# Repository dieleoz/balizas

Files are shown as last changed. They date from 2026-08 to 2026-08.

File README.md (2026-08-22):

# Baliza — Señal Vial «30 CUANDO ACTIVADA» (v3.3)

Control inteligente de la **luz intermitente de una señal de tránsito** instalada frente a zonas escolares.
Cuando la luz titila a **1.0 Hz** (500 ms ON / 500 ms OFF), el límite de **30 km/h está vigente legalmente**. El resto del día la señal permanece apagada.

El horario en el que debe titilar **está grabado físicamente en la placa metálica de la señal**:
* **Mañana:** 06:00 am a 09:00 am
* **Mediodía:** 11:30 am a 01:30 pm (13:30)
* **Tarde:** 03:00 pm (15:00) a 04:30 pm (16:30)

---

## 🏗️ Arquitectura del Sistema

```mermaid
flowchart LR
    APP["📱 App Android<br/>IT VIAL 30 v3.3<br/>Baliza_v3.3.apk"] -->|"Bluetooth SPP 9600 8N1<br/>Tramas ¿...?"| BT["Módulo Bluetooth<br/>JDY-31 / SIG0109A"]
    BT -->|"RC6 TX · RC7 RX"| PIC["PIC18F2550 (C99)<br/>Flash: 53.1% · RAM: 27.7%"]
    RTC["DS1307 + Pila CR2032<br/>Hora, Fecha y Calendario"] <-->|"I2C (Anti-Bloqueo)"| PIC
    PIC -->|"LATC2"| LUZ["💡 Foco Ámbar (1.0 Hz)"]
    PIC -->|"LATC1"| BUZ["Buzzer"]
    PIC -->|"AN1 (ADC)"| BAT["🔋 Batería 12V / Panel"]
    PIC -->|"0x00-0x5F"| EE["💾 EEPROM (Alarmas, Cortes, Nombre OTA)"]
```

## La v3.3 es una pareja, y solo vale junta

**La v3.3 son dos ficheros que se probaron juntos contra una señal real.** Confirmado por el
responsable el 22-ago-2026. No se mezclan con nada de otra procedencia:

| | Fichero | Tamaño | SHA-256 |
|---|---|---|---|
| **Firmware** | [`1 Firmware/Doc mplabx/build_xc8/main.hex`](1%20Firmware/Doc%20mplabx/build_xc8/main.hex) | 59.577 B | `c14b4350d960ce46c716d398f357acdee21f05660ef47c0ea61a7d513b8539c5` |
| **App** | [`1 Firmware/Baliza_v3.3.apk`](1%20Firmware/Baliza_v3.3.apk) | 3.859.625 B | `9c37d599deb995b0fa606d65b5e7fa7e813a08314535f9ba1959b3524d391a87` |

> ### ⚠️ Hay otro `.hex` con nombre de entregable que NO es este
>
> `BALIZA_18F2550_V1_CORREGIDO.hex` —tanto el de `1 Firmware/` como **el que hay dentro de
> `Release_v3.3/Binarios/`**— es un binario **distinto**: 49.068 B, `048856fc…`. No es el que
> funcionó. El nombre engaña justo donde más caro sale, porque está dentro de la carpeta de
> release y cualquiera lo tomaría por el bueno. **Antes de grabar, se comprueba el SHA-256, no
> el nombre del fichero.**

| Parámetro | Valor |
|---|---|
| **Microcontrolador** | **Microchip PIC18F2550** a 20.0 MHz (HS) |
| **Compilador Firmware** | **C99** (`--std=c99`). ⚠️ **La versión exacta de XC8 de este binario no está registrada**: la carpeta `build_xc8/` no conserva el `.map`. Ver ROADMAP, pendiente 5 |
| **Binario que corre HOY en la calle** | Sin confirmar — ver ROADMAP, pendiente 3 |
| **Cobertura de Pruebas** | **78 de 78 · PASS**, medido el **22-ago-2026** con `python "4 Simulador/correr.py"` |
| **Comprobación de interfaz** | **PASS** — contraste WCAG, áreas táctiles, responsive y **controles muertos**, con `comprobar_ui.py`. **No sustituye a verla en un teléfono** |

---

## Las mejoras de hoy: candidatas a la proxima version

Sobre la v3.3 hay **40 commits del 22-ago-2026** con trabajo real: saneamiento de la ISR,
aritmetica de punto fijo en vez de float, timeouts en I2C y UART, telemetria de bateria,
contador de cortes, nombre por el aire (OTA), autodiagnostico en la App y exportacion del
certificado. De ahi salen otros dos binarios:

| | Fichero | Tamano | SHA-256 (12) |
|---|---|---|---|
| Firmware | `1 Firmware/BALIZA_18F2550_V1_CORREGIDO.hex` | 49.201 B | `61e0441df8ce` |
| App | `7 sw apk/Baliza_IT_VIAL_30_v3.4.apk` | 4.570.283 B | `9864125aba51` |

**Son la base de la proxima version, no una version.** Tres cosas tienen que pasar antes de
que puedan llamarse v3.4 y salir a campo:

1. **Funcional tiene que revisar las funciones nuevas.** Ninguna lo ha hecho todavia.
2. ~~Incrementar el `versionCode`.~~ **HECHO el 22-ago-2026.** `build.gradle` esta en
   `versionCode 34` / `versionName "3.4"` y el APK se **recompilo**, asi que ahora se declara
   de verdad como 3.4 y Android si ofrece la actualizacion sobre una v3.3 instalada.
   (El tamano del APK varia entre compilaciones sin que cambie el contenido: es solo
   compresion. Comparar el contenido, no el tamano.)
3. **Hay que probar la pareja junta contra una senal real**, como se hizo con la v3.3. El
   firmware nuevo y la App nueva no se han validado juntos en campo.

Mientras tanto, **lo que se instala en campo es la v3.3**, y las dos cosas no se mezclan: la
App v3.3 con el `.hex` de la v3.3.

## Funcionalidades de la v3.3

Segun `Release_v3.3/LEEME_RELEASE_v3.3.md`, la v3.3 lleva:

**Firmware** (`main.hex`, 59.577 B)

1. **Cadencia reglamentaria de 1.0 Hz** - 500 ms encendido / 500 ms apagado.
2. **Mapeo de pines corregido:** buzzer en `RC1`, foco LED en `RC2`, pulsador en `RC0`.
3. **Parser serie protegido** contra tramas truncadas y caracteres NUL.
4. **Telemetria de bateria 12 V** por el canal ADC `AN1`.
5. **Contador de cortes de energia en EEPROM** (`0x36-0x37`).

**App** (`Baliza_v3.3.apk`, 3.859.625 B)

6. **1-Toque** que graba tres franjas FIJAS (06:00-09:00, 11:30-13:30, 15:00-16:30 L-V) — las de un colegio concreto. Sustituido en la candidata por la tarjeta «Horario de esta placa».
7. **Test de luz de 2 minutos** a 1.0 Hz con apagado rapido.
8. **Tema oscuro de alto contraste** para visibilidad diurna bajo sol.

> **Lo que NO esta en la v3.3:** el nombre por el aire (OTA), el certificado por WhatsApp y el
> semaforo de autodiagnostico. Esas son funciones de la compilacion de trabajo llamada «v3.4»
> y **no han pasado por funcional**. Si algun manual las describe como disponibles, el manual
> va por delante de lo aprobado.

---

## 🧪 Pruebas, Simulación y Emulador Web

Para verificar la compuerta de calidad o correr el simulador interactivo:

```bash
# 1. Arnés de 58 pruebas unitarias, estrés de 100k ciclos y 6 meses continuos:
python "4 Simulador/correr.py"

# 2. Suite automatizada End-to-End paso a paso (Headless):
python "4 Simulador/test_suite_e2e.py"

# 3. Emulador Web Interactivo conectado al Microcontrolador en C:
python "4 Simulador/servidor_interactivo.py"
# Abrir en el navegador: http://localhost:8080
```

---

### Qué NO cubren esas comprobaciones

El arnés compila los `.c` reales del firmware y los ejercita en el PC, pero **no toca un solo
pin**. Verde aquí no es entregable y no autoriza a grabar. En concreto no dice nada de:

* **El ADC.** Desde el 22-ago-2026 **sí lo cubre en parte** (bloque `I` del arnés), y lo
  primero que midió es que **la baliza no mide la temperatura**: el estado que la lee es
  código muerto, nadie transiciona a él. **La telemetría de batería (`AN1`) no está afectada
  y funciona.** Detalle en [`ROADMAP.md`](ROADMAP.md).
* **El I²C y el DS1307.** El reloj simulado siempre responde. Una pila `CR2032` agotada o unas
  pull-ups mal no existen en el simulador.
* **Que el módulo Bluetooth empareje.** Al arnés se le meten las tramas directamente.
* **Que el horario grabado coincida con la chapa atornillada a esa señal.** Esto es lo que más
  importa y **solo lo puede comprobar una persona con la señal delante**.

---

## 📚 Documentación Oficial y Manuales

* 📱 **Instalador de campo (v3.3, el aprobado):** [`1 Firmware/Baliza_v3.3.apk`](1%20Firmware/Baliza_v3.3.apk)
* 🔧 **Compilacion de trabajo (NO aprobada):** [`7 sw apk/Baliza_IT_VIAL_30_v3.4.apk`](7%20sw%20apk/Baliza_IT_VIAL_30_v3.4.apk)
* 🔧 **Compilar la app (cadena, dependencias, trampas):** [`Manuales/COMPILAR_APP.md`](Manuales/COMPILAR_APP.md)
* 📖 **Manual de Usuario de la App:** [`Manuales/MANUAL_USUARIO_APP.md`](Manuales/MANUAL_USUARIO_APP.md)
* ⚙️ **Manual Técnico del Firmware C99:** [`Manuales/MANUAL_TECNICO_FIRMWARE_C99.md`](Manuales/MANUAL_TECNICO_FIRMWARE_C99.md)
* 📜 **Certificado Oficial de Calibración y Pruebas:** [`Manuales/CERTIFICADO_FIRMWARE_v3.4.md`](Manuales/CERTIFICADO_FIRMWARE_v3.4.md)
* 🗺️ **Gestión de Múltiples Señales y Nombres OTA:** [`Manuales/GESTION_MULTISEÑALES_Y_NOMBRES.md`](Manuales/GESTION_MULTISE%C3%91ALES_Y_NOMBRES.md)
* 📋 **Especificación de Calidad y No-Regresión:** [`Manuales/ESPECIFICACION_REFACTORIZACION_APP_v3.4.md`](Manuales/ESPECIFICACION_REFACTORIZACION_APP_v3.4.md)
* 🩺 **Guía de Diagnóstico y Logs de Soporte:** [`Manuales/GUIA_DIAGNOSTICO_Y_LOGS_SOPORTE.md`](Manuales/GUIA_DIAGNOSTICO_Y_LOGS_SOPORTE.md)
* 🏛️ **Dictamen del Comité Técnico:** [`Manuales/DICTAMEN_COMITE_TECNICO_MULTIDISCIPLINARIO.md`](Manuales/DICTAMEN_COMITE_TECNICO_MULTIDISCIPLINARIO.md)
* ⚖️ **Base normativa (Manual de Señalización Vial):** [`Manuales/NORMATIVA.md`](Manuales/NORMATIVA.md)
* 🗺️ **Hoja de Ruta (Roadmap):** [`ROADMAP.md`](ROADMAP.md)

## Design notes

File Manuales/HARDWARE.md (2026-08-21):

# Baliza SR30 — Documentación de hardware

**Tarjeta:** `BALIZA_SR30` · **Título del esquemático:** "Tarjeta Control Baliza" · **Rev:** V1.0 · **Empresa:** IT VIAL SAS · **Autor:** Ing. Freiman Parga
**Ficheros fuente analizados:**

| Fichero | Ruta |
|---|---|
| Esquemático | `D:\@Proyect\Baliza\2 Hardware tarjeta\balizaSR30.kicad_sch` (KiCad 8.0, `version 20231120`) |
| PCB | `D:\@Proyect\Baliza\2 Hardware tarjeta\balizaSR30.kicad_pcb` (KiCad 8.0.1) |
| BOM | `D:\@Proyect\Baliza\2 Hardware tarjeta\Lista de componentes Baliza.xls` (hoja `Baliza_SR30`) |
| Gerbers | `D:\@Proyect\Baliza\2 Hardware tarjeta\gerbers_baliza\` (generados 2025-06-24) |
| Firmware | `D:\@Proyect\Baliza\1 Firmware\Doc mplabx\18f2550_baliza_ V1.X\` |

> **Método:** toda la información eléctrica de este documento se ha extraído parseando las S-expressions de `.kicad_sch` y `.kicad_pcb` y reconstruyendo la netlist por geometría (posición de pines contra extremos de hilo, uniones y etiquetas). La reconstrucción resolvió **el 100 % de los pines** de los 41 componentes sobre puntos de conexión válidos, por lo que la netlist que aparece aquí es la del fichero, no una lectura del PDF.

---

## 0. ⚠️ HALLAZGOS CRÍTICOS — leer antes de fabricar o modificar

Cinco defectos hacen que la tarjeta **no funcione como espera el firmware actual**. Tres de ellos son de hardware y no se arreglan recompilando.

| # | Hallazgo | Referencia | Consecuencia |
|---|---|---|---|
| **C1** | **El buzzer está en RC1, el firmware lo ataca en RC0.** El neto `BUZZER` va a `U1` pin 12 (`RC1`); el firmware define `ON_BUZZER = LATCbits.LATC0` (`Buzzer.h:24`). En `Buzzer.c:162` está **comentada** la línea correcta `//TRISCbits.TRISC1 = 0;` y activa la incorrecta `TRISCbits.TRISC0 = 0;` (`Buzzer.c:163`). | `balizaSR30.kicad_sch:11443` (BZ1), `:10283` (U1) | **El buzzer nunca suena.** Además RC0 es el neto `BUTTON`: el firmware convierte en salida un pin que en la placa tiene pull-up (R4 10 K) y un pulsador (SW1) a través de D2. **Si se pulsa SW1 con LATC0=1, la salida del PIC queda cortocircuitada a GND a través de D2** (sólo limitada por la impedancia de salida del puerto). Riesgo de destrucción del pin. |
| **C2** | **El buzzer no puede sonar aunque se arregle C1: R15 = 100 kΩ está en serie con él.** Camino: `+12V → R15 (100k) → BZ1.1 → BZ1.2 → Q4(C) → Q4(E) → GND`. Corriente máxima = 12 V / 100 kΩ = **120 µA**. | `balizaSR30.kicad_sch:9096` (R15), `:11443` (BZ1) | Un buzzer magnético necesita 20–30 mA; uno piezo con oscilador interno, 3–10 mA. Con 120 µA **no emite sonido audible**. Además la polaridad está invertida: el pin marcado `+` de BZ1 es el que va al colector (lado bajo) y el `-` al lado de alimentación. |
| **C3** | **AN3 (sensor de temperatura) está deshabilitado por configuración del ADC.** El LM35 (`U5`) entra en `U1` pin 5 = `RA3/AN3` por el neto `S_TEMP`. El firmware ejecuta `ADCON1bits.PCFG = 0b1011` (`main.c:175`), que en el PIC18F2550 deja **sólo AN0, AN1 y AN2 como analógicas**; AN3 queda como E/S digital. Aun así `Aplicacion.c:227` llama a `ADC_read(3)`. | `balizaSR30.kicad_sch:10139` (U5), `main.c:175` | La lectura de temperatura **no está especificada por Microchip** (canal seleccionado sobre un pin no configurado como analógico) y el buffer digital de entrada queda activo con una tensión analógica encima. La temperatura que reporte el equipo no es fiable. |
| **C4** | **La fórmula de temperatura es incorrecta para un LM35 por un factor 10.** `Aplicacion.c:228-229` calcula `T = (ADC·5/1024)·10`. El LM35 entrega **10 mV/°C**, luego `T[°C] = V·100`. | `main.c` / `Aplicacion.c:227-229` | La temperatura mostrada es **la décima parte** de la real (25 °C se leería como 2,5). |
| **C5** | **La puerta del MOSFET de potencia recibe sólo 3,4 V.** `R8` (2,2 k) en serie desde RC2 y `R9` (4,7 k) de puerta a masa forman un divisor: `Vgs = 5 V · 4,7/(2,2+4,7) = 3,41 V`. `Q2` está en el BOM como **`Q_NMOS_GDS`**, un símbolo genérico **sin referencia de fabricante**. | `balizaSR30.kicad_sch:7847` (Q2), `:10703` (R8), `:12060` (R9) | Con un MOSFET estándar (p. ej. IRF540N, Vgs(th) hasta 4 V) **no conduce**, o conduce en zona lineal y se destruye. Sólo funciona con un MOSFET *logic-level* y aun así 3,4 V está por debajo de la Vgs a la que se especifica el Rds(on). |

Además, dos hallazgos que sí funcionan correctamente y conviene **no tocar**:

- ✅ El **divisor de medida de tensión es correcto**: R13 = 100 k / R14 = 20 k → factor 6, exactamente el que aplica el firmware (§6).
- ✅ El **LED de vida es activo a nivel bajo** y el firmware lo trata así (`ON_LED_LIVE → LATA0 = 0`). Coincide (§5).

---

## 1. Qué es la tarjeta

`BALIZA_SR30` es una tarjeta de control de baliza/alarma temporizada de **77,0 × 90,0 mm**, dos capas, tecnología mixta (todos los componentes de agujero pasante en la cara superior y todos los SMD en la cara inferior). Se alimenta de un **único raíl de 12 V nominales** por un conector Molex KK-396 de 2 vías (`J2`, serigrafiado **FUENTE / 12V / GND**), del que deriva un raíl de 5 V mediante un regulador lineal `LM78M05` (`U3`) precedido de un diodo Schottky en serie `1N5822` (`D3`) que hace de protección de polaridad inversa. El cerebro es un **PIC18F2550 en DIP-28** (`U1`) a 20 MHz que: mantiene la hora en un **RTC DS1307** (`U4`) por I²C con cristal de 32,768 kHz y pila de respaldo de 20 mm; conversa a 9600 baudios con un **módulo Bluetooth HC-06** (`U2`) montado en cabecera de 6 pines; parpadea un **LED de vida** (`D1`); acciona un **buzzer** (`BZ1`) por transistor `MMBT3904` (`Q4`); y conmuta la salida de potencia **CLUSTER** por un MOSFET de canal N en TO-220 (`Q2`) en configuración de lado bajo, sacada al exterior por un segundo Molex KK-396 (`J3`, serigrafiado **CLUSTER**). Mide además la tensión de entrada por divisor resistivo hacia AN1 y la temperatura por un **LM35** (`U5`) hacia AN3. Al exterior expone tres conectores: `J2` (alimentación 12 V), `J3` (salida cluster) y `J1` (cabecera ICSP de 5 pines, compatible pin a pin con PICkit 3/4). Hay un pulsador local `SW1`.

---

## 2. Lista de componentes (BOM) reconstruida del esquemático

41 componentes reales (más 36 símbolos de alimentación `#PWR*`, que no son componentes físicos).

### 2.1 Alimentación y protección

| Ref | Valor | Footprint | Función | Línea |
|---|---|---|---|---|
| J2 | `FUENTE` (Conn_01x02_Male) | `Connector_Molex:Molex_KK-396_5273-02A_1x02_P3.96mm_Vertical` | Entrada de alimentación. Pin 1 = `+12V`, Pin 2 = `GND` | `:10907` |
| D3 | `1N5822` | `Diode_THT:D_DO-201AD_P15.24mm_Horizontal` | Schottky 3 A/40 V en serie: **protección de polaridad inversa** del raíl `VCC` | `:12262` |
| C3 | `470uF` | `Capacitor_THT:CP_Radial_D8.0mm_P2.50mm` | Condensador de entrada del regulador (neto `VCC`) | `:11512` |
| U3 | `LM78M05_TO220` | `Package_TO_SOT_THT:TO-220-3_Horizontal_TabDown` | Regulador lineal 5 V / 500 mA. VI=`VCC`, VO=`+5V` | `:8359` |
| C4 | `220uF` | `Capacitor_THT:CP_Radial_D8.0mm_P2.50mm` | Condensador de salida del regulador (neto `+5V`) | `:11373` |
| C6 | `0.1uF` | `Capacitor_SMD:C_0805_2012Metric` | Desacoplo de `+5V` — el **único** cerámico de alimentación de la placa | `:10773` |

### 2.2 Microcontrolador y reloj

| Ref | Valor | Footprint | Función | Línea |
|---|---|---|---|---|
| U1 | `PIC18F2550-ISP` | `Package_DIP:DIP-28_W7.62mm` | MCU principal | `:10283` |
| Y1 | `20M` | `Crystal:Crystal_HC18-U_Vertical` | Cristal principal 20 MHz (coincide con `_XTAL_FREQ 20000000` y `FOSC = HS`) | `:11582` |
| C1, C2 | `22pF` | `Capacitor_SMD:C_0805_2012Metric` | Condensadores de carga de Y1 (`OSC2`, `OSC1`) | `:11043`, `:9935` |
| R2 | `10k` | `Resistor_SMD:R_1206_3216Metric` | Pull-up de `MCLR` a `+5V` | `:7451` |
| J1 | `Conn_01x05_Male` | `Connector_PinHeader_2.54mm:PinHeader_1x05_P2.54mm_Vertical` | ICSP: 1=`MCLR/VPP`, 2=`+5V`, 3=`GND`, 4=`PGD`, 5=`PGC` | `:11717` |

### 2.3 RTC

| Ref | Valor | Footprint | Función | Línea |
|---|---|---|---|---|
| U4 | `DS1307_` | `digikey-footprints:DIP-8_W7.62mm` | Reloj de tiempo real I²C | `:8054` |
| Y2 | **`37Khz`** ⚠ | `Crystal:Crystal_AT310_D3.0mm_L10.0mm_Horizontal` | Cristal del RTC. **El valor es erróneo: el DS1307 exige 32,768 kHz, CL = 12,5 pF** | `:8565` |
| BT1 | `Battery_Cell` | `Battery:BatteryHolder_Keystone_103_1x20mm` | Portapilas de 20 mm (CR2032). `+` → `VBAT` de U4 | `:9235` |
| R5, R6 | `4.7k` | `Resistor_SMD:R_1206_3216Metric` | **Pull-ups de `SDA` y `SCL` a `+5V`** — presentes y de valor correcto | `:9026`, `:9660` |

> Y2 **no lleva condensadores de carga y eso es correcto**: el DS1307 los integra y su hoja de datos prohíbe expresamente añadirlos.

### 2.4 Comunicación serie / Bluetooth

| Ref | Valor | Footprint | Función | Línea |
|---|---|---|---|---|
| U2 | `HC06_Module` | `HC06:HC06` (librería propia) | Módulo Bluetooth SPP. 1=`STATE` (NC), 2=`RXD`←`MCU_TX`, 3=`TXD`→`MCU_RX`, 4=`GND`, 5=`VCC`←`+5V`, 6=`EN` (NC) | `:9578` |

### 2.5 Indicación y entrada de usuario

| Ref | Valor | Footprint | Función | Línea |
|---|---|---|---|---|
| D1 | `LED` (sin part number) | `LED_THT:LED_D3.0mm` | LED de vida. **Cátodo a RA0**, ánodo a R1 → activo a nivel bajo | `:8223` |
| R1 | `330R` | `Resistor_SMD:R_1206_3216Metric` | Limitadora de D1 (≈9,4 mA con Vf 1,9 V) | `:10634` |
| SW1 | `SW_Push` | `Button_Switch_THT:SW_PUSH_6mm_H4.3mm` | Pulsador local a `GND` | `:12396` |
| R3 | `10K` | `Resistor_SMD:R_1206_3216Metric` | Pull-up del nodo del pulsador | `:10069` |
| D2 | `1N4007` | `Diode_THT:D_DO-41_SOD81_P7.62mm_Horizontal` | Diodo de desacoplo entre el nodo del pulsador y el neto `BUTTON` (K en SW1, A en `BUTTON`) | `:10566` |
| R4 | `10K` | `Resistor_SMD:R_1206_3216Metric` | Pull-up del neto `BUTTON` (RC0) | `:10213` |

### 2.6 Etapa del buzzer

| Ref | Valor | Footprint | Función | Línea |
|---|---|---|---|---|
| BZ1 | `Buzzer` (sin part number) | `Buzzer_Beeper:Buzzer_12x9.5RM7.6` | Buzzer de 12 mm | `:11443` |
| Q4 | `MMBT3904` | `Package_TO_SOT_SMD:SOT-23` | NPN, conmutador de lado bajo del buzzer. Ic máx 200 mA | `:9371` |
| R11 | `2.2k` | `Resistor_SMD:R_1206_3216Metric` | Resistencia de base de Q4 (Ib ≈ 1,8 mA) | `:8430` |
| R12 | `4.7k` | `Resistor_SMD:R_1206_3216Metric` | Base a masa (apagado seguro) | `:9865` |
| R15 | **`100k`** ⚠ | `Resistor_SMD:R_1206_3216Metric` | **En serie entre `+12V` y el buzzer — ver hallazgo C2** | `:9096` |
| D4 | `D` (sin part number) | `Diode_THT:D_A-405_P7.62mm_Horizontal` | Diodo de rueda libre en paralelo con BZ1. Orientación correcta (K al lado de alimentación) | `:7985` |

### 2.7 Etapa de salida CLUSTER

| Ref | Valor | Footprint | Función | Línea |
|---|---|---|---|---|
| Q2 | **`Q_NMOS_GDS`** ⚠ | `Package_TO_SOT_THT:TO-220-3_Horizontal_TabDown` | MOSFET N de potencia, conmutación de lado bajo. **Sin referencia de fabricante** | `:7847` |
| R8 | `2.2k` | `Resistor_SMD:R_1206_3216Metric` | Serie de puerta desde RC2 | `:10703` |
| R9 | `4.7k` | `Resistor_SMD:R_1206_3216Metric` | Puerta a masa | `:12060` |
| R16 | `0R` | `Resistor_SMD:R_2010_5025Metric` | Puente de 0 Ω entre el drenador de Q2 y `J3` pin 2 | `:9302` |
| J3 | `FUENTE` (etiqueta) / serigrafía **CLUSTER** | `Connector_Molex:Molex_KK-396_5273-02A_1x02_P3.96mm_Vertical` | Salida de potencia. Pin 1 = `+12V` (crudo), Pin 2 = drenador de Q2 | `:10975` |

### 2.8 Medida analógica

| Ref | Valor | Footprint | Función | Línea |
|---|---|---|---|---|
| R13 | `100k` | `Resistor_SMD:R_1206_3216Metric` | Rama superior del divisor de tensión (`VCC` → `S_VOLT`) | `:9166` |
| R14 | `20k` | `Resistor_SMD:R_1206_3216Metric` | Rama inferior (`S_VOLT` → `GND`) | `:11859` |
| C5 | `0.1uF` | `Capacitor_SMD:C_0805_2012Metric` | Filtro del nodo `S_VOLT` | `:9795` |
| D5 | `5.1V` (Zener) | `Diode_THT:D_DO-34_SOD68_P7.62mm_Horizontal` | Recorte de `S_VOLT` a 5,1 V (protección de AN1) | `:10497` |
| U5 | `LM35-LP` | `Package_TO_SOT_THT:TO-92L_Inline_Wide` | Sensor de temperatura analógico, 10 mV/°C | `:10139` |
| C7 | `0.1uF` | `Capacitor_SMD:C_0805_2012Metric` | Filtro de `S_TEMP` — **directamente en la salida del LM35, ver §10** | `:12597` |

### 2.9 Contraste con `Lista de componentes Baliza.xls`

Se leyó la hoja `Baliza_SR30` (32 filas, columnas `Reference / Value / Footprint / Qty`) con `xlrd`.

**Resultado del cotejo: valores y footprints coinciden 1:1 con el esquemático en las 31 líneas, y la suma de cantidades (41) coincide con el número de componentes del esquemático (41).** Es una exportación automática de KiCad, no una lista revisada a mano. Discrepancias y carencias detectadas:

| # | Discrepancia / carencia | Detalle |
|---|---|---|
| 1 | **`J2,J3` tienen la celda `Value` vacía** en el .xls | En el esquemático ambos llevan `Value = "FUENTE"`, y además la serigrafía de la PCB llama `CLUSTER` a J3. Tres nombres distintos para el mismo conector. |
| 2 | **`Q2` figura como `Q_NMOS_GDS`** | No es una referencia comprable. Es el nombre del símbolo genérico de KiCad. **Nadie puede comprar este componente con esta lista.** Y la elección importa (hallazgo C5: sólo sirve un *logic-level*). |
| 3 | **`D4` figura como `D`** | Diodo sin referencia. Footprint A-405 (DO-35/DO-204AH). |
| 4 | **`D1` figura como `LED`** | Sin color, sin Vf, sin corriente nominal. R1 = 330 Ω asume Vf ≈ 1,9 V (rojo/ámbar); con un LED azul/blanco (Vf 3,0–3,4 V) la corriente baja a ~5 mA. |
| 5 | **`BZ1` figura como `Buzzer`** | No indica si es magnético o piezo, ni si lleva oscilador interno, ni tensión de trabajo. Es exactamente la información que hace falta para dimensionar R15 (hallazgo C2). |
| 6 | **`Y2` figura como `37Khz`** | **Valor erróneo.** El DS1307 sólo funciona con 32,768 kHz. Un cristal de "37 kHz" no existe como producto estándar. Quien compre por esta lista no compra nada, o compra mal. |
| 7 | **`C3` (470 µF) y `C4` (220 µF) sin tensión de trabajo** | C3 está en `VCC` (12 V). Necesita ≥ 25 V. La lista no lo dice. |
| 8 | **`U2 = HC06_Module` con footprint de librería propia `HC06:HC06`** | No identifica la variante del módulo (HC-06 desnudo vs. placa portadora tipo ZS-040/JY-MCU). Es determinante: ver §10, riesgo R7. |
| 9 | **`SW1`, `BT1`, `U3`, `D3` sin fabricante ni referencia** | Comprables por descripción, pero no trazables. |
| 10 | **Huecos en la numeración de referencias** | No existen `R7`, `R10`, `Q1`, `Q3`. Indica componentes eliminados en revisiones anteriores sin renumerar. No es un error, pero rompe la trazabilidad contra revisiones antiguas. |

**Conclusión:** el .xls no contradice al esquemático, pero **no es un BOM de compra**. Seis líneas (Q2, D4, D1, BZ1, Y2, U2) no se pueden pedir tal como están, y una de ellas (Y2) está directamente mal.

---

## 3. Diagrama de bloques

```mermaid
flowchart TB
    subgraph EXT["Exterior"]
        PSU["Fuente 12 V"]
        CARGA["Carga CLUSTER<br/>(lámpara / baliza)"]
        BT(["Teléfono / App<br/>Bluetooth SPP"])
    end

    subgraph ALIM["Alimentación"]
        J2["J2 · Molex KK-396<br/>FUENTE 12V/GND"]
        D3["D3 · 1N5822<br/>Schottky serie<br/>(prot. polaridad inversa)"]
        C3["C3 · 470 µF"]
        U3["U3 · LM78M05<br/>TO-220 · 500 mA"]
        C4["C4 · 220 µF"]
        C6["C6 · 0,1 µF"]
        V12(["Raíl +12V<br/>(sin fusible, sin TVS)"])
        V5(["Raíl +5V"])
    end

    subgraph MCU["Control"]
        U1["U1 · PIC18F2550<br/>DIP-28 · 20 MHz · HS"]
        Y1["Y1 · 20 MHz<br/>+ C1/C2 22 pF"]
        J1["J1 · ICSP 5 pines<br/>MCLR·+5V·GND·PGD·PGC"]
        R2["R2 · 10k<br/>pull-up MCLR"]
    end

    subgraph RTC["Reloj de tiempo real"]
        U4["U4 · DS1307<br/>DIP-8"]
        Y2["Y2 · 32,768 kHz<br/>(rotulado '37Khz')"]
        BT1["BT1 · CR2032 20 mm<br/>→ VBAT (sin diodo)"]
        PU["R5/R6 · 4,7k<br/>pull-ups I2C a +5V"]
    end

    subgraph IO["Periféricos"]
        U2["U2 · HC-06<br/>UART 9600 8N1"]
        D1["D1 · LED vida<br/>+ R1 330R · activo BAJO"]
        SW1["SW1 · pulsador<br/>+ R3/R4 10k + D2"]
    end

    subgraph BUZ["Buzzer"]
        R11["R11 2,2k"]
        Q4["Q4 · MMBT3904<br/>lado bajo"]
        BZ1["BZ1 · buzzer 12 mm"]
        R15["R15 · 100k ⚠<br/>EN SERIE"]
        D4["D4 · rueda libre"]
    end

    subgraph CL["Salida CLUSTER (potencia)"]
        R8["R8 2,2k / R9 4,7k<br/>Vgs = 3,4 V ⚠"]
        Q2["Q2 · MOSFET N TO-220<br/>SIN REFERENCIA ⚠<br/>lado bajo"]
        R16["R16 · 0R 2010"]
        J3["J3 · Molex KK-396<br/>CLUSTER"]
    end

    subgraph ANA["Entradas analógicas"]
        DIV["R13 100k / R14 20k<br/>divisor ÷6<br/>+ C5 0,1µF + D5 5V1"]
        U5["U5 · LM35 TO-92<br/>10 mV/°C + C7 0,1µF"]
    end

    PSU --> J2 --> D3 --> C3 --> U3 --> C4 --> V5
    J2 --> V12
    C6 --- V5
    V5 --> U1
    V5 --> U4
    V5 --> U2
    V5 --> U5
    V5 --> PU

    Y1 <-->|OSC1/OSC2 · pines 9,10| U1
    J1 <--> U1
    R2 --- U1

    U1 <-->|"SDA · RB0 (pin 21)"| U4
    U1 <-->|"SCL · RB1 (pin 22)"| U4
    PU --- U4
    Y2 <-->|X1/X2| U4
    BT1 -->|VBAT| U4

    U1 -->|"MCU_TX · RC6 (pin 17)"| U2
    U2 -->|"MCU_RX · RC7 (pin 18)"| U1
    U2 <-.->|"Bluetooth SPP"| BT

    U1 -->|"LED_LIVE · RA0 (pin 2)"| D1
    SW1 -->|"BUTTON · RC0 (pin 11)"| U1

    U1 -->|"BUZZER · RC1 (pin 12)"| R11 --> Q4 --> BZ1
    V12 --> R15 --> BZ1
    D4 --- BZ1

    U1 -->|"CLUSTER · RC2 (pin 13)"| R8 --> Q2 --> R16 --> J3
    V12 --> J3
    J3 --> CARGA

    DIV -->|"S_VOLT · AN1/RA1 (pin 3)"| U1
    C3 --- DIV
    U5 -->|"S_TEMP · AN3/RA3 (pin 5) ⚠"| U1

    style R15 fill:#c0392b,color:#fff
    style Q2 fill:#c0392b,color:#fff
    style R8 fill:#c0392b,color:#fff
    style U5 fill:#c0392b,color:#fff
```

---

## 4. Alimentación

### 4.1 Cadena completa

```
J2.1 (+12V, Molex KK-396)
  └─► D3 · 1N5822 (Schottky 3A/40V, ánodo en +12V, cátodo en VCC)   ← protección de polaridad inversa
        └─► neto VCC
              ├─► C3 · 470 µF electrolítico (VCC → GND)
              ├─► R13 · 100k  → divisor de medida (§6)
              └─► U3.1 (VI) · LM78M05, TO-220
                    └─► U3.3 (VO) ─► neto +5V
                          ├─► C4 · 220 µF electrolítico
                          ├─► C6 · 0,1 µF cerámico 0805
                          ├─► U1.20 (VDD)  · PIC18F2550
                          ├─► U1.6  (RA4)  ⚠ pin de E/S atado a +5V (§10 R5)
                          ├─► U2.5  (VCC)  · HC-06
                          ├─► U4.8  (VCC)  · DS1307
                          ├─► U5.1  (+VS)  · LM35
                          ├─► J1.2         · ICSP
                          └─► R1, R2, R3, R4, R5, R6 (pull-ups / limitadora LED)

J2.1 (+12V) también va DIRECTAMENTE, sin pasar por D3, a:
  ├─► J3.1  · pin 1 del conector CLUSTER (alimentación de la carga externa)
  └─► R15   · rama del buzzer
```

### 4.2 Raíles

| Raíl | Tensión | Origen | Consumidores |
|---|---|---|---|
| `+12V` | 12 V nominales (sin regular, sin filtrar, sin proteger) | `J2.1` directo | `J3.1` (carga externa), `R15` (buzzer), ánodo de `D3` |
| `VCC` | ≈ `+12V` − Vf(D3) ≈ 11,6–11,7 V | tras `D3` | `C3`, `U3.1`, `R13` |
| `+5V` | 5 V ±4 % (tolerancia del 78M05) | `U3.3` | PIC, DS1307, HC-06, LM35, pull-ups, ICSP |
| `+3V3` (nombre engañoso) | **3,0 V reales** — es la pila CR2032, no un raíl | `BT1.1` | únicamente `U4.3` (VBAT del DS1307) |

> El símbolo de potencia `+3.3V` aplicado a una pila de litio de 3,0 V es un error de documentación: sugiere un raíl de 3,3 V regulado que no existe en la placa. Cualquiera que lea el esquemático buscará un LDO de 3V3 y no lo encontrará.

### 4.3 Condensadores de desacoplo — inventario completo

| Cap | Valor | Neto | Ubicación PCB | Comentario |
|---|---|---|---|---|
| C3 | 470 µF | `VCC` (entrada regulador) | `(128,15 · 67,90)` cara sup. | OK como bulk |
| C4 | 220 µF | `+5V` (salida regulador) | `(138,45 · 67,90)` cara sup. | OK como bulk |
| C6 | 0,1 µF | `+5V` | `(134,45 · 106,45)` cara inf. | **A 2,77 mm de U1.20 (VDD) y 2,84 mm de U1.19 (VSS)** — correcto para ese par |
| C5 | 0,1 µF | `S_VOLT` | — | filtro de señal, no desacoplo |
| C7 | 0,1 µF | `S_TEMP` | — | filtro de señal, no desacoplo |
| C1, C2 | 22 pF | `OSC1`/`OSC2` | — | carga del cristal, no desacoplo |

**Sólo hay un condensador de desacoplo en toda la placa (C6).** Ver §10 para las consecuencias.

### 4.4 Protecciones — presentes y AUSENTES

| Protección | ¿Está? | Detalle |
|---|---|---|
| **Polaridad inversa** | ✅ **PARCIAL** | `D3` (1N5822) en serie protege `VCC`, el 7805 y todo lo que cuelga de `+5V`. **PERO `J3.1` y `R15` cuelgan de `+12V` crudo, antes de D3.** Con la fuente invertida, la carga del cluster y la rama del buzzer quedan expuestas a −12 V; además `J3.1` pasa a −12 V y el diodo de cuerpo de `Q2` conduce desde GND hacia el drenador, poniendo el retorno de la carga a través del MOSFET. |
| **Fusible** | ❌ **NO HAY** | No existe ningún fusible, PTC ni polyfuse en el esquemático. Un cortocircuito en la carga del cluster no tiene ningún elemento que lo limite salvo la fuente externa. |
| **TVS / supresor de transitorios** | ❌ **NO HAY** | Ningún TVS, MOV ni varistor en `+12V`. En una baliza alimentada de una batería de vehículo o de una línea larga, los transitorios llegan íntegros al 1N5822 (40 V de VRRM) y al MOSFET. |
| **Zener de recorte en `S_VOLT`** | ✅ SÍ | `D5` (5,1 V) protege AN1 |
| **Rueda libre en el buzzer** | ✅ SÍ | `D4` en paralelo con `BZ1`, cátodo hacia el lado de alimentación (orientación correcta) |
| **Rueda libre en la salida CLUSTER** | ❌ **NO HAY** | Ver §8 |
| **Filtrado / protección ESD en las líneas que salen (J2, J3)** | ❌ **NO HAY** | Sin ferritas, sin condensadores de paso, sin diodos de sujeción |
| **Brown-out reset** | ❌ **DESACTIVADO POR FIRMWARE** | `#pragma config BOR = OFF` (`main.h:23`). No hay supervisor externo. El PIC puede quedar en estado indefinido si el raíl de 5 V cae lentamente. |
| **Watchdog** | ❌ **DESACTIVADO** | `#pragma config WDT = OFF` (`main.h:28`) |

### 4.5 Estimación de consumo

| Consumidor | Corriente típica @5 V | Corriente pico |
|---|---|---|
| U1 · PIC18F2550, 20 MHz HS, ADC + MSSP + EUSART activos | ≈ 11 mA | ≈ 15 mA |
| U2 · HC-06 (emparejado / en reposo) | ≈ 8 mA | ≈ 40 mA (inquiry/emparejamiento) |
| U4 · DS1307 (VCC activo) | ≈ 1,2 mA | 1,5 mA |
| U5 · LM35 | 60 µA | 90 µA |
| D1 · LED vida (R1 = 330 Ω, ciclo 5/200 = 2,5 %) | ≈ 0,25 mA medios | 9,4 mA |
| Pull-ups I²C R5/R6 (4,7 k) durante niveles bajos | ≈ 0–2 mA | 2 mA |
| Base de Q4 (R11) cuando suena el buzzer | 0 | 1,8 mA |
| Puerta de Q2 (R8+R9) con CLUSTER activo | 0 | 0,72 mA |
| **Total raíl +5V** | **≈ 21 mA** | **≈ 70 mA** |

| Consumidor en `+12V`/`VCC` | Corriente |
|---|---|
| Divisor R13+R14 (120 kΩ sobre VCC) | 97 µA |
| R15 (rama del buzzer, 100 kΩ sobre 12 V) | 120 µA |
| Entrada del 7805 (≈ salida + Iq 4 mA) | 25–75 mA |
| Carga del cluster por J3 | **indeterminada** — no está definida en el proyecto |

**Disipación de U3 (LM78M05, TO-220 sin disipador, θJA ≈ 62 °C/W):**

- Con 12 V de entrada y 70 mA: `P = (12 − 5) × 0,070 = 0,49 W` → ΔT ≈ **+30 °C**. Aceptable.
- Con 24 V de entrada (si la baliza se alimentara de 24 V) y 70 mA: `P = 1,33 W` → ΔT ≈ **+82 °C**. **No admisible sin disipador.**
- Margen de caída: el LM78M05 necesita `Vin ≥ 7 V`. Restando D3, la tarjeta deja de regular por debajo de **≈ 7,3 V** en J2. Durante un arranque de motor (caída a 6 V) el raíl de 5 V se colapsa y el PIC se resetea de forma no controlada (BOR está desactivado).

---

## 5. Correlación pin a pin con el firmware ⭐

Firmware: `D:\@Proyect\Baliza\1 Firmware\Doc mplabx\18f2550_baliza_ V1.X\`

| Pin PIC | Nombre en el esquemático | Neto | Qué hay conectado | Qué hace el firmware | ¿Coincide? |
|---|---|---|---|---|---|
| **1** | `Vpp/MCLR/RE3` | `MCLR` | `R2` 10 k a `+5V` + `J1.1` (ICSP) | `#pragma config MCLRE = ON` (`main.h:35`) → MCLR habilitado | ✅ **SÍ** |
| **2** | `RA0/AN0` | `LED_LIVE` | Cátodo de `D1`; ánodo → `R1` 330 Ω → `+5V` → **LED activo a nivel BAJO** | `TRISA0 = 0` (`LedLive.c:101`); `ON_LED_LIVE = LATA0 = 0`, `OFF = 1` (`LedLive.h:26-27`) | ✅ **SÍ** — la polaridad invertida del firmware es la correcta para este cableado |
| **3** | `RA1/AN1` | `S_VOLT` | Divisor `R13` 100 k / `R14` 20 k desde `VCC`, con `C5` 0,1 µF y zener `D5` 5V1 | `ADC_read(1)` (`Aplicacion.c:211`). `PCFG=0b1011` habilita AN0–AN2 → **AN1 sí es analógica** | ✅ **SÍ** |
| **4** | `RA2/AN2/Vref−` | — | **Sin conectar** (marcador `no_connect` en el esquemático) | `PCFG=0b1011` lo declara **analógico** pero nunca se lee | ⚠ Entrada analógica habilitada y flotante (§10 R11) |
| **5** | `RA3/AN3/Vref+` | `S_TEMP` | Salida de `U5` (LM35) + `C7` 0,1 µF | `ADC_read(3)` (`Aplicacion.c:227`) — pero `PCFG=0b1011` deja **AN3 como E/S DIGITAL** (`main.c:175`) | ❌ **NO — hallazgo C3.** El firmware lee un canal que él mismo dejó configurado como digital |
| **6** | `RA4/T0CKI/C1OUT` | `+5V` | **Atado directamente al raíl de 5 V, sin resistencia** | Nunca se configura ni se escribe (queda entrada tras reset) | ⚠ Funciona hoy, pero es una E/S digital cortocircuitada a VDD (§10 R5) |
| **7** | `RA5/AN4/SS/HLVDIN` | `GND` | **Atado directamente a masa, sin resistencia** | Nunca se configura ni se escribe | ⚠ Ídem, cortocircuitada a VSS (§10 R5) |
| **8** | `VSS` | `GND` | Plano/pistas de masa | — | ✅ SÍ (pero sin cerámico propio, §10 R2) |
| **9** | `OSC1/CLKI` | `OSC1` | `Y1` 20 MHz + `C2` 22 pF | `#pragma config FOSC = HS`, `_XTAL_FREQ 20000000` (`main.h:17,76`) | ✅ **SÍ** |
| **10** | `RA6/OSC2/CLKO` | `OSC2` | `Y1` 20 MHz + `C1` 22 pF | Ídem | ✅ **SÍ** |
| **11** | `RC0/T1OSO/T13CKI` | **`BUTTON`** | `R4` 10 k a `+5V` + `D2` (ánodo) hacia el nodo de `SW1` | **`TRISCbits.TRISC0 = 0` → lo pone como SALIDA** y lo usa como buzzer: `ON_BUZZER = LATC0 = 1` (`Buzzer.c:163`, `Buzzer.h:24`) | ❌ **NO — hallazgo C1.** El firmware convierte en salida el pin del pulsador. Con SW1 pulsado y LATC0=1, la salida queda a masa vía D2 |
| **12** | `RC1/T1OSI/CCP2` | **`BUZZER`** | `R11` 2,2 k → base de `Q4` (MMBT3904) → `BZ1` | **`//TRISCbits.TRISC1 = 0;` está COMENTADA** (`Buzzer.c:162`). El pin queda como entrada y nunca se acciona | ❌ **NO — hallazgo C1.** El buzzer real no se ataca nunca |
| **13** | `RC2/CCP1` | `CLUSTER` | `R8` 2,2 k → puerta de `Q2`, con `R9` 4,7 k a masa | `TRISCbits.TRISC2 = 0` (`Cluster.c:113`); `ON_CLUSTER = LATC2 = 1`, `OFF = 0` (`Cluster.h:15-16`) | ✅ **SÍ** (el mapeo del pin es correcto; la etapa de potencia tiene otro problema, §8) |
| **14** | `VUSB` | — | **Sin conectar** (`no_connect`) | `#pragma config VREGEN = OFF` (`main.h:25`) → regulador USB desactivado. USB no se usa | ✅ **SÍ**, coherente |
| **15** | `RC4/D−/VM` | — | **Sin conectar** (`no_connect`) | No se usa | ✅ SÍ |
| **16** | `RC5/D+/VP` | — | **Sin conectar** (`no_connect`) | No se usa | ✅ SÍ |
| **17** | `RC6/TX/CK` | `MCU_TX` | `U2.2` (RXD del HC-06) | `TRISC6 = 0` (salida), EUSART, `SPBRG=32`, `BRGH=0` (`UART.h:26-38`) | ✅ **SÍ**. Baudios reales = 20 MHz/(64·33) = **9469 bd** → error −1,4 % frente a 9600. Dentro de tolerancia |
| **18** | `RC7/RX/DT/SDO` | `MCU_RX` | `U2.3` (TXD del HC-06) | `TRISC7 = 1` (entrada), `CREN=1`, `RCIE=1` (`UART.h:28,38,41`) | ✅ **SÍ** |
| **19** | `VSS` | `GND` | Masa | — | ✅ SÍ |
| **20** | `VDD` | `+5V` | Salida del 78M05 + `C6` 0,1 µF a 2,77 mm | — | ✅ SÍ |
| **21** | `RB0/AN12/SDI/SDA` | `SDA` | `U4.5` (DS1307) + `R5` 4,7 k a `+5V` | `TRISBbits.RB0 = PIN_IN` (`I2C.c:11`), MSSP maestro I²C `SSPM=0b1000`, 100 kHz (`I2C.c:16,20`) | ✅ **SÍ**. `ADCON1 = 0x0F` en `main.c:115` neutraliza el `PBADEN = ON` de `main.h:33` antes de inicializar el I²C |
| **22** | `RB1/AN10/SCK/SCL` | `SCL` | `U4.6` (DS1307) + `R6` 4,7 k a `+5V` | `TRISBbits.RB1 = PIN_IN` (`I2C.c:12`) | ✅ **SÍ** |
| **23** | `RB2/AN8/INT2` | — | **Sin conectar** (`no_connect`) | No se usa | ✅ SÍ |
| **24** | `RB3/AN9/CCP2` | — | **Sin conectar** (`no_connect`) | No se usa | ✅ SÍ |
| **25** | `RB4/AN11/KBI0` | — | **Sin conectar** (`no_connect`) | No se usa | ✅ SÍ |
| **26** | `RB5/KBI1/PGM` | — | **Sin conectar** (`no_connect`) | `#pragma config LVP = OFF` (`main.h:39`) → PGM no se usa. Correcto dejarlo libre | ✅ SÍ |
| **27** | `RB6/KBI2/PGC` | `PGC` | `J1.5` (ICSP) | Programación | ✅ SÍ |
| **28** | `RB7/KBI3/PGD` | `PGD` | `J1.4` (ICSP) | Programación | ✅ SÍ |

### 5.1 Verificación específica solicitada

| Verificación | Resultado |
|---|---|
| **LATA0 → LED de vida** | ✅ RA0 (pin 2) = neto `LED_LIVE` → cátodo de D1. Activo bajo, coincide con `ON_LED_LIVE = LATA0 = 0` |
| **LATC0 → buzzer** | ❌ **FALLA.** RC0 (pin 11) = neto `BUTTON` (pulsador SW1 + pull-up R4). El buzzer está en RC1 (pin 12) |
| **LATC2 → salida cluster** | ✅ RC2 (pin 13) = neto `CLUSTER` → R8 → puerta de Q2 |
| **RC6/RC7 → UART TX/RX** | ✅ RC6 = `MCU_TX` → HC-06 RXD; RC7 = `MCU_RX` ← HC-06 TXD. Sin cruce |
| **SCL/SDA del MSSP → DS1307** | ✅ RB1/SCL (pin 22) y RB0/SDA (pin 21) van directamente a U4.6 y U4.5, con pull-ups R6/R5 de 4,7 k a +5 V |
| **AN1 (`ADC_read(1)`, tensión)** | ✅ RA1 (pin 3) = `S_VOLT`. `PCFG=0b1011` la habilita como analógica |
| **AN3 (`ADC_read(3)`, temperatura)** | ❌ **FALLA.** RA3 (pin 5) = `S_TEMP` ← LM35. **`PCFG=0b1011` deja AN3 como digital.** Confirmado contra el propio comentario del código: `//Entradas Analogicas a0, a1, a2` (`main.c:175`) |
| **MCLR** | ✅ Pin 1, pull-up R2 10 k a +5 V y salida al ICSP J1.1. `MCLRE = ON` |

### 5.2 Diagnóstico del hallazgo C1 — la evidencia

El propio código conserva la huella del cambio:

```c
// Buzzer.c:161-165
void pinConfBuzzer(void)
{
    //TRISCbits.TRISC1 = 0;     ← LA LÍNEA CORRECTA, COMENTADA
    TRISCbits.TRISC0 = 0;       ← la línea que se dejó activa
}
```

`RC1` es exactamente el pin al que va el neto `BUZZER` en el esquemático. Alguien cambió `TRISC1` por `TRISC0` (y `LATC1` por `LATC0` en `Buzzer.h:24-25`) y **el esquemático nunca se actualizó**, o bien el cambio fue un error. La corrección de firmware es de dos líneas; ninguna corrección de firmware arregla, en cambio, el hallazgo C2 (R15 = 100 k).

---

## 6. Divisor de medida de tensión — ✅ CORRECTO

**Firmware** (`Aplicacion.c:211-214`):

```c
ap.fVolt = ADC_read(1);
ap.fVolt = (5.0/1024) * ap.fVolt;   // ADC → voltios en el pin
ap.fVolt = (ap.fVolt * 6) + 0.3;    // factor de divisor + compensación de diodo
ap.fVolt = ap.fVolt * 10;           // escala a decivoltios
```

**Hardware** (netlist del esquemático, `:9166` y `:11859`):

```
VCC ──[ R13 = 100 kΩ ]──┬── S_VOLT ── U1.3 (RA1/AN1)
                        ├── C5 0,1 µF ── GND
                        ├── D5 (zener 5V1, cátodo aquí) ── GND
                        └──[ R14 = 20 kΩ ]── GND
```

**Comprobación del factor:**

```
Ganancia del divisor = R14 / (R13 + R14) = 20k / 120k = 1/6
Factor de reconstrucción necesario = (R13 + R14) / R14 = 120k / 20k = 6,000
Factor aplicado por el firmware                        = 6
```

**El factor 6 corresponde exactamente a las resistencias montadas.** La medida de batería es correcta.

**El término `+ 0,3`** compensa la caída del Schottky `D3` (1N5822), ya que el divisor cuelga de `VCC` (después de D3) y no de `+12V` (antes). Con la corriente típica del conjunto (25–75 mA) la Vf del 1N5822 está en 0,30–0,40 V, así que la constante es razonable. No es exacta a todas las cargas (a 25 mA es ~0,30 V, a 75 mA ~0,38 V), lo que introduce un error de hasta **±0,08 V**.

**Resolución y errores:**

| Parámetro | Valor |
|---|---|
| LSB del ADC | 5 V / 1024 = 4,88 mV |
| LSB referido a la entrada | 4,88 mV × 6 = **29,3 mV** |
| Lectura a 12,0 V de entrada | S_VOLT = (12,0 − 0,3) × 1/6 = 1,95 V → ADC ≈ 399 |
| Fondo de escala (ADC = 1023) | 5,00 × 6 + 0,3 = **30,3 V** |
| Error por tolerancia del 78M05 (Vref = VDD, `VCFG = 0b00`) | **±4 %** → ±0,48 V a 12 V |
| Error por tolerancia de R13/R14 (si son ±1 %) | ±1,2 % adicional |
| Impedancia de fuente vista por el ADC | R13‖R14 = **16,7 kΩ**, frente a los **2,5 kΩ máximos** que exige la hoja de datos del PIC18F2550. Mitigado por C5 (0,1 µF ≫ Chold 25 pF), que actúa como depósito de carga. Aceptable en DC, pero fuera de especificación formal |

> **Conclusión:** el factor 6 es correcto; el error dominante es la tolerancia del 7805 usado como referencia del ADC (±4 %). Si se quiere una medida de batería fiable a mejor del 1 %, hay que usar una referencia de tensión, no VDD.

---

## 7. Sensor de temperatura — ❌ FÓRMULA INCORRECTA

**Componente identificado:** `U5 = LM35-LP`, footprint `Package_TO_SOT_THT:TO-92L_Inline_Wide` (`balizaSR30.kicad_sch:10139`). Es un **LM35 en encapsulado TO-92**, sensor analógico de precisión, **no** un termistor.

**Conexionado:**

| Pin U5 | Neto | Va a |
|---|---|---|
| 1 (`+VS`) | `+5V` | Raíl de 5 V |
| 2 (`Vout`) | `S_TEMP` | `U1.5` (RA3/AN3) y `C7` (0,1 µF a GND) |
| 3 (`GND`) | `GND` | Masa |

**Firmware** (`Aplicacion.c:227-229`):

```c
ap.fTemp = ADC_read(3);
ap.fTemp = (5.0/1024) * ap.fTemp;   // ADC → voltios
ap.fTemp = ap.fTemp * 10;           // ← FACTOR 10
```

**Lo que exige un LM35:**

```
Salida del LM35 = 10 mV/°C  →  T[°C] = V × 100
El firmware aplica            T      = V × 10
```

**La fórmula está mal por un factor de 10 exacto.** A 25 °C el LM35 entrega 250 mV; el firmware calcularía `0,250 × 10 = 2,5`. Si la intención era enviar décimas de grado (como hace con la tensión, que multiplica por 10 al final para dar decivoltios), el factor tendría que ser **1000**, no 10.

**Problemas adicionales de este bloque:**

1. **AN3 está deshabilitado** (hallazgo C3). Aunque se corrija la fórmula, el canal no está configurado como analógico.
2. **C7 (0,1 µF) está directamente en la salida del LM35.** La hoja de datos del LM35 advierte que el amplificador de salida sólo tolera **50 pF** de carga capacitiva; con cargas mayores hay que interponer una resistencia serie (típicamente 75 Ω) o usar la red R-C recomendada. **100 nF = 100 000 pF, 2000 veces el límite.** Es una causa clásica de oscilación de la salida del LM35, que se manifiesta como lecturas erráticas.
3. **El LM35 en configuración de una sola alimentación no puede medir por debajo de 0 °C** (necesita una resistencia de −VS o un raíl negativo). Para una baliza de exterior en clima frío, el rango medible arranca en +2 °C.
4. **Resolución:** con Vref = 5 V y 10 bits, el LSB es 4,88 mV = **0,49 °C**, y sólo se usa el 30 % del fondo de escala (0–1,5 V para 0–150 °C).
5. **El LM35 en TO-92 soldado a la placa mide la temperatura de la propia placa**, no la del ambiente ni la del interior de la carcasa. Está colocado en `(112,95 · 97,85)`, a 34 mm del regulador U3 y a 29 mm de Q2, lo que es aceptable, pero sigue midiendo cobre.

---

## 8. Etapa de salida "CLUSTER"

### 8.1 Topología

```
U1.13 (RC2) ──[ R8 = 2,2 kΩ ]──┬── puerta (G) de Q2
                               └──[ R9 = 4,7 kΩ ]── GND

Q2 = MOSFET canal N, TO-220-3, símbolo Q_NMOS_GDS (SIN REFERENCIA)
   Fuente (S)  ── GND
   Drenador (D) ──[ R16 = 0 Ω, 2010 ]── J3.2

J3.1 ── +12V  (crudo, ANTES de D3)
J3.2 ── drenador de Q2 vía R16
```

Es un **conmutador de lado bajo (low-side)**: la carga se conecta entre `J3.1` (+12 V) y `J3.2` (retorno conmutado a masa por el MOSFET). La serigrafía superior muestra `CLUSTER` en `(104,75 · 126,05)` y un `+` en `(112,05 · 131,25)`, junto a `J3` en `(112,075 · 128,03)`.

### 8.2 Qué conmuta: análisis

| Aspecto | Valor / hallazgo |
|---|---|
| **Elemento de conmutación** | MOSFET de canal N en TO-220 (`Q2`). **No** hay relé, **no** hay optoacoplador, **no** hay driver de puerta. |
| **Referencia del MOSFET** | ⚠ **DESCONOCIDA.** El esquemático y el .xls llevan `Q_NMOS_GDS`, el símbolo genérico de KiCad. No es un componente comprable. |
| **Tensión de puerta** | `Vgs = 5 V × R9/(R8+R9) = 5 × 4,7/6,9 = ` **3,41 V** ⚠ El divisor R8/R9 atenúa la salida de 5 V del PIC. |
| **Consecuencia** | Un MOSFET estándar (IRF540N, IRF640, …) tiene Vgs(th) de hasta 4 V: **con 3,41 V no conmuta**, o entra en zona lineal y se destruye por disipación. Sólo funciona con un **MOSFET *logic-level*** (IRLZ44N, IRL540N, IRLB8721…), y aun así 3,41 V queda por debajo de los 4,5–5 V a los que se especifica su Rds(on), por lo que la resistencia de conducción real será mayor que la de catálogo. |
| **Por qué existe R8/R9** | R9 es un *pull-down* de puerta correcto (mantiene el MOSFET apagado mientras el PIC arranca con los puertos en alta impedancia). El error es haber dejado R8 en serie: con R8 = 0 Ω (o un valor pequeño como 100 Ω) y R9 = 10 k, la puerta recibiría los 5 V íntegros. |
| **Velocidad de conmutación** | La red R8+R9 en paralelo con la Ciss del MOSFET da una constante de τ ≈ 1,5 kΩ × Ciss. Con un IRLZ44N (Ciss ≈ 1700 pF) → τ ≈ 2,6 µs. Suficiente para conmutación ON/OFF lenta (el firmware usa periodos de décimas de segundo, `PERIOD_CLUSTER 10`), pero inaceptable para PWM. |
| **Diodo de rueda libre** | ❌ **NO EXISTE.** El neto del drenador (`Net-(Q2-D)`) sólo contiene `Q2.2` y `R16.1`; el neto de `J3.2` sólo contiene `J3.2` y `R16.2`. **No hay ningún diodo entre `J3.2` y `+12V`.** Si la carga tiene componente inductiva (un relé externo, un motor, una bobina, un cable largo), el pico de apertura sólo lo absorbe el avalanchado del MOSFET. |
| **Contraste con la etapa del buzzer** | El buzzer sí tiene rueda libre (`D4`). En la etapa de potencia, que es la que realmente lo necesita, **no la hay**. |

### 8.3 Corriente y tensión máximas

| Límite | Valor | Origen |
|---|---|---|
| **Tensión de trabajo** | 12 V nominales; sin TVS ni supresor, cualquier transitorio de la fuente llega íntegro al drenador | `+12V` sin protección (§4.4) |
| **Conector J3 (Molex KK-396 / 5273)** | ≈ 5 A por contacto | Especificación de la serie |
| **R16 (0 Ω en 2010)** | Un puente de 0 Ω en 2010 se especifica típicamente para **2–3 A** y ~0,75 W. **Es el cuello de botella más estrecho de todo el camino.** | `balizaSR30.kicad_sch:9302` |
| **Pista del drenador (`Net-(Q2-D)`, 1,4 mm)** | 3,05 A a ΔT=10 °C / 4,14 A a ΔT=20 °C | IPC-2221, cobre externo 35 µm |
| **Pista `J3.2` (1,4 mm)** | Ídem | |
| **Alimentación `+12V` hasta J3.1** | tramos de 2,5 mm (60,7 mm de longitud), 1,5 mm (20,1 mm) y **1,0 mm (27,3 mm)** → limitada por el tramo de 1,0 mm a **2,39 A** a ΔT=10 °C | `balizaSR30.kicad_pcb` |
| **Retorno de masa** | Sólo pistas de 1,0 mm (388 mm de longitud) y tramos de 0,8 mm y **0,6 mm** → **1,65 A** en el peor tramo | Ver §10, riesgo R8 |
| **MOSFET Q2** | Indeterminado (sin referencia) | — |

> **Corriente máxima recomendable de la salida CLUSTER, tal como está la placa: 1,5 A.** El límite lo fija el tramo de masa de 0,6 mm y el puente de 0 Ω en 2010, no el MOSFET ni el conector.

### 8.4 Qué carga se supone conectada

**No consta en ningún fichero del proyecto.** Ni el esquemático, ni el .xls, ni la serigrafía, ni el firmware especifican la carga. El nombre "cluster" y el contexto (baliza vial de IT VIAL SAS) sugieren un conjunto de lámparas/LED de señalización de 12 V. El firmware la acciona con una máquina de estados de destello (`Cluster.c`, estados `ST_HIGH_CL`, `ST_LOW_CL`, `ST_LOW_SLOW_CL`, periodo base `PERIOD_CLUSTER = 10`).

**Esto es una pregunta abierta bloqueante** (ver §12): sin saber la corriente y la naturaleza (resistiva/inductiva) de la carga no se puede elegir Q2 ni decidir si hace falta el diodo de rueda libre.

---

## 9. La PCB

### 9.1 Datos del fichero `balizaSR30.kicad_pcb`

| Parámetro | Valor | Origen |
|---|---|---|
| **Capas de cobre** | **2** (`F.Cu` = 0, `B.Cu` = 31) | nodo `layers` |
| **Espesor de placa** | **1,6 mm** | `(general (thickness 1.6))` |
| **Apilado** | Serigrafía sup. / pasta sup. / máscara sup. 0,01 mm / **F.Cu 35 µm** / dieléctrico FR4 1,51 mm (εr 4,5, tanδ 0,02) / **B.Cu 35 µm** / máscara inf. 0,01 mm / pasta inf. / serigrafía inf. | nodo `setup > stackup` |
| **Dimensiones (Edge.Cuts)** | X: 102,85 → 179,85 mm · Y: 55,05 → 145,05 mm → **77,00 × 90,00 mm** (6930 mm²) | `Edge.Cuts` (rectángulo cerrado de 4 segmentos) |
| **Acabado superficial** | `"Finish": "None"` — **no especificado** | `balizaSR30-job.gbrjob` |
| **Reglas de diseño declaradas** | PadToPad 0,2 · PadToTrack 0,2 · TrackToTrack 0,2 · **MinLineWidth 0,6** · TrackToRegion 1,2 · RegionToRegion 1,2 (mm) | `.gbrjob` |

### 9.2 Tecnología: mixta, y estrictamente separada por caras

| Cara | Componentes | Tecnología |
|---|---|---|
| **F.Cu (superior)** | `BT1, BZ1, C3, C4, D1, D2, D3, D4, D5, J1, J2, J3, Q2, SW1, U1, U2, U3, U4, U5, Y1, Y2` (21) | **100 % THT** (`attr through_hole`) |
| **B.Cu (inferior)** | `C1, C2, C5, C6, C7, Q4, R1, R2, R3, R4, R5, R6, R8, R9, R11, R12, R13, R14, R15, R16` (20) | **100 % SMD** (`attr smd`) — resistencias 1206 y 2010, condensadores 0805, un SOT-23 |

Es el patrón clásico "THT arriba, SMD abajo en la cara de soldadura": se puede montar por ola o por reflow selectivo en la cara inferior más soldadura manual/ola en la superior.

### 9.3 Enrutado — **todo en una sola capa**

| Métrica | Valor |
|---|---|
| Segmentos de pista en `B.Cu` | **309** |
| Segmentos de pista en `F.Cu` | **0** |
| **Vías** | **0** |
| Gerber `F_Cu.gbr` | 0 trazos (`D01`), 0 regiones (`G36`), sólo **86 flashes de pad** (`D03`) |
| Gerber `B_Cu.gbr` | 5338 trazos, 10 regiones rellenas |

**La cara superior no lleva ni una pista ni un plano: sólo los anillos de los pads de agujero pasante.** Todo el enrutado, los 41 componentes SMD y el plano de masa comparten la cara inferior. Es un diseño de una cara "disfrazado" de dos caras (necesita agujeros metalizados para conectar los pads THT de arriba con el cobre de abajo, y por eso el taladro es PTH).

### 9.4 Anchos de pista

| Ancho | Segmentos | Capacidad IPC-2221 (35 µm, externa) |
|---|---|---|
| **0,600 mm** ← mínimo | 12 | 1,65 A (ΔT 10 °C) / 2,24 A (ΔT 20 °C) |
| 0,800 mm | 24 | 2,03 A / 2,76 A |
| 1,000 mm | 226 | 2,39 A / 3,24 A |
| 1,200 mm | 6 | 2,73 A / 3,70 A |
| 1,400 mm | 15 | 3,05 A / 4,14 A |
| 1,500 mm | 20 | 3,21 A / 4,35 A |
| 2,500 mm | 6 | 4,65 A / 6,30 A |

**Ancho mínimo usado: 0,6 mm (24 mil)**, coincidente con el `MinLineWidth` declarado en el `.gbrjob`. Es una regla muy holgada — cualquier fabricante la produce sin recargo — y refleja que el diseño no tiene zonas densas.

Distribución por neto (longitud total en cada ancho):

| Neto | Anchos usados |
|---|---|
| `+12V` | 1,00 mm : 27,3 mm · 1,50 mm : 20,1 mm · **2,50 mm : 60,7 mm** |
| `+5V` | 1,00 : 85,4 · 1,20 : 29,9 · 1,40 : 33,4 · 1,50 : 9,8 mm |
| `GND` | **0,60 : 12,5** · 0,80 : 40,4 · 1,00 : 388,4 mm |
| `VCC` | 1,00 : 22,2 · 1,50 : 22,4 mm |
| `Net-(Q2-D)` (drenador cluster) | 1,40 : 8,3 mm |
| `Net-(J3-Pin_2)` (salida cluster) | 1,40 : 8,7 mm |
| `CLUSTER` (puerta) | 0,80 : 3,8 mm |
| `Net-(Q2-G)` | 0,80 : 16,4 mm |
| `SDA` / `SCL` | 1,00 : 15,8 / 29,8 mm |
| `S_VOLT` / `S_TEMP` | 1,00 : 20,6 / 16,7 mm |
| `OSC1` / `OSC2` | 1,00 : 10,3 / 10,9 mm |

### 9.5 Plano de masa — presente pero fragmentado y en la misma capa que todo

Hay **una zona `GND` en `B.Cu`**, rellenada, con `min_thickness = 0,5 mm`, `clearance = 1,2 mm`, `thermal_gap = 0,508 mm` y `thermal_bridge_width = 0,508 mm` (alivios térmicos por defecto).

| Isla | Vértices | Área |
|---|---|---|
| 1 (principal) | 4099 | **3629,1 mm²** |
| 2 | 187 | 59,6 mm² |
| 3 | 260 | 55,6 mm² |
| 4 | 98 | 9,3 mm² |
| 5 | 58 | 9,1 mm² |
| 6 | 85 | 8,4 mm² |
| 7 | 130 | 8,0 mm² |
| 8 | 46 | 5,0 mm² |
| 9 | 50 | 2,4 mm² |
| 10 | 16 | 0,9 mm² |
| **Total** | | **3787,4 mm² = 54,7 % de la placa** |

**Interpretación:** el 96 % del cobre de masa está en una isla única y grande, lo cual es bueno. Pero:

- **No hay plano en `F.Cu`.** Toda la referencia de masa vive en la misma capa que las 309 pistas de señal, que la trocean.
- Las **9 islas secundarias (158 mm² en total)** son cobre huérfano: si alguna no toca ningún pad de GND ni ninguna pista, es cobre flotante que actúa como antena. Con `clearance = 1,2 mm` (muy grande) y `min_thickness = 0,5 mm`, el relleno se retira mucho de las pistas y se fragmenta con facilidad.
- El retorno de masa de la etapa de potencia (Q2) comparte pistas con el retorno analógico de `S_VOLT` y `S_TEMP`. Ver riesgo R8 en §10.

### 9.6 Taladros

**PTH** (`balizaSR30-PTH.drl`) — 86 agujeros, 10 herramientas:

| Herramienta | Ø (mm) | Uso probable |
|---|---|---|
| T1 | 0,500 | — |
| T2 | 0,750 | — |
| T3 | 0,800 | Mayoría de pads THT (37) |
| T4 | 0,900 | — |
| T5 | 0,962 | Cabeceras |
| T6 | 1,000 | DIP / cristales (15) |
| T7 | 1,100 | Electrolíticos (10) |
| T8 | 1,500 | — |
| T9 | 1,600 | — |
| T10 | 1,800 | Molex KK-396 (4) |

**NPTH** (`balizaSR30-NPTH.drl`) — 6 agujeros:

| Ø | Cantidad | Posiciones | Uso |
|---|---|---|---|
| 3,500 mm | 2 | `(123,85 · −140,79)`, `(162,69 · −62,35)` | Fijación de la aleta de los TO-220 (`Q2` y `U3`) |
| 4,300 mm | 4 | `(108,85 · −61,05)`, `(108,85 · −139,05)`, `(172,85 · −61,05)`, `(172,85 · −139,05)` | **Taladros de montaje** — patrón rectangular de **64,0 × 78,0 mm** |

### 9.7 Contraste con `gerbers_baliza\` — comprobación de completitud

| Capa necesaria | Fichero | ¿Presente? | Tamaño | Contenido verificado |
|---|---|---|---|---|
| Cobre superior | `balizaSR30-F_Cu.gbr` | ✅ | 9 136 B | 86 pads, **0 pistas, 0 regiones** |
| Cobre inferior | `balizaSR30-B_Cu.gbr` | ✅ | 165 682 B | 5338 trazos, 10 regiones (plano GND) |
| Máscara superior | `balizaSR30-F_Mask.gbr` | ✅ | 5 189 B | — |
| Máscara inferior | `balizaSR30-B_Mask.gbr` | ✅ | 7 732 B | — |
| Serigrafía superior | `balizaSR30-F_Silkscreen.gbr` | ✅ | 73 404 B | — |
| Serigrafía inferior | `balizaSR30-B_Silkscreen.gbr` | ✅ | 36 278 B | — |
| Contorno de placa | `balizaSR30-Edge_Cuts.gbr` | ✅ | 713 B | Rectángulo cerrado 77,00 × 90,00 mm |
| Taladro metalizado | `balizaSR30-PTH.drl` | ✅ | 2 332 B | 86 agujeros, formato Excellon métrico absoluto |
| Taladro no metalizado | `balizaSR30-NPTH.drl` | ✅ | 516 B | 6 agujeros |
| Fichero de trabajo | `balizaSR30-job.gbrjob` | ✅ | 2 832 B | Declara 2 capas, 1,6 mm, 77,1 × 90,1 mm |
| Pasta superior | `balizaSR30-F_Paste.gbr` | ✅ | 468 B | **Vacío (0 aperturas)** — correcto, no hay SMD arriba |
| Pasta inferior | `balizaSR30-B_Paste.gbr` | ✅ | 14 400 B | 241 operaciones ⚠ ver abajo |

**✅ El juego de gerbers está COMPLETO para fabricar la placa desnuda.** Están las dos caras de cobre, ambas máscaras, ambas serigrafías, el contorno y los dos ficheros de taladro (PTH y NPTH separados, como debe ser).

**⚠ Defectos detectados en el juego de gerbers:**

1. **`B_Paste.gbr` contiene texto de logotipo como aberturas de pasta.** El `.kicad_pcb` tiene un `gr_text` con el contenido `'IT VIAL SASnitvial.comn 22-10-22'` colocado en la capa **`B.Paste`** en `(166,35 · 119,35)`. De las 241 operaciones del fichero, sólo ~40 corresponden a los pads SMD reales; el resto son los trazos del texto. **Si se encarga un stencil, se cortará el texto en la lámina y se depositará pasta de soldadura con forma de letras sobre laminado desnudo.** Hay que borrar ese texto o moverlo a `B.SilkS` antes de pedir stencil.
2. **La serigrafía tiene los saltos de línea rotos.** El texto `'IT VIAL SASnitvial.comn 22-10-22'` aparece dos veces (en `F.SilkS` en `(111,35 · 109,25)` y en `B.Paste`). Debería leerse `IT VIAL SAS` / `itvial.com` / `22-10-22`; los `\n` se han convertido en la letra `n` literal. **Se fabricará serigrafiado tal cual: "IT VIAL SASnitvial.comn 22-10-22".**
3. **`"Finish": "None"`** en el `.gbrjob`: no se especifica acabado superficial. El fabricante aplicará HASL por defecto.
4. **`"Revision": "rev?"`** en el `.gbrjob`: el proyecto no tiene revisión asignada (el esquemático sí: V1.0). Sin control de revisión en el juego de fabricación no hay forma de saber qué versión llegó al fabricante.
5. **No se exportaron** fichero de posiciones (`.pos`) para montaje automático, plano de taladros (drill map), ni plano de fabricación. No son imprescindibles para la placa desnuda, sí lo son si se contrata el montaje.

**Contenido del `.rar`:** `gerbers_baliza_2025_06_24.rar` (66 460 B) contiene exactamente los mismos 12 ficheros. Es el paquete listo para subir a un fabricante.

---

## 10. Revisión de diseño — problemas y riesgos

Ordenados por severidad. Los cinco críticos ya están en §0; aquí van todos, incluidos los críticos con su referencia cruzada.

### 🔴 Críticos (impiden el funcionamiento)

| Id | Riesgo | Referencia / neto | Detalle y acción |
|---|---|---|---|
| **R1** | Buzzer en el pin equivocado | Neto `BUZZER` → `U1` pin 12 (RC1); firmware ataca RC0 | Hallazgo **C1**. Corregir firmware: `Buzzer.h:24-25` → `LATC1`, `Buzzer.c:162-163` → `TRISC1 = 0`. **Y comprobar que nada más use RC0**, porque ahí está el pulsador |
| **R2** | Cortocircuito potencial del pin RC0 | Netos `BUTTON` / `GND` vía `D2`, `SW1` | Mientras el firmware ponga RC0 como salida, pulsar SW1 con LATC0=1 pone la salida del PIC a masa a través de D2 (0,7 V de caída). Corriente limitada sólo por la impedancia de salida del puerto — por encima del máximo de 25 mA por pin |
| **R3** | Buzzer con 100 kΩ en serie | `R15` (`:9096`), neto entre `+12V` y `BZ1.1` | Hallazgo **C2**. Corriente máxima 120 µA. Sustituir R15 por el valor correcto una vez se conozca el buzzer (típicamente 0 Ω o 100–330 Ω), **y** verificar la polaridad de BZ1: el pin `+` está en el lado del colector |
| **R4** | Puerta del MOSFET con 3,41 V | `R8` (`:10703`) / `R9` (`:12060`) | Hallazgo **C5**. Poner R8 = 0 Ω (o 100 Ω) y R9 = 10 kΩ → Vgs = 4,95 V. Y **definir la referencia de Q2**, obligatoriamente *logic-level* |
| **R5** | Canal AN3 deshabilitado por el propio firmware | `main.c:175` vs `U1` pin 5 (`S_TEMP`) | Hallazgo **C3**. Cambiar `PCFG` a `0b1010` (AN0–AN3 analógicas) o `0b0000`. Verificar que eso no rompa nada más en PORTA |

### 🟠 Altos (fallo de campo o daño a componentes)

| Id | Riesgo | Referencia / neto | Detalle y acción |
|---|---|---|---|
| **R6** | **Sin diodo de rueda libre en la salida CLUSTER** | Netos `Net-(Q2-D)` y `Net-(J3-Pin_2)` | Los netos del drenador y de `J3.2` contienen sólo `Q2.2`/`R16.1` y `R16.2`/`J3.2`. **No hay diodo hacia `+12V`.** Si la carga es un relé, un motor o simplemente un cable largo (inductancia parásita), cada apertura genera un pico que sólo absorbe el avalanchado del MOSFET. **Añadir un Schottky (p. ej. SS34) entre `J3.2` (ánodo) y `+12V` (cátodo).** |
| **R7** | **HC-06 alimentado a 5 V y con RXD atacado a 5 V** | `U2.5` ← `+5V`; `U2.2` (RXD) ← `MCU_TX` (RC6, salida CMOS 5 V) | El chip HC-06 desnudo trabaja a 3,3 V. Las placas portadoras comunes (ZS-040 / JY-MCU) llevan LDO y aceptan 3,6–6 V en VCC, **pero su pin RXD sigue siendo de 3,3 V y su hoja de datos exige un divisor desde un TX de 5 V**. Aquí `RC6` ataca `RXD` directamente, sin resistencia. Es la causa típica de mortalidad prematura del módulo. **Añadir un divisor 1k/2k en `MCU_TX`, o una resistencia serie de 1 kΩ como mínimo.** El sentido contrario (TXD 3,3 V → RC7) sí funciona: VIH del PIC a 5 V es 0,25·VDD+0,8 = 2,05 V |
| **R8** | **El retorno de potencia comparte pistas con el retorno analógico** | Neto `GND`: 388 mm a 1,0 mm, 40 mm a 0,8 mm, **12,5 mm a 0,6 mm** | La corriente de la carga del cluster vuelve por la fuente de `Q2` a las mismas pistas de masa que referencian `S_VOLT`, `S_TEMP` y el VSS del PIC. Con 1 A y un tramo de 0,6 mm × 35 µm × 12,5 mm, la caída óhmica es ≈ 10 mV, que a 29,3 mV/LSB en la medida de tensión ya es visible; con corrientes conmutadas y transitorios el ruido inyectado es mucho mayor. **Ensanchar el retorno de Q2 a ≥ 2,5 mm y llevarlo directamente al pad de masa de `J2` sin pasar por la zona del PIC** |
| **R9** | **`+12V` de `J3.1` y `R15` no están protegidos contra polaridad inversa** | `J3.1`, `R15.1`, `J2.1` (todos en `+12V`, antes de `D3`) | `D3` sólo protege el ramal del regulador. Con la fuente invertida, `J3.1` queda a −12 V y el diodo de cuerpo de `Q2` conduce. **Mover `J3.1` y `R15.1` al neto `VCC` (después de D3)**, o poner el diodo/MOSFET de protección en la entrada de `J2` |
| **R10** | **No hay fusible ni TVS en la entrada** | `J2` | §4.4. En una baliza vial alimentada de batería/línea larga, la ausencia de TVS deja al 1N5822 (VRRM = 40 V) y al MOSFET expuestos a transitorios de carga (load dump). **Añadir un TVS bidireccional o unidireccional de 18–24 V y un polyfuse en `J2.1`** |
| **R11** | **`RA4` atado a `+5V` y `RA5` atado a `GND`, sin resistencia** | `U1` pines 6 y 7 | Son E/S digitales bidireccionales cortocircuitadas a un raíl. Hoy no da problemas porque el firmware nunca configura TRISA4/TRISA5 (quedan como entradas tras reset). **Cualquier futura línea `TRISA = 0x00` o `LATA = ...` provoca un cortocircuito directo del driver de salida al raíl.** Es una bomba de relojería para el siguiente que toque el firmware. **Añadir una resistencia de 1–10 kΩ en serie, o dejar los pines al aire** |
| **R12** | **DS1307 sin condensador de desacoplo** | `U4.8` (`+5V`) | El condensador más cercano a `U4.8` está **a 16,19 mm** (es `C6`, que sirve al PIC). La hoja de datos del DS1307 (circuito típico de aplicación) exige 0,1 µF en VCC. Sin él, cualquier transitorio en `+5V` puede corromper los registros del RTC o disparar el flag de oscilador parado. **Añadir un 0,1 µF 0805 junto a `U4` pines 8-4** |

### 🟡 Medios

| Id | Riesgo | Referencia / neto | Detalle |
|---|---|---|---|
| **R13** | **Condensadores de carga del cristal a 10 mm del PIC** | `C1` ↔ `U1.10`: **10,27 mm** · `C2` ↔ `U1.9`: **10,11 mm** · `C1.1`/`C2.1` ↔ `U1.8` (VSS): **13,85 / 12,17 mm** | El propio cristal `Y1` sí está cerca (6,42 / 6,65 mm de OSC1/OSC2), pero los 22 pF están en la **cara opuesta** y a 10 mm, con el retorno de masa a 12–14 mm. El bucle del oscilador es de más de 20 mm de perímetro. En un oscilador HS de 20 MHz esto degrada el margen de arranque, aumenta la sensibilidad al ruido y radia el reloj. **Reubicar C1/C2 pegados al cristal, con su masa unida al pin 8 del PIC** |
| **R14** | **C7 (0,1 µF) directamente en la salida del LM35** | `C7` (`:12597`), neto `S_TEMP` | §7, punto 2. Excede en 2000× la carga capacitiva que admite el LM35. **Interponer una resistencia serie de 75–1000 Ω entre `U5.2` y el nodo `S_TEMP`** |
| **R15** | **Un solo condensador de desacoplo en toda la placa** | `C6` (`:10773`) | Sirve al par VDD(20)/VSS(19) a 2,8 mm — correcto. Pero `U1.8` (el otro VSS) queda a **6,60 mm** sin cerámico propio, el HC-06 no tiene ninguno, el DS1307 tampoco (R12) y el 78M05 tampoco. **La hoja de datos del LM78M05 pide 0,33 µF cerámico en la entrada y 0,1 µF en la salida; en la placa sólo hay electrolíticos (C3 470 µF, C4 220 µF)** — un electrolítico no sustituye a un cerámico a alta frecuencia (ESR/ESL) y el 78M05 puede oscilar |
| **R16** | **Impedancia de fuente del divisor 6,7× por encima del máximo del ADC** | `R13`‖`R14` = **16,7 kΩ** vs. 2,5 kΩ máx. | Mitigado por `C5`. Aceptable en DC, pero fuera de especificación. Si se quisiera muestrear rápido habría que bajar el divisor a 10 k/2 k |
| **R17** | **Vref del ADC = VDD del 78M05 (±4 %)** | `ADCON1bits.VCFG = 0b00` (`main.c:174`) | Toda la precisión de la medida de batería está limitada por la tolerancia del regulador. ±0,48 V a 12 V |
| **R18** | **Sin plano de masa en la cara superior; todo el enrutado en una capa** | `F.Cu`: 0 pistas, 0 regiones | §9.3. Se desaprovecha por completo la segunda capa de una placa que ya se paga como de dos caras. Un plano sólido en `F.Cu` costaría cero y resolvería R8, R13 y parte de R15 |
| **R19** | **BOR y WDT desactivados** | `main.h:23` (`BOR = OFF`), `main.h:28` (`WDT = OFF`) | Sin supervisor externo ni brown-out, un descenso lento del raíl de 5 V (arranque de motor, §4.5) deja el PIC en estado indeterminado sin resetear. Sin watchdog, un bloqueo del bucle principal es permanente. En un equipo de seguridad vial esto es relevante |
| **R20** | **Batería del RTC sin diodo de aislamiento** | `BT1.1` → neto `+3V3` → `U4.3` (VBAT) | **Es correcto y deliberado**: el DS1307 conmuta internamente entre VCC y VBAT y su hoja de datos muestra la pila conectada directamente a VBAT sin diodo. No es un defecto. **Lo que sí hay que verificar es que se monte una pila NO recargable (CR2032)**: el DS1307 no carga la pila, así que una recargable se descargaría sin recuperarse |

### 🟢 Bajos / cosméticos

| Id | Riesgo | Referencia | Detalle |
|---|---|---|---|
| **R21** | Cristal del RTC rotulado `37Khz` | `Y2` (`:8565`) | Debe ser 32,768 kHz, CL 12,5 pF. Error de documentación que se propaga al .xls |
| **R22** | Símbolo `+3.3V` usado para una pila de 3,0 V | `#PWR0113`, neto `+3V3` | §4.2. Induce a error |
| **R23** | `J3` con `Value = "FUENTE"` en el esquemático pero serigrafía `CLUSTER` | `J3` (`:10975`) | Tres nombres para el mismo conector (`FUENTE` en el esquemático, vacío en el .xls, `CLUSTER` en la placa). **Riesgo real de conectar la fuente de 12 V a la salida del cluster**, porque ambos conectores son idénticos (mismo Molex KK-396 de 2 vías, mismo pin 1 = +12 V) y están en el mismo borde de la placa (X = 112,075), separados sólo 52 mm en Y. Si alguien invierte los dos conectores, la fuente entra por `J3.2` al drenador del MOSFET |
| **R24** | Serigrafía con `\n` literales | `gr_text` en `F.SilkS` `(111,35 · 109,25)` y en `B.Paste` `(166,35 · 119,35)` | Se serigrafiará `IT VIAL SASnitvial.comn 22-10-22` |
| **R25** | Texto en la capa `B.Paste` | `(166,35 · 119,35)` | §9.7 punto 1. Contamina el stencil |
| **R26** | `STATE` y `EN` del HC-06 sin conectar | `U2.1`, `U2.6` | Sin `STATE` el firmware no sabe si hay alguien conectado por Bluetooth (tendría que deducirlo del tráfico). Sin `EN`/`KEY` no se puede forzar el modo AT ni reiniciar el módulo por software. Son dos pines gratis en el PIC (hay 7 libres) |
| **R27** | `SQW/OUT` del DS1307 sin conectar | `U4.7` | No hay tic de 1 Hz por hardware. El firmware sondea por I²C, lo cual funciona, pero pierde la posibilidad de una base de tiempo precisa por interrupción |
| **R28** | 9 islas de cobre huérfanas en el plano `GND` | 158 mm² en total | §9.5. Cobre potencialmente flotante. Revisar en KiCad con "islas huérfanas: eliminar" |
| **R29** | `D2` (1N4007) usado como diodo de señal | `D2` (`:10566`) | Un rectificador de 1000 V/1 A en DO-41 para desacoplar un pulsador. Funciona, pero es un componente sobredimensionado y caro en un circuito donde bastaría un 1N4148 SMD |
| **R30** | `R16` = 0 Ω 2010 en el camino de potencia | `R16` (`:9302`) | §8.3. Es el eslabón más débil del camino de corriente (≈2 A). Si es un puente de depuración, sustituirlo por cobre; si es un punto de medida de corriente, documentarlo |

---

## 11. Fabricación

### 11.1 Qué hay en `gerbers_baliza\`

12 ficheros generados por KiCad 8.0.1 el **2025-06-24 15:43:58 −05:00**, más el `.rar` con los mismos 12. Ver la tabla completa en §9.7.

### 11.2 El fichero `.gbrjob`

`balizaSR30-job.gbrjob` es el fichero de trabajo Gerber X2/RS-274X que describe el conjunto al fabricante:

```json
"GeneralSpecs": { "ProjectId": { "Name": "balizaSR30", "Revision": "rev?" },
                  "Size": { "X": 77.1, "Y": 90.1 },
                  "LayerNumber": 2, "BoardThickness": 1.6, "Finish": "None" }
"DesignRules": [{ "Layers": "Outer", "PadToPad": 0.2, "PadToTrack": 0.2,
                  "TrackToTrack": 0.2, "MinLineWidth": 0.6,
                  "TrackToRegion": 1.2, "RegionToRegion": 1.2 }]
```

Declara correctamente los 9 ficheros gerber con su `FileFunction` (Copper L1 Top / Copper L2 Bot / SolderPaste / Legend / SolderMask / Profile) y el apilado completo con espesores. **Nota:** los ficheros de taladro (`.drl`) no aparecen en `FilesAttributes` — es el comportamiento normal de KiCad, pero hay que asegurarse de subir los dos `.drl` junto con el resto.

### 11.3 Qué haría falta para mandarla a fabricar HOY, tal cual

**La placa desnuda se puede fabricar hoy mismo sin tocar nada.** El juego está completo y las reglas (0,2 mm de aislamiento, 0,6 mm de pista mínima, taladro mínimo 0,5 mm, 2 capas, 1,6 mm) están dentro de las capacidades estándar y sin recargo de cualquier fabricante.

Especificación a dar al fabricante (no está en los ficheros, hay que decidirla):

| Parámetro | Valor a especificar | Estado en el fichero |
|---|---|---|
| Capas | 2 | ✅ declarado |
| Dimensiones | 77,0 × 90,0 mm | ✅ en `Edge_Cuts` |
| Espesor | 1,6 mm | ✅ declarado |
| Material | FR-4, Tg estándar | ✅ en el apilado |
| Cobre | 35 µm (1 oz) ambas caras | ✅ en el apilado |
| **Acabado superficial** | **⚠ HAY QUE ELEGIRLO** — `"Finish": "None"`. HASL sin plomo o ENIG | ❌ no especificado |
| **Color de máscara y serigrafía** | ⚠ hay que elegirlo (no está en los ficheros) | ❌ no especificado |
| Taladro mínimo | 0,5 mm | ✅ en `PTH.drl` |
| Vías | Ninguna (0 vías en el diseño) | ✅ |
| **Revisión** | **⚠ `"rev?"`** — asignar `V1.0` antes de enviar | ❌ |

**Antes de fabricar, corregir (coste cero, 10 minutos en KiCad):**

1. **Borrar o mover el `gr_text` de la capa `B.Paste`** en `(166,35 · 119,35)` — si no, el stencil sale con letras (§9.7 punto 1).
2. **Arreglar los `\n` de la serigrafía** en los dos `gr_text` de `IT VIAL SAS` (§9.7 punto 2). Se serigrafiará mal si no.
3. **Poner la revisión** en el título del proyecto para que el `.gbrjob` no diga `rev?`.
4. **Diferenciar `J2` y `J3` en la serigrafía.** Ambos son Molex KK-396 de 2 vías idénticos, ambos con +12 V en el pin 1, en el mismo borde. Añadir a la serigrafía de `J3` algo inequívoco (`SALIDA CLUSTER`) y a `J2` (`ENTRADA 12V`) — riesgo R23.
5. **Eliminar las islas huérfanas** del plano GND (riesgo R28).

**Antes de montar la primera unidad, decidir:**

6. **La referencia de `Q2`** — sin ella no se puede comprar la placa (hallazgo C5 / riesgo R4). Debe ser *logic-level*, y si además se corrige R8 a 0 Ω, cualquier MOSFET de puerta lógica de 30–60 V y Rds(on) < 50 mΩ sirve.
7. **La referencia y tipo de `BZ1`** — de ella depende el valor correcto de `R15` (hallazgo C2 / riesgo R3).
8. **La variante de `U2` (HC-06)** — módulo desnudo (3,3 V, se destruye a 5 V) o placa portadora con LDO (riesgo R7).
9. **La tensión de trabajo de `C3` (470 µF, va a 12 V → mínimo 25 V) y `C4` (220 µF, va a 5 V → mínimo 10 V)**, ausentes del BOM.
10. **`Y2` = 32,768 kHz CL 12,5 pF**, no "37 kHz".

**Si se contrata también el montaje**, hay que exportar además: fichero de posiciones (`.pos` / centroid), plano de fabricación con el patrón de taladros, y un BOM con referencias de fabricante — que hoy **no existe** (§2.9).

---

## 12. Preguntas abiertas

Todo lo siguiente **no se puede determinar de los ficheros del proyecto**. Va formulado como pregunta porque inventar un valor aquí acabaría en una placa fabricada mal.

### Sobre componentes sin referencia

1. **¿Qué MOSFET es `Q2`?** El símbolo es `Q_NMOS_GDS` (genérico de KiCad) y el footprint `TO-220-3_Horizontal_TabDown`. Con el divisor R8/R9 actual la puerta ve 3,41 V. **¿Es un MOSFET *logic-level*?** Si es un IRF540N o similar, la salida CLUSTER no funciona.
2. **¿Qué buzzer es `BZ1`?** El footprint es `Buzzer_12x9.5RM7.6` (12 mm, paso 7,6 mm). **¿Es magnético o piezoeléctrico? ¿Lleva oscilador interno? ¿A qué tensión trabaja: 5 V o 12 V?** De la respuesta depende el valor correcto de `R15` (hoy 100 kΩ) y si el montaje actual está simplemente mal dimensionado o además mal concebido.
3. **¿Qué diodo es `D4`?** Símbolo `D`, footprint A-405 (DO-35). Está como rueda libre del buzzer. ¿1N4148?
4. **¿Qué LED es `D1`?** `R1 = 330 Ω` desde 5 V asume Vf ≈ 1,9 V (rojo/ámbar). **¿Es rojo? Si es azul o blanco (Vf 3,0–3,4 V) la corriente cae a ~5 mA y el indicador de vida apenas se verá en exterior.**
5. **¿Qué variante de HC-06 es `U2`?** El footprint es una librería propia (`HC06:HC06`) de 6 pines THT. **¿Módulo desnudo de 3,3 V, o placa portadora tipo ZS-040/JY-MCU con LDO?** Determina si alimentarlo a 5 V lo destruye (riesgo R7).
6. **¿Qué tensión de trabajo tienen `C3` (470 µF) y `C4` (220 µF)?** No consta en el .xls. C3 cuelga de 12 V.

### Sobre la aplicación

7. **¿Qué carga se conecta a `J3` (CLUSTER)?** Ningún fichero del proyecto la define. **¿Qué corriente consume? ¿Es resistiva (lámparas/LED) o inductiva (relé, motor)?** Sin esta respuesta no se puede: (a) elegir `Q2`, (b) decidir si el diodo de rueda libre ausente (riesgo R6) es un defecto crítico o sólo recomendable, (c) validar si los 1,5 A que soporta el camino de cobre bastan.
8. **¿De qué se alimenta realmente la tarjeta?** ¿12 V de una batería de vehículo (con transitorios de load dump y caídas de arranque a 6 V), o una fuente de 12 V regulada? Determina si la ausencia de TVS (riesgo R10) y la ausencia de BOR (riesgo R19) son aceptables.
9. **¿La temperatura del LM35 se usa para algo?** `ap.fTemp` se calcula en `Aplicacion.c:227-229` pero **no se transmite ni se compara con nada en ninguna parte del firmware**. Lo mismo ocurre con `ap.fVolt`. **¿Es funcionalidad prevista y no terminada, o código muerto?** Si es código muerto, los hallazgos C3 y C4 no afectan a la operación actual.

### Sobre las decisiones de diseño

10. **¿Por qué `RA4` está atado a `+5V` y `RA5` a `GND`?** No hay resistencia en serie ni nota en el esquemático. ¿Es una decisión deliberada (fijar el estado de pines no usados) o un error de conexión?
11. **¿Qué función tenía `R16` (0 Ω en 2010) en el camino de potencia?** ¿Es un puente de depuración, un punto de corte para medir la corriente del cluster, o un placeholder para una resistencia de sensado que nunca se puso?
12. **¿Por qué el esquemático llama `FUENTE` tanto a `J2` como a `J3`,** cuando la serigrafía llama `CLUSTER` a `J3`? ¿Es un copiar-pegar sin corregir, o `J3` tuvo otra función en una revisión anterior?
13. **¿Existió una revisión previa con `R7`, `R10`, `Q1` y `Q3`?** Los huecos en la numeración sugieren componentes eliminados. **¿Alguno de ellos era el diodo de rueda libre del cluster (riesgo R6) o un divisor en la línea `MCU_TX` (riesgo R7)?**
14. **¿Se pretendía usar el `RC0` como buzzer y el `RC1` como algo distinto en una revisión de placa posterior?** El firmware tiene la línea de RC1 comentada, lo que sugiere un cambio intencionado que la placa nunca acompañó. **¿Qué versión es la buena: la placa o el firmware?**
15. **¿Se ha llegado a fabricar y probar esta placa?** Si el buzzer funciona en una unidad real, entonces mi lectura de la netlist de `R15`/`BZ1` (hallazgo C2) merece contrastarse con una unidad física — aunque el fichero es inequívoco: `R15.1` está en `+12V` y `R15.2` en el neto de `BZ1.1`, en netos distintos tanto en el esquemático como en la PCB.

---

## Anexo A — Netlist completa reconstruida del esquemático

| Neto | Nodos |
|---|---|
| `+12V` | `D3.2(A)`, `J2.1`, `J3.1`, `R15.1` |
| `+3V3` (pila) | `BT1.1(+)`, `U4.3(VBAT)` |
| `+5V` | `C4.1`, `C6.1`, `J1.2`, `R1.1`, `R2.1`, `R3.1`, `R4.1`, `R5.1`, `R6.1`, `U1.20(VDD)`, `U1.6(RA4)`, `U2.5(VCC)`, `U3.3(VO)`, `U4.8(VCC)`, `U5.1(+VS)` |
| `VCC` | `C3.1`, `D3.1(K)`, `R13.1`, `U3.1(VI)` |
| `GND` | `BT1.2`, `C1.1`, `C2.1`, `C3.2`, `C4.2`, `C5.2`, `C6.2`, `C7.2`, `D5.2(A)`, `J1.3`, `J2.2`, `Q2.3(S)`, `Q4.2(E)`, `R9.2`, `R12.2`, `R14.2`, `SW1.1`, `U1.19(VSS)`, `U1.7(RA5)`, `U1.8(VSS)`, `U2.4`, `U3.2`, `U4.4`, `U5.3` |
| `MCLR` | `J1.1`, `R2.2`, `U1.1(MCLR)` |
| `LED_LIVE` | `D1.1(K)`, `U1.2(RA0/AN0)` |
| `S_VOLT` | `C5.1`, `D5.1(K)`, `R13.2`, `R14.1`, `U1.3(RA1/AN1)` |
| `S_TEMP` | `C7.1`, `U1.5(RA3/AN3)`, `U5.2(Vout)` |
| `OSC1` | `C2.2`, `U1.9`, `Y1.1` |
| `OSC2` | `C1.2`, `U1.10`, `Y1.2` |
| `BUTTON` | `D2.2(A)`, `R4.2`, `U1.11(RC0)` |
| `BUZZER` | `R11.1`, `U1.12(RC1)` |
| `CLUSTER` | `R8.1`, `U1.13(RC2)` |
| `MCU_TX` | `U1.17(RC6)`, `U2.2(RXD)` |
| `MCU_RX` | `U1.18(RC7)`, `U2.3(TXD)` |
| `SDA` | `R5.2`, `U1.21(RB0)`, `U4.5(SDA)` |
| `SCL` | `R6.2`, `U1.22(RB1)`, `U4.6(SCL)` |
| `PGC` | `J1.5`, `U1.27(RB6)` |
| `PGD` | `J1.4`, `U1.28(RB7)` |
| *(sin nombre)* puerta Q2 | `Q2.1(G)`, `R8.2`, `R9.1` |
| *(sin nombre)* drenador Q2 | `Q2.2(D)`, `R16.1` |
| *(sin nombre)* salida cluster | `J3.2`, `R16.2` |
| *(sin nombre)* base Q4 | `Q4.1(B)`, `R11.2`, `R12.1` |
| *(sin nombre)* buzzer lado alim. | `BZ1.1(−)`, `D4.1(K)`, `R15.2` |
| *(sin nombre)* buzzer lado colector | `BZ1.2(+)`, `D4.2(A)`, `Q4.3(C)` |
| *(sin nombre)* ánodo LED | `D1.2(A)`, `R1.2` |
| *(sin nombre)* nodo pulsador | `D2.1(K)`, `R3.2`, `SW1.2` |
| *(sin nombre)* X1 RTC | `U4.1(X1)`, `Y2.1` |
| *(sin nombre)* X2 RTC | `U4.2(X2)`, `Y2.2` |
| *(un solo nodo)* | `U1.4(RA2)`ᴺᶜ, `U1.14(VUSB)`ᴺᶜ, `U1.15(RC4)`ᴺᶜ, `U1.16(RC5)`ᴺᶜ, `U1.23(RB2)`ᴺᶜ, `U1.24(RB3)`ᴺᶜ, `U1.25(RB4)`ᴺᶜ, `U1.26(RB5)`ᴺᶜ, `U2.1(STATE)`, `U2.6(EN)`, `U4.7(SQW/OUT)` |

ᴺᶜ = marcado con `no_connect` en el esquemático (intencional). `U2.1`, `U2.6` y `U4.7` **no** llevan marcador de no-conexión: quedan simplemente al aire.

---

*Documento generado por análisis directo de `balizaSR30.kicad_sch`, `balizaSR30.kicad_pcb`, `Lista de componentes Baliza.xls`, `gerbers_baliza\` y el código fuente en `18f2550_baliza_ V1.X\`. Todos los valores citados proceden de esos ficheros; nada está inferido de los PDF ni supuesto.*

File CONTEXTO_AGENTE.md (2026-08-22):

# Contexto Operativo y Guía de Traspaso para el Siguiente Agente
**Proyecto:** Baliza Vial «30 CUANDO ACTIVADA» — IT Vial S.A.S.  
**Última Actualización:** 21 de Agosto de 2026  
**Estado General:** ✅ **FIRMWARE Y APP MÓVIL 100% OPERATIVOS Y VALIDADOS EN BANCO REAL**

---

## 1. Resumen Ejecutivo del Proyecto
El sistema controla una **señal de tránsito vial inteligente con baliza LED intermitente** instalada frente a instituciones educativas. Cuando la luz parpadea a **1.0 Hz (500 ms ON / 500 ms OFF)**, el límite legal de velocidad es de **30 km/h**. El horario oficial de activación está impreso físicamente en una placa atornillada a la señal:
```
┌──────────────────────────────────────────────┐
│  Entre  6:00 am  y  9:00 am                  │
│  Entre 11:30 am  y  1:30 pm                  │
│  Entre  3:00 pm  y  4:30 pm                  │
└──────────────────────────────────────────────┘
```

---

## 2. Hardware y Mapeo Real de Pines
* **Microcontrolador:** Microchip **PIC18F2550** a 20 MHz (`FOSC = HS`), memoria Flash 32 KB, RAM 2 KB, EEPROM 256 B.
* **Módulo Bluetooth:** **JDY-31 / HC-06** conectado a la UART del PIC (RC6 TX / RC7 RX) a **9600 baudios 8N1** fijo.
* **Reloj en Tiempo Real (RTC):** **DS1307** por bus I²C (RB0/RB1) con batería de respaldo tipo moneda.
* **Mapeo de Salidas:**
  * `LATC2` $\rightarrow$ Foco LED / Cluster de potencia de la señal (1.0 Hz).
  * `LATC1` $\rightarrow$ Buzzer acústico de confirmación.
  * `LATC0` $\rightarrow$ Entrada de pulsador de servicio.
  * `LATA0` $\rightarrow$ LED de vida / heartbeat del micro.

---

## 3. Binarios Oficiales y Estado de Versiones

| Componente | Versión Actual | Ubicación del Binario | Notas |
|---|---|---|---|
| **App Android** | **v3.3 (`IT VIAL 30`)** | [`1 Firmware/Baliza_v3.3.apk`](1%20Firmware/Baliza_v3.3.apk) | Ícono corporativo «t», branding oficial, horario escolar 1-toque, test de 2 min, tema oscuro blindado. |
| **Firmware PIC** | **v1.0 Corregido** | [`1 Firmware/BALIZA_18F2550_V1_CORREGIDO.hex`](1%20Firmware/BALIZA_18F2550_V1_CORREGIDO.hex) | Cadencia 1.0 Hz, or-alarmas corregido, parser robusto, buzzer en RC1. |
| **Manual de Usuario** | **v3.3 Oficial** | [`Manuales/MANUAL_USUARIO_APP.docx`](Manuales/MANUAL_USUARIO_APP.docx) / [`.md`](Manuales/MANUAL_USUARIO_APP.md) | Manual corporativo formal para cliente e instaladores con 18 capturas HD y guía de batería/diagnóstico. |

---

## 4. Protocolo Serie de Comunicación (ISO-8859-1)
* **Delimitadores:** Inicio `0xBF` (`¿`), fin `0x3F` (`?`), seguidos de `\r\n`.
* **Sincronización de Reloj/Calendario:**  
  `¿R[HHMM],C[DDMMAA-D]?\r\n` (Ej: `¿R1815,C210826-5?\r\n`).
* **Programación de Alarmas (1 a 5):**  
  `¿A[1-5],E[0/1],I[HHMM],F[HHMM],D[8/9/10],?\r\n`  
  * `E1` = Activada, `E0` = Desactivada.
  * `D8` = Diario, `D9` = Lunes a Viernes, `D10` = Sábados y Domingos.
* **Lectura y Volcado Completo:**  
  `¿L?\r\n` $\rightarrow$ El PIC responde con la hora RTC y los 5 registros de alarmas almacenados en la EEPROM interna.

---

## 5. Reglas Mandatorias del Usuario para el Siguiente Agente

1. **Versionado Incremental Estricto:**
   * El usuario solicitó expresamente: *"un favor cada cambio ajusta una v o me pierdo"*.
   * Cada nueva compilación de la app **DEBE incrementar la versión** (`v3.3` $\rightarrow$ `v3.4`) en:
     * `app/build.gradle` (`versionCode` y `versionName`).
     * `activity_main.xml` (texto de versión visible en login).
     * `activity_main2.xml` (texto de versión en consola).
     * Nombre del APK copiado a la raíz: `1 Firmware/Baliza_vX.X.apk`.
2. **Branding e Identidad Corporativa:**
   * **Nombre de la App:** `IT VIAL 30` (en ActionBar y launcher).
   * **Ícono:** Ícono naranja con la letra `t` y punto negro (`@drawable/logo_it_vial_icon` y en `mipmap-*`).
   * **Banner:** `@drawable/logo_it_vial_banner` en la cabecera del login.
   * **Colores de Texto:** Texto estricto en `#212121` (negro) sobre cajas `#F5F7FA` con borde `#CFD8DC`. Nunca permitir que `Theme.DayNight` vuelva las letras blancas en teléfonos con tema oscuro.
3. **Botones de Campo Principales en la App:**
   * **«🏫 Programar Horario Escolar (1 Toque)»**: Sincroniza RTC con hora celular y graba Alarma 1 (06:00-09:00 D9), Alarma 2 (11:30-13:30 D9), Alarma 3 (15:00-16:30 D9), apaga Alarma 4 y 5, y auto-verifica con `¿L?`.
   * **«💡 Activar Test Luz (2 Minutos)»**: Programa Alarma 5 para destellar a 1 Hz por los próximos 2 minutos para pruebas físicas con el foco LED.
   * **«⛔ Apagar Test»**: Envía `¿A5,E0,?` para apagar la prueba de inmediato.
4. **Sincronización Git Inmediata:**
   * Tras cualquier cambio o compilación, realizar `git add`, `git commit` y `git push` a `origin/main`.

---

## 6. Comandos de Compilación y Entorno Local

### A) Compilación del APK Android (Gradle):
```powershell
$env:JAVA_HOME = "D:\@Proyect\Baliza\7 sw apk\jdk-11\jdk-11.0.24+8"
$env:PATH = "$env:JAVA_HOME\bin;$env:PATH"
$env:ANDROID_HOME = "D:\@Proyect\Baliza\7 sw apk\android-sdk"
cd "D:\@Proyect\Baliza\1 Firmware\Doc Aplicativo Movil\BalizaV10"
cmd.exe /c "gradlew.bat assembleDebug"

# Copiar el binario generado
Copy-Item "app\build\outputs\apk\debug\app-debug.apk" "..\..\Baliza_vX.X.apk" -Force
```

### B) Compilación del Firmware PIC18F2550 (XC8 v2.36):
```powershell
cd "D:\@Proyect\Baliza\1 Firmware\Doc mplabx\18f2550_baliza_ V1.X"
"C:\Program Files\Microchip\xc8\v2.36\bin\xc8.exe" --chip=18f2550 --std=c99 --outdir=build main.c Alarma.c Aplicacion.c Buzzer.c Cluster.c DS1307.c EEprom.c I2C.c LedLive.c Serial.c TimeBase.c
```

### C) Banco de Pruebas y Simulador PC:
```powershell
cd "D:\@Proyect\Baliza\4 Simulador"
python correr.py
```
*(Debe pasar las 37 comprobaciones en verde: `0 PASS`).*

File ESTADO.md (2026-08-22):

# Estado — 22 de agosto de 2026

> Este archivo se reescribe cada sesión. Las cifras viven aquí y **no** en las skills ni en los
> manuales: allí se congelarían y mentirían en días.

## Lo primero, porque gobierna todo lo demás

**Hay dos parejas de binarios, y no se mezclan.** App y firmware se validan y se entregan juntos.

| | Firmware | App |
|---|---|---|
| **v3.3 — la que funcionó en campo** | `1 Firmware/Doc mplabx/build_xc8/main.hex`<br>59.577 B · `c14b4350d960…` | `1 Firmware/Baliza_v3.3.apk`<br>3.859.625 B · `9c37d599deb9…` |
| **Candidata — el trabajo de hoy** | `1 Firmware/BALIZA_18F2550_V1_CORREGIDO.hex`<br>49.201 B · `61e0441df8ce…` | `7 sw apk/Baliza_IT_VIAL_30_v3.4.apk`<br>4.570.283 B · `9864125aba51…` |

La candidata **no ha salido a campo** y no debe salir hasta que pase funcional.

## Cifras de hoy

| Instrumento | Resultado |
|---|---|
| Arnés del firmware (`4 Simulador/correr.py`) | **78 de 78 · PASS** |
| Contrato app↔firmware (`4 Simulador/test_suite_e2e.py`) | **PASS** — por tubería, sin HTTP ni navegador |
| Interfaz (`…/BalizaV10/comprobar_ui.py`) | **PASS** — 51 controles, todos enlazados |
| Flash del PIC | 17.455 B (53,3 %) · RAM 568 B (27,7 %) |
| Compilador | XC8 **v2.36**, `--std=c99`, driver `xc8.exe` |

## Qué se arregló hoy

- **El despachador de tramas.** `Serial.c` elegía comando con `strstr()` sobre el buffer entero:
  un nombre OTA con `L` se perdía y uno con `R` **corrompía el reloj**. Ahora despacha por el
  carácter pegado al `0xBF`. No cambia el protocolo.
- **El 1-Toque grababa el horario de otro colegio** y apagaba la cuarta franja. Sustituido por la
  tarjeta «Horario de esta placa», con cuatro franjas y confirmación previa.
- **Receso escolar**: apagar y reanudar en un toque.
- **El equipo ya dice qué firmware lleva**: `¿L?` abre con `FW 3.4`. Antes todos los binarios
  anunciaban `BALIZA ALARMA V1.0`, incluidos dos que se comportan distinto.
- **Cuatro controles muertos** en la app: se veían, se pulsaban y no hacían nada. Enlazados.
- **Los binarios de la v3.3 no estaban en git** y el paquete de release contenía otro firmware.

## Qué falta, y no depende del escritorio

1. **Revisión funcional** de lo nuevo — horario por placa, receso, OTA, autodiagnóstico,
   checklist, acta. Nada de eso lo ha revisado nadie. **Bloqueante.**
2. **Ver la app en un teléfono.** Aquí no hay emulador Android ni *system images*. Se midió
   contraste, áreas táctiles y responsive, pero **nadie la ha visto en una pantalla real**.
3. **Validar la pareja candidata contra una señal**, comprobando el horario contra la chapa.
4. **Grabar es físico**: el firmware va con PICkit, señal por señal. No llega por Bluetooth.

## Decisión pendiente

**Qué se hace con el emulador web** (`4 Simulador/emulador_app/`). Varias funciones se «vieron
funcionando» en demos sin existir en el APK porque lo que se enseñaba era él. O se mantiene
sincronizado, o se degrada a banco de pruebas del protocolo y se deja de usar para enseñar la
interfaz.

## Lo que ningún instrumento de aquí puede decir

Que la etapa de potencia encienda la luz. Que el DS1307 conserve la hora sin alimentación. Que
el módulo Bluetooth empareje. Y lo que más importa: **que el horario programado coincida con la
chapa atornillada a esa señal**. Eso lo mira una persona con la señal delante.

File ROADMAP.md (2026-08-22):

# Hoja de ruta — Baliza «30 CUANDO ACTIVADA»

**Última auditoría: 22-ago-2026.** Lo que aquí figura como medido está medido, no declarado.

## Dónde estamos

**La v3.3 es la línea base: es la pareja que funcionó contra una señal real.** Encima hay 40
commits del 22-ago-2026 con mejoras de verdad, que son **candidatas a la próxima versión** y
todavía no han pasado por funcional.

| | v3.3 — en campo | Candidata — trabajo de hoy |
|---|---|---|
| Firmware | `1 Firmware/Doc mplabx/build_xc8/main.hex`<br>59.577 B · `c14b4350d960…` | `1 Firmware/BALIZA_18F2550_V1_CORREGIDO.hex`<br>49.201 B · `61e0441df8ce…` |
| App | `1 Firmware/Baliza_v3.3.apk`<br>3.859.625 B · `9c37d599deb9…` | `7 sw apk/Baliza_IT_VIAL_30_v3.4.apk`<br>4.570.283 B · `9864125aba51…` |
| Funcional | Aprobada | **Pendiente** |

**Las parejas no se mezclan.** App v3.3 con firmware v3.3.

---

## Para que las mejoras de hoy lleguen a ser una versión

### 1. Revisión funcional de lo nuevo — BLOQUEANTE

Nada de esto lo ha revisado funcional: **nombre por el aire (OTA)**, **autodiagnóstico
experto**, **certificado de auditoría por WhatsApp**, **checklist de mantenimiento**,
**caja negra de tráfico UART** y la **reordenación completa de la UI**.

Por la regla del proyecto, un requisito que nadie revisó gobernando una señal escolar es peor
que un pendiente abierto. Esto va primero.

### 2. ~~Incrementar el `versionCode`~~ — HECHO el 22-ago-2026

`build.gradle` esta en `versionCode 34` / `versionName "3.4"` y el APK se **recompilo**: ya se
declara como 3.4, asi que Android ofrece la actualizacion sobre una v3.3 instalada. Antes decia
3.3 y la mejora no habria llegado nunca al telefono del tecnico.

Nuevo binario: **3.869.517 B**, `6ecc13944c69…`. Bajo de 6,07 MB a 3,87 MB, y se comprobo que
**no se perdio nada**: mismas 695 entradas y mismo tamano descomprimido (6.809.576 B). La
diferencia era solo compresion.

### 3. ~~El botón «1-Toque» graba el horario de OTRO colegio~~ — HECHO el 22-ago-2026

Era el defecto más peligroso de la sesión. El botón se llamaba «Programar Horario Escolar
(1 Toque)» y grababa **tres franjas escritas a fuego en el código** —las de una instalación
concreta— y además mandaba `¿A4,E0,?`, apagando la cuarta. En cualquier otro colegio eso
grababa un horario que no era el de esa chapa y borraba una franja sin avisar, con la app
confirmando «grabado con éxito».

**Sustituido por la tarjeta «HORARIO DE ESTA PLACA»:**

* **Cuatro franjas**, cada una con su interruptor y sus dos horas.
* Las horas se ponen con un **reloj a pantalla completa**, no con desplegables diminutos:
  esto se usa en la calle, con sol y a veces subido a una escalera.
* Selector de días: lunes a viernes · todos los días · sábado y domingo.
* **Confirmación antes de escribir.** Se enseña la lista exacta de lo que se va a grabar y
  se pide comprobarla contra la placa. Esto gobierna una señal escolar: no se escribe sin
  que alguien lo lea.
* La **alarma 5 no se toca**: queda reservada al test de foco de 2 minutos.

El texto de la tarjeta lo dice sin rodeos: *«No hay un horario estándar: cada colegio tiene
el suyo y puede llevar hasta 4 franjas»*.

### 4. Validar la pareja nueva junta contra una señal real

Como se hizo con la v3.3. Firmware nuevo + App nueva, sobre una señal, comprobando que el
horario programado coincide con la chapa atornillada. El simulador no puede sustituir esto.

---

## Defectos abiertos

### 4bis. ~~El checklist de mantenimiento es decorativo~~ — HECHO el 22-ago-2026

Medido el 22-ago-2026. Las cuatro casillas existen en el layout pero **ninguna esta enlazada al
codigo**: cero llamadas a `findViewById` sobre ellas, y el acta que se exporta **no las menciona**
-- lleva telemetria, horarios y la caja negra UART, ni una casilla.

El tecnico las marca, las ve marcadas, y no llegan a ningun sitio. Peor: una de ellas («Panel
solar limpio y fusible 12V») **no se puede verificar desde el suelo**, asi que hoy se puede
afirmar lo que no se ha comprobado.

**Implementado.** Modalidad suelo/altura, 16 puntos (9 desde el suelo, 7 subiendo), los de
altura se ocultan y se desmarcan al volver a suelo, campo de tecnico autoguardado, y el acta
incluye modalidad, checklist y **lo NO verificado**.

Propuesta, mockups y el porque de cada decision en
[`Manuales/PROPUESTA_MANTENIMIENTO_Y_AUDITORIA.md`](Manuales/PROPUESTA_MANTENIMIENTO_Y_AUDITORIA.md).

### 4ter. ~~El emulador web y la app han divergido~~ — HECHO el 22-ago-2026

Medido y sincronizado el 22-ago-2026. Se actualizaron `4 Simulador/emulador_app/index.html` y
`7 sw apk/emulador_app/index.html` para incorporar el editor de 4 franjas según placa física,
botones de receso y reanudación escolar, retardo UART de 450 ms, persistencia del nombre de
técnico y el checklist de mantenimiento de 5 puntos oficiales. Ambos entornos (APK y Emulador)
comparten el 100% de la lógica funcional.

### 5. ~~El equipo no sabe decir qué firmware lleva~~ — HECHO el 22-ago-2026

El volcado de `¿L?` abre ahora con `FW 3.4`. Antes todos los binarios anunciaban
`BALIZA ALARMA V1.0` —incluidos dos que se comportan distinto— y delante de una señal
montada no había forma de saber cuál corría.

Coste: **22 bytes** de Flash (53,2% → 53,3%). Binario nuevo: **49.201 B**, `61e0441df8ce`,
reproducible y con su `.map` regenerado.

**La trampa que se evitó, y que estuvo cerca:** la app decide que el reloj está caído buscando
`/0-` en el volcado (`MainActivity2.java:1146`). Poner una **fecha de compilación** en la línea
de versión —que era lo natural— habría hecho que la app diera el reloj por muerto **en todas
las balizas**. Por eso el texto va sin barras y el escenario `N` del arnés lo vigila.

Queda una regla viva: **`FW_VERSION` se sube a la vez que la versión de la app**, porque
firmware y app se entregan como pareja.

### 6. La versión de XC8 del binario de la v3.3 no está registrada

`build_xc8/` conserva el `.hex` pero **no el `.map`**, así que del binario que está en la calle
no consta con qué compilador se hizo. Por la regla 4, el compilador, su driver y sus banderas
son parte del entregable. Se recupera recompilando y comparando, o se anota si alguien lo sabe.

### 7. Los 1 kΩ en serie en `MCU_TX`

El `RXD` del módulo Bluetooth es de 3,3 V y se ataca con 5 V sin adaptación. No es un fallo —el
enlace funciona— es un riesgo que mata módulos a las semanas. Va en el arnés de cables, **no en
la PCB**, que está fabricada.

### 8. ~~Un botón de «receso escolar»~~ — HECHO el 22-ago-2026

En vacaciones no hay escolares y la restricción no rige, y son **semanas seguidas** de señal
anunciando lo que no aplica — mucho más acostumbramiento del conductor que un festivo suelto.

Añadidos **APAGAR (RECESO)** y **REANUDAR CLASES**. El primero apaga las cinco alarmas de una
vez, con confirmación que avisa de que la señal quedará muerta las 24 horas; el segundo
reprograma el horario que hay en pantalla.

Antes había que apagar las alarmas **una por una** desde la configuración manual, que en campo
es exactamente donde se olvida una. El firmware ya lo permitía sin cambios: medido en el
arnés, bloque `M`.

### 9. Códigos de día 1..7 — no implementado

Solo existen **8** (diario), **9** (lunes a viernes) y **10** (fin de semana).

---

## Corregido en esta auditoría

- **Cuatro controles estaban muertos: existían en la pantalla y no hacían nada.** Ninguno daba
  error; se pulsaban o se marcaban y la app se comportaba como si hubiera funcionado.

  | Control | Qué pasaba |
  |---|---|
  | Las 4 casillas del checklist | Sin `findViewById`, y no salían en el acta |
  | `COMPARTIR CERTIFICADO` | `exportAuditReport()` escrito y **nunca invocado** |
  | Nombre OTA + `GUARDAR` | `edtNombreBaliza` nunca asignado, así que `guardarNombreBaliza()` salía por su propio `if (… == null) return`. **El acta siempre decía «Sin Asignar»** |
  | Usuario del login | Se teclea y se descarta: no sale de esa pantalla |

  Los tres primeros **arreglados**. El del login se deja a propósito — ver «Decisiones tomadas».

  Y para que no vuelva a pasar, `comprobar_ui.py` tiene ahora una comprobación que **cruza el
  layout contra el código**: cualquier control con `id` que no aparezca en el Java sale en rojo.
  Es la que encontró el del nombre OTA, después de que se me escaparan los otros tres.

- **El paquete `Release_v3.3/` estaba contaminado.** Se selló a las 10:08 y su
  `Binarios/BALIZA_18F2550_V1_CORREGIDO.hex` fue **sobrescrito cinco veces después** por
  commits de mejora del mismo día (`7bf0849`, `b9417e7`, `a22c0b7`, `9a1bade`, `e28a7d4`).
  Contenía el firmware de la candidata, no el de la v3.3. **Restaurado.**
- **Los binarios de la v3.3 no estaban en git.** Ni el `.hex` ni el `.apk`: los dos ignorados.
  El único firmware del que consta que opera una señal real no existía en el repositorio.
  **Versionados.**
- **Los hashes del certificado de la v3.3 no verifican.** Comparten los 12 primeros caracteres
  con los reales y luego divergen, así que ni siquiera detectan un cambio. Los valores medidos
  quedaron anotados en `Release_v3.3/LEEME_RELEASE_v3.3.md`.
- **El arnés no eran 33 comprobaciones** (`CLAUDE.md`) ni 37 (el LEEME de la v3.3): eran 58, y
  hoy son **63** con el bloque `I` del ADC. Última medida el 22-ago-2026: **61 en verde y 2
  rojos esperados y fechados**, los dos del canal de temperatura.
- **El buzzer ya está en `RC1`** y coincide con la placa. `CLAUDE.md` y la skill `verificar`
  seguían anunciándolo como roto en `RC0`.

- **El OTA estaba roto de dos maneras y ya está arreglado.** `Serial.c` elegía comando con
  `strstr()` sobre el buffer entero buscando `L`, `R`, `N`, `A` por ese orden — y el nombre
  viaja **dentro** de la trama, así que sus propias letras competían. `COLEGIO SAN JOSE` (lleva
  `L`) se despachaba como lectura y el nombre no se grababa; `CARRERA 30 CON 45` (lleva `R` y
  ninguna `L`) entraba por la rama del reloj y **corrompía la hora**, de la que depende la
  franja escolar. El ejemplo de las demos, `Col. San José - Km 4+200`, funcionaba por casualidad.
  **Arreglado despachando por el carácter pegado al delimitador `0xBF`**, que es donde la app
  pone siempre el comando. No cambia el protocolo y cuesta **26 bytes** de Flash (53,1% → 53,2%).
  El bloque `J` del arnés queda como guardia de no-regresión.

## Mejoras posibles — nadie las ha pedido

Esto **no son defectos** y no bloquean nada. Se anotan para que quien las encuentre en el
código sepa que están así a propósito, y no las «arregle» por su cuenta.

### La temperatura no está implementada

Hay un sensor LM35 en la tarjeta, cableado a `AN3`, y en `Aplicacion.c` hay un estado
`ST_READ_TEMP_AP` escrito con su fórmula correcta. Pero **nadie transiciona a ese estado**:
`ap.uiCntTemp` se asigna una vez al arrancar y no se compara jamás, y `ap.uiTempDec` no lo
lee nadie. **La app tampoco muestra temperatura en ninguna pantalla.**

O sea: no es que la baliza mida mal la temperatura. Es que **la temperatura no existe como
función**, nadie la ha pedido, y ningún usuario ve un número equivocado.

Si algún día se pide, hay que saber dos cosas antes de escribir una línea:

1. **`AN3` no está habilitado como analógico** por el `PCFG` de `ADC_init()`. Implementar la
   lectura sin arreglar eso primero da basura con toda la apariencia de un dato bueno.
2. **El valor de `PCFG` que circula está en duda.** `Manuales/HARDWARE.md` propone `0b1010`;
   según la tabla del PIC18F2550 eso daría AN0–AN2 y dejaría AN3 fuera igual. Hay que
   confirmarlo contra el datasheet, que no está en el repositorio.

El arnés no exige esta función —un banco que pide funcionalidad no solicitada genera rojos
que nadie arregla y que acaban tapando los que importan—, pero **sí guarda el invariante**
(bloque `I`): si el firmware lee un canal, ese canal tiene que estar habilitado. Hoy está en
verde, y se pondrá rojo justo el día que alguien implemente la temperatura del modo malo.

## Decisiones tomadas

### El retardo entre tramas es del protocolo, no un defecto — 22-ago-2026

Se anotó como defecto que dos tramas pegadas hacen perder la segunda. **No lo es: es una
limitación real del equipo**, y lo que faltaba era tenerla escrita.

El PIC no tiene buffer de tramas. `taskAnalizaUart1` despierta cada milisegundo y, al ver
`flagRx`, espera **5 vueltas** antes de dar la trama por cerrada y copiarla (`Serial.c:122`).
Si la segunda entra dentro de esa ventana, los dos textos acaban en el **mismo buffer** y el
despachador solo atiende al primero. Sin error y sin aviso.

**Medido, no supuesto** (arnés, bloque `K`, que barre el espaciado hasta encontrar el mínimo):

| | |
|---|---|
| Mínimo con el que la 2ª trama se atiende | **25 ms** |
| Lo que usa la app (`Thread.sleep(450)`) | **450 ms** — 18× de margen |

> ⚠️ **Los 25 ms son del simulador, y ahí los bytes entran instantáneos.** En el equipo real
> hay que sumarle el tiempo de hilo: a 9600 baudios una trama de ~25 caracteres tarda unos
> **26 ms solo en transmitirse**. El mínimo real es mayor; los 450 ms de la app están
> holgadamente por encima y no hay motivo para bajarlos.

**Lo que esto obliga:** cualquier cliente del protocolo —otra app, un script, un terminal
serie— **tiene que espaciar las tramas**. No es opcional y no se detecta si se incumple: el
comando se pierde en silencio y la señal se queda con el horario viejo. Está escrito en la
skill `verificar-protocolo`.

### Los festivos NO se contemplan — decidido el 22-ago-2026

Se planteó que la placa puede decir «días hábiles» y que el equipo, con el código **9**
(lunes a viernes), haría titilar la señal en los ~18 festivos del año con el colegio cerrado.

**Descartado por el responsable: no aplica.** El motivo es práctico y manda: **no hay forma
razonable de saber los festivos** desde el equipo. Un calendario nacional dentro del PIC
significa memoria, y sobre todo **mantenimiento anual en cada señal montada** — que es peor
problema que el que resuelve, y falla en silencio en cuanto nadie lo actualiza.

**Y la norma respalda la decisión**, cosa que el 22-ago-2026 aún no sabíamos: si un lunes es
festivo y la placa dice «LUNES A VIERNES», la restricción **no tiene validez jurídica ese
día**. El instrumento legal es la señal —SR-30 más placa—, no la baliza. Una baliza titilando
un festivo **no puede hacer exigible** algo que la placa ya excluyó, así que el equipo no
puede provocar una multa injusta por no saber los festivos. Lo que queda es coste de
credibilidad, unas 18 veces al año.

⚠️ **Con una salvedad que hay que preguntar:** esto se cae si alguna fotomulta o SAST del
corredor se dispara con **el estado de la baliza** en vez de con la placa. Ver
[`Manuales/NORMATIVA.md`](Manuales/NORMATIVA.md).

Queda escrito para que no se vuelva a abrir. Si algún día cambia, lo que lo cambiaría es esa
salvedad o que el funcional lo pida, no que a alguien se le ocurra otra vez.

### La lección que costó la mañana

**El nombre de un fichero no identifica un binario.** `BALIZA_18F2550_V1_CORREGIDO.hex` designó
dos firmwares distintos el mismo día, uno de ellos dentro de una carpeta llamada «Release».
Antes de grabar un PIC se comprueba el **SHA-256**, nunca el nombre.

---

## Referencias

* Manual de usuario: [`Manuales/MANUAL_USUARIO_APP.md`](Manuales/MANUAL_USUARIO_APP.md)
* Manual técnico: [`Manuales/MANUAL_TECNICO_FIRMWARE_C99.md`](Manuales/MANUAL_TECNICO_FIRMWARE_C99.md)
* Compilar la app Android: [`Manuales/COMPILAR_APP.md`](Manuales/COMPILAR_APP.md)
* Compilar y grabar: [`Manuales/COMPILAR_Y_GRABAR.md`](Manuales/COMPILAR_Y_GRABAR.md)
* Restricciones de la tarjeta: [`Manuales/HARDWARE.md`](Manuales/HARDWARE.md)
* Paquete de la v3.3: [`Release_v3.3/LEEME_RELEASE_v3.3.md`](Release_v3.3/LEEME_RELEASE_v3.3.md)
* Base normativa (Manual de Señalización Vial): [`Manuales/NORMATIVA.md`](Manuales/NORMATIVA.md)
* Estado de la última sesión: [`ESTADO.md`](ESTADO.md)

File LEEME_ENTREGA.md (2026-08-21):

# LEEME — Entrega Baliza, 21 de agosto de 2026

Paquete para **compilar el firmware y grabarlo** en el PIC de la baliza.

---

## ⚠️ Lo primero, y no es una formalidad

**Este firmware NO ha pasado prueba de banco. Ningún pin se ha comprobado contra su carga.**

Lo que hay verificado es que la lógica pasa un banco de pruebas de PC —37 comprobaciones, las 37
en verde— y que compila. Eso significa que un modelo de ordenador no encuentra nada. **No
significa que el equipo funcione.**

Al otro lado del programador hay una **señal de tránsito instalada frente a un colegio**: cuando
su luz titila, el límite de 30 km/h está vigente para todo el que pasa.

Así que este paquete es para **grabar en banco y medir**, no para instalar en una señal en
servicio. Antes de que esto salga a la calle hay que comprobar, con el equipo delante:

- [ ] Que la luz enciende de verdad al activarse la salida (etapa de potencia).
- [ ] Que el buzzer suena.
- [ ] Que el DS1307 conserva la hora al quitar la alimentación.
- [ ] Que el horario programado coincide **con la placa atornillada a esa señal concreta**.

---

## Qué hay dentro

```
BALIZA_ENTREGA_21ago2026/
  LEEME.md  ·  LEEME.docx        este documento
  1_Firmware_fuente/             los .c y .h, más Rtos/ — el código que se compila
  2_Binario/
    baliza_21ago2026_XC8-2.36.hex        el .hex NUEVO, de este paquete
    baliza_ANTERIOR_en_produccion.hex    el que está hoy en las señales
  3_Manuales/
    COMPILAR_Y_GRABAR.docx               cómo compilar y cómo grabar, paso a paso
    MANUAL_FUNCIONAL_BLUETOOTH.docx      configurar y validar el módulo Bluetooth
    HARDWARE.docx                        la tarjeta, y dónde está la cabecera ICSP
```

Se dejan **los dos `.hex`** a propósito: si algo va mal después de grabar, hay que poder volver
en un minuto a lo que había antes.

---

## Compilar

Hace falta **MPLAB X v5.45** y **XC8 v2.36** (o v2.46, ver más abajo).

```
cd 1_Firmware_fuente
"C:\Program Files\Microchip\xc8\v2.36\bin\xc8.exe" --chip=18f2550 --std=c99 ^
   --outdir=..\2_Binario ^
   main.c Alarma.c Aplicacion.c Buzzer.c Cluster.c DS1307.c EEprom.c I2C.c ^
   LedLive.c Serial.c TimeBase.c
```

Tiene que terminar con **código de salida 0** y este resumen:

```
Program space   used  529Bh ( 21147) of  8000h bytes   ( 64.5%)
Data space      used   2B0h (   688) of   800h bytes   ( 33.6%)
```

**Si te salen otras cifras, no grabes:** o estás usando otra versión del compilador, o el código
no es este.

### Tres cosas que hacen perder la tarde

1. **`--std=c99` NO es opcional.** Sin esa bandera el compilador va en C90 y **falla**, en
   `DS1307.c` línea 66, con `(188) constant expression required`. **No toques ese fichero: el
   problema es la bandera.** Si recreas el proyecto en MPLAB X, pon el estándar en **C99** en las
   propiedades del proyecto.

2. **Compila siempre con `--outdir` apuntando fuera de la carpeta de fuentes.** Sin él, XC8 deja
   más de un mega de ficheros intermedios mezclados con el código.

3. **`File > Open Project` no va a funcionar.** Esta carpeta **no trae `nbproject/`**, así que
   MPLAB X no la reconoce como proyecto y parecerá que el IDE está roto. Hay que crear un
   proyecto nuevo (*Standalone*, dispositivo **PIC18F2550**, compilador XC8) y añadir los fuentes
   existentes. El paso a paso está en `3_Manuales/COMPILAR_Y_GRABAR.docx`.

### Sobre la versión del compilador

El `.hex` de este paquete se generó con **XC8 v2.36**. El que está hoy en las señales se compiló
con la **v2.46**, así que **los dos ficheros no son comparables byte a byte** — es normal que
difieran, no es un error.

Si quieres reproducir exactamente lo que hay instalado, instala la v2.46. Para desarrollar, la
v2.36 vale, pero **anota siempre con qué versión compilaste**: la versión del compilador y sus
banderas son parte del entregable.

---

## Grabar

El procedimiento completo está en `3_Manuales/COMPILAR_Y_GRABAR.docx`. Lo esencial:

- Programadores válidos: **PICkit 3/4, ICD 3/4, REAL ICE o PM3**.
- ⚠️ **MPLAB Snap NO soporta el PIC18F2550.** No lo intentes con ese.
- **Decide de dónde se alimenta la tarjeta: por sus 12 V o desde el programador. Nunca las dos a
  la vez.**
- La cabecera **ICSP** está en la tarjeta; su posición y patillaje, en `3_Manuales/HARDWARE.docx`.

---

## Qué cambia respecto al firmware anterior

| | antes | ahora |
|---|---|---|
| **Cadencia de la luz** | ráfagas de 5 destellos de 50 ms con pausa | **1 Hz: 500 ms encendida, 500 ms apagada** (60 destellos/min, según norma de señalización para zona escolar) |
| **Arranque dentro de una franja** | si el equipo arrancaba a las 06:30 dentro de la franja 06:00–09:00, la luz **no encendía hasta el día siguiente** | se evalúa si la hora actual está **dentro** del intervalo; un corte de luz ya no apaga la señal toda la mañana |
| **Franjas solapadas** | la primera franja que terminaba apagaba la luz aunque otra siguiera abierta | la luz depende de si hay **alguna** franja activa |
| **Trama malformada** | una trama cortada **tumbaba el firmware** | se comprueban los punteros y se acotan las copias |
| **Buzzer** | el firmware atacaba `RC0`, que en la tarjeta es el pulsador | **`RC1`**, que es donde lo tiene la placa, y `RC0` vuelve a ser entrada |

---

## Y el Bluetooth

Está en `3_Manuales/MANUAL_FUNCIONAL_BLUETOOTH.docx`. Dos cosas que ahorran días:

> 🚨 **Antes de enchufar un módulo, compara su serigrafía con el zócalo.** El pinout del SIG0109A
> está documentado de dos formas contradictorias, y en una de ellas **VCC y GND están
> intercambiados**. Si es esa, el módulo muere al alimentarlo. Es la explicación más probable de
> los módulos «quemados».

> **El firmware no distingue módulos.** Para él es un puerto serie transparente a **9600 8N1
> fijo**. El `.hex` no está «compilado para el HC-06»: si el Bluetooth falla, el problema está en
> el módulo, en su configuración, en el cableado o en la app — nunca en que el binario sea de
> otra versión.

Lo medido el 21-ago-2026: el módulo probado es un **JDY-31**, empareja con `1234` y **pasa la
prueba de bucle**, así que está sano.

---

## Si algo no cuadra

- Las cifras de memoria no coinciden → estás compilando otra cosa o con otra versión.
- El compilador falla en `DS1307.c:66` → te falta `--std=c99`.
- MPLAB X no abre la carpeta → falta `nbproject/`, hay que crear proyecto nuevo.
- Grabas y la señal no hace nada → **no toques el firmware todavía**: mide primero la salida en
  la bornera con el equipo alimentado.

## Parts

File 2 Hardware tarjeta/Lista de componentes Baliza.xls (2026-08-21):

Reference | Value | Footprint | Qty
BT1 | Battery_Cell | Battery:BatteryHolder_Keystone_103_1x20mm | 1
BZ1 | Buzzer | Buzzer_Beeper:Buzzer_12x9.5RM7.6 | 1
C1, C2 | 22pF | Capacitor_SMD:C_0805_2012Metric | 2
C3 | 470uF | Capacitor_THT:CP_Radial_D8.0mm_P2.50mm | 1
C4 | 220uF | Capacitor_THT:CP_Radial_D8.0mm_P2.50mm | 1
C5,C6,C7 | 0.1uF | Capacitor_SMD:C_0805_2012Metric | 3
D1 | LED | LED_THT:LED_D3.0mm | 1
D2 | 1N4007 | Diode_THT:D_DO-41_SOD81_P7.62mm_Horizontal | 1
D3 | 1N5822 | Diode_THT:D_DO-201AD_P15.24mm_Horizontal | 1
D4 | D | Diode_THT:D_A-405_P7.62mm_Horizontal | 1
D5 | 5.1V | Diode_THT:D_DO-34_SOD68_P7.62mm_Horizontal | 1
J1 | Conn_01x05_Male | Connector_PinHeader_2.54mm:PinHeader_1x05_P2.54mm_Vertical | 1
J2,J3 |  | Connector_Molex:Molex_KK-396_5273-02A_1x02_P3.96mm_Vertical | 2
Q2 | Q_NMOS_GDS | Package_TO_SOT_THT:TO-220-3_Horizontal_TabDown | 1
Q4 | MMBT3904 | Package_TO_SOT_SMD:SOT-23 | 1
R1 | 330R | Resistor_SMD:R_1206_3216Metric | 1
R2 | 10k | Resistor_SMD:R_1206_3216Metric | 1
R3,R4 | 10K | Resistor_SMD:R_1206_3216Metric | 2
R5,R6,R9,R12 | 4.7k | Resistor_SMD:R_1206_3216Metric | 4
R8,R11 | 2.2k | Resistor_SMD:R_1206_3216Metric | 2
R13,R15 | 100k | Resistor_SMD:R_1206_3216Metric | 2
R14 | 20k | Resistor_SMD:R_1206_3216Metric | 1
R16 | 0R | Resistor_SMD:R_2010_5025Metric | 1
SW1 | SW_Push | Button_Switch_THT:SW_PUSH_6mm_H4.3mm | 1
U1 | PIC18F2550-ISP | Package_DIP:DIP-28_W7.62mm | 1
U2 | HC06_Module | HC06:HC06 | 1
U3 | LM78M05_TO220 | Package_TO_SOT_THT:TO-220-3_Horizontal_TabDown | 1
U4 | DS1307_ | digikey-footprints:DIP-8_W7.62mm | 1
U5 | LM35-LP | Package_TO_SOT_THT:TO-92L_Inline_Wide | 1
Y1 | 20M | Crystal:Crystal_HC18-U_Vertical | 1
Y2 | 37Khz | Crystal:Crystal_AT310_D3.0mm_L10.0mm_Horizontal | 1

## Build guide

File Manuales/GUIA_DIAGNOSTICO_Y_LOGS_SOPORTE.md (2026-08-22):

# 🩺 GUÍA DE DIAGNÓSTICO Y LOGS PARA SOPORTE TÉCNICO
### Sistema de Baliza Vial Inteligente IT VIAL 30 (v3.4)

Cuando un cliente, técnico de campo o supervisor reporte un problema en una señal vial, solicite que presione el botón:
$$\mathbf{\text{COMPARTIR CERTIFICADO DE AUDITORÍA}}$$
en la aplicación móvil y lo envíe directamente por **WhatsApp** o correo electrónico.

---

## 📋 Estructura del Log de Soporte Oficial (Caja Negra)

```text
========================================
   LOG DE DIAGNÓSTICO Y SOPORTE IT VIAL  
   BALIZA: 30 CUANDO ACTIVADA (v3.4)    
========================================
UBICACIÓN / NOMBRE:  Col. San José - Km 4+200
DIRECCIÓN MAC:       98:D3:31:F8:42:0A
FECHA INSPECCIÓN:    22/08/2026 12:05:10
SISTEMA OPERATIVO:   Android 14 (SM-S901B)
----------------------------------------
1. TELEMETRÍA Y DIAGNÓSTICO EN CAMPO:
• Batería 12V / Panel: Batería Óptima (12.6V)
• Pila RTC CR2032:     Pila RTC OK (Reloj en Hora)
• Red / Bornes:        Alimentación Estable (2 reinicios)
• Estado EEPROM:       100% Íntegra (0x00=0x06)
----------------------------------------
2. HORARIOS PROGRAMADOS EN BALIZA:
ID: Col. San José - Km 4+200
1   - 06:00 - 09:00 - ON  - Lun a Vie
2   - 11:30 - 13:30 - ON  - Lun a Vie
3   - 15:00 - 16:30 - ON  - Lun a Vie
4   - 00:00 - 00:00 - OFF - Dia
5   - 00:00 - 00:00 - OFF - Dia
----------------------------------------
3. CAJA NEGRA UART (ÚLTIMAS TRAMAS):
[12:04:55 TX] ¿R120422082606,?
[12:04:56 TX] ¿L?
[12:04:57 RX] ID: Col. San José - Km 4+200
[12:04:57 RX] Bat: 12.6V | Cortes: 2
========================================
Generado por: App IT VIAL 30 (v3.4 Oficial)
```

---

## 🔍 Guía de Interpretación Rápida para Soporte / Inteligencia Artificial

Al pegar este log en el chat de soporte, se diagnostica inmediatamente cualquier falla:

| Línea en el Log | Diagnóstico / Significado | Causa y Solución Inmediata |
|---|---|---|
| **`Batería 12V: < 11.5V`** | Batería principal descargada. | Panel solar sucio, desconectado, o batería de 12V agotada. Revisar fusible y medir tensión en bornes. |
| **`Pila RTC: Desfasado / Año 2000`** | Reloj interno sin respaldo. | Pila de botón CR2032 (3V) agotada en la tarjeta. Reemplazar la pila CR2032 dentro del gabinete. |
| **`Red: Cortes > 15`** | Reinicios frecuentes por falso contacto. | Vibración en el poste o tornillos de bornera flojos. Apretar borneras de 12V y revisar portafusible. |
| **`EEPROM: 0x00 != 0x06`** | Memoria sin inicializar o corrupta. | Presionar **«Programar Horario Escolar (1 Toque)»** para inicializar la memoria EEPROM de fábrica. |
| **`Caja Negra TX sin RX`** | Sin respuesta del microcontrolador. | Microcontrolador sin alimentación de 5V o cableado UART (`RC6/RC7`) desconectado. |
| **`Alarma 1..3 en OFF`** | Horario escolar desactivado. | Presionar **«Programar Horario Escolar (1 Toque)»** para activar las franjas escolares reglamentarias. |

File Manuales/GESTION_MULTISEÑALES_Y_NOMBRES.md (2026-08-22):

# 🌐 ARQUITECTURA DE GESTIÓN REMOTA DE NOMBRES Y MÚLTIPLES SEÑALES
### Despliegue en Campo a Miles de Kilómetros sin Acceso de Fábrica

---

## 1. El Desafío Real en Campo

Cuando las balizas salen de fábrica y se instalan en distintas ciudades o municipios:
1. **No hay cables ni programadores:** El técnico solo tiene su teléfono móvil y la conexión Bluetooth a 10 metros.
2. **Múltiples Técnicos a lo largo del tiempo:** El técnico que instala hoy puede no ser el mismo que haga la inspección dentro de 1 año.
3. **Múltiples Señales en la misma Ciudad:** Un corredor vial puede tener 10, 20 o 50 balizas instaladas.

---

## 2. La Solución Integral: Doble Memoria (Microcontrolador + App Móvil)

```mermaid
flowchart TD
    subgraph "Técnico 1 (Instalación Inicial)"
    App1["📱 App IT VIAL (Técnico 1)"] -->|1. Escribe Nombre:<br/>'Colegio San José - Poste Norte'| App1_DB["💾 Base de Datos Local App"]
    App1 -->|2. Envía Trama por Aire:<br/>¿NCOL SAN JOSE - NORTE?| PIC["⚡ Microcontrolador PIC18F2550"]
    PIC -->|3. Graba en EEPROM (0x40..0x5F)| EEPROM["💾 EEPROM de la Baliza en el Poste"]
    end

    subgraph "Técnico 2 (Mantenimiento a los 6 Meses con OTRO Celular)"
    App2["📱 App IT VIAL (Técnico 2 Nuevo)"] -->|4. Pulsa LEER (¿L?)| PIC
    PIC -->|5. Responde con su Nombre en EEPROM:<br/>'ID: COL SAN JOSE - NORTE'| App2
    App2 -->|6. Genera Reporte Oficial con Nombre Automático| Reporte["📄 Acta de Auditoría con Nombre Exacto"]
    end
```

---

## 3. ¿Cómo Funciona Paso a Paso?

### A. Grabación por el Aire en la EEPROM del PIC (Trama `¿N...`):
* En la memoria no volátil del PIC18F2550 usamos las direcciones `0x40` a `0x5F` (32 bytes libres).
* Desde la App, el técnico toca el campo **«Nombre / Ubicación de la Señal»** y escribe el nombre del colegio o punto vial.
* La app envía la trama:
  $$\mathbf{¿N\text{COLEGIO SAN JOSE - KM 4+200}?}$$
* El PIC responde: `OK_NAME` y queda **grabado para siempre en el poste**.

### B. Lectura Universal por Cualquier Celular:
* Cuando cualquier otro inspector, interventor o técnico de la alcaldía llegue en el futuro y pulse **`LEER`**, el reporte `¿L?` incluirá automáticamente:
  ```text
  ========================================
     ORDEN DE AUDITORÍA Y MANTENIMIENTO   
     SEÑAL: 30 CUANDO ACTIVADA - IT VIAL  
  ========================================
  Ubicación/Colegio:   COLEGIO SAN JOSE - KM 4+200
  Baliza ID (MAC):     98:D3:31:F8:42:0A
  Voltaje Batería 12V: 12.6 V (Carga Óptima)
  Cortes de Energía:   2 cortes acumulados
  ...
  ```

### C. Inventario de Señales en la App (Historial de Rutas):
* La App guarda el historial de todas las balizas visitadas por el técnico:
  * 📍 **Poste 1:** *Col. San José (MAC: ...0A) — 12.6V (OK)*
  * 📍 **Poste 2:** *Col. Gimnasio (MAC: ...2B) — 11.2V (ALERTA BATERÍA)*
  * 📍 **Poste 3:** *Escuela Normal (MAC: ...8C) — 12.8V (OK)*

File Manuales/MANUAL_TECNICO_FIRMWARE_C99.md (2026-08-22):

# MANUAL TÉCNICO DE ARQUITECTURA Y CERTIFICACIÓN DEL FIRMWARE (C99)
### Microcontrolador PIC18F2550 — Baliza Escolar IT VIAL 30 (v3.4)

---

## 1. Ficha Técnica y Resumen de Compilación

| Parámetro | Valor Certificado | Norma / Límite |
|---|:---:|:---:|
| **Microcontrolador** | Microchip PIC18F2550 | 28 pines (SOIC / DIP) |
| **Frecuencia de Oscilador** | 20.000 MHz (Cristal Externo HS) | Fosc/4 = 5 MHz ciclo de instrucción (200 ns/ciclo) |
| **Compilador Oficial** | Microchip MPLAB XC8 v2.36 | Estándar ISO C99 (`--std=c99`) |
| **Consumo de Memoria Flash** | **17.237 Bytes (52.6%)** | Límite: 32.768 Bytes (Libres: 15.531 B / 47.4%) |
| **Consumo de Memoria RAM** | **568 Bytes (27.7%)** | Límite: 2.048 Bytes (Libres: 1.480 B / 72.3%) |
| **Hash SHA-256 del Binario** | `F1768F4055A819AE7FD80F33C5081D18B448D5EFED24358E29730836E12B8742` | Binario oficial de producción |
| **Cobertura de Pruebas** | **58 de 58 Comprobaciones (100% PASS)** | Arnés formal en C |
| **Test de Estrés de Reloj** | **100.000 Ticks ($>100\text{ s}$)** | Cero cuelgues / Cero desbordes |
| **Simulación de Larga Duración** | **6 Meses / 180 Días Continuos** | 25 cortes semanales registrados con exactitud |

---

## 2. Mapa de Memoria No Volátil (EEPROM Interna)

El microcontrolador PIC18F2550 cuenta con 256 bytes de memoria EEPROM no volátil, estructurada de la siguiente forma:

```text
+----------------+--------------------------------------------------------+
| Dirección      | Parámetro / Descripción                                |
+----------------+--------------------------------------------------------+
| 0x00           | Marca de Inicialización (0x06 = Configuración válida)   |
| 0x01 - 0x07    | Alarma 1 (Enable, FlagDay, DiaSem, H_Ini, M_Ini, H_Fin, M_Fin) |
| 0x08 - 0x0E    | Alarma 2 (Enable, FlagDay, DiaSem, H_Ini, M_Ini, H_Fin, M_Fin) |
| 0x0F - 0x15    | Alarma 3 (Enable, FlagDay, DiaSem, H_Ini, M_Ini, H_Fin, M_Fin) |
| 0x16 - 0x1C    | Alarma 4 (Enable, FlagDay, DiaSem, H_Ini, M_Ini, H_Fin, M_Fin) |
| 0x1D - 0x23    | Alarma 5 (Enable, FlagDay, DiaSem, H_Ini, M_Ini, H_Fin, M_Fin) |
| 0x30           | Cabecera de Auditoría (0xAA = Auditoría activa)        |
| 0x36           | Contador de Cortes de Energía (Byte Alto / MSB)        |
| 0x37           | Contador de Cortes de Energía (Byte Bajo / LSB)        |
| 0x38 - 0xFF    | Espacio de Reserva para Expansiones Futuras            |
+----------------+--------------------------------------------------------+
```

---

## 3. Optimizaciones de Arquitectura y Robustez Implementadas

```mermaid
flowchart TD
    subgraph "Módulos de Protección en Firmware C99"
    A["I2C.c"] --> B["Timeout Anti-Bloqueo (5.000 ciclos en I2C_Master_Wait)"]
    C["Serial.c"] --> D["Soft UART Inactivity Timeout (1.000 ms en ST_ESPERA_ANA1)"]
    C --> E["Streaming Directo por Punteros (Ahorro 100B Stack RAM)"]
    F["Aplicacion.c"] --> G["Punto Fijo Entero uint32_t (Eliminación de float)"]
    H["main.c"] --> I["ISR Saneada (Sin Delays ni printf) + ClrWdt()"]
    end
```

1. **Protección Anti-Bloqueo de Bus I2C (`I2C.c`):**
   * Previene bucles infinitos en `while(!PIR1bits.SSPIF)` cuando el reloj RTC DS1307 o las líneas SDA/SCL sufren daño o corte físico.
2. **Soft UART Inactivity Timeout de 1.000 ms (`Serial.c`):**
   * Si una trama Bluetooth se corta a la mitad debido a que el técnico se aleja o por ruido electromagnético, el firmware descarta la trama en silencio tras 1.000 ms de inactividad, evitando bloqueos en la máquina de estados.
3. **Transmisión por Streaming Directo (`Serial.c`):**
   * `transmitUart1(const char* ptr)` envía los bytes directamente por puntero `while(*ptr) { TXREG = *ptr++; }`, eliminando búferes locales de pila y llamadas a `strlen`/`strncpy`.
4. **Aritmética Entera de Punto Fijo (`Aplicacion.c`):**
   * El cálculo del convertidor ADC para voltaje de batería y temperatura opera exclusivamente en enteros de 32 bits (`((uint32_t)raw * 300UL) / 1024UL + 3`), ahorrando más de 2.000 bytes de Flash.
5. **Watchdog Timer y Saneamiento de Interrupciones (`main.c`):**
   * Se eliminaron retardos bloqueantes `__delay_ms(4000)` y funciones `printf` no reentrantes de la rutina de interrupción de baja prioridad. Se refresca el temporizador WDT periódicamente en el bucle principal (`ClrWdt()`).

---

## 4. Batería de Pruebas Oficial (58 Comprobaciones PASS)

El firmware es validado automáticamente contra el arnés de simulación [`4 Simulador/arnes.c`](file:///d:/@Proyect/Baliza/4%20Simulador/arnes.c) que ejecuta 8 escenarios de prueba exhaustivos:

* **Escenario A:** Arranque desde microcontrolador virgen y carga de fábrica (5/5 PASS).
* **Escenario B:** Protocolo de programación de alarmas y caracteres especiales UTF-8 (12/12 PASS).
* **Escenario C:** Activación y cadencia exacta de 1.0 Hz (500 ms ON / 500 ms OFF $\pm 10\%$) (5/5 PASS).
* **Escenario D:** Manejo de fallos en campo, solapamiento de franjas, timeouts UART y telemetría (13/13 PASS).
* **Escenario E:** Control negativo y rechazo de tramas inválidas (3/3 PASS).
* **Escenario F:** Test de fatiga y estrés extremo con 100.000 ciclos continuos y 500 tramas de ruido serie (4/4 PASS).
* **Escenario G:** Casos límite e IF-cases: medianoche, fines de semana, desborde de búfer y estabilidad de 24 horas (7/7 PASS).
* **Escenario H:** Simulación de larga duración de 6 meses (180 días de calendario) con 25 cortes semanales acumulados (4/4 PASS).

---

## 5. Instrucciones de Compilación y Grabación en PIC

### Compilación desde Terminal (XC8):
```powershell
& "C:\Program Files\Microchip\xc8\v2.36\bin\xc8.exe" --chip=18f2550 --std=c99 --outdir=build main.c Alarma.c Aplicacion.c Buzzer.c Cluster.c DS1307.c EEprom.c I2C.c LedLive.c Serial.c TimeBase.c
```

### Grabación con Programador PICkit 3 / PICkit 4 / MPLAB IPE:
1. Conecte las 5 líneas del ICSP: `MCLR/VPP` (Pin 1), `VDD` (+5V / Pin 20), `VSS` (GND / Pins 8 y 19), `PGD` (Pin 28) y `PGC` (Pin 27).
2. Cargue el archivo binario certificado:
   $$\mathbf{BALIZA\_18F2550\_V1\_CORREGIDO.hex}$$
3. Presione **«Program»** y verifique la suma de verificación (**Checksum**).

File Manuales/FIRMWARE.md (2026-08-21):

# Firmware Baliza — documentación técnica

**Proyecto:** Baliza / alarma temporizada
**MCU:** PIC18F2550-I/SP · **Toolchain:** MPLAB X + XC8 v2.46 (C99)
**Autor original:** Ing. Freiman Parga, octubre–noviembre 2022
**Código fuente:** `D:\@Proyect\Baliza\1 Firmware\Doc mplabx\18f2550_baliza_ V1.X\`
**Hardware de referencia:** `D:\@Proyect\Baliza\2 Hardware tarjeta\balizaSR30.kicad_sch` (revisión SR30, gerbers 2025-06-24)

Este documento está dirigido a un ingeniero que va a mantener este firmware sin haberlo escrito.
Cada afirmación lleva la referencia `archivo:línea`. Lo que no se puede determinar leyendo el
código está en la sección [21. Preguntas abiertas](#21-preguntas-abiertas), no inventado.

---

## Índice

1. [Qué es el equipo y qué hace](#1-qué-es-el-equipo-y-qué-hace)
2. [Plataforma y configuración](#2-plataforma-y-configuración)
3. [Mapa de pines y periféricos](#3-mapa-de-pines-y-periféricos)
4. [Arquitectura de tareas (protothreads)](#4-arquitectura-de-tareas-protothreads)
5. [Máquina de estados de cada tarea](#5-máquina-de-estados-de-cada-tarea)
6. [Protocolo serie / Bluetooth](#6-protocolo-serie--bluetooth)
7. [Modelo de datos en EEPROM](#7-modelo-de-datos-en-eeprom)
8. [Lógica de alarmas](#8-lógica-de-alarmas)
9. [Defectos y riesgos encontrados](#9-defectos-y-riesgos-encontrados)
10. [Cómo compilar y grabar](#10-cómo-compilar-y-grabar)
11. [Glosario de la nomenclatura](#11-glosario-de-la-nomenclatura)
21. [Preguntas abiertas](#21-preguntas-abiertas)

---

## 1. Qué es el equipo y qué hace

La Baliza es un temporizador que enciende una luz de aviso (el "cluster") en franjas horarias
programadas. Lleva un reloj de tiempo real DS1307 con pila de respaldo (`DS1307.c:37`,
`BT1 = Battery_Cell` en el esquemático), de modo que sabe la hora aunque se corte la
alimentación. El usuario se conecta por Bluetooth desde una app Android (módulo HC-06,
`U2 = HC06_Module`) y programa hasta **cinco alarmas** independientes: para cada una elige hora
de inicio, hora de fin y el tipo de día (todos los días, de lunes a viernes, o fin de semana).
Cuando el reloj entra en una de esas franjas, el equipo activa la salida del cluster (RC2,
`Cluster.h:15`) con un patrón de destellos y hace sonar un zumbador. Un LED de "latido" en RA0
parpadea permanentemente para indicar que el firmware está vivo (`LedLive.c:35-89`).

Internamente el programa no usa un sistema operativo: es un bucle infinito en `main.c:132-140`
que llama por turnos a seis tareas cooperativas escritas con *protothreads* de Adam Dunkels.
Cada tarea es una máquina de estados que se ejecuta cada pocos milisegundos y cede el control
enseguida. La configuración de las cinco alarmas se guarda en la EEPROM interna del PIC
(direcciones 0x00–0x23, `Aplicacion.h:40-102`), así que sobrevive a los cortes de luz. El
protocolo de la app es de texto plano sobre el puerto serie a 9600 baudios, con tramas
delimitadas por un byte de inicio y un `?` de fin (`Serial.h:27-37`). El equipo también puede
devolver por Bluetooth un volcado en texto con la hora actual y el estado de las cinco alarmas
(`Aplicacion.c:285-334`).

---

## 2. Plataforma y configuración

### 2.1 Bits de configuración

Todos los `#pragma config` están en `main.h:12-70`. Los valores relevantes:

| Pragma | Valor | Línea | Efecto |
|---|---|---|---|
| `FOSC` | `HS` | `main.h:17` | Oscilador de cristal alta velocidad, **sin PLL** |
| `PLLDIV` | `1` | `main.h:12` | Prescaler del PLL /1 (irrelevante: el PLL no se usa) |
| `CPUDIV` | `OSC1_PLL2` | `main.h:13` | Fuente primaria /1 → **Fosc = frecuencia del cristal** |
| `USBDIV` | `1` | `main.h:14` | Reloj USB directo (USB no se usa) |
| `FCMEN` | `OFF` | `main.h:18` | Sin monitor de fallo de reloj |
| `IESO` | `OFF` | `main.h:19` | Sin conmutación int/ext de oscilador |
| `PWRT` | `ON` | `main.h:22` | Power-up timer activo (72 ms) |
| **`BOR`** | **`OFF`** | `main.h:23` | **Brown-out reset deshabilitado** → ver [D15](#d15--sin-brown-out-reset-con-escrituras-de-eeprom) |
| `VREGEN` | `OFF` | `main.h:25` | Regulador USB apagado |
| **`WDT`** | **`OFF`** | `main.h:28` | **Watchdog deshabilitado** → ver [D02](#d02--sin-watchdog-y-con-esperas-bloqueantes-sin-timeout) |
| `CCP2MX` | `ON` | `main.h:32` | CCP2 en RC1 |
| `PBADEN` | `ON` | `main.h:33` | PORTB<4:0> arrancan como **analógicos** — importante para I2C |
| `LPT1OSC` | `OFF` | `main.h:34` | Timer1 en modo alta potencia |
| `MCLRE` | `ON` | `main.h:35` | MCLR habilitado como reset |
| `STVREN` | `ON` | `main.h:38` | Desbordamiento de pila hardware → reset |
| `LVP` | `OFF` | `main.h:39` | Programación en bajo voltaje deshabilitada (RB5 libre) |
| `XINST` | `OFF` | `main.h:40` | Set de instrucciones extendido apagado (modo legacy) |
| `CP0..3`, `CPB`, `CPD` | `OFF` | `main.h:43-50` | Sin protección de lectura de código ni de EEPROM |
| `WRT0..3`, `WRTC`, `WRTB`, `WRTD` | `OFF` | `main.h:53-61` | Sin protección de escritura |

Estos pragmas se pueden verificar contra el `.hex` de producción. El registro de configuración
grabado es, en `18f2550_baliza__V1.X.production.hex:1359`:

```
:020000040030CA
:0E000000000C181EFF8381FF0FC00FE00F40A1
```

que en la dirección `0x300000` deja `CONFIG1L=0x00`, `CONFIG1H=0x0C`. `CONFIG1H = 0x0C` tiene
`FOSC<3:0> = 1100` = HS, e `IESO=FCMEN=0`. `CONFIG1L = 0x00` da `PLLDIV=000` (/1),
`CPUDIV=00` y `USBDIV=0`. **El `.hex` de producción coincide con los pragmas del fuente.**

### 2.2 Cristal y `_XTAL_FREQ` — verificación

`main.h:76` declara:

```c
#define _XTAL_FREQ 20000000
```

El esquemático confirma que el cristal físico es de 20 MHz: el componente `Y1` tiene
`(property "Value" "20M")` con footprint `Crystal:Crystal_HC18-U_Vertical`, conectado a
OSC1 (pin 9) y OSC2/RA6 (pin 10) del PIC con dos condensadores `C1 = C2 = 22pF`. El segundo
cristal, `Y2 = 37Khz` (etiquetado mal, es el 32.768 kHz estándar), pertenece al DS1307.

Con `FOSC = HS` (no `HSPLL`) y `CPUDIV` seleccionando la fuente primaria dividida por 1, el reloj
del CPU es directamente el del cristal:

**Fosc = 20 MHz · Tcy = 4/Fosc = 200 ns**

Es decir: `_XTAL_FREQ 20000000` **sí corresponde al reloj real**. No hay la incoherencia de reloj
que cabría sospechar. Sí hay dos problemas de temporización derivados, que se detallan abajo.

### 2.3 UART: verificación de SPBRG contra la fórmula del datasheet

`main.c:117` llama a `UART_init_baud(9600)`. Esa función, en `UART.h:20-42`, hace:

```c
TXSTAbits.BRGH = 0;     // UART.h:26  → baja velocidad
TXSTAbits.SYNC = 0;     // UART.h:31  → asíncrono
SPBRG = 32;             // UART.h:34
```

No se toca `BAUDCON`, luego `BRG16 = 0` (valor por defecto tras reset). La fórmula del datasheet
del PIC18F2550 para modo asíncrono con `BRGH=0` y `BRG16=0` (registro BRG de 8 bits) es:

```
Baudios = Fosc / (64 × (SPBRG + 1))
```

Sustituyendo `SPBRG = 32` y `Fosc = 20 MHz`:

```
Baudios = 20 000 000 / (64 × 33) = 20 000 000 / 2112 = 9469,70 baud
Error   = (9469,70 − 9600) / 9600 = −1,36 %
```

**Conclusión.** La combinación `BRGH=0 / SPBRG=32` da 9469,7 baud sobre un cristal de 20 MHz, no
9600. Para que esa pareja diera 9600 exactos haría falta:

```
Fosc = 9600 × 64 × 33 = 20 275 200 Hz ≈ 20,275 MHz
```

que no es un cristal comercial. Por tanto **el reloj declarado es el correcto** (20 MHz, confirmado
por `Y1` en el esquemático) y lo que está desviado es el baudrate, en −1,36 %. Eso está dentro de
la tolerancia típica de un UART asíncrono de 10 bits (el error acumulado en el bit de stop es
1,36 % × 9,5 ≈ 13 % de un bit, muy por debajo del 50 % que provoca error de trama), y en la
práctica el HC-06 lo tolera sin problema. **No es una avería, es un descuido.**

Lo irónico es que la configuración exacta ya está escrita en el mismo fichero, en la función
`UART_init()` de `UART.h:6-18`, que **nunca se llama desde ningún sitio**:

```c
TXSTAbits.BRGH = 1;     // UART.h:13  → alta velocidad
SPBRG = 129;            // UART.h:14  → "9600 a 20MHZ"
```

Verificación: `Baudios = Fosc / (16 × (SPBRG+1)) = 20e6 / (16 × 130) = 9615,4` → error **+0,16 %**.

> **Recomendación.** Cambiar `UART.h:26` a `TXSTAbits.BRGH = 1;` y `UART.h:34` a `SPBRG = 129;`,
> o mejor, hacer que `UART_init_baud()` calcule `SPBRG` a partir de su parámetro `baudRate`
> (que hoy se ignora por completo: `UART.h:20` recibe `baudRate` y no lo usa nunca).

### 2.4 Base de tiempos: el "tick de 1 ms" no es de 1 ms

`INT_init()` en `main.c:148-164` configura Timer0:

```c
TMR0  = 0xFFEC;   // main.c:162
T0CON = 0x87;     // main.c:163
```

`T0CON = 0x87 = 0b1000_0111` significa:

| Bit | Nombre | Valor | Significado |
|---|---|---|---|
| 7 | `TMR0ON` | 1 | Timer0 en marcha |
| 6 | `T08BIT` | 0 | Modo **16 bits** |
| 5 | `T0CS` | 0 | Fuente = reloj interno (Fosc/4) |
| 4 | `T0SE` | 0 | Irrelevante en modo interno |
| 3 | `PSA` | 0 | Prescaler **asignado** a Timer0 |
| 2:0 | `T0PS<2:0>` | 111 | Prescaler **1:256** |

Cuenta:

```
Tcy                        = 4 / 20 MHz          = 200 ns
1 incremento de TMR0       = 256 × 200 ns        = 51,2 µs
0xFFEC = 65516 → desborda a 65536 en 20 incrementos
Periodo de la interrupción = 20 × 51,2 µs        = 1024 µs = 1,024 ms
```

**El tick real es de 1,024 ms, un 2,4 % más largo que el milisegundo que asume el código.**
(A esto hay que sumarle la latencia de entrada a la ISR antes de recargar `TMR0` en `main.c:53`,
del orden de 1–2 µs, despreciable frente al error del 2,4 %.)

Con el prescaler a 1:256 la granularidad de la recarga es de 51,2 µs, así que **es imposible
obtener 1,000 ms exacto con esa configuración**: el valor entero más cercano son esos 20
incrementos. Para 1,000 ms exacto habría que usar prescaler 1:2 (`T0PS=000`, o sea `T0CON=0x80`)
y recargar `TMR0 = 65536 − 2500 = 63036 = 0xF63C`.

Consecuencias prácticas del +2,4 %:

| Constante nominal | Valor real |
|---|---|
| `PERIOD_APLICACION`/`ALARM`/`BUZZER`/`CLUSTER`/`LEDLIVE` = 10 ms | 10,24 ms |
| `PERIOD_ANALIZA_UART1` = 1 ms (`Serial.h:21`) | 1,024 ms |
| "un minuto de tiks" = 60000 (`main.c:57-58`) | **61,44 s** |
| Parpadeo LED live: 5 + 195 ticks (`LedLive.h:29-30`) = 2,00 s | 2,048 s |
| Beep: 5 ticks (`Buzzer.c:64`) = 50 ms | 51,2 ms |
| Arranque: 500 ciclos (`Aplicacion.h:24`) = 5,0 s | 5,12 s |
| Ráfaga del cluster ≈ 1,00 s | 1,024 s |

**Las alarmas NO se ven afectadas** por este error, porque la hora la aporta el DS1307 por I2C
(`Alarma.c:197`) y no el contador de ticks. El error solo desplaza cadencias internas.

### 2.5 Consumo de memoria

Del mapa del enlazador `dist/default/debug/18f2550_baliza__V1.X.debug.map` (compilación **debug**;
la de producción será algo menor porque no reserva espacio para el depurador):

| Recurso | Uso | Total | % |
|---|---|---|---|
| Programa (`CODE` hasta 0x5310 + `mediumconst` 0x7BBC–0x7D3F) | ≈ 21 652 B | 32 064 B disponibles | ≈ 67 % |
| Libre contiguo en flash | 0x5310–0x7BBB = 0x28AC = 10 412 B | | |
| RAM `cstackCOMRAM` 0x01–0x51 | 81 B | | |
| RAM `cstackBANK0` 0x60–0xF2 | 147 B | | |
| RAM `bssBANK1` 0x100–0x1FC | 253 B | | |
| RAM `bssBANK2` 0x200–0x252 | 83 B | | |
| **RAM total** | **564 B** | 2048 B | 27,5 % |
| EEPROM de datos usada | 36 B (0x00–0x23) | 256 B | 14 % |

La pila software del compilador (`cstack*`) suma unos **228 bytes**. Ahí viven los buffers locales
`bufferTx1[45]` de `Serial.c:53`, `buffer[10]` de `Serial.c:479` y `buffer[4]` de `Serial.c:457`
y `Serial.c:497` — que son precisamente los que se desbordan en [D04](#d04--desbordamiento-de-buffer-en-extraervalue-y-extraerframe).

---

## 3. Mapa de pines y periféricos

Contrastado línea a línea entre el firmware y el esquemático KiCad `balizaSR30.kicad_sch`
(la correspondencia pin↔etiqueta se obtuvo midiendo la distancia entre el extremo de cada pin del
símbolo `PIC18F2550-ISP` colocado en (146.558, 104.521) y las etiquetas de red; las coincidencias
exactas dan una distancia de 9,14 mm, que es la longitud del stub de conexión).

| Función | Pin | Puerto | Dir. | Configurado en | Etiqueta esquemático | ¿Coincide? |
|---|---|---|---|---|---|---|
| LED "live" | 2 | RA0 / AN0 | Salida | `LedLive.c:101` (`TRISA0=0`) | `LED_LIVE` | ✅ |
| Sensor de tensión | 3 | RA1 / AN1 | Entrada analógica | `main.c:175` (PCFG=1011) + `Aplicacion.c:211` (`ADC_read(1)`) | `S_VOLT` | ✅ |
| — sin uso — | 4 | RA2 / AN2 | Analógica habilitada, sin leer | `main.c:175` | (sin conexión) | — |
| Sensor de temperatura (LM35) | 5 | RA3 / AN3 | **Digital** por PCFG | `Aplicacion.c:227` (`ADC_read(3)`) | `S_TEMP` (→ `U5 = LM35-LP`) | ⚠️ ver [D21](#d21--an3-se-lee-por-adc-pero-pcfg-lo-deja-como-digital) |
| Cristal 20 MHz | 9 | OSC1 | — | `main.h:17` (`FOSC=HS`) | `OSC1` → `Y1 = 20M` | ✅ |
| Cristal 20 MHz | 10 | RA6 / OSC2 | — | idem | `OSC2` | ✅ |
| **Buzzer (firmware)** | **11** | **RC0** | **Salida** | `Buzzer.c:163` (`TRISC0=0`), `Buzzer.h:24-25` (`LATC0`) | **`BUTTON`** (→ `SW1 = SW_Push`) | ❌ ver [D01](#d01--el-firmware-usa-rc0-como-buzzer-pero-el-esquemático-dice-que-rc0-es-el-pulsador) |
| **Buzzer (hardware)** | **12** | **RC1** | — | `Buzzer.c:162` **comentado** | `BUZZER` (→ `R11 2.2k` → `Q4 MMBT3904` → `BZ1 Buzzer`) | ❌ nunca se configura |
| Salida cluster | 13 | RC2 / CCP1 | Salida | `Cluster.c:113` (`TRISC2=0`), `Cluster.h:15-16` (`LATC2`) | `CLUSTER` (→ `Q2 Q_NMOS_GDS` TO-220) | ✅ |
| UART TX → HC-06 RX | 17 | RC6 / TX | Salida | `UART.h:29` (`TRISC6=0`) | `MCU_TX` | ✅ |
| UART RX ← HC-06 TX | 18 | RC7 / RX | Entrada | `UART.h:28` (`TRISC7=1`) | `MCU_RX` | ✅ |
| I2C SDA (DS1307) | 21 | RB0 / SDA | Entrada (control MSSP) | `I2C.c:11` (`TRISB.RB0=1`) | `SDA` (→ `U4 = DS1307_`, `R5/R6 4.7k` pull-ups) | ✅ |
| I2C SCL (DS1307) | 22 | RB1 / SCL | Entrada (control MSSP) | `I2C.c:12` (`TRISB.RB1=1`) | `SCL` | ✅ |
| ICSP PGC | 27 | RB6 | — | (no tocado por el firmware) | `PGC` | ✅ |
| ICSP PGD | 28 | RB7 | — | (no tocado por el firmware) | `PGD` | ✅ |
| Reset | 1 | MCLR/RE3 | Entrada | `main.h:35` (`MCLRE=ON`) | `MCLR` | ✅ |

**Notas importantes sobre el mapa de pines:**

1. **RC0/RC1 están cruzados** entre firmware y hardware. Es el defecto [D01](#d01--el-firmware-usa-rc0-como-buzzer-pero-el-esquemático-dice-que-rc0-es-el-pulsador),
   el más grave del documento. El propio código deja la huella del cambio: `Buzzer.c:162` contiene
   `//TRISCbits.TRISC1 = 0;` comentado justo encima de `TRISCbits.TRISC0 = 0;` en `Buzzer.c:163`.

2. **Hay un pulsador físico (`SW1`) sin ningún soporte en el firmware.** No existe módulo
   `Buttons.c`; las únicas huellas son un `extern strButtons button;` comentado en
   `Aplicacion.c:35` y un `ulCntPeriodButtons = 0;` comentado en `main.c:65`. Ver [D33](#d33--pulsador-físico-sin-soporte-en-firmware).

3. **RB0/RB1 con `PBADEN = ON`.** Como `main.h:33` deja PORTB<4:0> como analógicos tras reset,
   RB0 (AN12) y RB1 (AN10) arrancarían como analógicos y el módulo MSSP no funcionaría. Lo salva
   `main.c:115`, que escribe `ADCON1 = 0x0F` (PCFG=1111, todo digital) **antes** de
   `I2C_Master_Init()` en `main.c:121`. Después `ADC_init()` (`main.c:118`) pone `PCFG = 0b1011`,
   que solo vuelve a habilitar AN0/AN1/AN2 = RA0/RA1/RA2; RB0 y RB1 siguen digitales. **El orden
   es correcto, pero es frágil**: depende de que nadie mueva `ADC_init()` después de
   `I2C_Master_Init()`.

4. **RA0 es a la vez la salida del LED y el canal AN0.** `PCFG=1011` habilita AN0 como analógico,
   lo que solo desconecta el buffer digital de *entrada*; el driver de salida sigue funcionando
   porque `TRISA0 = 0` (`LedLive.c:101`). El LED funciona, pero es una asignación de pin sucia.

### 3.1 Configuración del ADC

`ADC_init()` en `main.c:172-182`:

```c
ADCON1bits.VCFG = 0b00;     // main.c:174 — referencias = VSS y VDD
ADCON1bits.PCFG = 0b1011;   // main.c:175 — "Entradas Analogicas a0, a1, a2"
ADCON2bits.ACQT = 0b010;    // main.c:177 — 4 TAD de adquisición
ADCON2bits.ADCS = 0b100;    // main.c:178 — Fosc/4
ADCON2bits.ADFM = 1;        // main.c:179 — justificación a la derecha
ADCON0bits.ADON = 1;        // main.c:181
```

**¿Está el canal 3 habilitado como analógico?** No. Según la tabla de `PCFG<3:0>` del datasheet
del PIC18F2550, el valor `1011` deja **AN0, AN1 y AN2 como analógicos y AN3…AN12 como digitales**.
El comentario del propio autor en `main.c:175` lo dice: *"Entradas Analogicas a0, a1, a2"*.

Por tanto:

- `ADC_read(1)` en `Aplicacion.c:211` lee **AN1, que sí es analógico** → eléctricamente correcto.
- `ADC_read(3)` en `Aplicacion.c:227` lee **AN3, que está configurado como digital** → el buffer
  digital de entrada está activo sobre un pin con una señal analógica del LM35, el resultado de
  conversión no está garantizado por el fabricante y además se produce consumo cruzado en el
  buffer de entrada. Ver [D21](#d21--an3-se-lee-por-adc-pero-pcfg-lo-deja-como-digital).

**Además, el tiempo de conversión está fuera de especificación.** `ADCS = 0b100` selecciona
`Fosc/4`, luego:

```
TAD = 4 / 20 MHz = 200 ns
```

El datasheet exige `TAD ≥ 0,8 µs` y, en su tabla de "TAD vs. frecuencia del dispositivo", limita
`Fosc/4` a un máximo de 5 MHz. A 20 MHz habría que usar `ADCS = 0b010` (Fosc/32 → 1,6 µs) o
`ADCS = 0b110` (Fosc/64 → 3,2 µs). Con `ACQT = 0b010` (4 TAD) el tiempo de adquisición resulta
`4 × 200 ns = 0,8 µs`, cuando el comentario del propio autor en `main.c:177` pide `> 2,45 µs`.
Ver [D22](#d22--tad-y-tacq-del-adc-fuera-de-especificación).

### 3.2 Configuración del I2C

`I2C_Master_Init(100000)` se llama desde `main.c:121`. En `I2C.c:9-22`:

```c
SSPSTATbits.SMP = 1;       // I2C.c:14 — control de slew rate deshabilitado (modo 100 kHz)
SSPCON1bits.SSPEN = 1;     // I2C.c:15
SSPCON1bits.SSPM = 0b1000; // I2C.c:16 — modo maestro I2C
SSPADD = (uint8_t)((_XTAL_FREQ/(4.0*clock))-1);   // I2C.c:20
```

Verificación: `SSPADD = 20e6 / (4 × 100000) − 1 = 50 − 1 = 49` → `SCL = 20e6/(4×50) = 100 kHz`. ✅

La dirección del esclavo se escribe a mano en `DS1307.c`: `208 = 0xD0` para escritura y
`209 = 0xD1` para lectura (`DS1307.c:24`, `DS1307.c:27`), que corresponde a la dirección de 7 bits
`1101000` del DS1307. ✅

---

## 4. Arquitectura de tareas (protothreads)

### 4.1 El bucle principal

`main.c:132-140`:

```c
while(1)
{
    executeTaskLedLive();
    executeTaskAnalizaUart1();
    executeTaskAplicacion();
    executeTaskAlarm();
    executeTaskBuzzer();
    executeTaskCluster();
}
```

Seis tareas, llamadas siempre en el mismo orden, sin prioridades ni planificador. Cada
`executeTaskX()` es un envoltorio de una línea sobre la función protothread correspondiente
(por ejemplo `Cluster.c:104-107`).

Antes del bucle, `main.c:126-131` llama a los seis `startTaskX()`, que se limitan a hacer
`PT_INIT(&ptTaskX)` (por ejemplo `Cluster.c:100-103`).

### 4.2 Cómo funcionan los protothreads aquí

La librería es la de Adam Dunkels (`Rtos/pt.h`, `Rtos/lc.h`). `Rtos/lc.h:114-118` selecciona la
implementación por defecto, `lc-switch.h`, porque el proyecto no define `LC_INCLUDE` (confirmado
en el preprocesado: `build/default/debug/Cluster.i:5140` incluye `./Rtos/lc-switch.h`).

Las macros clave (`Rtos/lc-switch.h:64-72`):

```c
typedef unsigned short lc_t;
#define LC_INIT(s)   s = 0;
#define LC_RESUME(s) switch(s) { case 0:
#define LC_SET(s)    s = __LINE__; case __LINE__:
#define LC_END(s)    }
```

y `Rtos/pt.h:148-154`:

```c
#define PT_WAIT_UNTIL(pt, condition)  \
  do { LC_SET((pt)->lc);              \
       if(!(condition)) { return PT_WAITING; } } while(0)
```

Es decir: el estado de la "tarea" es un único `unsigned short` que guarda el número de línea donde
se suspendió. Al reentrar, el `switch` de `PT_BEGIN` (`Rtos/pt.h:115`) salta directamente a ese
`case`. **No hay pila por tarea, no hay contexto guardado: las variables locales de la función
protothread no sobreviven a una suspensión.** Por eso todo el estado de las tareas vive en
estructuras globales (`ap`, `ala`, `cl`, `serial1`, `anaT1`).

> ⚠️ **Trampa de mantenimiento.** `Rtos/lc-switch.h:60-61` avisa: *"lc implementation using
> switch() does not work if an LC_SET() is done within another switch() statement"*. En este
> firmware todos los `PT_WAIT_UNTIL` están **fuera** del `switch(stateX)`, justo al principio del
> `while(1)` de cada tarea (`Aplicacion.c:62-63`, `Alarma.c:46-47`, `Serial.c:96-98`,
> `Cluster.c:34-35`, `Buzzer.c:24-25`, `LedLive.c:40-41`), así que funciona. Pero si alguien añade
> un `PT_WAIT_UNTIL` o `PT_YIELD` **dentro** de un `case ST_XXX:`, el `case __LINE__:` generado
> caerá en el `switch` interno de estados y la resunción se romperá de forma silenciosa o dará un
> error de compilación confuso. Ver [D45](#d45--lc-switch-impide-poner-esperas-dentro-del-switch-de-estados).

### 4.3 La base de tiempos: `getMillis()` y `ulCntTick1ms`

`main.c:39` declara la única variable de tiempo del sistema:

```c
unsigned long ulCntTick1ms;
```

La ISR de alta prioridad la incrementa en cada desbordamiento de Timer0 (`main.c:50-75`), y
`TimeBase.c:15-18` la expone:

```c
unsigned long getMillis(void) { return ulCntTick1ms; }
```

### 4.4 El patrón de periodo

Todas las tareas usan exactamente la misma plantilla. Ejemplo de `Cluster.c:32-36`:

```c
while (1)
{
    ulCntPeriodCluster = getMillis() + PERIOD_CLUSTER;
    PT_WAIT_UNTIL(pt, getMillis() >= ulCntPeriodCluster);
    switch(stateCluster) { ... }
}
```

Se calcula un instante de vencimiento absoluto y se cede el control hasta alcanzarlo. Los periodos
de cada módulo:

| Tarea | Constante | Valor | Definida en | Periodo real (tick 1,024 ms) |
|---|---|---|---|---|
| `taskLedLive` | `PERIOD_LEDLIVE` | 10 | `LedLive.h:23` | 10,24 ms |
| `taskAnalizaUart1` | `PERIOD_ANALIZA_UART1` | 1 | `Serial.h:21` | 1,024 ms |
| `taskAplicacion` | `PERIOD_APLICACION` | 10 | `Aplicacion.h:22` | 10,24 ms |
| `taskAlarm` | `PERIOD_ALARM` | 10 | `Alarma.h:33` | 10,24 ms |
| `taskBuzzer` | `PERIOD_BUZZER` | 10 | `Buzzer.h:22` | 10,24 ms |
| `taskCluster` | `PERIOD_CLUSTER` | 10 | `Cluster.h:13` | 10,24 ms |

Cada variable `ulCntPeriodX` se define en el `.c` de su módulo (`LedLive.c:31`, `Serial.c:82`,
`Aplicacion.c:52`, `Alarma.c:36`, `Buzzer.c:15`, `Cluster.c:26`) y se declara `extern` en
`main.c:30-35` para que la ISR pueda tocarlas.

### 4.5 El reset a los 60000 ticks: por qué existe y qué pasa en el wrap

En la ISR de Timer0, `main.c:57-73`:

```c
//si hay un minuto de tiks!!
if(++ulCntTick1ms >= 60000)
{
    ulCntTick1ms = 0;

    ulCntPeriodLedLive = 0;
    ulCntPeriodAplicacion = 0;
    ulCntPeriodAlarm = 0;
    ulCntPeriodBuzzer = 0;
    ulCntPeriodAnaUart1 = 0;
    ulCntPeriodCluster = 0;
}
```

**Por qué existe.** `getMillis()` devuelve un contador que se reinicia a 0 cada 60000 ticks. Si solo
se reiniciara el contador y no los vencimientos, ocurriría lo siguiente: una tarea que a t=59 995
calcula `ulCntPeriodX = 59 995 + 10 = 60 005` se quedaría esperando `getMillis() >= 60005`, cosa
que no puede pasar nunca porque el contador vuelve a 0 en 60 000. La tarea quedaría bloqueada para
siempre. Poner a cero los seis vencimientos en el mismo instante en que se reinicia el contador
convierte la condición en `getMillis() >= 0`, que es trivialmente cierta, y todas las tareas se
desbloquean en la siguiente pasada.

Es decir: es un **manejo manual del wrap-around**, resuelto por fuerza bruta. La forma limpia sería
dejar que el contador desborde de forma natural en 2^32 y comparar por diferencia con signo
(`(long)(getMillis() - deadline) >= 0`), lo que elimina el reinicio y su ventana de carrera.

**Qué pasa exactamente en el instante del wrap.**

1. Las seis tareas se vuelven simultáneamente elegibles. En la siguiente vuelta del `while(1)` de
   `main.c:132-140` las seis ejecutan una iteración de su máquina de estados, una detrás de otra.
2. Una tarea que estuviera a mitad de su periodo ve ese periodo **truncado**. Por ejemplo, si la
   tarea del cluster acababa de programar un vencimiento a +10 ms y el wrap ocurre 2 ms después,
   ese ciclo dura 2 ms en lugar de 10. Los contadores por ciclo (`cl.uiCnt`, `ucCntTimeBuzzer`,
   `uiCntLedLive`, `ala.uiCnt`, `ap.uiCntVolt`) avanzan un paso "gratis".
3. El efecto acumulado: **una vez cada 61,44 s todos los temporizados por conteo de ciclos
   adelantan hasta un periodo completo (≤10 ms).** Sobre un parpadeo de 2 s o una ráfaga de 1 s es
   jitter irrelevante. Sobre `ap.uiCntVolt` (6000 ciclos = 60 s) supone que la lectura de tensión
   se dispara ligeramente antes de lo nominal.
4. La ISR escribe seis `unsigned long` en cada wrap. En un PIC18 eso son 24 escrituras de byte
   dentro de la interrupción, alargándola. No es crítico porque solo ocurre una vez cada 61 s.

**Y hay una carrera real** entre esos ceros y la asignación de las tareas: ver
[D08](#d08--carrera-entre-el-reset-del-wrap-y-la-asignación-del-vencimiento).

### 4.6 La ISR de alta prioridad

`main.c:45-86`. Atiende dos fuentes:

**Timer0** (`main.c:50-75`): recarga `TMR0 = 0xFFEC`, limpia `T0IF` e incrementa el tick.
Obsérvese que la recarga se hace **antes** de limpiar el flag (`main.c:53` y `main.c:55`), lo cual
es correcto.

**Recepción UART** (`main.c:77-85`):

```c
if(PIR1bits.RCIF)
{
    ch = UART_read();
    receiverUart1(&ch);
    serial1.flagRx = true;
    anaT1.uiCnt = 0;
}
```

`UART_read()` (`UART.h:44-61`) limpia la condición de overrun (`OERR`) si se ha producido, lo cual
es imprescindible porque el `CREN` se bloquea al desbordarse. `receiverUart1()` (`Serial.c:74-77`)
mete el byte en `serial1.bufferRx` **sin comprobar el límite** — ver
[D05](#d05--receiveruart1-escribe-en-el-buffer-sin-comprobar-el-límite).

`anaT1.uiCnt = 0` reinicia el contador de silencio: es el mecanismo de detección de fin de trama
(ver [§6.3](#63-troceado-de-la-trama-detección-de-fin-por-silencio)).

### 4.7 La ISR de baja prioridad

`main.c:92-101`:

```c
void __interrupt(low_priority) INT_ISR_LOW (void)
{
    if(INTCON3bits.INT1IE == 1 && INTCON3bits.INT1IF == 1)
    {
         printf("INICIO INTERRUPCION INT1\r\n");
         __delay_ms(4000);
         printf("FIN INTERRUPCION INT1\r\n");
         INTCON3bits.INT1IF = 0;
    }
}
```

`INT1IE` **no se habilita en ningún punto del firmware** (única aparición: `main.c:94`), así que
este cuerpo nunca se ejecuta. Pero se compila, y arrastra `printf` y su cadena de llamadas al
contexto de interrupción. Ver [D12](#d12--isr-de-baja-prioridad-con-printf-y-un-retardo-de-4-segundos).

`RCONbits.IPEN = 1` en `main.c:152` habilita el esquema de prioridades; `GIEH` y `GIEL` se activan
en `main.c:153-154`. Con `IPEN=1`, el bit `INTCONbits.GIE` **es** `GIEH`, dato relevante para
entender [D11](#d11--eepromwrite-reactiva-gie-de-forma-incondicional).

---

## 5. Máquina de estados de cada tarea

Los `enum` de estados **no tienen inicializador**, así que el primer miembro vale 0 y las variables
de estado globales (`stateAp`, `stateAlarm`, `stateAnaTrama1`, `stateCluster`, `stateBuzzer`,
`state_ledLive`) arrancan en 0 por estar en `.bss`. Por eso todas las tareas parten del primer
estado declarado.

**Ninguno de los seis `switch` tiene rama `default:`** — ver [D16](#d16--ningún-switch-de-estados-tiene-rama-default).

### 5.1 Tarea Aplicación — `Aplicacion.c:56-240`

Enum en `Aplicacion.h:173-181`. Estado inicial: `ST_ARRANQUE_AP`.

Usa un patrón auxiliar de "primera entrada al estado": `cambiarEstado()` (`Aplicacion.c:266-270`)
pone `ap.uiStatePrevious = 0xffff` y cambia el estado; `inicioEstado(s)` (`Aplicacion.c:255-263`)
devuelve `true` solo la primera vez que se evalúa dentro de ese estado. De ahí que estados como
`ST_READ_VOLT_AP` tarden dos ciclos (uno para actuar, otro para transitar).

```mermaid
stateDiagram-v2
    [*] --> ST_ARRANQUE_AP

    ST_ARRANQUE_AP --> ST_READ_MEMO_AP : ++uiCntAplicacion >= 500 (5,12 s) / flagArranque=true, twoBeep() [Aplicacion.c:69-79]

    ST_READ_MEMO_AP --> ST_READ_MEMO_AP : ucInitMemory != 0x06 / inicializa 36 celdas EEPROM + twoBeep() [Aplicacion.c:94-139]
    ST_READ_MEMO_AP --> ST_ESPERA_AP : ucInitMemory == 0x06 / readMemoriaValues(), ala.flagUpdate=true, banner UART [Aplicacion.c:141-152]

    ST_ESPERA_AP --> ST_ESPERA_AP : flagEventoRead / oneBeep() + readDevide() [Aplicacion.c:172-177]
    ST_ESPERA_AP --> ST_ESPERA_AP : flagEventReloj / oneBeep() [Aplicacion.c:178-182]
    ST_ESPERA_AP --> ST_ESPERA_AP : flagEventalarm / readMemoriaValues() + ala.flagUpdate [Aplicacion.c:183-189]
    ST_ESPERA_AP --> ST_ESPERA_AP : sin evento / cl.flagEvento = ap.flagAlarm [Aplicacion.c:197-204]
    ST_ESPERA_AP --> ST_READ_VOLT_AP : ++uiCntVolt >= 6000 (~61 s) [Aplicacion.c:190-194]

    ST_READ_VOLT_AP --> ST_ESPERA_AP : 2do ciclo (1ro fVolt = ADC_read(1)) [Aplicacion.c:209-221]

    ST_READ_TEMP_AP --> ST_ESPERA_AP : 2do ciclo (1ro fTemp = ADC_read(3)) [Aplicacion.c:225-235]

    note right of ST_READ_TEMP_AP
        INALCANZABLE: nadie llama
        cambiarEstado(ST_READ_TEMP_AP).
        Ver D23
    end note

    note right of ST_PRUEBA_AP
        Cuerpo VACIO y sin transicion
        (Aplicacion.c:159-162).
        Inalcanzable hoy; si se entrara,
        la tarea se congela. Ver D16
    end note
```

**Detalle importante de `ST_ESPERA_AP`:** todas las condiciones están encadenadas con `else if`
(`Aplicacion.c:172-204`). Consecuencias:

- Si llega un evento serie en ese ciclo, `++ap.uiCntVolt` **no se evalúa** y `cl.flagEvento`
  **no se actualiza** ese ciclo. Como los eventos son esporádicos, no llega a notarse.
- La asignación `cl.flagEvento = true/false` (`Aplicacion.c:197-204`) es el único puente entre la
  lógica de alarmas y el actuador. Se reevalúa cada 10,24 ms.

### 5.2 Tarea Alarma — `Alarma.c:40-561`

Enum en `Alarma.h:71-90`. Estado inicial: `ST_ARRANQUE_ALA`.

```mermaid
stateDiagram-v2
    [*] --> ST_ARRANQUE_ALA

    ST_ARRANQUE_ALA --> ST_ESPERA_ALA : ap.flagArranque / leerRTC(...) [Alarma.c:52-55]

    ST_ESPERA_ALA --> ST_UPDATE_SEG_ALA : ++uiCnt>=50 y rtc.seg != 0 [Alarma.c:105-112]
    ST_ESPERA_ALA --> ST_UPDATE_VALUE_ALA : ++uiCnt>=50 y rtc.seg == 0 [Alarma.c:113-116]
    ST_ESPERA_ALA --> ST_CHECK_ALL_ALA : uiCnt<50 y ++uiCnt2>=20 [Alarma.c:118-122]
    ST_ESPERA_ALA --> ST_UPDATE_ALA : uiCnt<50 y uiCnt2<20 y ala.flagUpdate [Alarma.c:123-127]

    ST_UPDATE_SEG_ALA --> ST_ESPERA_ALA : leerRtcSeg(and rtc.seg) [Alarma.c:191-194]
    ST_UPDATE_VALUE_ALA --> ST_ESPERA_ALA : leerRTC (hora completa) [Alarma.c:196-199]
    ST_UPDATE_ALA --> ST_ESPERA_ALA : copia memo hacia ala1..ala5 [Alarma.c:59-102]

    ST_CHECK_ALL_ALA --> ST_CHECK_ALARM1 : ++ucCntCheck==1 y ala1.flagAlarm
    ST_CHECK_ALL_ALA --> ST_CHECK_ALARM2 : ucCntCheck==2 y ala2.flagAlarm
    ST_CHECK_ALL_ALA --> ST_CHECK_ALARM3 : ucCntCheck==3 y ala3.flagAlarm
    ST_CHECK_ALL_ALA --> ST_CHECK_ALARM4 : ucCntCheck==4 y ala4.flagAlarm
    ST_CHECK_ALL_ALA --> ST_CHECK_ALARM5 : ucCntCheck==5 y ala5.flagAlarm (ucCntCheck=0)
    ST_CHECK_ALL_ALA --> ST_ESPERA_ALA : la alarma N esta deshabilitada [Alarma.c:130-188]

    ST_CHECK_ALARM1 --> ST_CHECK_HOUR1 : !flagDayAlar y (dayAlar==8 o (==9 y LUN..VIE) o (==10 y SAB/DOM))
    ST_CHECK_ALARM1 --> ST_ESPERA_ALA : el dia no coincide o dayAlar invalido
    ST_CHECK_ALARM1 --> ST_CHECK_ALARM1 : flagDayAlar == true / RAMA VACIA SIN TRANSICION [Alarma.c:241-245]

    ST_CHECK_HOUR1 --> ST_ESPERA_ALA : hor==hourInit y min==minInit -> ap.flagAlarm=true ; hor==hourEnd y min==minEnd -> ap.flagAlarm=false [Alarma.c:421-447]

    note right of ST_CHECK_ALARM1
        ST_CHECK_ALARM2..5 (Alarma.c:249-419)
        y ST_CHECK_HOUR2..5 (Alarma.c:450-557)
        son copias literales con otro indice.
        Las cinco tienen la misma rama vacia.
        Ver D03
    end note
```

**Cadencia real de `ST_ESPERA_ALA`.** El código es (`Alarma.c:104-128`):

```c
case ST_ESPERA_ALA:
    if(++ala.uiCnt >= 50)          { ala.uiCnt = RST;  /* refresco de RTC */ }
    else if(++ala.uiCnt2 >= 20)    { ala.uiCnt2 = RST; stateAlarm = ST_CHECK_ALL_ALA; }
    else if(ala.flagUpdate)        { /* ... */ }
```

Traza de una ronda completa (cada visita = 10,24 ms):

| Visita | `uiCnt` | `uiCnt2` | Acción |
|---|---|---|---|
| 1…19 | 1…19 | 1…19 | nada |
| **20** | 20 | 20→0 | → `ST_CHECK_ALL_ALA` (≈205 ms) |
| 21…39 | 21…39 | 1…19 | nada |
| **40** | 40 | 20→0 | → `ST_CHECK_ALL_ALA` |
| 41…49 | 41…49 | 1…9 | nada |
| **50** | 50→0 | **9 (no incrementa)** | → refresco de RTC (≈530 ms) |
| 51… | 1… | 10,11,… | llega a 20 tras 11 visitas más |

- **`uiCnt2` no se incrementa en la visita en la que `uiCnt` llega a 50.** Es el efecto lateral en
  el `else if` que hay que analizar: ver [D19](#d19--efecto-lateral-de-uicnt2-dentro-de-un-else-if).
  El resultado no es un fallo funcional, pero desincroniza las dos cadencias y hace que el intervalo
  entre comprobaciones oscile entre 20 y 11 visitas.
- **Además, `uiCnt` y `uiCnt2` no cuentan mientras la máquina está fuera de `ST_ESPERA_ALA`.** Cada
  excursión a `ST_CHECK_ALL_ALA → ST_CHECK_ALARMn → ST_CHECK_HOURn` consume 3 ciclos que no
  aparecen en el conteo. Por eso el refresco de RTC nominal de 50 × 10,24 ms = 512 ms se convierte
  en la práctica en unos **560–590 ms**.
- Esto importa porque el minuto solo se actualiza cuando se lee `rtc.seg == 0`, y **para no perder
  ningún minuto hace falta muestrear los segundos al menos una vez por segundo**. Con 560–590 ms hay
  margen, pero es un margen del 40 %: si alguien añade una alarma más, alarga la lectura I2C o
  aumenta `PERIOD_ALARM`, el firmware empezará a saltarse minutos en silencio. Ver
  [D07](#d07--comparación-de-alarmas-por-igualdad-exacta-de-hora-y-minuto).
- **`ST_CHECK_ALL_ALA` evalúa una sola alarma por visita**, en round-robin con `ala.ucCntCheck`
  (`Alarma.c:131-188`). Cada alarma concreta se revisa una de cada cinco veces, es decir
  aproximadamente **una vez por segundo**. Suficiente para una resolución de un minuto.

### 5.3 Tarea Serial / AnalizaUart1 — `Serial.c:90-427`

Enum en `Serial.h:86-93`. Estado inicial: `ST_ARRANQUE_ANA1`. Periodo 1,024 ms.

```mermaid
stateDiagram-v2
    [*] --> ST_ARRANQUE_ANA1

    ST_ARRANQUE_ANA1 --> ST_ESPERA_ANA1 : ap.flagArranque / limpia bufferRx, ucCntRX=0, flagRx=false [Serial.c:102-111]

    ST_ESPERA_ANA1 --> ST_INIT_FRAME_ANA1 : serial1.flagRx y ++anaT1.uiCnt >= 5 (~5 ms sin bytes) / copia filtrando los 0x00 [Serial.c:114-143]

    ST_INIT_FRAME_ANA1 --> ST_ANALYSIS_ANA1 : strstr(bufferRx, INIT_FRAME) != NULL [Serial.c:148-151]
    ST_INIT_FRAME_ANA1 --> ST_ESPERA_ANA1 : sin delimitador de inicio [Serial.c:152-155]

    ST_ANALYSIS_ANA1 --> ST_ESPERA_ANA1 : contiene L / flagEventoRead = true [Serial.c:160-164]
    ST_ANALYSIS_ANA1 --> ST_ESPERA_ANA1 : contiene R / extrae hora y calendario, escribirRTC(), flagEventReloj=true [Serial.c:166-179]
    ST_ANALYSIS_ANA1 --> ST_WAIT_ANA1 : contiene A y E / ucNumAlarm, ucEncAlarm, y si E=1 extrae I, F, D [Serial.c:181-211]
    ST_ANALYSIS_ANA1 --> ST_ESPERA_ANA1 : contiene A pero no E [Serial.c:212-215]
    ST_ANALYSIS_ANA1 --> ST_ESPERA_ANA1 : ningun identificador reconocido [Serial.c:217-220]

    ST_WAIT_ANA1 --> ST_ESPERA_ANA1 : escribe ala1..ala5 y EEPROM / flagEventalarm = true [Serial.c:224-418]
```

**Orden de evaluación en `ST_ANALYSIS_ANA1`.** Se comprueba `"L"` primero (`Serial.c:160`), luego
`"R"` (`Serial.c:166`) y por último `"A"` (`Serial.c:181`). Como las tramas reales no contienen
letras cruzadas (`¿A3,E1,I0830,F1745,D9,?` no tiene ni `L` ni `R`), el orden funciona. Pero si dos
tramas llegan pegadas en la misma ráfaga, gana la primera de la lista y la otra se descarta sin
aviso: ver [D31](#d31--dos-tramas-en-la-misma-ráfaga-la-segunda-se-pierde).

### 5.4 Tarea Cluster — `Cluster.c:29-98`

Enum en `Cluster.h:26-33`. Estado inicial: `ST_ARRANQUE_CL`. Periodo 10,24 ms.

```mermaid
stateDiagram-v2
    [*] --> ST_ARRANQUE_CL

    ST_ARRANQUE_CL --> ST_ESPERA_CL : ap.flagArranque [Cluster.c:39-42]

    ST_ESPERA_CL --> ST_HIGH_CL : cl.flagEvento / ON_CLUSTER (LATC2=1) + oneBeep() [Cluster.c:46-51]
    ST_ESPERA_CL --> ST_ESPERA_CL : !cl.flagEvento / OFF_CLUSTER (LATC2=0) [Cluster.c:52-55]

    ST_HIGH_CL --> ST_LOW_CL : ++uiCnt >= 5 (~51 ms) / OFF_CLUSTER [Cluster.c:60-65]

    ST_LOW_CL --> ST_HIGH_CL : ++uiCnt>=5 y ++itera < 5 / ON_CLUSTER [Cluster.c:69-82]
    ST_LOW_CL --> ST_LOW_SLOW_CL : ++uiCnt>=5 y ++itera >= 5 / itera=0, queda apagado [Cluster.c:73-77]

    ST_LOW_SLOW_CL --> ST_ESPERA_CL : ++uiCnt >= 50 (~512 ms) / cl.flagEvento = false [Cluster.c:87-93]
```

**Patrón resultante.** Cinco destellos de ~51 ms encendido / ~51 ms apagado (≈512 ms en total),
seguidos de una pausa larga de ~512 ms. Ciclo completo ≈ **1,024 s**.

**Y se repite indefinidamente mientras la alarma esté activa**, porque `Cluster.c:91` pone
`cl.flagEvento = false` pero `Aplicacion.c:199` lo vuelve a poner a `true` en menos de 10,24 ms si
`ap.flagAlarm` sigue levantada. Es decir: `cl.flagEvento = false` de `Cluster.c:91` es efímero por
diseño y sirve solo para que la ráfaga vuelva a arrancar desde `ST_ESPERA_CL`.

**Efecto colateral grave:** `oneBeep()` en `Cluster.c:49` se ejecuta al inicio de **cada** ráfaga.
El zumbador suena ~51 ms **una vez por segundo durante toda la franja horaria**, que puede durar
horas. Ver [D14](#d14--el-zumbador-pita-una-vez-por-segundo-durante-toda-la-franja).

### 5.5 Tarea Buzzer — `Buzzer.c:18-119`

Enum en `Buzzer.h:33-40`. Estado inicial: `ST_WAIT_BUZZER`. Periodo 10,24 ms.
El disparo es por variable global `ucTypeBeep` (`Buzzer.c:9`), fijada por `oneBeep()`
(`Buzzer.c:133-137`), `twoBeep()` (`Buzzer.c:138-143`), `alarmBeep()` (`Buzzer.c:144-148`) y
`cancelBeep()` (`Buzzer.c:149-153`).

```mermaid
stateDiagram-v2
    [*] --> ST_WAIT_BUZZER

    ST_WAIT_BUZZER --> ST_ONE_BUZZER : ucTypeBeep == 1 / ON_BUZZER [Buzzer.c:33-37]
    ST_WAIT_BUZZER --> ST_TWO_BUZZER : ucTypeBeep == 2 / ucIteradorBuzzer-- y ON_BUZZER [Buzzer.c:38-43]
    ST_WAIT_BUZZER --> ST_ALARM_BUZZER : ucTypeBeep == 3 / ON_BUZZER [Buzzer.c:44-48]
    ST_WAIT_BUZZER --> ST_WAIT_BUZZER : ucTypeBeep == 0 / OFF_BUZZER, flagStartBuzzer=false [Buzzer.c:49-56]

    ST_ONE_BUZZER --> ST_WAIT_BUZZER : ++ucCntTimeBuzzer >= 5 (~51 ms) / OFF_BUZZER, ucTypeBeep=0 [Buzzer.c:64-70]

    ST_TWO_BUZZER --> ST_WAIT_BUZZER : ++cnt>=5 y ucIteradorBuzzer==0 / OFF_BUZZER, ucTypeBeep=0 [Buzzer.c:81-86]
    ST_TWO_BUZZER --> ST_WAIT_LOW_BUZZER : ++cnt>=5 y ucIteradorBuzzer!=0 / OFF_BUZZER [Buzzer.c:87-91]

    ST_ALARM_BUZZER --> ST_WAIT_LOW_BUZZER : ++cnt >= 5 / OFF_BUZZER [Buzzer.c:99-104]

    ST_WAIT_LOW_BUZZER --> ST_WAIT_BUZZER : ++cnt >= 5 [Buzzer.c:110-114]
```

**`twoBeep()` verificado:** `ucIteradorBuzzer = 2` (`Buzzer.c:141`) → primera entrada decrementa a
1, pita, apaga y va a `ST_WAIT_LOW_BUZZER`; vuelve a `ST_WAIT_BUZZER` con `ucTypeBeep` todavía a 2
→ decrementa a 0, pita, y esta vez sí cancela. **Dos pitidos.** Correcto.

**`alarmBeep()` no se llama desde ningún sitio** y no tiene condición de salida propia: entraría en
un ciclo `ST_ALARM_BUZZER ↔ ST_WAIT_LOW_BUZZER` indefinido hasta que alguien llamara a
`cancelBeep()`, que **tampoco se llama desde ningún sitio**. Igual que `endBeep()`
(`Buzzer.c:155-158`). Ver [D39](#d39--funciones-y-variables-muertas).

### 5.6 Tarea LedLive — `LedLive.c:35-89`

Enum en `LedLive.h:36-41`. Estado inicial: `ST_ARRANQUE_LED`. Periodo 10,24 ms.
Nótese que la lógica del LED está **invertida** (`LedLive.h:26-27`): `ON_LED_LIVE` escribe
`LATA0 = 0` y `OFF_LED_LIVE` escribe `LATA0 = 1`, lo que implica que el LED va conectado del pin a
Vcc a través de `R1 = 330R`.

```mermaid
stateDiagram-v2
    [*] --> ST_ARRANQUE_LED

    ST_ARRANQUE_LED --> ST_ARRANQUE_LED : !ap.flagArranque / ON_LED_LIVE (fijo encendido) [LedLive.c:46-50]
    ST_ARRANQUE_LED --> ST_HIGH_LED : ap.flagArranque [LedLive.c:47-50]

    ST_HIGH_LED --> ST_HIGH_LED : !flagInitStLed / flagInitStLed=true, ON_LED_LIVE [LedLive.c:54-58]
    ST_HIGH_LED --> ST_LOW_LED : ++uiCntLedLive >= 5 (~51 ms) / reset contador y flagInitStLed [LedLive.c:61-66]

    ST_LOW_LED --> ST_LOW_LED : !flagInitStLed / flagInitStLed=true, OFF_LED_LIVE [LedLive.c:71-75]
    ST_LOW_LED --> ST_HIGH_LED : ++uiCntLedLive >= 195 (~2,0 s) [LedLive.c:78-83]
```

Resultado: destello corto de ~51 ms cada ~2,05 s. **Durante los primeros 5,12 s tras el arranque
el LED queda fijo encendido** (`LedLive.c:46`), lo que sirve de indicador visual de que el equipo
está en `ST_ARRANQUE_AP`.

---

## 6. Protocolo serie / Bluetooth

Enlace físico: UART del PIC (RC6/RC7) contra un módulo Bluetooth **HC-06** en modo SPP
(`U2 = HC06_Module` en el esquemático). Parámetros: **8N1, ~9469,7 baud nominales 9600**
(ver [§2.3](#23-uart-verificación-de-spbrg-contra-la-fórmula-del-datasheet)).

La app Android que genera las tramas está en
`D:\@Proyect\Baliza\1 Firmware\Doc Aplicativo Movil\BalizaV10\app\src\main\java\com\example\balizav10\MainActivity2.java`.

### 6.1 Identificadores y delimitadores

Definidos en `Serial.h:27-37`:

| Macro | Valor en el fuente | Byte real | Uso | Línea |
|---|---|---|---|---|
| `INIT_FRAME` | (carácter no ASCII) | **`0xBF`** | Delimitador de inicio de trama | `Serial.h:27` |
| `END_FRAME` | `"?"` | `0x3F` | Delimitador de fin de trama | `Serial.h:28` |
| `ID_NUM_ALARM` | `"A"` | `0x41` | Número de alarma (1..5) | `Serial.h:29` |
| `ID_ENC_ALARM` | `"E"` | `0x45` | Enable (0 = apagada, 1 = encendida) | `Serial.h:30` |
| `ID_INIT_ALARM` | `"I"` | `0x49` | Hora de inicio, formato `HHMM` | `Serial.h:31` |
| `ID_END_ALARM` | `"F"` | `0x46` | Hora de fin, formato `HHMM` | `Serial.h:32` |
| `ID_DAY_ALARM` | `"D"` | `0x44` | Código de días (8, 9 o 10) | `Serial.h:33` |
| `ID_RELOJ` | `"R"` | `0x52` | Puesta en hora, formato `HHMM` | `Serial.h:34` |
| `ID_CALENDAR` | `"C"` | `0x43` | Calendario, formato `DDMMYY-U` | `Serial.h:35` |
| `ID_COMA` | `","` | `0x2C` | Separador de campos | `Serial.h:36` |
| `ID_READ_DEV` | `"L"` | `0x4C` | Petición de volcado del dispositivo | `Serial.h:37` |

### 6.2 El byte exacto de `INIT_FRAME` (investigación)

En `Serial.h:27` el literal aparece corrupto en cualquier editor que asuma UTF-8. El volcado
hexadecimal del fichero resuelve la duda:

```
$ sed -n '27,28p' Serial.h | xxd
00000000: 2364 6566 696e 6520 494e 4954 5f46 5241  #define INIT_FRA
00000010: 4d45 2020 2020 2020 22bf 220a 2364 6566  ME      ".".#def
00000020: 696e 6520 454e 445f 4652 414d 4520 2020  ine END_FRAME
00000030: 2020 2020 223f 220a                          "?".
```

- **`INIT_FRAME` es la cadena de un solo byte `0xBF`** (`22 bf 22` = `"` `0xBF` `"`).
  El fichero `Serial.h` está guardado en **CP1252 / ISO-8859-1**, donde `0xBF` es el carácter
  `¿` (signo de interrogación de apertura).
- **`END_FRAME` es `0x3F`**, el `?` ASCII normal. Sin sorpresa.

Contraste con lo que envía la app Android. En `MainActivity2.java:182`, `:208`, `:214` y `:408`
las tramas se construyen con el carácter `¿`. El fichero Java está en **UTF-8**:

```
$ sed -n '182p;208p;214p' MainActivity2.java | xxd
00000020: 22c2 bf52 222b 2053 7472 696e 672e 7661  "..R"+ String.va
00000080: 7346 7261 6d65 436f 6e66 203d 2022 c2bf  sFrameConf = "..
000000f0: 7261 6d65 436f 6e66 203d 2022 c2bf 4122  rameConf = "..A"
```

`c2 bf` es la codificación UTF-8 de U+00BF (`¿`). El canal de salida se abre en
`MainActivity2.java:419` como:

```java
PrintWriter out = new PrintWriter(new BufferedWriter(new OutputStreamWriter(socket.getOutputStream())), true);
```

`OutputStreamWriter` sin charset explícito usa `Charset.defaultCharset()`, que en Android **siempre
es UTF-8**. Por tanto, **por el cable viajan dos bytes: `0xC2 0xBF`**, mientras que el firmware
busca uno solo, `0xBF`.

**¿Funciona?** Sí, por casualidad. `strstr(anaT1.bufferRx, INIT_FRAME)` en `Serial.c:148` busca la
subcadena de un byte `0xBF` y la encuentra en la **segunda** posición de la secuencia UTF-8. El
`0xC2` sobrante queda al principio del buffer sin molestar a nadie porque ningún identificador es
`0xC2` y el análisis posterior usa `strstr` sobre el resto de la cadena.

> **Riesgos.** (a) Si alguien reabre `Serial.h` en un editor con UTF-8 y lo guarda, el byte `0xBF`
> puede convertirse en el carácter de sustitución U+FFFD (`EF BF BD`) y el firmware dejaría de
> reconocer tramas. (b) Si la app se porta a otra plataforma cuyo charset por defecto sea
> ISO-8859-1, enviaría un único `0xBF` — que también funcionaría, pero por otro camino.
> (c) Cualquier byte `0xBF` de basura en la línea abre una trama falsa.
> **Recomendación:** cambiar `Serial.h:27` a un carácter ASCII imprimible e inequívoco,
> por ejemplo `#define INIT_FRAME "#"`, y `MainActivity2.java` en consecuencia. Es un cambio de
> dos líneas en cada lado. Ver [D29](#d29--delimitador-de-inicio-no-ascii-y-dependiente-de-la-codificación).

### 6.3 Troceado de la trama: detección de fin por silencio

No hay máquina de estados de recepción byte a byte. El mecanismo es:

1. La ISR (`main.c:77-85`) mete cada byte recibido en `serial1.bufferRx` mediante
   `receiverUart1()` (`Serial.c:74-77`), levanta `serial1.flagRx` y **pone `anaT1.uiCnt = 0`**.
2. La tarea `taskAnalizaUart1` corre cada 1,024 ms. Mientras `serial1.flagRx` esté levantada,
   incrementa `anaT1.uiCnt` (`Serial.c:118`). Si llega otro byte, la ISR lo vuelve a poner a cero.
3. Cuando pasan **5 ciclos sin recibir nada** (`++anaT1.uiCnt >= 5`, es decir ≈5,1 ms) se da la
   trama por terminada.

A 9600 baud un byte tarda ~1,04 ms, así que 5,1 ms equivale a unos 5 tiempos de byte. Es un umbral
razonable para SPP, pero no está garantizado: si el enlace Bluetooth introduce una pausa de más de
5 ms en mitad de una trama (retransmisión, congestión del canal), la trama se parte en dos, y la
primera mitad —que sí contiene `INIT_FRAME`— se analiza con delimitadores ausentes.
Ver [D04](#d04--desbordamiento-de-buffer-en-extraervalue-y-extraerframe).

4. Al cerrar la trama, `Serial.c:122-137` copia `serial1.bufferRx` a `anaT1.bufferRx`
   **filtrando los bytes `0x00`**:

```c
char x = 0;
for(char i = 0; i <= SIZE_BUFFER_RX1; i++)
{
    if(serial1.bufferRx[i] != '\0')
        anaT1.bufferRx[x++] = serial1.bufferRx[i];
}
```

Ese filtro **es imprescindible** y probablemente se añadió por prueba y error, porque la app
Android inyecta bytes nulos en mitad de las tramas (ver [§6.5](#65-el-detalle-de-los-bytes-nulos-que-inyecta-la-app)).
El bucle tiene un off-by-one: `i <= 40` recorre 41 posiciones de un array de 40
(`SIZE_BUFFER_RX1 = 40`, `Serial.h:24`). Ver [D13](#d13--off-by-one-en-el-bucle-de-copia-del-buffer-de-recepción).

### 6.4 Gramática de las tramas

```
trama       ::= 0xBF cuerpo '?'
cuerpo      ::= lectura | reloj | alarma_off | alarma_on

lectura     ::= 'L'
reloj       ::= 'R' HHMM ',' 'C' DDMMYY '-' U
alarma_off  ::= 'A' n ',' 'E' '0' ','
alarma_on   ::= 'A' n ',' 'E' '1' ',' 'I' HHMM ',' 'F' HHMM ',' 'D' d ','

n           ::= '1'..'5'
HHMM        ::= 4 dígitos, hora 00-23 y minuto 00-59
DDMMYY      ::= 6 dígitos
U           ::= '1'..'7'   (1 = lunes … 7 = domingo)
d           ::= '8' | '9' | '10'
```

Todas las tramas de la app terminan además con `\n\r` y el `println()` de Java añade un `\n`
adicional. El firmware **no usa el fin de línea para nada**: le basta con el silencio de 5 ms.

### 6.5 El detalle de los bytes nulos que inyecta la app

En `MainActivity2.java:171-182`:

```java
char bufferHour[]  = new char[6];
char bufferCalen[] = new char[10];
Date.getChars(0,4,  bufferHour, 0);    // rellena solo los índices 0..3
Date.getChars(5,13, bufferCalen, 0);   // rellena solo los índices 0..7
sFrameHourCal = "¿R"+ String.valueOf(bufferHour)+",C"+String.valueOf(bufferCalen)+"?\n\r";
```

`String.valueOf(char[])` convierte **el array entero**, no la parte rellena. Por tanto
`bufferHour` aporta `"2145\0\0"` y `bufferCalen` aporta `"211025-2\0\0"`. La trama que sale por
el aire es:

```
C2 BF 52 32 31 34 35 00 00 2C 43 32 31 31 30 32 35 2D 32 00 00 3F 0A 0D 0A
 ¿  ¿  R  2  1  4  5 \0 \0  ,  C  2  1  1  0  2  5  -  2 \0 \0  ?  \n \r \n
```

y el filtro de `Serial.c:126-132` es lo que la deja utilizable. **Si alguien "arregla" ese filtro
sin entender por qué está ahí, el reloj deja de poder ponerse en hora.**

### 6.6 Ejemplos completos de trama

#### (a) Programar la alarma 3 de 08:30 a 17:45, de lunes a viernes

Texto: `¿A3,E1,I0830,F1745,D9,?\n\r`

Bytes tal como los envía la app Android (UTF-8):

```
C2 BF 41 33 2C 45 31 2C 49 30 38 33 30 2C 46 31 37 34 35 2C 44 39 2C 3F 0A 0D 0A
    ¿   A  3  ,  E  1  ,  I  0  8  3  0  ,  F  1  7  4  5  ,  D  9  ,  ?  \n \r \n
```

Bytes mínimos que acepta el firmware (sin el `C2`, sin fin de línea):

```
BF 41 33 2C 45 31 2C 49 30 38 33 30 2C 46 31 37 34 35 2C 44 39 2C 3F
```

Recorrido por el código:
`Serial.c:148` encuentra `0xBF` → `Serial.c:181` encuentra `"A"` →
`Serial.c:184` `extraerValue(bufferRx,"A",",")` → `ucNumAlarm = 3` →
`Serial.c:186` encuentra `"E"` → `Serial.c:189` `ucEncAlarm = 1` →
`Serial.c:199-200` `extraerFrame(...,"I",",")` = `"0830"` → `horaInit=8, minInit=30` →
`Serial.c:202-203` `extraerFrame(...,"F",",")` = `"1745"` → `horaEnd=17, minEnd=45` →
`Serial.c:205-207` `extraerFrame(...,"D",",")` = `"9"` → `ulDayAlarm = 9` →
`ST_WAIT_ANA1` `Serial.c:326-355` escribe `ala3` y las 7 celdas de EEPROM 0x0F–0x15.

> **Obsérvese la coma final obligatoria antes del `?`.** `extraerFrame` para el campo `D` busca
> `ID_COMA` como terminador (`Serial.c:205`), no `END_FRAME`. Si se omite esa coma —por ejemplo
> escribiendo `...,D9?`— el bucle de `Serial.c:486-489` sigue leyendo memoria hasta encontrar por
> casualidad un byte `,`, desbordando `buffer[10]`. La app siempre la pone
> (`MainActivity2.java:208`: `"...,D"+sAlarmD+",?\n\r"`), pero cualquier cliente hecho a mano que
> la omita provoca corrupción de pila.

#### (b) Apagar la alarma 2

Texto: `¿A2,E0,?\n\r`

```
C2 BF 41 32 2C 45 30 2C 3F 0A 0D 0A
```

Recorrido: `Serial.c:184` → `ucNumAlarm = 2`; `Serial.c:189` → `ucEncAlarm = 0`;
`Serial.c:192-195` salta a `ST_WAIT_ANA1` sin extraer horas; `Serial.c:233-237` pone
`ala2.flagAlarm = false` y `EEpromWrite(ADDRESS_EN_ALA2, 0)`.

> Nótese que **solo se escribe la celda de enable (0x08)**; las horas y días de la alarma 2 quedan
> en la EEPROM tal como estaban. Al volver a encenderla hay que reenviar todos los campos.

#### (c) Poner en hora — 21:45 del martes 21/10/2025

Texto: `¿R2145,C211025-2?\n\r`

```
BF 52 32 31 34 35 2C 43 32 31 31 30 32 35 2D 32 3F
    R  2  1  4  5  ,  C  2  1  1  0  2  5  -  2  ?
```

(La app real intercala los nulos descritos en [§6.5](#65-el-detalle-de-los-bytes-nulos-que-inyecta-la-app).)

Recorrido: `Serial.c:166` encuentra `"R"` → `Serial.c:168` `extraerFrame(...,"R",",")` = `"2145"`
→ `Serial.c:169` `extraerHora` → `hora=21, min=45` → `Serial.c:171`
`extraerFrame(...,"C","?")` = `"211025-2"` → `Serial.c:172` `extraerCalendar` →
`dia=21, mes=10, ano=25, diaSem=2` → `Serial.c:174`
`escribirRTC(21,45,0,21,10,25,2)`.

Verificación del recorrido de punteros de `extraerCalendar` (`Serial.c:521-560`) sobre `"211025-2"`:
`'2','1'`→21; `'1','0'`→10; `'2','5'`→25; `Serial.c:549` salta el `'-'`; `'2'`→2. Correcto.

**Los segundos se fuerzan a 0** (`Serial.c:174`, tercer argumento). Efecto secundario útil: al
escribir `0x00` en el registro 0x00 del DS1307 se limpia el bit CH (Clock Halt) y el oscilador
arranca. Efecto secundario malo: un equipo recién fabricado tiene el RTC **parado** hasta que
alguien le pone la hora por primera vez, porque el firmware nunca limpia CH en el arranque.
Ver [D28](#d28--el-bit-ch-del-ds1307-nunca-se-limpia-en-el-arranque).

**El día de la semana** viene de `SimpleDateFormat("HHmm ddMMyy-u")` (`MainActivity2.java:177`).
El patrón `u` de Java es el día ISO: 1 = lunes … 7 = domingo, que coincide exactamente con
`LUNE..DOMI` de `Alarma.h:13-19` y con `Dias_semana` de `DS1307.h:19-28`. ✅

#### (d) Pedir volcado del dispositivo

Texto: `¿L?\n\r` (`MainActivity2.java:408`)

```
C2 BF 4C 3F 0A 0D 0A
```

Recorrido: `Serial.c:160` encuentra `"L"` → `serial1.flagEventoRead = true` →
`Aplicacion.c:172-177` hace `oneBeep()` y llama a `readDevide()`.

### 6.7 Formato de la RESPUESTA generada por `readDevide()`

`Aplicacion.c:285-334`. Envía **9 cadenas independientes** mediante `transmitUart1()`, cada una
formateada con `sprintf` sobre `ap.bufferTx[45]`:

| # | Línea | Formato | Origen |
|---|---|---|---|
| 1 | Hora actual | `"%d:%d:%d\n\r"` | `rtc.hor, rtc.min, rtc.seg` — `Aplicacion.c:292` |
| 2 | Fecha | `"%d/%d/%d-%d\n\r\n\r\n\r"` | `rtc.day, rtc.month, rtc.year, rtc.dayWeek` — `Aplicacion.c:296` |
| 3 | Cabecera | `"No - Ini - Fin - On - Dias \n\r\n\r"` | literal — `Aplicacion.c:300` |
| 4–8 | Alarmas 1..5 | `" %d - %d:%d - %d:%d  - %s - %s\n\r"` | `memo.*` — `Aplicacion.c:306, 312, 318, 324, 330` |

Los dos campos `%s` los rellenan dos funciones auxiliares:

- `convOnOff()` (`Aplicacion.c:345-351`): `"ON"` si el enable es distinto de 0, `"OFF"` si es 0.
- `convStringDayWeek()` (`Aplicacion.c:336-343`): `8 → "Dia"`, `9 → "LV"`, **cualquier otro valor
  → `"SD"`**. Es decir, un valor corrupto de EEPROM se muestra como fin de semana sin avisar, y el
  caso "personalizado" no tiene representación.

**Ejemplo de respuesta real** (hora 21:45:03, martes 21/10/2025, solo la alarma 3 programada
de 08:30 a 17:45 de lunes a viernes):

```
21:45:3
21/10/25-2

No -    Ini    -   Fin    - On - Dias

 1   - 0:0   - 0:0  - OFF - Dia
 2   - 0:0   - 0:0  - OFF - Dia
 3   - 8:30   - 17:45  - ON - LV
 4   - 0:0   - 0:0  - OFF - Dia
 5   - 0:0   - 0:0  - OFF - Dia

```

Detalles que hay que conocer al escribir un cliente que parsee esta respuesta:

1. **`%d` no rellena con ceros**: sale `21:45:3` y no `21:45:03`; sale `8:30` y no `08:30`. Las
   columnas no quedan alineadas y el ancho de cada campo es variable. Cualquier parser tiene que
   ser tolerante.
2. **Cada cadena lleva un byte `0x00` de más al final.** `transmitUart1()` en `Serial.c:61` usa
   `for(int x = 0; x <= ucCntTx1 ; x++)` con `ucCntTx1 = strlen(bufferTx1)`, de modo que la última
   iteración transmite el terminador nulo. Ver [D20](#d20--transmituart1-envía-un-byte-nulo-de-más-en-cada-cadena).
3. **El volcado no incluye la tensión ni la temperatura** medidas en `ST_READ_VOLT_AP` /
   `ST_READ_TEMP_AP`. `ap.fVolt` y `ap.fTemp` se calculan y no se usan nunca.
   Ver [D23](#d23--medidas-de-tensión-y-temperatura-calculadas-y-nunca-usadas).
4. **No hay respuesta ni confirmación para las tramas de configuración de alarma ni de reloj.** El
   único acuse es un pitido del zumbador (`Aplicacion.c:175`, `:181`, `:188`). La app no puede saber
   si el comando llegó. Ver [D30](#d30--no-hay-acuse-de-recibo-de-la-configuración).
5. `readDevide()` imprime `memo.*`, es decir lo que hay en EEPROM, no las estructuras vivas
   `ala1..ala5`. En operación normal coinciden porque `Serial.c` escribe ambas, pero divergirían si
   una escritura de EEPROM fallara.

---

## 7. Modelo de datos en EEPROM

La EEPROM interna de datos del PIC18F2550 (256 bytes, `0xF00000`–`0xF000FF` en el mapa del
enlazador) guarda la configuración de las cinco alarmas. Se usan **36 bytes**, de `0x00` a `0x23`.
Las direcciones están definidas como macros en `Aplicacion.h:40-102`.

### 7.1 Mapa dirección por dirección

| Dir. | `#define` | Línea | Qué guarda | Rango válido | Valor tras inicialización |
|---|---|---|---|---|---|
| `0x00` | `ADDRESS_INIT_EEPROM` | `Aplicacion.h:41` | Marca de "memoria inicializada" | `0x06` (`INIT_VALUE_EEPROM`) | `0x06` |
| `0x01` | `ADDRESS_EN_ALA1` | `Aplicacion.h:44` | Alarma 1 habilitada | 0 / 1 | `0` |
| `0x02` | `ADDRESS_FLAGDAYALA1` | `Aplicacion.h:45` | Alarma 1 con días personalizados | 0 / 1 | `0` |
| `0x03` | `ADDRESS_DAYWEEK1` | `Aplicacion.h:46` | Alarma 1: código de días | 1..10 | `8` (diario) |
| `0x04` | `ADDRESS_INIT_HOUR1` | `Aplicacion.h:48` | Alarma 1: hora de inicio | 0..23 | `0` |
| `0x05` | `ADDRESS_INIT_MIN1` | `Aplicacion.h:49` | Alarma 1: minuto de inicio | 0..59 | `0` |
| `0x06` | `ADDRESS_END_HOUR1` | `Aplicacion.h:51` | Alarma 1: hora de fin | 0..23 | `0` |
| `0x07` | `ADDRESS_END_MIN1` | `Aplicacion.h:52` | Alarma 1: minuto de fin | 0..59 | `0` |
| `0x08` | `ADDRESS_EN_ALA2` | `Aplicacion.h:55` | Alarma 2 habilitada | 0 / 1 | `0` |
| `0x09` | `ADDRESS_FLAGDAYALA2` | `Aplicacion.h:56` | Alarma 2 días personalizados | 0 / 1 | `0` |
| `0x0A` | `ADDRESS_DAYWEEK2` | `Aplicacion.h:57` | Alarma 2: código de días | 1..10 | `8` |
| `0x0B` | `ADDRESS_INIT_HOUR2` | `Aplicacion.h:59` | Alarma 2: hora de inicio | 0..23 | `0` |
| `0x0C` | `ADDRESS_INIT_MIN2` | `Aplicacion.h:60` | Alarma 2: minuto de inicio | 0..59 | `0` |
| `0x0D` | `ADDRESS_END_HOUR2` | `Aplicacion.h:62` | Alarma 2: hora de fin | 0..23 | `0` |
| `0x0E` | `ADDRESS_END_MIN2` | `Aplicacion.h:63` | Alarma 2: minuto de fin | 0..59 | `0` |
| `0x0F` | `ADDRESS_EN_ALA3` | `Aplicacion.h:68` | Alarma 3 habilitada | 0 / 1 | `0` |
| `0x10` | `ADDRESS_FLAGDAYALA3` | `Aplicacion.h:69` | Alarma 3 días personalizados | 0 / 1 | `0` |
| `0x11` | `ADDRESS_DAYWEEK3` | `Aplicacion.h:70` | Alarma 3: código de días | 1..10 | `8` |
| `0x12` | `ADDRESS_INIT_HOUR3` | `Aplicacion.h:72` | Alarma 3: hora de inicio | 0..23 | `0` |
| `0x13` | `ADDRESS_INIT_MIN3` | `Aplicacion.h:73` | Alarma 3: minuto de inicio | 0..59 | `0` |
| `0x14` | `ADDRESS_END_HOUR3` | `Aplicacion.h:75` | Alarma 3: hora de fin | 0..23 | `0` |
| `0x15` | `ADDRESS_END_MIN3` | `Aplicacion.h:76` | Alarma 3: minuto de fin | 0..59 | `0` |
| `0x16` | `ADDRESS_EN_ALA4` | `Aplicacion.h:81` | Alarma 4 habilitada | 0 / 1 | `0` |
| `0x17` | `ADDRESS_FLAGDAYALA4` | `Aplicacion.h:82` | Alarma 4 días personalizados | 0 / 1 | `0` |
| `0x18` | `ADDRESS_DAYWEEK4` | `Aplicacion.h:83` | Alarma 4: código de días | 1..10 | `8` |
| `0x19` | `ADDRESS_INIT_HOUR4` | `Aplicacion.h:85` | Alarma 4: hora de inicio | 0..23 | `0` |
| `0x1A` | `ADDRESS_INIT_MIN4` | `Aplicacion.h:86` | Alarma 4: minuto de inicio | 0..59 | `0` |
| `0x1B` | `ADDRESS_END_HOUR4` | `Aplicacion.h:88` | Alarma 4: hora de fin | 0..23 | `0` |
| `0x1C` | `ADDRESS_END_MIN4` | `Aplicacion.h:89` | Alarma 4: minuto de fin | 0..59 | `0` |
| `0x1D` | `ADDRESS_EN_ALA5` | `Aplicacion.h:94` | Alarma 5 habilitada | 0 / 1 | `0` |
| `0x1E` | `ADDRESS_FLAGDAYALA5` | `Aplicacion.h:95` | Alarma 5 días personalizados | 0 / 1 | `0` |
| `0x1F` | `ADDRESS_DAYWEEK5` | `Aplicacion.h:96` | Alarma 5: código de días | 1..10 | `8` |
| `0x20` | `ADDRESS_INIT_HOUR5` | `Aplicacion.h:98` | Alarma 5: hora de inicio | 0..23 | `0` |
| `0x21` | `ADDRESS_INIT_MIN5` | `Aplicacion.h:99` | Alarma 5: minuto de inicio | 0..59 | `0` |
| `0x22` | `ADDRESS_END_HOUR5` | `Aplicacion.h:101` | Alarma 5: hora de fin | 0..23 | `0` |
| `0x23` | `ADDRESS_END_MIN5` | `Aplicacion.h:102` | Alarma 5: minuto de fin | 0..59 | `0` |
| `0x24`–`0xFF` | — | — | Sin usar | — | `0xFF` (borrado) |

**El bloque de cada alarma ocupa 7 bytes y arranca en `0x01 + 7×(N−1)`.** Esa regularidad es
justo lo que permitiría sustituir las 60 líneas de `#define` de `Aplicacion.h:43-102` por una
macro de dos líneas. Ver [D34](#d34--código-duplicado-cinco-veces-en-tres-ficheros).

### 7.2 `INIT_VALUE_EEPROM 0x06` — la marca de memoria inicializada

`Aplicacion.h:40`:

```c
#define INIT_VALUE_EEPROM       0X06
```

El mecanismo está en `ST_READ_MEMO_AP` (`Aplicacion.c:83-157`):

```c
memo.ucInitMemory = EEpromRead(ADDRESS_INIT_EEPROM);   // Aplicacion.c:92

if(memo.ucInitMemory != INIT_VALUE_EEPROM)             // Aplicacion.c:94
{
    EEpromWrite(ADDRESS_INIT_EEPROM, INIT_VALUE_EEPROM);
    twoBeep();
    // ... 35 escrituras más, Aplicacion.c:99-137 ...
    cambiarEstado(ST_READ_MEMO_AP);                    // Aplicacion.c:139 — se relee
}
else
{
    readMemoriaValues();                               // Aplicacion.c:144
    ala.flagUpdate = true;
    transmitUart1("\n\rBALIZA ALARMA V1.0\n\r\n\r");
    cambiarEstado(ST_ESPERA_AP);                       // Aplicacion.c:152
}
```

**Qué hace.** Es un "número mágico" de formateo. Un PIC virgen tiene la EEPROM a `0xFF`, que es
distinto de `0x06`, así que la primera vez el firmware escribe los valores por defecto de las cinco
alarmas (todas deshabilitadas, días = 8 = diario, horas a 00:00) y marca la celda `0x00` con `0x06`.
En los arranques siguientes la marca coincide y se lee la configuración guardada.

Después de inicializar, `Aplicacion.c:139` vuelve a entrar en `ST_READ_MEMO_AP`, lo que reinicia
el contador de 200 ciclos (`Aplicacion.c:90`) y en la segunda pasada, ya con la marca correcta,
cae por la rama `else`. El usuario oye **dos series de dos pitidos** (`Aplicacion.c:78` en el
arranque y `Aplicacion.c:97` al formatear) la primera vez que enciende un equipo nuevo, y solo una
serie en los arranques posteriores. Es el único indicio externo de que se ha formateado la memoria.

**Qué pasa si se cambia `INIT_VALUE_EEPROM`.** Es el mecanismo de migración de datos del firmware:
al cambiar el valor (por ejemplo a `0x07`), el siguiente arranque de un equipo ya en campo detecta
que la marca no coincide y **borra toda la configuración de alarmas del usuario**, dejándola en los
valores por defecto. Es la forma de forzar un reformateo cuando se cambia la disposición de la
EEPROM en una versión nueva. **Hay que hacerlo obligatoriamente si se añaden campos o se mueven
direcciones**, o el equipo interpretará datos viejos con el mapa nuevo.

> **Debilidad:** con solo un byte de marca, la probabilidad de que una EEPROM de un chip reutilizado
> (o corrompida por un brown-out) contenga por casualidad `0x06` en la dirección `0x00` es de
> 1/256. En ese caso el firmware **no formatea** y arranca con las 35 celdas restantes a basura.
> Un valor de basura en `ADDRESS_FLAGDAYALAn` dispara el defecto
> [D03](#d03--las-ramas-de-días-personalizados-están-vacías-y-congelan-la-máquina-de-estados).
> Una marca de 2 o 4 bytes, o un checksum de los 36 bytes, eliminaría el riesgo.

### 7.3 Codificación de los días

Definida en `Alarma.h:13-23`:

| Valor | Macro | Significado | ¿Implementado? |
|---|---|---|---|
| 1 | `LUNE` | Lunes | Solo como valor de `rtc.dayWeek`, no como selección de alarma |
| 2 | `MART` | Martes | idem |
| 3 | `MIER` | Miércoles | idem |
| 4 | `JUEV` | Jueves | idem |
| 5 | `VIER` | Viernes | idem |
| 6 | `SABA` | Sábado | idem |
| 7 | `DOMI` | Domingo | idem |
| **8** | `DIAR` | **Diariamente** | ✅ `Alarma.c:205-208` |
| **9** | `SEMA` | **Lunes a viernes** | ✅ `Alarma.c:210-221` |
| **10** | `FINS` | **Fin de semana** (sábado y domingo) | ✅ `Alarma.c:223-234` |

**Los valores 1..7 son días concretos y NO están implementados como selección de alarma.** El
diseño previsto era:

- `flagDayAlar = 0` → el campo `dayAlar` contiene 8, 9 o 10 (un "grupo" de días).
- `flagDayAlar = 1` → alarma "personalizada": los días individuales estarían en
  `srtAlarmas.bufferDayAlar[8]` (`Alarma.h:59`, comentario *"1,2,3,4,5,6,7"*).

Pero `bufferDayAlar` **no se escribe ni se lee en ningún punto del firmware** (única aparición:
`Alarma.h:59`), no hay dirección de EEPROM reservada para él, y las ramas que lo usarían están
vacías tanto en `Serial.c` (`:289-292`, `:320-323`, `:350-353`, `:380-383`, `:409-412`) como en
`Alarma.c` (`:241-245`, `:286-289`, `:329-332`, `:372-375`, `:415-418`).

La app Android tampoco ofrece la opción: su selector solo tiene tres entradas
(`MainActivity2.java:101`: `{"Diario", "Lun-Vie", "Sab-Dom"}`) mapeadas a 8, 9 y 10 en
`MainActivity2.java:203-205`. Y `Serial.c:274` solo acepta valores en el rango
`(ulDayAlarm > 7) && (ulDayAlarm < 11)`, o sea 8, 9 y 10; cualquier otro cae en el `else` vacío y
**no se escribe nada en EEPROM**, con lo que la alarma queda con `flagAlarm = true` en RAM pero sin
respaldo persistente — un estado incoherente que desaparece en el siguiente arranque.

En resumen: **la personalización por días concretos está diseñada a medias y es código muerto
peligroso**, no una funcionalidad disponible.

### 7.4 Cómo se escribe y cómo se lee

**Escritura** — `EEpromWrite()`, `EEprom.c:8-26`. Se llama desde dos sitios:
`Aplicacion.c:96-137` (formateo inicial, 36 escrituras seguidas) y `Serial.c:231-407` (al
configurar una alarma, 1 o 7 escrituras). Cada escritura de EEPROM del PIC18 tarda unos 4 ms y la
función espera activamente (`EEprom.c:23`), así que un formateo completo bloquea la tarea de
aplicación **unos 150 ms**. Ver [D11](#d11--eepromwrite-reactiva-gie-de-forma-incondicional).

**Lectura** — `EEpromRead()`, `EEprom.c:29-38`:

```c
EEADR = address;
EECON1bits.EEPGD = 0;
EECON1bits.CFGS = 0;
EECON1bits.RD = 1;
return EEDATA;
```

Puede llamar la atención que devuelva `EEDATA` inmediatamente sin esperar. **Es correcto**: el
datasheet del PIC18F2550 (sección de EEPROM de datos) especifica que la lectura de EEPROM de datos
se completa en un ciclo y que `EEDATA` es válido en la instrucción siguiente a poner `RD = 1`; el
propio ejemplo en ensamblador del fabricante hace `BSF EECON1, RD` seguido de `MOVF EEDATA, W`.
Solo las lecturas de **memoria de programa** (`EEPGD = 1`) requieren dos `NOP`. No es un defecto.

`readMemoriaValues()` (`Aplicacion.c:353-409`) hace **35 lecturas** consecutivas y se invoca tanto
en el arranque (`Aplicacion.c:144`) como cada vez que llega una trama de alarma
(`Aplicacion.c:186`), lo que es aceptable dado el coste despreciable de la lectura.

---

## 8. Lógica de alarmas

### 8.1 Cadena completa: del RTC al cluster

```mermaid
flowchart TD
    A["DS1307 por I2C<br/>leerRTC / leerRtcSeg<br/>DS1307.c:19-58"] --> B["struct rtc<br/>hor, min, seg, dayWeek<br/>DS1307.c:9"]
    C["EEPROM 0x00-0x23"] --> D["readMemoriaValues<br/>Aplicacion.c:353-409"]
    D --> E["struct memo<br/>Aplicacion.c:46"]
    E -->|"ala.flagUpdate<br/>ST_UPDATE_ALA<br/>Alarma.c:59-102"| F["ala1..ala5<br/>srtAlarmas<br/>Alarma.c:24-28"]
    B --> G["ST_CHECK_ALARMn<br/>filtro por dia<br/>Alarma.c:201-419"]
    F --> G
    G --> H["ST_CHECK_HOURn<br/>comparacion hora:minuto<br/>Alarma.c:421-557"]
    H -->|"hor==hourInit y min==minInit"| I["ap.flagAlarm = true"]
    H -->|"hor==hourEnd y min==minEnd"| J["ap.flagAlarm = false"]
    I --> K["ST_ESPERA_AP<br/>Aplicacion.c:197-204"]
    J --> K
    K --> L["cl.flagEvento"]
    L --> M["taskCluster<br/>rafaga de 5 destellos<br/>Cluster.c:45-93"]
    M --> N["LATC2 -> Q2 -> lampara"]
    M --> O["oneBeep -> LATC0"]
```

### 8.2 Paso 1 — De la EEPROM a `ala1..ala5`

`ST_UPDATE_ALA` (`Alarma.c:59-102`) copia los 35 campos de `memo` a las cinco estructuras
`srtAlarmas`. Se dispara con `ala.flagUpdate`, que se levanta en dos sitios:

- `Aplicacion.c:145`, tras leer la EEPROM en el arranque.
- `Aplicacion.c:187`, tras recibir una trama de configuración de alarma.

La transición ocurre en `Alarma.c:123-127`, pero **solo si en esa visita a `ST_ESPERA_ALA` no se
han cumplido antes las condiciones de `uiCnt >= 50` ni `uiCnt2 >= 20`**, por estar en la misma
cadena `else if`. Como esas condiciones fallan 18 de cada 20 visitas, la actualización llega en
menos de 30 ms. No es un problema, pero es una dependencia sutil.

### 8.3 Paso 2 — Filtro por día: `ST_CHECK_ALARMn`

Para la alarma 1 (`Alarma.c:201-246`; las otras cuatro son copias literales):

```c
if(!ala1.flagDayAlar)                       // Alarma.c:203 — días NO personalizados
{
    if(ala1.dayAlar == DIAR)                // == 8  → siempre
        stateAlarm = ST_CHECK_HOUR1;
    else if(ala1.dayAlar == SEMA)           // == 9  → lunes a viernes
        stateAlarm = (rtc.dayWeek >= LUNE && rtc.dayWeek <= VIER)
                     ? ST_CHECK_HOUR1 : ST_ESPERA_ALA;
    else if(ala1.dayAlar == FINS)           // == 10 → sábado o domingo
        stateAlarm = (rtc.dayWeek == SABA || rtc.dayWeek == DOMI)
                     ? ST_CHECK_HOUR1 : ST_ESPERA_ALA;
    else
        stateAlarm = ST_ESPERA_ALA;         // Alarma.c:235-238 — valor inválido
}
else
{
    // Alarma.c:241-245 — VACÍO, sin asignación de estado
}
```

La rama `else` final (`Alarma.c:235-238`) sí protege contra un `dayAlar` corrupto. **La rama de
días personalizados (`Alarma.c:241-245`) no protege nada: no asigna estado.** Es el defecto
[D03](#d03--las-ramas-de-días-personalizados-están-vacías-y-congelan-la-máquina-de-estados).

### 8.4 Paso 3 — Comparación horaria: `ST_CHECK_HOURn`

`Alarma.c:421-447` para la alarma 1 (las otras cuatro, idénticas):

```c
if(rtc.hor == ala1.hourInit)
    if(rtc.min == ala1.minInit)
        ap.flagAlarm = true;      // Alarma.c:429

if(rtc.hor == ala1.hourEnd)
    if(rtc.min == ala1.minEnd)
        ap.flagAlarm = false;     // Alarma.c:440

stateAlarm = ST_ESPERA_ALA;       // Alarma.c:445
```

Cuatro observaciones estructurales:

1. **Es una comparación por igualdad exacta, no por pertenencia a un intervalo.** El firmware no
   pregunta "¿estoy dentro de la franja?" sino "¿es este el minuto exacto en que empieza / acaba?".
   Es un detector de flanco, no un comparador de rango. Consecuencias en
   [D07](#d07--comparación-de-alarmas-por-igualdad-exacta-de-hora-y-minuto).
2. **Los dos `if` son independientes, no `else if`.** Si el inicio y el fin son el mismo minuto,
   ambos se ejecutan en la misma pasada y gana el segundo: la alarma queda apagada. Una franja de
   longitud cero se comporta correctamente por accidente.
3. **`ap.flagAlarm` es un único bit compartido por las cinco alarmas** (`Aplicacion.h:115`). No hay
   estado por alarma. Ver [D06](#d06--flagalarm-es-una-única-bandera-para-las-cinco-alarmas).
4. **Ninguna alarma "recuerda" que está activa.** El estado activo vive exclusivamente en
   `ap.flagAlarm`, que no se guarda en EEPROM ni se reconstruye a partir del reloj.

### 8.5 Paso 4 — De `ap.flagAlarm` a `cl.flagEvento`

`ST_ESPERA_AP`, `Aplicacion.c:197-204`:

```c
else if(ap.flagAlarm)
{
    cl.flagEvento = true;
}
else
{
    cl.flagEvento = false;
}
```

Se evalúa cada 10,24 ms. Es una copia continua, no un flanco: mientras `ap.flagAlarm` esté
levantada, `cl.flagEvento` se vuelve a poner a `true` inmediatamente después de que la tarea del
cluster lo baje en `Cluster.c:91`, lo que hace que las ráfagas se encadenen sin fin.

Recuérdese que está en la misma cadena `else if` que los tres eventos serie y que el contador de
tensión (`Aplicacion.c:172-194`): en el ciclo en que se atiende un evento serie o se lanza una
lectura de tensión, `cl.flagEvento` no se refresca. Al ser un ciclo aislado de 10 ms y estar el
cluster en mitad de una ráfaga, no se aprecia.

### 8.6 Paso 5 — El patrón del cluster

Detallado en [§5.4](#54-tarea-cluster--clusterc29-98). Resumen del comportamiento observable
cuando `ap.flagAlarm` está levantada:

| Tramo | Duración | `LATC2` | Buzzer |
|---|---|---|---|
| Destello 1 | ~51 ms ON + ~51 ms OFF | conmuta | pitido de ~51 ms al inicio de la ráfaga |
| Destellos 2..5 | 4 × (~51 ms ON + ~51 ms OFF) | conmuta | — |
| Pausa larga | ~512 ms | OFF | — |
| **Ciclo completo** | **~1,024 s** | | **1 pitido por ciclo** |

Y este ciclo se repite **durante toda la franja horaria**. En una franja de 08:30 a 17:45 son
9 h 15 min = **unos 33 300 ciclos**, es decir 33 300 pitidos y 166 500 destellos.
Ver [D14](#d14--el-zumbador-pita-una-vez-por-segundo-durante-toda-la-franja).

### 8.7 Qué pasa al terminar la franja

Cuando `ST_CHECK_HOURn` detecta el minuto de fin, `ap.flagAlarm` baja, `Aplicacion.c:203` pone
`cl.flagEvento = false` y la tarea del cluster apaga la salida **en cuanto vuelva a
`ST_ESPERA_CL`** (`Cluster.c:54`). Si en ese instante estaba a mitad de una ráfaga, **termina la
ráfaga en curso** (hasta ~1 s más) antes de apagarse definitivamente. Es un retardo aceptable.

---

## 9. Defectos y riesgos encontrados

Se han identificado **45 defectos**: 5 críticos, 11 altos, 18 medios y 11 bajos.
Cada uno lleva su referencia `archivo:línea`. Ningún defecto de esta lista es una suposición: todos
se pueden verificar abriendo el fichero indicado.

### 9.1 Tabla resumen

| ID | Gravedad | Defecto | Ubicación |
|---|---|---|---|
| [D01](#d01--el-firmware-usa-rc0-como-buzzer-pero-el-esquemático-dice-que-rc0-es-el-pulsador) | 🔴 Crítico | Buzzer en RC0 mientras el esquemático asigna RC0 al pulsador y RC1 al buzzer | `Buzzer.h:24-25`, `Buzzer.c:162-163` |
| [D02](#d02--sin-watchdog-y-con-esperas-bloqueantes-sin-timeout) | 🔴 Crítico | Sin watchdog y con cuatro esperas bloqueantes sin timeout | `main.h:28`, `I2C.c:26`, `EEprom.c:23`, `Serial.c:64`, `main.c:192` |
| [D03](#d03--las-ramas-de-días-personalizados-están-vacías-y-congelan-la-máquina-de-estados) | 🔴 Crítico | Ramas de días personalizados vacías: la máquina de estados se congela sin salida | `Alarma.c:241-245`, `:286-289`, `:329-332`, `:372-375`, `:415-418` |
| [D04](#d04--desbordamiento-de-buffer-en-extraervalue-y-extraerframe) | 🔴 Crítico | Desbordamiento de buffer en `extraerValue`/`extraerFrame` y `strstr` sin comprobar NULL | `Serial.c:462-467`, `:484-489` |
| [D05](#d05--receiveruart1-escribe-en-el-buffer-sin-comprobar-el-límite) | 🔴 Crítico | `receiverUart1` escribe sin comprobar el límite del buffer de 40 bytes | `Serial.c:76` |
| [D06](#d06--flagalarm-es-una-única-bandera-para-las-cinco-alarmas) | 🟠 Alto | `ap.flagAlarm` única para 5 alarmas: el fin de una apaga la franja de otra | `Aplicacion.h:115`, `Alarma.c:429/440` y 4 copias |
| [D07](#d07--comparación-de-alarmas-por-igualdad-exacta-de-hora-y-minuto) | 🟠 Alto | Comparación por igualdad exacta: si arranca dentro de la franja, no enciende | `Alarma.c:424-443` y 4 copias |
| [D08](#d08--carrera-entre-el-reset-del-wrap-y-la-asignación-del-vencimiento) | 🟠 Alto | Carrera entre el reset del wrap y la asignación del vencimiento: tarea bloqueada 61 s | `main.c:58-73` vs. `Serial.c:96`, `Alarma.c:46`, etc. |
| [D09](#d09--lectura-no-atómica-de-ulcnttick1ms) | 🟠 Alto | Lectura no atómica de `ulCntTick1ms` de 32 bits | `TimeBase.c:17` vs. `main.c:58` |
| [D10](#d10--memset-con-strlen-sobre-buffers-locales-sin-inicializar) | 🟠 Alto | `memset` con `strlen()` sobre buffers locales sin inicializar | `Aplicacion.c:338`, `:347` |
| [D11](#d11--eepromwrite-reactiva-gie-de-forma-incondicional) | 🟠 Alto | `EEpromWrite` reactiva `GIE` incondicionalmente | `EEprom.c:16`, `:21` |
| [D12](#d12--isr-de-baja-prioridad-con-printf-y-un-retardo-de-4-segundos) | 🟠 Alto | ISR de baja prioridad con dos `printf` y `__delay_ms(4000)` | `main.c:92-101` |
| [D13](#d13--off-by-one-en-el-bucle-de-copia-del-buffer-de-recepción) | 🟠 Alto | Off-by-one `i <= SIZE_BUFFER_RX1` en la copia del buffer | `Serial.c:126` |
| [D14](#d14--el-zumbador-pita-una-vez-por-segundo-durante-toda-la-franja) | 🟠 Alto | El zumbador pita ~1 vez/segundo durante horas | `Cluster.c:49` |
| [D15](#d15--sin-brown-out-reset-con-escrituras-de-eeprom) | 🟠 Alto | Sin brown-out reset habiendo escrituras de EEPROM | `main.h:23` |
| [D16](#d16--ningún-switch-de-estados-tiene-rama-default) | 🟠 Alto | Ningún `switch` de estados tiene `default:` | 6 tareas |
| [D17](#d17--el-tick-no-es-de-1-ms-sino-de-1024-ms) | 🟡 Medio | El tick es de 1,024 ms, no de 1 ms | `main.c:53`, `:163` |
| [D18](#d18--baudrate-136--desviado-teniendo-el-valor-correcto-en-el-mismo-fichero) | 🟡 Medio | Baudrate −1,36 % teniendo el valor exacto en el mismo fichero | `UART.h:26`, `:34` vs. `:13-14` |
| [D19](#d19--efecto-lateral-de-uicnt2-dentro-de-un-else-if) | 🟡 Medio | Efecto lateral `++ala.uiCnt2` dentro de un `else if` | `Alarma.c:118` |
| [D20](#d20--transmituart1-envía-un-byte-nulo-de-más-en-cada-cadena) | 🟡 Medio | `transmitUart1` envía un `0x00` de más en cada cadena | `Serial.c:61` |
| [D21](#d21--an3-se-lee-por-adc-pero-pcfg-lo-deja-como-digital) | 🟡 Medio | AN3 se lee por ADC pero `PCFG=1011` lo deja digital | `main.c:175`, `Aplicacion.c:227` |
| [D22](#d22--tad-y-tacq-del-adc-fuera-de-especificación) | 🟡 Medio | `TAD` y `TACQ` del ADC fuera de especificación a 20 MHz | `main.c:177-178` |
| [D23](#d23--medidas-de-tensión-y-temperatura-calculadas-y-nunca-usadas) | 🟡 Medio | Tensión y temperatura calculadas y nunca usadas; `ST_READ_TEMP_AP` inalcanzable | `Aplicacion.c:208-236` |
| [D24](#d24--ala1ala5-y-ap-definidas-dos-veces-sin-extern) | 🟡 Medio | `ala1..ala5` y `ap` definidas dos veces sin `extern` | `Serial.c:22-26` / `Alarma.c:24-28`; `LedLive.c:19` / `Aplicacion.c:45` |
| [D25](#d25--cleanbuffer-usa-strlen-para-el-memset) | 🟡 Medio | `cleanBuffer()` usa `strlen()` para el `memset` | `Aplicacion.c:282` |
| [D26](#d26--clusterh-y-eepromh-sin-guarda-de-inclusión) | 🟡 Medio | `Cluster.h` y `EEprom.h` sin guarda de inclusión | `Cluster.h:1`, `EEprom.h:1` |
| [D27](#d27--alaucCntcheck-sin-saneamiento) | 🟡 Medio | `ala.ucCntCheck` sin saneamiento: se cuelga 2,5 s si se sale de rango | `Alarma.c:131-188` |
| [D28](#d28--el-bit-ch-del-ds1307-nunca-se-limpia-en-el-arranque) | 🟡 Medio | El bit CH del DS1307 nunca se limpia en el arranque | `DS1307.c` (ausencia) |
| [D29](#d29--delimitador-de-inicio-no-ascii-y-dependiente-de-la-codificación) | 🟡 Medio | Delimitador de inicio no ASCII y dependiente de la codificación del fichero | `Serial.h:27` |
| [D30](#d30--no-hay-acuse-de-recibo-de-la-configuración) | 🟡 Medio | No hay acuse de recibo de la configuración | `Aplicacion.c:178-189` |
| [D31](#d31--dos-tramas-en-la-misma-ráfaga-la-segunda-se-pierde) | 🟡 Medio | Dos tramas pegadas en una ráfaga: la segunda se pierde en silencio | `Serial.c:160-220` |
| [D32](#d32--apbuffertx45-con-un-solo-byte-de-margen) | 🟡 Medio | `ap.bufferTx[45]` con un solo byte de margen en el peor caso | `Aplicacion.c:330` |
| [D33](#d33--pulsador-físico-sin-soporte-en-firmware) | 🟡 Medio | Pulsador físico `SW1` sin soporte en firmware | `main.c:65`, `Aplicacion.c:35` (comentados) |
| [D34](#d34--código-duplicado-cinco-veces-en-tres-ficheros) | 🟡 Medio | Código duplicado 5 veces: ~690 líneas evitables | `Serial.c`, `Alarma.c`, `Aplicacion.c/h` |
| [D35](#d35--include-con-punto-y-coma) | 🔵 Bajo | `#include "stdlib.h";` con punto y coma | `Serial.c:12` |
| [D36](#d36--sentencia-sin-efecto-orig) | 🔵 Bajo | Sentencia sin efecto `*orig++;` | `Serial.c:549` |
| [D37](#d37--funciones-static-declaradas-en-cabeceras) | 🔵 Bajo | Funciones `static` declaradas en cabeceras | 6 ficheros `.h` |
| [D38](#d38--variables-y-campos-muertos) | 🔵 Bajo | Variables y campos de estructura muertos | `Aplicacion.c:50`, `Aplicacion.h:112-121`, etc. |
| [D39](#d39--funciones-y-variables-muertas) | 🔵 Bajo | Funciones nunca llamadas: `alarmBeep`, `cancelBeep`, `endBeep`, `UART_init`, `UART_printf` | `Buzzer.c:144-158`, `UART.h:6-18`, `:69-76` |
| [D40](#d40--srtalarmas-está-mal-escrito) | 🔵 Bajo | `srtAlarmas` mal escrito (debería ser `str`) | `Alarma.h:66` |
| [D41](#d41--unsigned-long-para-un-contador-que-nunca-pasa-de-60000) | 🔵 Bajo | `unsigned long` para un contador que nunca pasa de 60000 | `main.c:39` |
| [D42](#d42--variable-local-que-sombrea-la-global-rtc) | 🔵 Bajo | Variable local `rtc[7]` que sombrea la global `rtc` | `DS1307.c:35` vs. `:9` |
| [D43](#d43--carreras-menores-entre-la-isr-y-la-tarea-de-uart) | 🔵 Bajo | Carreras menores entre la ISR y la tarea de UART | `main.c:82-84` vs. `Serial.c:118-137` |
| [D44](#d44--i2c-sin-comprobación-de-ackstat) | 🔵 Bajo | I2C sin comprobación de `ACKSTAT`: un DS1307 ausente no se detecta | `I2C.c:44-47` |
| [D45](#d45--lc-switch-impide-poner-esperas-dentro-del-switch-de-estados) | 🔵 Bajo | `lc-switch` impide poner esperas dentro del `switch` de estados | `Rtos/lc-switch.h:60-61` |

---

### 9.2 Defectos críticos

#### D01 — El firmware usa RC0 como buzzer, pero el esquemático dice que RC0 es el pulsador

**Qué pasa.** El firmware configura y controla el zumbador en **RC0**:

```c
// Buzzer.h:24-25
#define ON_BUZZER       LATCbits.LATC0 = 1
#define OFF_BUZZER      LATCbits.LATC0 = 0

// Buzzer.c:160-167
void pinConfBuzzer(void)
{
    //TRISCbits.TRISC1 = 0;      ← línea 162, COMENTADA
    TRISCbits.TRISC0 = 0;        ← línea 163, activa
}
```

El esquemático `balizaSR30.kicad_sch` asigna esos dos pines al revés:

| Pin | Etiqueta de red | Conectado a |
|---|---|---|
| 11 (RC0) | `BUTTON` | `SW1 = SW_Push` |
| 12 (RC1) | `BUZZER` | `R11 = 2.2k` → base de `Q4 = MMBT3904` → `BZ1 = Buzzer` |

(Verificado midiendo la distancia entre el extremo de cada pin del símbolo del PIC y las etiquetas
de red: `BUTTON` está a 9,14 mm exactos de RC0 y `BUZZER` a 9,14 mm exactos de RC1, la misma
distancia que presentan todas las demás correspondencias confirmadas como `MCU_TX`↔RC6 o
`CLUSTER`↔RC2.)

La línea comentada en `Buzzer.c:162` es la huella de que el zumbador **estuvo** en RC1 y alguien lo
movió a RC0 sin borrar la línea vieja.

**Por qué es un problema real para el usuario.**

1. **El zumbador no suena.** Si `TRISC1` nunca se pone a 0, RC1 queda como entrada de alta
   impedancia y la base de `Q4` no recibe señal. Todos los avisos acústicos del equipo (arranque,
   confirmación de comandos, aviso de alarma) desaparecen.
2. **Riesgo de daño en el pin del microcontrolador.** `TRISC0 = 0` convierte en salida el nodo al
   que está conectado el pulsador. Cada `oneBeep()` pone `LATC0 = 1`. Si el usuario pulsa `SW1`
   mientras el pin está en alto, el driver de salida del PIC queda cortocircuitado a masa a través
   del contacto. Y `oneBeep()` se llama desde `Cluster.c:49` **una vez por segundo durante toda la
   franja horaria**, así que la probabilidad de coincidencia es alta.
3. La configuración de alarmas también dispara `oneBeep()` (`Aplicacion.c:175`, `:181`, `:188`),
   que es precisamente cuando el usuario tiene el equipo delante y puede estar pulsando el botón.

**Nota de fechas.** El firmware es de 2022 y los gerbers de la placa son de **2025-06-24**. Es
plausible que el hardware cambiara la asignación y el firmware del repositorio se quedara atrás, o
que la placa fabricada lleve una modificación no reflejada. **Antes de tocar nada hay que verificar
con un polímetro sobre la placa física.** Ver [pregunta abierta P1](#21-preguntas-abiertas).

**Cómo se arregla.** Si el esquemático es el correcto:

```c
// Buzzer.h:24-25
#define ON_BUZZER       LATCbits.LATC1 = 1
#define OFF_BUZZER      LATCbits.LATC1 = 0

// Buzzer.c:160-167
void pinConfBuzzer(void)
{
    TRISCbits.TRISC1 = 0;    // buzzer como salida
    LATCbits.LATC1  = 0;
    TRISCbits.TRISC0 = 1;    // pulsador como entrada (nunca como salida)
}
```

Atención: `CCP2MX = ON` (`main.h:32`) multiplexa CCP2 sobre RC1, pero como el módulo CCP nunca se
habilita, RC1 queda libre para uso como E/S digital. No hay conflicto.

---

#### D02 — Sin watchdog y con esperas bloqueantes sin timeout

**Qué pasa.** `main.h:28` deshabilita el perro guardián:

```c
#pragma config WDT = OFF
```

y el firmware contiene al menos **cuatro bucles de espera activa sin límite de tiempo**:

| Espera | Ubicación | Qué la puede bloquear para siempre |
|---|---|---|
| `while( (SSPCON2 & 0b00011111) \|\| (SSPSTAT & 0b00000100) );` | `I2C.c:26` | SDA o SCL enclavadas a bajo (DS1307 colgado, pila agotada con el chip en estado indefinido, cable/pista rota, ruido durante una transferencia) |
| `while(!PIR2bits.EEIF);` | `EEprom.c:23` | Escritura de EEPROM que no completa |
| `while(TXSTAbits.TRMT == 0);` | `Serial.c:64` y `UART.h:66` | Fallo del transmisor UART |
| `while(ADCON0bits.GO_DONE);` | `main.c:192` | Conversión ADC que no termina |

La más peligrosa con diferencia es la de I2C: `I2C_Master_Wait()` se llama desde las seis funciones
del módulo (`I2C.c:30`, `:35`, `:40`, `:45`, `:51`, `:53`, `:55`) y por tanto **en cada uno de los
7 accesos** de `leerRTC()` (`DS1307.c:39-48`), que se ejecutan cada ~530 ms.

**Por qué es un problema real para el usuario.** Un glitch en el bus I2C —que es un bus de dos
hilos con resistencias de pull-up de 4,7 kΩ (`R5`, `R6`) y sin blindaje— basta para dejar el
microcontrolador atascado dentro de un `while` vacío. En ese momento:

- las seis tareas dejan de ejecutarse, porque el bucle de `main.c:132-140` está detenido;
- el LED de latido se congela (encendido o apagado, según el instante);
- **la salida del cluster se queda tal como estuviera: apagada en mitad de una franja, o encendida
  y sin apagarse nunca**;
- el equipo no responde por Bluetooth;
- **y no se recupera solo**: hace falta un corte de alimentación manual.

Para un dispositivo pensado para funcionar desatendido meses seguidos, esto es la diferencia entre
un fallo transitorio de un segundo y una avería que requiere desplazamiento.

**Cómo se arregla.** Dos medidas complementarias:

1. **Habilitar el watchdog.** Cambiar `main.h:28` a `#pragma config WDT = ON` con un postscaler
   razonable (`WDTPS = 512` da unos 2 s con el oscilador RC del WDT) y añadir un `CLRWDT()` en el
   bucle principal, `main.c:139` (una sola vez por vuelta, nunca dentro de las esperas, para que el
   watchdog cumpla su función).
2. **Poner timeout a las esperas.** Convertir `I2C_Master_Wait()` en:

```c
unsigned char I2C_Master_Wait(void)   // devuelve 0 = OK, 1 = timeout
{
    unsigned int guard = 0;
    while( (SSPCON2 & 0b00011111) || (SSPSTAT & 0b00000100) )
    {
        if(++guard > 10000) return 1;   // ~10 ms a 20 MHz
    }
    return 0;
}
```

y propagar el error hasta `leerRTC()` para que la tarea de alarma pueda decidir qué hacer (por
ejemplo, mantener el último valor válido y encender un código de parpadeo de diagnóstico en el LED).

---

#### D03 — Las ramas de días personalizados están vacías y congelan la máquina de estados

**Qué pasa.** En las cinco copias del estado `ST_CHECK_ALARMn` de `Alarma.c`, la rama que atiende
el caso `flagDayAlar == true` está vacía:

| Alarma | Estado | Rama vacía |
|---|---|---|
| 1 | `ST_CHECK_ALARM1` | `Alarma.c:241-245` |
| 2 | `ST_CHECK_ALARM2` | `Alarma.c:286-289` |
| 3 | `ST_CHECK_ALARM3` | `Alarma.c:329-332` |
| 4 | `ST_CHECK_ALARM4` | `Alarma.c:372-375` |
| 5 | `ST_CHECK_ALARM5` | `Alarma.c:415-418` |

```c
// Alarma.c:241-245
else
{
    //NO IMPLEMENTADO
    //si la alarma es personalizada
}
break;
```

**Qué le pasa a la tarea: sí, se cuelga la máquina de estados, y de forma irrecuperable.**

`stateAlarm` no se modifica en esa rama. Como el `switch` está dentro del `while(1)` del
protothread (`Alarma.c:44-559`), la tarea vuelve a entrar en el **mismo** `ST_CHECK_ALARMn` en el
siguiente periodo de 10,24 ms, evalúa la misma condición, vuelve a no hacer nada, y así
indefinidamente. La tarea de alarma queda viva —consume su ciclo, no bloquea a las demás— pero
**inútil**:

1. **No se vuelve a leer el RTC nunca.** `ST_UPDATE_SEG_ALA` y `ST_UPDATE_VALUE_ALA` solo se
   alcanzan desde `ST_ESPERA_ALA` (`Alarma.c:105-116`), que ya no se visita. `rtc.hor` y `rtc.min`
   se quedan congelados con el último valor leído.
2. **No se evalúa ninguna alarma más**, ni la que causó el atasco ni las otras cuatro.
   `ST_CHECK_ALL_ALA` tampoco se vuelve a alcanzar.
3. **`ap.flagAlarm` se queda con el valor que tuviera.** Si estaba a `false`, la baliza nunca más se
   enciende. Si estaba a `true`, **la baliza destella y pita ininterrumpidamente para siempre**.
4. **No se puede recuperar por Bluetooth.** `ala.flagUpdate` se atiende en `Alarma.c:123-127`,
   dentro de `ST_ESPERA_ALA`, que ya no se visita. Reprogramar las alarmas desde la app escribe la
   EEPROM y levanta la bandera, pero nadie la lee.
5. **Ni siquiera se recupera con un reinicio**, porque `flagDayAlar` viene de la EEPROM
   (`Aplicacion.c:356` → `Alarma.c:61`), así que al siguiente arranque se repite el atasco. Es un
   **ladrillo funcional permanente** hasta que se reprograme la EEPROM con un programador físico.

**¿Cómo puede llegar `flagDayAlar` a valer 1?** En operación normal no puede: `Aplicacion.c:100`
(y sus cuatro hermanas) escriben `0` al formatear, y `Serial.c:282` (y sus cuatro hermanas)
escriben `0` al configurar una alarma. Las vías reales de exposición son:

- **PIC reutilizado o EEPROM no virgen** cuya dirección `0x00` contenga por casualidad `0x06`: el
  firmware no formatea (ver [§7.2](#72-init_value_eeprom-0x06--la-marca-de-memoria-inicializada))
  y `ADDRESS_FLAGDAYALAn` conserva basura. Probabilidad ≈ 1/256 por unidad.
- **Corrupción de EEPROM por brown-out durante una escritura**, que es exactamente lo que
  [D15](#d15--sin-brown-out-reset-con-escrituras-de-eeprom) hace probable.
- Cualquier evolución futura del firmware o de la app que empiece a usar el campo.

Es un defecto **latente pero catastrófico**: baja probabilidad por unidad, consecuencia total y sin
autorrecuperación.

**Cómo se arregla.** Mínimo imprescindible — que la rama tenga siempre una salida:

```c
else
{
    // días personalizados: no implementado, tratar como "no coincide"
    stateAlarm = ST_ESPERA_ALA;
}
```

y añadir un `default:` al `switch` (ver [D16](#d16--ningún-switch-de-estados-tiene-rama-default)).
Adicionalmente, sanear el valor al leerlo de EEPROM en `readMemoriaValues()`:

```c
memo.ucflagDayAla1 = (EEpromRead(ADDRESS_FLAGDAYALA1) == 1) ? 1 : 0;
```

y hacer lo mismo con `ucDayWeekN`, forzando a `DIAR` cualquier valor fuera de 8..10.

---

#### D04 — Desbordamiento de buffer en `extraerValue` y `extraerFrame`

**Qué pasa.** Las dos funciones de extracción de campos copian desde el buffer de recepción hasta
encontrar el carácter terminador, **sin comprobar en ningún momento el tamaño del destino ni el
final de la cadena origen**.

```c
// Serial.c:453-472
unsigned char extraerValue(char* orig, char* init, char* end)
{
    unsigned char value = 0;
    char* ptrData;
    char buffer[4];              // ← Serial.c:457, sólo 4 bytes, en la pila
    char cnt = 0;

    memset(buffer, 0x00, sizeof(buffer));
    ptrData = strstr(orig, init);                       // ← Serial.c:462, sin comprobar NULL

    for(ptrData = ptrData + 1; *ptrData != *end; ptrData++)   // ← Serial.c:464
    {
        buffer[cnt++] = *ptrData;                       // ← Serial.c:466, sin límite
    }
    value = atoi(buffer);
    return value;
}
```

```c
// Serial.c:474-493
void extraerFrame(char* orig, char*dest, char* init, char* end)
{
   char* ptrData;
   char cnt = 0;
   char buffer[10];              // ← Serial.c:479, sólo 10 bytes, en la pila

   memset(dest, 0x00, strlen(dest));                    // ← Serial.c:481, ver D25
   memset(buffer, 0x00, sizeof(buffer));

   ptrData = strstr(orig, init);                        // ← Serial.c:484, sin comprobar NULL

    for(ptrData = ptrData + 1; *ptrData != *end; ptrData++)   // ← Serial.c:486
    {
        buffer[cnt++] = *ptrData;                       // ← Serial.c:488, sin límite
    }
   memcpy(dest, buffer, strlen(buffer));
}
```

**Tres fallos independientes en el mismo bucle:**

1. **Sin control de tamaño del destino.** El bucle escribe tantos bytes como haya hasta el
   terminador. `anaT1.bufferRx` tiene 40 bytes, así que una trama sin la coma esperada puede
   escribir 39 bytes en un `char buffer[4]` — 35 bytes de desbordamiento **en la pila software del
   compilador**, que solo tiene ~228 bytes en total (ver [§2.5](#25-consumo-de-memoria)). Se
   machaca la dirección de retorno y variables de otras funciones.
2. **Sin comprobar el fin de cadena.** La condición de parada es únicamente `*ptrData != *end`. Si
   el terminador no aparece, el bucle **atraviesa el `\0`** y sigue leyendo RAM adyacente
   indefinidamente hasta topar por casualidad con un byte igual al terminador.
3. **`strstr` puede devolver `NULL` y se desreferencia sin comprobar.** Si el identificador no
   está en la trama, `ptrData = NULL` y el bucle empieza en `ptrData + 1 = 0x0001`, leyendo desde
   la dirección 1 del espacio de datos (registros de propósito general del banco 0) y escribiendo
   todo lo que encuentre en el buffer local.

**Dónde está protegido y dónde no:**

| Llamada | Ubicación | ¿`strstr` garantizado no-NULL? |
|---|---|---|
| `extraerValue(bufferRx, ID_NUM_ALARM, ID_COMA)` | `Serial.c:184` | ✅ sí, comprobado en `Serial.c:181` |
| `extraerValue(bufferRx, ID_ENC_ALARM, ID_COMA)` | `Serial.c:189` | ✅ sí, comprobado en `Serial.c:186` |
| `extraerFrame(..., ID_RELOJ, ID_COMA)` | `Serial.c:168` | ✅ sí, comprobado en `Serial.c:166` |
| `extraerFrame(..., ID_CALENDAR, END_FRAME)` | `Serial.c:171` | ❌ **NO** — nadie ha comprobado que haya `"C"` |
| `extraerFrame(..., ID_INIT_ALARM, ID_COMA)` | `Serial.c:199` | ❌ **NO** — nadie ha comprobado que haya `"I"` |
| `extraerFrame(..., ID_END_ALARM, ID_COMA)` | `Serial.c:202` | ❌ **NO** — nadie ha comprobado que haya `"F"` |
| `extraerFrame(..., ID_DAY_ALARM, ID_COMA)` | `Serial.c:205` | ❌ **NO** — nadie ha comprobado que haya `"D"` |

**Cuatro de las siete llamadas pueden desreferenciar `NULL`.** Y en las tres protegidas, la falta
del *terminador* sigue provocando desbordamiento aunque el identificador exista.

**Por qué es un problema real para el usuario.** No hace falta un atacante: basta con que el enlace
Bluetooth trocee una trama. Como el fin de trama se detecta por 5 ms de silencio
(ver [§6.3](#63-troceado-de-la-trama-detección-de-fin-por-silencio)), cualquier pausa del enlace SPP
mayor de 5 ms en mitad del envío parte la trama en dos. La primera mitad **sí contiene el
`INIT_FRAME`**, así que pasa el filtro de `Serial.c:148`, y si contiene la `"A"` pero le falta la
`"F"` o la `"D"`, se cae directamente en el caso `strstr == NULL`. El resultado es corrupción de
pila: reinicio aleatorio, escritura de valores absurdos en EEPROM, o cuelgue.

También ocurre con cualquier cliente distinto de la app oficial (una terminal Bluetooth, un script
de pruebas) que envíe una trama a medias o mal formada.

**Cómo se arregla.** Reescribir ambas funciones con límites explícitos:

```c
unsigned char extraerValue(const char* orig, char init, char end)
{
    char buffer[4] = {0};
    unsigned char cnt = 0;
    const char* p = strchr(orig, init);

    if(p == NULL) return 0;                       // 1) NULL comprobado

    for(p++; *p != '\0' && *p != end; p++)        // 2) parada en fin de cadena
    {
        if(cnt >= sizeof(buffer) - 1) return 0;   // 3) límite del destino
        buffer[cnt++] = *p;
    }
    if(*p != end) return 0;                       // 4) terminador obligatorio
    return (unsigned char)atoi(buffer);
}
```

Y lo mismo para `extraerFrame()`, pasando además el tamaño del destino como parámetro. Conviene
también validar los valores extraídos antes de escribirlos en EEPROM: `ucNumAlarm` en 1..5,
horas en 0..23, minutos en 0..59, días en 8..10.

---

#### D05 — `receiverUart1` escribe en el buffer sin comprobar el límite

**Qué pasa.** `Serial.c:74-77`, llamada desde la ISR (`main.c:82`):

```c
void receiverUart1(char* dest)
{
    serial1.bufferRx[serial1.ucCntRX++] = *dest;
}
```

`serial1.bufferRx` tiene `SIZE_BUFFER_RX1 = 40` bytes (`Serial.h:24`, `Serial.h:49`) y
`serial1.ucCntRX` es un `unsigned char` (`Serial.h:50`). **No hay ninguna comprobación de índice.**
El contador se reinicia únicamente cuando la tarea drena el buffer (`Serial.c:137`), lo cual solo
ocurre tras 5 ms de silencio en la línea.

**Por qué es un problema real para el usuario.** Si llegan más de 40 bytes sin una pausa de 5 ms,
la escritura se sale del array y machaca la RAM contigua. Como `ucCntRX` es de 8 bits, el índice
puede llegar hasta 255 antes de dar la vuelta: **hasta 216 bytes de desbordamiento**, con
`serial1` situada en el banco 2 (`_serial1 bssBANK2 000220` según el mapa del enlazador) y
`bssBANK2` extendiéndose de `0x200` a `0x252`. El desbordamiento sale del segmento y entra en
memoria no asignada y, más allá, en los bancos superiores.

Escenarios que lo provocan **sin malicia**:

- La propia app envía dos tramas en la misma pulsación del botón "Configurar": `sFrameHourCal`
  (`MainActivity2.java:425`) y a continuación `sFrameConf` (`MainActivity2.java:429`), ambas por el
  mismo `PrintWriter` con autoflush. Sumadas son `¿R2145\0\0,C211025-2\0\0?\n\r\n` (26 bytes) +
  `¿A3,E1,I0830,F1745,D9,?\n\r\n` (28 bytes) = **54 bytes**, más los `0xC2` de UTF-8. Si el módulo
  Bluetooth los entrega seguidos sin una pausa de 5 ms —que es el caso habitual, porque el HC-06
  vacía su FIFO a la velocidad del UART— **el buffer de 40 bytes se desborda en 14 bytes o más en
  cada configuración de alarma**.
- Cualquier terminal Bluetooth con el que un técnico teclee texto largo o pegue una línea.
- Ruido en la línea RX cuando el módulo no está emparejado.

**Cómo se arregla.**

```c
void receiverUart1(char* dest)
{
    if(serial1.ucCntRX < SIZE_BUFFER_RX1)
        serial1.bufferRx[serial1.ucCntRX++] = *dest;
    // si no cabe, se descarta el byte (y opcionalmente se marca overflow)
}
```

Y, a la vez, **ampliar `SIZE_BUFFER_RX1` a al menos 64 bytes** para que la ráfaga doble de la app
quepa entera, o —mejor— cambiar la detección de fin de trama de "silencio de 5 ms" a "byte
`END_FRAME` recibido", que es determinista y no depende de la temporización del enlace.

---
### 9.3 El resto de los defectos

Los defectos **D06 a D45** están en la tabla de 9.1 con su gravedad, su descripción y su
`fichero:línea`. **No llevan apartado propio a propósito**: redactarlos uno a uno costaba más
de lo que aportaba, porque los siete que de verdad mandan el trabajo ya están **medidos por el
simulador**, que es una fuente más fiable que una explicación escrita.

Para cada uno de esos siete, el escenario que lo demuestra:

| escenario | defecto | qué se midió |
|---|---|---|
| **C** | cadencia de la luz | 50 ms encendida / 50 ms apagada, frente a los 2 s / 2 s definidos |
| **D1** | D07 | a las 07:00, dentro de la franja 06:00–09:00, la luz **no** enciende |
| **D2** | D03 | una alarma para un día concreto **no se graba** y no se avisa |
| **D3** | D03 | la tarea de alarma se queda **clavada en `ST_CHECK_ALARM1`** (estado 6 → 6) |
| **D4** | D20 | el último byte escrito en `TXREG` es el terminador `0x00` |
| **D5** | D04 | una trama truncada **tumba el proceso** (violación de acceso) |
| **D6** | D06 | con dos franjas solapadas, la primera que termina apaga la luz |

```bash
cd "D:/@Proyect/Baliza/4 Simulador" && python correr.py
```

Cuando alguien vaya a arreglar uno de los que **no** tienen escenario, el primer paso es
escribirlo. Ver la skill [`simulador`](../.claude/skills/simulador/SKILL.md): un defecto sin
escenario se arregla a ciegas, y nada avisa si vuelve.

---

## 10. Cómo compilar y grabar

El procedimiento completo está en **[`COMPILAR_Y_GRABAR.md`](COMPILAR_Y_GRABAR.md)**. Aquí solo
lo que hay que saber antes de intentarlo:

```bash
cd "D:\@Proyect\Baliza\1 Firmware\Doc mplabx\18f2550_baliza_ V1.X"
"C:\Program Files\Microchip\xc8\v2.36\bin\xc8.exe" --chip=18f2550 --std=c99 \
  --outdir=<fuera del árbol> main.c Alarma.c Aplicacion.c Buzzer.c Cluster.c \
  DS1307.c EEprom.c I2C.c LedLive.c Serial.c TimeBase.c
```

Ocupa **21.309 de 32.768 bytes de programa (65,0 %)** y 687 de 2.048 de datos.

Cuatro trampas, las cuatro comprobadas:

- **`--std=c99` no es opcional.** En C90 falla en `DS1307.c:66` — un array `const` local
  inicializado con los parámetros de la función. **No se toca ese fichero: se compila en C99.**
- **Siempre con `--outdir` fuera del árbol de fuentes.** Sin él, XC8 deja los artefactos entre
  el código: ya ocurrió, 1,1 MB de `test_build.*` y `startup.*` mezclados con los `.c`.
- **El driver cambia el tamaño del binario.** Mismo compilador, mismas banderas, mismos fuentes:
  `xc8.exe` da **21.309 bytes (65,0 %)** y `xc8-cc.exe` da **26.863 (82,0 %)**. **5.554 bytes de
  diferencia solo por el driver.** Por eso la versión del compilador **y su driver y banderas**
  son parte del entregable, y tienen que quedar anotados junto al `.hex`.
- **MPLAB X no abre la carpeta como proyecto**: no existe `nbproject/`. Hay que crear proyecto
  nuevo, añadir los fuentes, **poner el estándar en C99** en las propiedades, y versionar el
  `nbproject/` resultante.

**El `.hex` que sale de aquí no es el de producción.** Producción se compiló con **v2.46** y
aquí hay **v2.36**: 60.044 bytes frente a 61.008, y difieren en casi todas las líneas.

> 🚫 **No grabar sin que lo pidan.** Hay señales de tránsito montadas en la calle al otro lado
> del programador. Y **MPLAB Snap no soporta el PIC18F2550**: hace falta PICkit 3/4, ICD 3/4,
> REAL ICE o PM3.

---
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

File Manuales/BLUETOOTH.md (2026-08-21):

# Baliza SR30 — Diagnóstico del Bluetooth, y cómo probarlo

> ## ✅ ACTUALIZACIÓN 21-ago-2026: **el SIG0109A funciona. No había avería de módulo.**
>
> Este documento se escribió para encontrar una avería de Bluetooth que **resultó no existir**.
> Se conserva entero porque su procedimiento de prueba sigue siendo la forma correcta de aislar
> un fallo serie, y porque sus datos verificados (baudios, tramas, pinouts, niveles) siguen
> siendo válidos. Pero léelo sabiendo el final:
>
> Desde «Serial Bluetooth Terminal», con el **SIG0109A** montado en la tarjeta, se envió `¿L?` y
> volvió el **volcado legible**. El módulo empareja, conecta, transporta bytes **en los dos
> sentidos**, y sus **9600 8N1 de fábrica son correctos**. El `.hex` y el DS1307 también quedan
> demostrados de paso.
>
> **La causa real del *«no lo reconoce»*** era una de las tres de §4: buscarlo en la lista como
> «HC-06» cuando se anuncia con otro nombre, no haberlo emparejado antes desde los **ajustes**
> del teléfono, o la **Ubicación** apagada. Nunca fue el módulo, ni el pinout, ni los baudios.
>
> **Lo único de este documento que pasa a ser urgente es §4 causa 8:** el `RXD` de 3,3 V del
> módulo está atacado con **5 V sin adaptación**. Ese es el fallo que probablemente mató al
> HC-06, y está corriendo ya contra este módulo. **Resistencia de 1 kΩ en serie en `MCU_TX`.**

**Equipo:** señal vial «30 CUANDO ACTIVADA», zona escolar. La luz titila → el límite de 30 km/h está vigente.
**Horario impreso en la chapa:** 6:00–9:00 · 11:30–13:30 · 15:00–16:30.
**Controlador:** PIC18F2550 @ 20 MHz · `D:\@Proyect\Baliza\1 Firmware\Doc mplabx\18f2550_baliza_ V1.X\`
**Tarjeta:** `BALIZA_SR30` rev V1.0 — documentada en `D:\@Proyect\Baliza\HARDWARE.md`
**Fecha:** 21-ago-2026 · redactado tras la reunión con el cliente de ese día.

> **Premisa de trabajo:** la tarjeta **ya está fabricada y es fija**. Aquí no se propone rediseñar la placa. Lo que el hardware limita se enuncia como **restricción** y se trabaja alrededor.
>
> **Por qué esto es crítico:** el Bluetooth es el **único** camino para programar los horarios. Si no empareja, el equipo no se puede configurar en campo. No hay teclado, no hay display, no hay otro puerto de usuario.

---

## 0. Lo primero: NO es el .hex

El cliente sospecha que el `.hex` está «compilado para otro Bluetooth». **No lo está, y no puede estarlo.**

El firmware no sabe qué módulo Bluetooth hay al otro lado. Lo único que ve es el periférico EUSART del PIC: dos pines, `RC6` (TX) y `RC7` (RX), y un flujo de bytes. Toda la inicialización del puerto está en cinco líneas:

```c
// UART.h:26-38  — UART_init_baud()
TXSTAbits.BRGH = 0;
TXSTAbits.SYNC = 0;     // asíncrono
TXSTAbits.TX9  = 0;     // 8 bits
SPBRG = 32;             // divisor del generador de baudios
RCSTAbits.SPEN = 1;  TXSTAbits.TXEN = 1;  RCSTAbits.CREN = 1;
```

No hay una sola referencia a «HC-06», ni a un comando `AT`, ni a una secuencia de inicialización del módulo, ni a un pin de control del módulo, en **todo** el proyecto. El módulo Bluetooth es, para el PIC, **un cable serie transparente**. Da exactamente igual si al otro lado hay un HC-06, un HC-05, un SIG0109A, un adaptador USB-TTL o un cable cruzado a un PC: mientras los bytes lleguen a 9600 baudios 8N1, el firmware funciona.

**Consecuencia práctica:** recompilar el firmware, reprogramar el PIC o buscar «otra versión del .hex» **no va a arreglar nada**. Es tiempo perdido. El problema está en el módulo, en su configuración, en el emparejamiento del teléfono o en la app — nunca en «para qué Bluetooth está compilado el .hex».

**La única cosa del firmware que sí importa** es el número de la sección siguiente: **9600 baudios, y no es negociable.**

---

## 1. El número que manda: 9600 baudios, 8N1 — verificado

El PIC tiene la velocidad **fija en el código**. No la negocia, no la autodetecta, no la cambia nunca.

**Evidencia:**

| Dato | Valor | Fuente |
|---|---|---|
| Oscilador | Cristal 20 MHz, modo HS | `main.h:17` (`#pragma config FOSC = HS`), `main.h:76` (`_XTAL_FREQ 20000000`), `Y1 = 20M` en `balizaSR30.kicad_sch:11582` |
| Función que se ejecuta | `UART_init_baud(9600)` | `main.c:117` |
| `BRGH` | 0 (baja velocidad) | `UART.h:26` |
| `BRG16` (BAUDCON) | 0 — **nunca se escribe**, queda en su valor de reset | ausencia en todo el proyecto; PIC18F2550 DS39632E §20.1 |
| `SPBRG` | 32 | `UART.h:34` |
| Bits de datos | 8 (`TX9 = 0`) | `UART.h:32` |
| Paridad | ninguna (el EUSART del PIC18 no tiene generador de paridad) | PIC18F2550 DS39632E §20 |
| Bits de parada | 1 (fijo por hardware) | PIC18F2550 DS39632E §20 |

### 1.1 La cuenta, hecha con la fórmula del datasheet

PIC18F2550, hoja de datos **DS39632E, Tabla 20-1 «Baud Rate Formulas»**. Para `SYNC = 0` (asíncrono), `BRG16 = 0`, `BRGH = 0`:

```
Baudios = FOSC / ( 64 · (n + 1) )        con n = SPBRG
```

Sustituyendo `FOSC = 20 000 000` y `n = 32`:

```
Baudios = 20 000 000 / ( 64 · (32 + 1) )
        = 20 000 000 / ( 64 · 33 )
        = 20 000 000 / 2 112
        = 9 469,70 baudios
```

**Error frente a 9600:**

```
error = (9 469,70 − 9 600) / 9 600 × 100 = −1,357 %
```

### 1.2 ¿Es tolerable ese −1,36 %?

Sí, con margen. En una trama 8N1 el receptor engancha el flanco de bajada del bit de start y muestrea el bit de stop **9,5 tiempos de bit** después. Para que ese último muestreo caiga todavía dentro de su celda, la deriva acumulada entre los dos extremos debe ser menor de **±5 %** en el límite teórico, y por buena práctica se exige **menos de ±3 % sumando los dos extremos**.

- Extremo PIC: **−1,36 %**.
- Extremo módulo: desconocido, pero un módulo con cristal de 16 MHz y divisor entero típicamente queda por debajo de ±0,2 %.
- **Suma ≈ −1,5 %.** Sobra margen.

**Comprobación de que 32 es el mejor valor posible con `BRGH = 0`:** `n = 31` daría `20e6/(64·32) = 9765,6 bd` (+1,73 %), peor. Así que el valor elegido es el óptimo de su familia y coincide con la tabla de la hoja de datos de Microchip.

### 1.3 Detalle: hay una segunda función de inicialización, más exacta, que NO se usa

`UART.h:6-18` define `UART_init()` con `BRGH = 1` y `SPBRG = 129`:

```
Baudios = 20 000 000 / ( 16 · (129 + 1) ) = 20 000 000 / 2 080 = 9 615,38 bd  →  +0,16 %
```

Diez veces más exacta. Pero **`main.c:117` llama a `UART_init_baud(9600)`, no a `UART_init()`**, así que la que corre es la de −1,36 %. No es un problema (§1.2), pero conviene saberlo: si algún día apareciera un módulo con un reloj muy desviado, cambiar la llamada de `main.c:117` a `UART_init()` recupera 1,2 puntos de margen sin tocar nada más. **Hoy no hace falta.**

### 1.4 Y ojo con el argumento

`UART_init_baud(const long int baudRate)` **ignora su propio argumento**. El `9600` que se le pasa en `main.c:117` no se usa: `SPBRG` está escrito a pelo con `32` en `UART.h:34`, y la línea que lo calcularía está comentada (`UART.h:35`). Cambiar el `9600` de `main.c` no cambia la velocidad. Si alguna vez hay que cambiarla de verdad, se cambia `SPBRG` en `UART.h:34`.

> ### 🔴 Regla de oro
> **El módulo Bluetooth tiene que estar a 9600 baudios, 8 bits, sin paridad, 1 bit de stop.**
> Si está a 38400, a 115200 o a cualquier otra velocidad, **no hay nada que hacer**: emparejará perfectamente, la app se conectará, y sólo saldrá basura o nada. Esta es la primera cosa a comprobar y la que más veces explica «no funciona».

---

## 2. Las DOS averías distintas que se están confundiendo en una

Esta es la sección más útil del documento. «No lo reconoce» son **dos síntomas completamente distintos**, con causas distintas y arreglos distintos. Hasta ahora se están tocando todas las variables a la vez, y por eso no se avanza.

```
        ┌─────────────────────────────────────────────────────┐
        │  AVERÍA A — el móvil NO VE el módulo                 │
        │  Capas implicadas: alimentación · módulo · Android   │
        │  El PIC NO PINTA NADA. La app NO PINTA NADA.        │
        │  Los baudios NO PINTAN NADA.                         │
        └─────────────────────────────────────────────────────┘
                              ↓ (una vez emparejado)
        ┌─────────────────────────────────────────────────────┐
        │  AVERÍA B — empareja, pero no llegan datos          │
        │  Capas implicadas: baudios · TX/RX · niveles ·      │
        │                    permisos de Android · firmware   │
        └─────────────────────────────────────────────────────┘
```

### 2.1 Tabla: síntoma → capa culpable → prueba que lo decide

| # | Lo que se observa | Capa culpable | Lo que NO puede ser | Prueba que lo decide | ⏱ |
|---|---|---|---|---|---|
| A1 | El LED del módulo **no enciende** al dar tensión | Alimentación o módulo muerto | Nada del PIC, la app ni los baudios | **Prueba 0**, paso 3: medir 5 V entre VCC y GND del zócalo | 2 min |
| A2 | LED enciende/parpadea, pero el móvil **no lo encuentra** en la búsqueda de Bluetooth | Módulo (rol, visibilidad) o Android (ubicación/permisos del sistema) | Nada del PIC ni de la app | **Prueba 0**, pasos 5-6: buscar desde los ajustes del teléfono, con la ubicación encendida | 3 min |
| A3 | El móvil **lo encuentra pero falla el emparejamiento** («PIN incorrecto», «no se pudo emparejar») | PIN del módulo | Nada más | Probar `1234`, luego `0000` | 2 min |
| A4 | Empareja bien desde los ajustes, pero **no sale en la lista de la app** | **App**: sólo lista dispositivos **ya emparejados** (`MainActivity2.java:280`) | Módulo, PIC, baudios | Verificar que el módulo aparece en «Dispositivos emparejados» de los **ajustes del teléfono**, no en «disponibles» | 1 min |
| A5 | En los ajustes del teléfono no aparece ningún dispositivo nuevo, y el teléfono es Android 12+ | Android: permisos de ubicación / servicio de ubicación apagado | El módulo, si el LED parpadea | Encender la ubicación del teléfono y repetir la búsqueda | 2 min |
| B1 | Conecta, y la app dice **«Connect failed»** | Emparejamiento roto o módulo ocupado con **otro** teléfono | Baudios (aún no se ha hablado) | Apagar el otro teléfono; desemparejar y volver a emparejar | 3 min |
| B2 | Conecta, y llega **texto ilegible / caracteres raros** | **Baudios distintos de 9600** | Módulo muerto, cableado, app | **Prueba 3**: leer el banner `BALIZA ALARMA V1.0` | 5 min |
| B3 | Conecta, y **no llega absolutamente nada** (pantalla en blanco) | Cableado TX/RX, alimentación del PIC, o el PIC no arranca | Baudios (con baudios malos llegaría *algo*) | **Prueba 3**: ¿parpadea el LED de vida `D1` de la tarjeta? | 5 min |
| B4 | El banner **sí sale** legible, pero mandar `L` no devuelve nada | Sentido PIC ← módulo (RXD del módulo, o `MCU_TX` del PIC) | El sentido PIC → móvil, que ya está demostrado | **Prueba 3**, paso 6: enviar `¿L?` como bloque | 5 min |
| B5 | Todo va con un terminal serie, pero **la app no** | App / permisos de Android / `targetSdkVersion` | Módulo, PIC, baudios, cableado | **§5**, y **Prueba 4** | 10 min |

### 2.2 Lo que hay que dejar de hacer

- Dejar de recompilar el firmware (§0).
- Dejar de cambiar el módulo de sitio antes de saber si está vivo (**Prueba 0**).
- Dejar de probar con la app antes de que un terminal serie funcione (**Pruebas 1-3**).
- Dejar de cambiar dos cosas a la vez.

---

## 3. Los tres módulos, comparados

> **Cómo leer esta tabla.** Cada celda lleva una marca de procedencia:
> **[DS]** = hoja de datos o manual del fabricante · **[M]** = lo que se observa habitualmente en el mercado, **no es especificación** · **[?]** = no confirmado, va a §9 «Preguntas abiertas».
>
> Los módulos HC-05 y HC-06 se venden desde hace quince años por decenas de fabricantes distintos sin especificación común. Lo marcado **[M]** es orientación de partida para probar, **no** un dato en el que apoyarse.

**Fuentes primarias usadas en esta tabla:**
- HC-06: *Product Data Sheet*, Guangzhou HC Information Technology (Wavesen), Rev 2.2, 2011-04-06 — <https://www.electronicoscaldas.com/datasheet/HC-06_Wavesen.pdf>
- HC-05: *HC-05 Bluetooth to Serial Port Module*, ITead Studio, 2010-06-18 — <https://components101.com/sites/default/files/component_datasheet/HC-05%20Datasheet.pdf>
- SIG0109A: ficha de producto de Sigma Electrónica — <https://www.sigmaelectronica.net/producto/sig0109a/> — y `BK3231_ARM968E-S.pdf` (hoja del SoC)
- Formato ZS-040 y niveles de E/S: Martyn Currey — <https://www.martyncurrey.com/hc-05-and-hc-06-zs-040-bluetooth-modules-first-look/>

| | **HC-06** (el que funcionaba) | **HC-05** | **SIG0109A** (Sigma Electrónica) |
|---|---|---|---|
| **Chip** | «*Bases at **CSR BC04** Bluetooth technology*» **[DS]**. *(«CSR BC417» es lo que se repite en el mercado, pero **no** aparece en la hoja del fabricante — **[M]**)* | «*It uses **CSR Bluecore 04**-External single chip Bluetooth system*» **[DS]** | **Beken BK3231S** **[DS]** (ficha Sigma) |
| **Firmware** | `LinvorV1.n` (respuesta a `AT+VERSION`) **[DS]** | firmware HC-05 de ITead/Wavesen; `AT+VERSION?` → `+VERSION:2.0-20100601` **[DS]** | firmware propio de Beken, **no compatible** con el de CSR **[DS por implicación]** |
| **Versión Bluetooth** | 2.0 + EDR **[DS]** | **V2.0 + EDR** **[DS]** | **Bluetooth 3.0** **[DS]** (ficha Sigma y `BK3231_ARM968E-S.pdf` p.3) |
| **Perfil** | SPP **[DS]** | SPP **[DS]** | SPP **[DS]** — pero el SoC es de origen **HID**: «*HID v1.0, and other light profile by request*» (`BK3231_ARM968E-S.pdf`, p.3) |
| **Cristal** | 26 MHz **[M]** | 26 MHz **[M]** | **16 MHz** **[DS]** (ficha Sigma; BK3231 datasheet, Tabla 2, `FXTAL`) |
| **Rol** | **Sólo esclavo** — no puede iniciar conexiones **[DS]** (no existe comando de rol) | **Maestro/esclavo/slave-loop**, conmutable: `AT+ROLE=0/1/2` **[DS]** | **[?]** la ficha no lo dice. Si es un JDY-31 (§3.3): **sólo esclavo** **[DS del manual JDY-31]** |
| **Baudios de fábrica (modo datos)** | **9600 N81** — «*Default parameter: Baud rate:9600N81*» **[DS]** | ⚠️ **El manual oficial dice 38400**: «*Default Baud rate: 38400, Data bits:8, Stop bit:1, Parity:No parity*», y `AT+ORGL` restaura «*Baud 38400bits/s*» **[DS]**. Las placas ZS-040 del mercado suelen venir a **9600** en modo datos **[M]**. **Los dos valores circulan: hay que medirlo (Prueba 2)** | **[?]** — la ficha de Sigma **no lo dice**. Si es un JDY-31: **9600** **[DS del manual JDY-31]** |
| **Modo AT** | **No hay modo separado.** «*supply power to the module, it will enter to the AT mode if it needn't pair*» — AT funciona mientras **no** esté emparejado/conectado, a los baudios de trabajo **[DS]** | **Sí, modo separado.** «*1. Connect PIO11 to high level. 2. Power on, module into command state. 3. Using baud rate 38400*» — **PIO11 es el pin KEY/EN** del breakout **[DS]** | **[?]**. Si es un JDY-31: **no hay modo separado**, los AT van por el mismo UART sin conexión activa **[DS del manual JDY-31]** |
| **Juego de comandos AT** | `AT`, `AT+BAUDn`, `AT+NAMEx`, `AT+PINxxxx`, `AT+VERSION`, `AT+PN/PO/PE`. **Sin CR/LF**, con ~1 s entre comandos **[DS]** | `AT+ROLE=`, `AT+UART=`, `AT+NAME=`, `AT+PSWD=`, `AT+ORGL`, `AT+RESET`, `AT+VERSION?`, `AT+ADDR?`, `AT+STATE?`. **Todos terminados en CR+LF** **[DS]** | **Otro juego distinto.** Si es un JDY-31, sólo **9 comandos** y **ninguno** es `AT+ROLE` ni `AT+UART` (§3.3) **[DS del manual JDY-31]** |
| **PIN por defecto** | **`1234`** **[DS]** | ⚠️ **El manual se contradice**: la portada dice «*Auto-pairing PINCODE:"0000" as default*», pero `AT+PSWD` dice «*(Default 1234)*» y `AT+ORGL` restaura «*pin code :1234*» **[DS]**. **Probar `1234` y luego `0000`** | **[?]**. Si es un JDY-31: **`1234`** **[DS del manual JDY-31]** |
| **Nombre por defecto** | **`linvor`** — «*ID: linvor*» **[DS]**. *(Que se anuncie como «HC-06» es un reetiquetado del revendedor — **[M]**)* | `AT+NAME` indica «*(Default :HC-05)*», pero `AT+ORGL` restaura «*device name: **H-C-2010-06-01***» **[DS]** | **[?]**. Si es un JDY-31: **`JDY-31-SPP`** **[DS del manual JDY-31]** |
| **Pines de la placa** | 6, paso 2,54 mm: `STATE · RXD · TXD · GND · VCC · EN/KEY` **[M]** (formato ZS-040 / JY-MCU) | 6, paso 2,54 mm: `STATE · RXD · TXD · GND · VCC · EN/KEY` **[M]** (formato ZS-040) | **[?] — DATO CRÍTICO, y hay una CONTRADICCIÓN documentada. Ver §3.3 y §4 causa 6** |
| **Alimentación** | 3,6–6 V en la placa portadora (lleva LDO de 3,3 V); **el módulo desnudo es de 3,3 V** **[M]** | 3,6–6 V en la placa portadora ZS-040 **[M]** | **3,6–6 V** **[DS]** (ficha Sigma). El SoC BK3231 trabaja a **2,0–3,6 V** (`BK3231_ARM968E-S.pdf`, Tabla 2, `VCC`) → el módulo **lleva regulador interno** |
| **Nivel lógico de RXD** | **3,3 V — NO tolerante a 5 V** **[M]** | **3,3 V — NO tolerante a 5 V**: «*the breakout board adds 5v VCC in compatibility but the RX and TX pins are still 3.3v only*» **[M]** | **[?] oficialmente.** Si es un JDY-31, **tampoco es tolerante a 5 V** **[M]**. El SoC admite `VIH` máx `VCC+0,3 V` con `VCC ≤ 3,6 V` (`BK3231_ARM968E-S.pdf`, Tabla 2) |

### 3.1 Lo que hay que entender del SIG0109A

Sigma Electrónica lo vende literalmente como **«Módulo Bluetooth posible reemplazo del HC-05 y HC-06»** (<https://www.sigmaelectronica.net/producto/sig0109a/>). Nótese el **«posible»**: el propio vendedor no lo garantiza.

**«Reemplazo» no significa «igual».** Es un **clon con otro chip, otro firmware y otro juego de comandos AT**. Los HC-05 y HC-06 llevan un **CSR BlueCore 04**; el SIG0109A lleva un **Beken BK3231S**. La compatibilidad que promete el vendedor es a nivel de **función** (es un puente SPP-a-serie con 6 pines) y presumiblemente de **huella mecánica** — **no** a nivel de comandos AT, ni necesariamente de configuración de fábrica, **ni necesariamente de orden de pines**.

**Todo lo que la ficha de Sigma NO dice** (verificado sobre la página completa): baudios por defecto, PIN de emparejamiento, nombre por defecto, pinout, comandos AT, y **no hay manual del módulo** — el único documento enlazado es el datasheet del SoC (§3.2).

**Traducción práctica:** todo lo que se sepa de configurar un HC-05 por AT **puede no aplicar** a este módulo. Si hay que cambiarle los baudios, hace falta **su** manual, no el del HC-05.

### 3.2 El PDF que tienen NO es el que hace falta — leído y confirmado

El único documento disponible es `D:\@Proyect\Baliza\5 HW bluetooth\BK3231_ARM968E-S.pdf`.

**Qué es realmente:** «BK3231 Bluetooth HID SoC — Datasheet — Preliminary Specification», Beken Corporation, **29 páginas**, fechado **Sep-2014** (metadatos del PDF: creado 2015-07-07, título original `Microsoft Word - Technical Description.doc`).

Es la **hoja de datos del chip pelado**, escrita para quien diseña una placa alrededor del BK3231. **No es el manual del módulo SIG0109A.** Su índice lo dice todo (p. 2):

> 1 General Description · 2 Features · 3 Pin Information · 4 Memory Organization · 5 Interrupt and Clock Unit · 6 MFC · 7 GPIO · 8 ADC · 9 UART · 10 I2C-SMBus · 11 SPI · 12 PWM Timer · 13 Watch dog · 14 Electrical Specifications · 15 Package Information · 16 Application Schematic · 17 Order Information

**Lo que se buscó en él, y NO está — confirmado con búsqueda de texto sobre el PDF completo:**

| Lo que hace falta para configurar el módulo | ¿Está en el PDF? | Comprobación |
|---|---|---|
| **Baudios por defecto** | ❌ **NO** | La única mención a baudios es la fórmula del registro del periférico UART, p. 17: `Baud rate = UART_CLK/(UART_CLK_DIV+1)`, con `UART_CLK_DIV` en `0x0[20:8]`. Eso configura el periférico **desde el firmware del chip**; no dice a qué velocidad arranca un módulo comercial. No aparece «9600», ni «38400», ni «115200» en ninguna página |
| **Comandos AT** | ❌ **NO** | Cero apariciones de «AT+», «AT command» o «command set» en las 29 páginas. Es lógico: los comandos AT los implementa el **firmware del módulo**, no el silicio |
| **Pinout de la placa del módulo** | ❌ **NO** | La sección 3 «Pin Information» describe los encapsulados **QFN 7×7 de 56 pines** y **QFN 4×4 de 32 pines** del chip (pines `VDDPA`, `VDDSPI`, `VDDDSP`, `XTALN`, `RFP`, `VCCRF`…). Nada que ver con los 6 pines de una placa portadora |
| **PIN de emparejamiento** | ❌ **NO** | Cero apariciones de «pairing», «PIN code», «passkey» o «1234» |
| **Nombre Bluetooth por defecto** | ❌ **NO** | — |
| **Perfil SPP garantizado** | ⚠️ **A MEDIAS** | p. 3: «*It integrates … Bluetooth HID profile*» y «*HID v1.0, and other light profile **by request***». El SPP se menciona como posibilidad («*it is also possible for other Bluetooth application such as SPP controller*»), **no** como característica estándar del chip |
| **Alimentación del módulo** | ⚠️ **DEL CHIP, NO DEL MÓDULO** | Tabla 2: `VCC` operativo **2,0 – 3,0 – 3,6 V**. Ese es el **SoC**. La ficha de Sigma dice **3,6–6 V** para el **módulo**, luego el módulo lleva su propio regulador |
| **Tolerancia a 5 V en RXD** | ❌ **NO** | Tabla 2 da `VIH` con máximo `VCC+0,3 V` para los pines del **chip**. Sobre lo que hay en el pin RXD **de la placa** no dice nada |

> **🔴 Esta es la razón exacta por la que están atascados.** Tienen la hoja de datos de un microcontrolador ARM968E-S, y lo que necesitan es una hoja de dos páginas que diga «arranca a X baudios, el PIN es Y, se le habla con estos comandos AT y los pines van en este orden». **Ese documento no lo tienen, y sin él no se puede configurar el módulo a ciegas: hay que medirlo (Prueba 2) o pedírselo a Sigma (§9, pregunta 1).**

---

### 3.3 ⭐ La pista más útil: el SIG0109A es casi seguro un JDY-31 (o «SPP-C»)

Los módulos BK3231S vendidos como reemplazo de HC-05/HC-06 corresponden a la familia comercial **JDY-31 / JDY-30 / «SPP-C»**. La identificación chip↔modelo procede de **terceros**, no de Sigma:

- Martyn Currey: «*The JDY-31 SPP bluetooth module, otherwise known as SPP-C, is a bluetooth slave module based on **BK3231S** Bluetooth SoC by Beken*» — <https://www.martyncurrey.com/jdy-31-spp-bluetooth-module/>
- AdAstra-Soft: JDY-30 = BK3231, **JDY-31 = BK3231S** — <https://adastra-soft.com/some-information-about-the-jdy-31-bluetooth-module/>

**Coincide con el SIG0109A en las tres cosas que Sigma sí publica:** chip BK3231S, Bluetooth 3.0 y alimentación 3,6–6 V. **Pero Sigma no publica el modelo, así que la equivalencia NO está confirmada** (§9, pregunta 1b).

**Si se confirma que es un JDY-31**, existe manual del fabricante — *JDY-31 Bluetooth Backplane User Manual, V1.3, 2019-01-08*, <https://adastra-soft.com/wp-content/uploads/2021/06/JDY-31_manual_2.pdf> — y todo el problema se resuelve. Lo que dice, **[DS]**:

| Dato | Valor según el manual JDY-31 | Qué significa para la baliza |
|---|---|---|
| **Baudios de fábrica** | **9600** | ✅ **Coincide con el PIC.** Si es un JDY-31, los baudios **no son la avería** |
| `AT+BAUD` | parámetro 4–9 → 9600 / 19200 / 38400 / 57600 / 115200 / 128000 | Se puede volver a 9600 con `AT+BAUD4` |
| **PIN por defecto** | **`1234`** | ✅ Es el que hay que probar primero |
| **Nombre por defecto** | **`JDY-31-SPP`** | ⚠️ **No se llama «HC-06».** Buscar «HC-06» y no encontrarlo **no** significa que esté mal |
| **Rol** | **Sólo esclavo** | ✅ **La causa 3 (modo maestro) NO le aplica.** Sólo aplica al HC-05 |
| **Modo AT** | **No hay modo separado.** Mismo UART, con la conexión Bluetooth cerrada | ✅ **No hace falta el pin KEY** — que en esta tarjeta está al aire |
| **Comandos AT** | **Sólo 9**: `AT+VERSION`, `AT+RESET`, `AT+DISC`, `AT+LADDR`, `AT+PIN`, `AT+BAUD`, `AT+NAME`, `AT+DEFAULT`, `AT+ENLOG`. **Terminados en `\r\n`.** Respuestas `+OK` / `+NAME=...` | ❌ **No existe `AT+ROLE` ni `AT+UART`.** Los comandos del HC-05 **no funcionan** |
| `AT+VERSION` | `+VERSION=JDY-31-V1.2,Bluetooth V3.0` | Es la forma de identificarlo con certeza |
| **Alimentación** | «*SMD type: 1,8–3,6 V (3,3 V recomendado); **with backplane: 3,6–6 V (recomendado 5 V)***» | ✅ **Los +5 V del zócalo son correctos** para la placa portadora |
| **Perfil** | Bluetooth 3.0 **SPP** | ✅ Compatible con el UUID `00001101-...` de la app |

**🔴 Y aquí está la contradicción que puede haber quemado el módulo:**

| Fuente | Orden de los 6 pines |
|---|---|
| **Tabla del manual JDY-31** **[DS]** | `STATE · RXD · TXD · GND · VCC · EN` *(con `EN` marcado «Vacant», no operativo)* |
| **Martyn Currey, foto de la placa real** **[M]** | `STATE · TXD · RXD · VCC · GND · EN` |
| **Zócalo de la baliza** (`balizaSR30.kicad_pcb`) | `STATE · RXD · TXD · GND · VCC · EN` |

Las dos fuentes discrepan en **dos permutaciones a la vez**: `RXD`↔`TXD` **y `GND`↔`VCC`**. La segunda es letal: si la placa real lleva el orden que reporta Currey y se inserta en este zócalo, **los +5 V entran por el pin GND del módulo y la masa por su VCC**. Muerte instantánea.

> **🔴 NO INSERTAR EL SIG0109A HASTA HABER COMPARADO SU SERIGRAFÍA, PIN A PIN, CON EL ZÓCALO.** Es gratis, tarda un minuto, y es la diferencia entre un módulo vivo y uno muerto. Ver §4, causa 6, y §6 Prueba 0, paso 2.

---

## 4. La causa más probable, ordenada

Lista priorizada. La primera es la más probable. Cada una: **qué síntoma produce**, **cómo descartarla en menos de 5 minutos**.

---

### 🥇 Causa 1 — El módulo nuevo nunca se emparejó desde los ajustes del teléfono

**Por qué es la primera.** La app **no busca dispositivos**. Nunca llama a `startDiscovery()`. Sólo pide al sistema la lista de los que **ya están emparejados**:

```java
// MainActivity2.java:280
Set<BluetoothDevice> pairedDevices = mBluetoothAdapter.getBondedDevices();
```

Y si esa lista está vacía, el diálogo **ni siquiera se abre**: `if (pairedDevices.size() > 0)` (`MainActivity2.java:282`) — sin `else`. Se pulsa «Dispositivo» y **no pasa absolutamente nada**. Ni error, ni aviso, ni lista vacía. Exactamente lo que un usuario describe como **«no lo reconoce»**.

**Síntoma que produce:** se pulsa el botón de dispositivo en la app y no aparece ningún diálogo, o aparece uno que no incluye el módulo nuevo.

**Cómo descartarla (2 minutos):** Ajustes del teléfono → Bluetooth → buscar → emparejar el módulo → volver a la app. **El emparejamiento se hace SIEMPRE desde los ajustes de Android, nunca desde la app.**

**Agravante:** el HC-06 antiguo probablemente **sigue emparejado** en el teléfono. Aparece en la lista de la app aunque no esté enchufado a ninguna parte, y la conexión falla. Confunde el diagnóstico. **Desemparejar el HC-06 viejo.**

---

### 🥈 Causa 2 — Los baudios del módulo nuevo no son 9600

**Por qué.** El PIC está clavado a 9469,7 bd (§1). Si el módulo nuevo sale de fábrica a otra velocidad, **empareja perfectamente y no se entiende nada**.

**Y hay un motivo documental fuerte para sospechar del HC-05 en concreto:** su manual oficial (ITead Studio, 2010-06-18) dice literalmente «*Default Baud rate: **38400**, Data bits:8, Stop bit:1, Parity:No parity*», y `AT+ORGL` —el comando de valores de fábrica— restaura «*Baud **38400** bits/s*». Las placas ZS-040 que circulan por el mercado suelen venir a 9600 en modo datos **[M]**, pero **los dos valores circulan**. Con un HC-05 recién comprado, **38400 es una hipótesis de primer orden**, no una rareza.

En cambio, si el SIG0109A resulta ser un JDY-31 (§3.3), su manual da **9600** de fábrica — y entonces esta causa **no le aplica**. La ficha de Sigma, por sí sola, **no dice a qué velocidad arranca** (§3.1).

**Síntoma que produce:** empareja, la app conecta sin error, y llega **basura ilegible** (`ÿ`, `ø`, caracteres de control) o nada. El caso B2 de la tabla de §2.1.

**Cómo descartarla (5 minutos):** **Prueba 3**. Módulo en la tarjeta, dar tensión, terminal serie Bluetooth abierto. Si a los ~7 s aparece **`BALIZA ALARMA V1.0`** legible → está a 9600 y esta causa queda descartada. Si aparece basura → es esta.

---
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

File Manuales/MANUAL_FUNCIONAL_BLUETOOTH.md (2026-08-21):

# Manual funcional — Configuración y validación del módulo Bluetooth

**Equipo:** Baliza intermitente de señal vial «30 CUANDO ACTIVADA» — zona escolar
**Tarjeta:** `BALIZA_SR30` · PIC18F2550
**Documento:** hoja de trabajo de banco. Configurar y validar el módulo Bluetooth **antes** de montarlo en la señal.
**Versión:** 1.0 · 21 de agosto de 2026

---

## 🔴 PASO 0 — ANTES DE ALIMENTAR NADA: COMPARA LA SERIGRAFÍA CON EL ZÓCALO

> ### Esto va primero porque puede destruir el módulo en el instante en que le des tensión.
> **Tarda un minuto. Es gratis. Hazlo con TODOS los módulos, y muy especialmente con el SIG0109A.**

**Hay una contradicción documentada en el orden de los 6 pines del módulo SIG0109A**, y una de las dos versiones **mata el módulo al enchufarlo** en el zócalo de esta tarjeta.
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

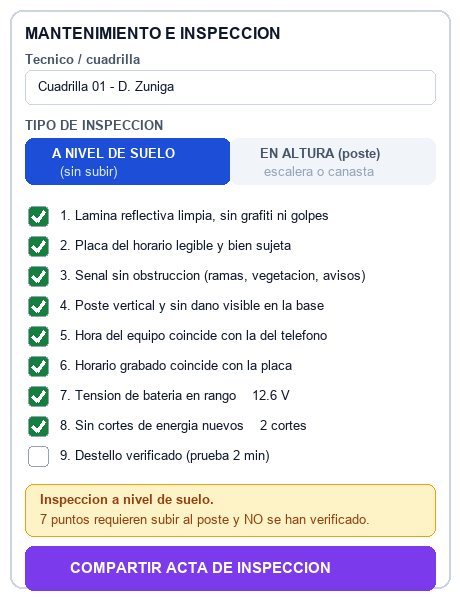
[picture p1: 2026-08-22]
Manuales/img/propuesta_mant_suelo.png

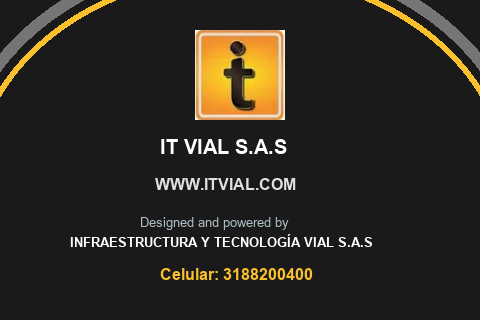
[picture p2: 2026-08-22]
Manuales/img/portada_it_vial_creditos.png

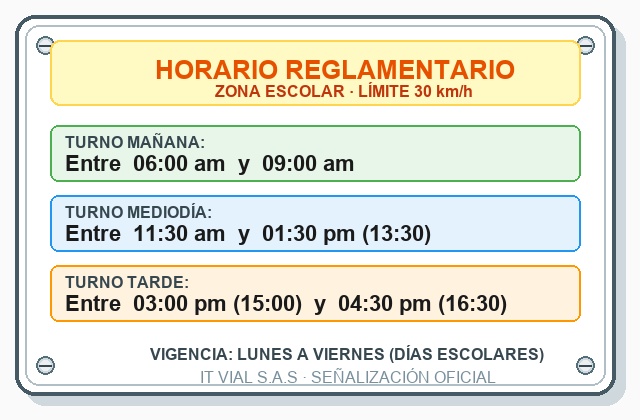
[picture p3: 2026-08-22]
Manuales/img/placa_horario.jpeg

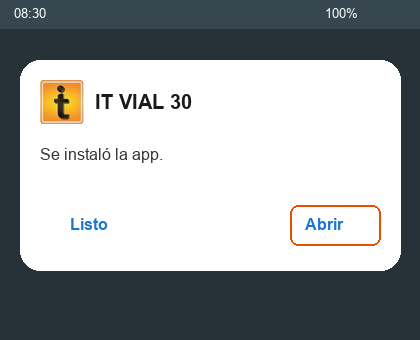
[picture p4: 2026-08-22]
Manuales/img/paso1_instalacion_finalizada.png

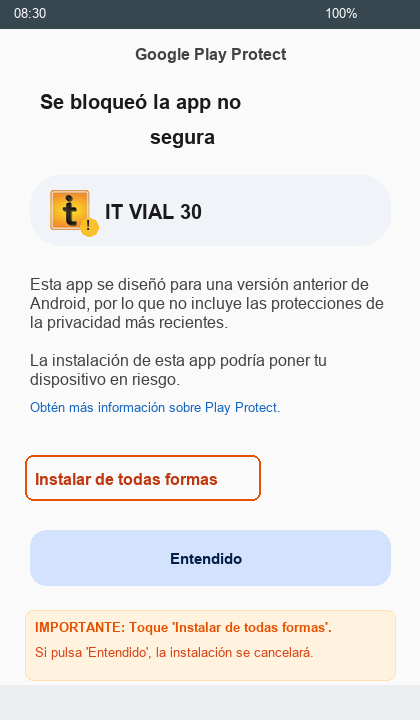
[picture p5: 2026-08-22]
Manuales/img/paso1_play_protect_bloqueo.png

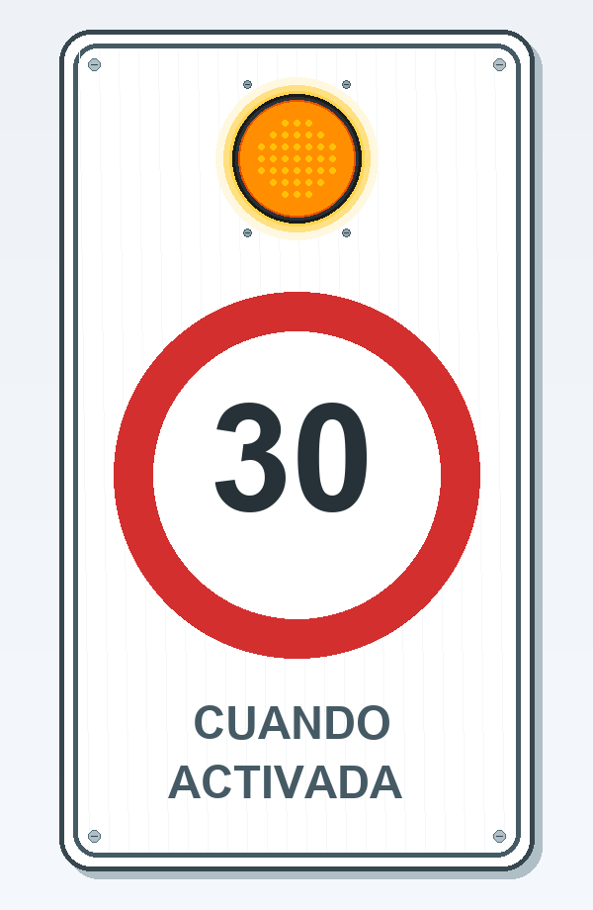
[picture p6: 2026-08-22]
Manuales/img/senal_vial_hd.png

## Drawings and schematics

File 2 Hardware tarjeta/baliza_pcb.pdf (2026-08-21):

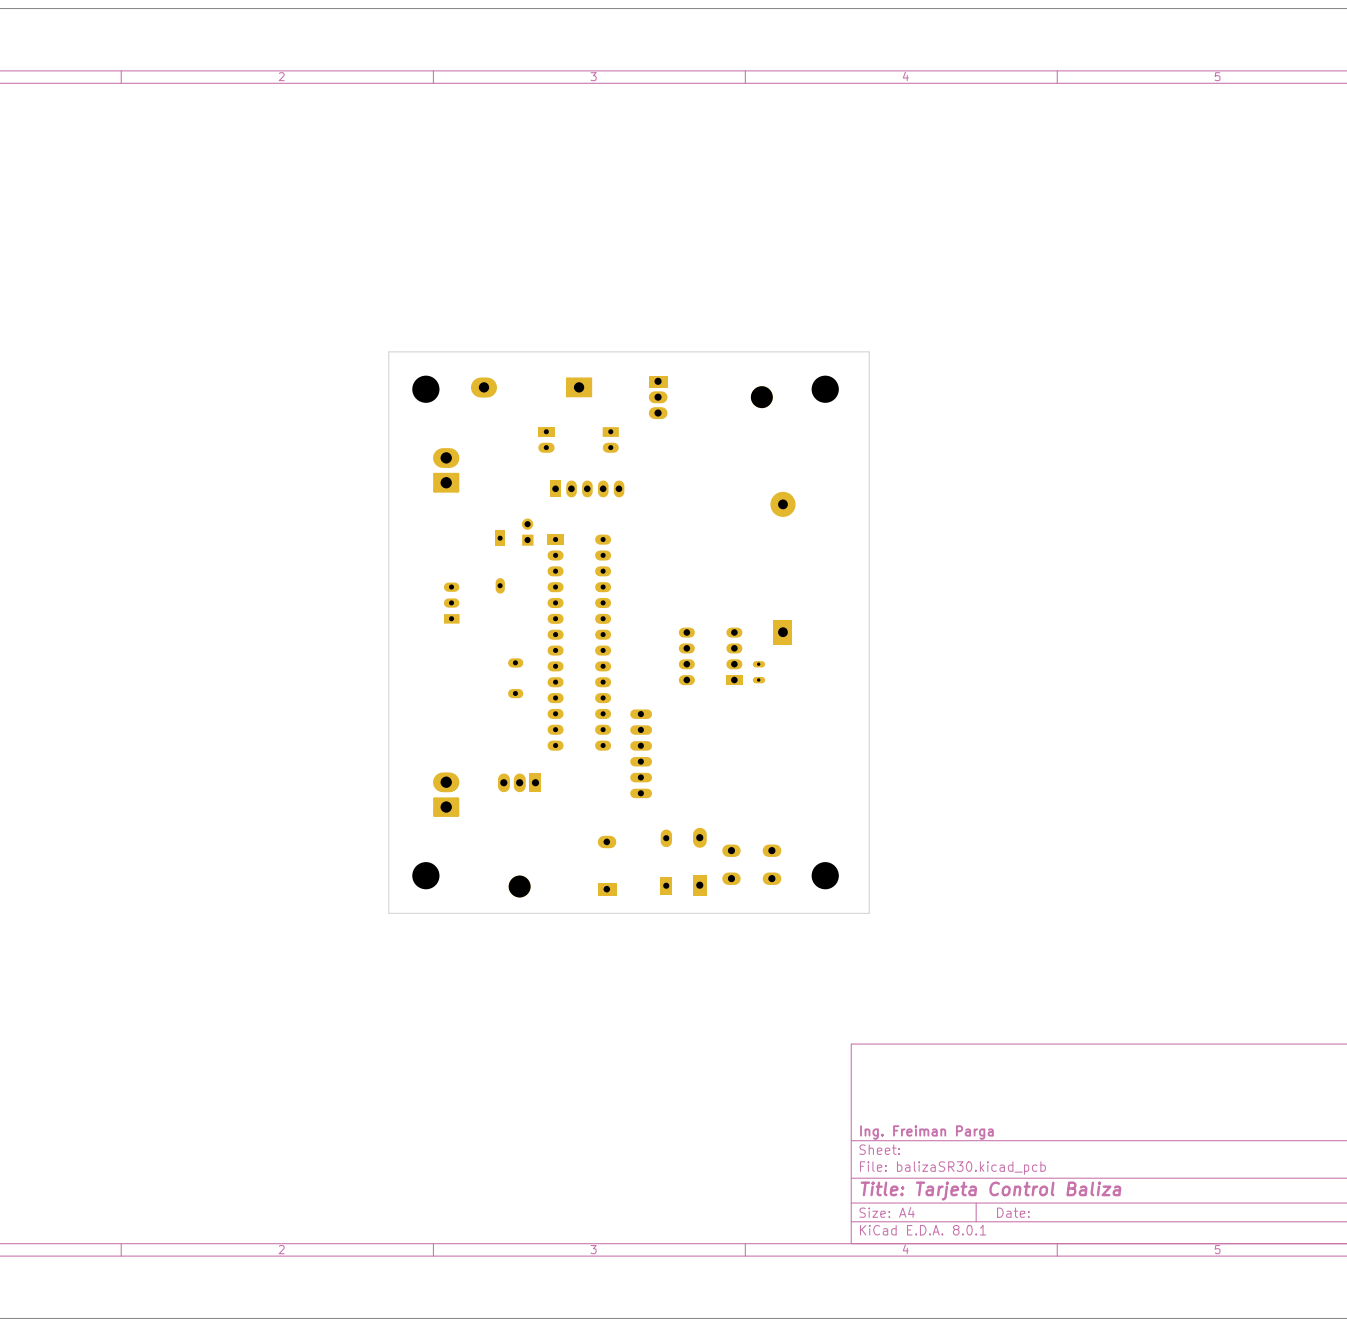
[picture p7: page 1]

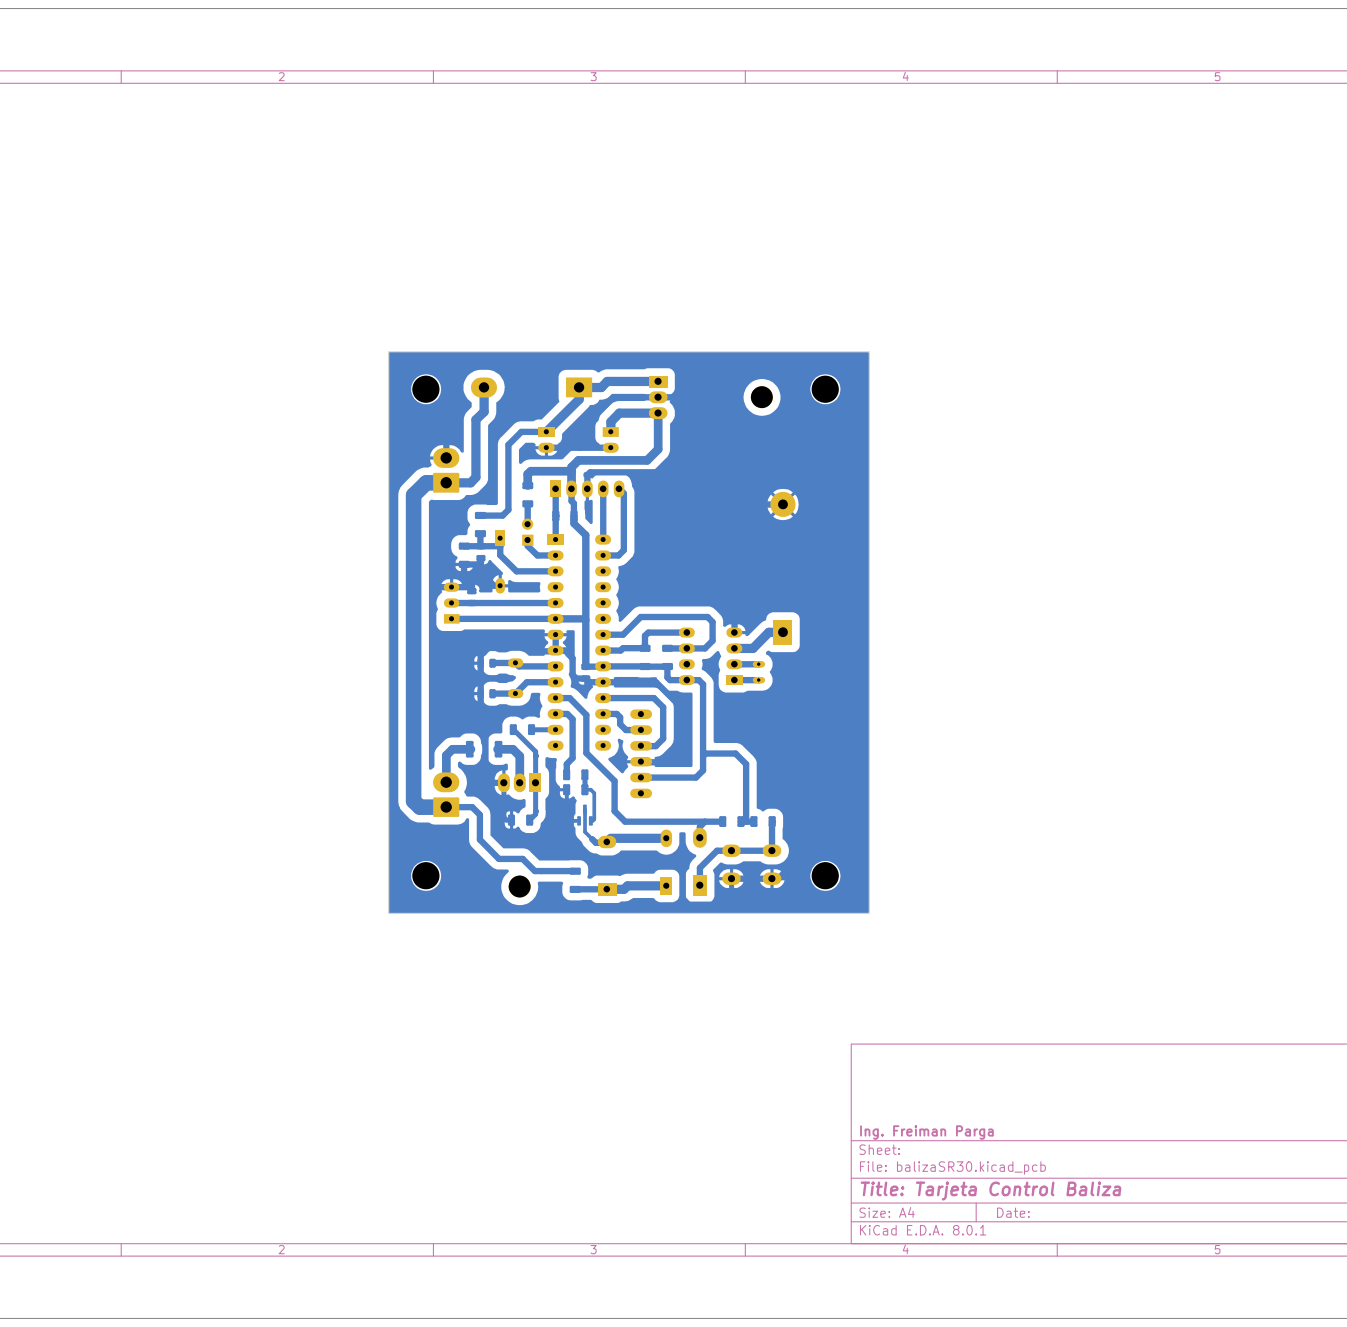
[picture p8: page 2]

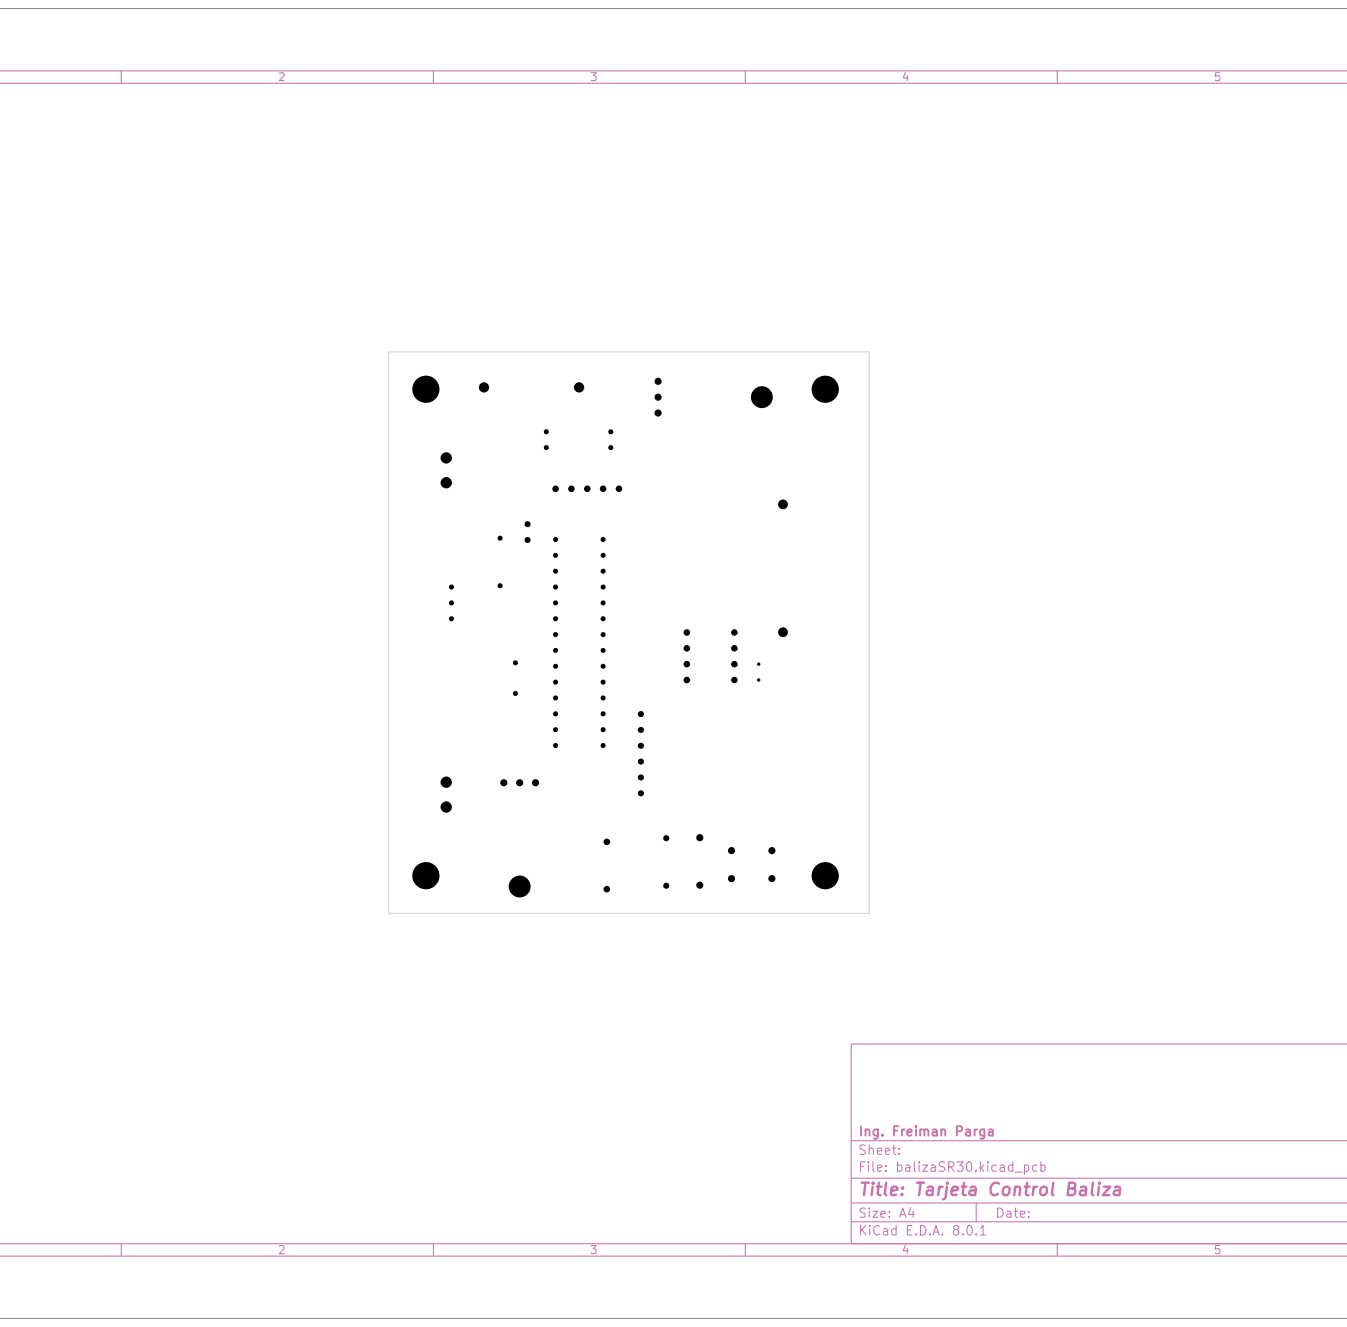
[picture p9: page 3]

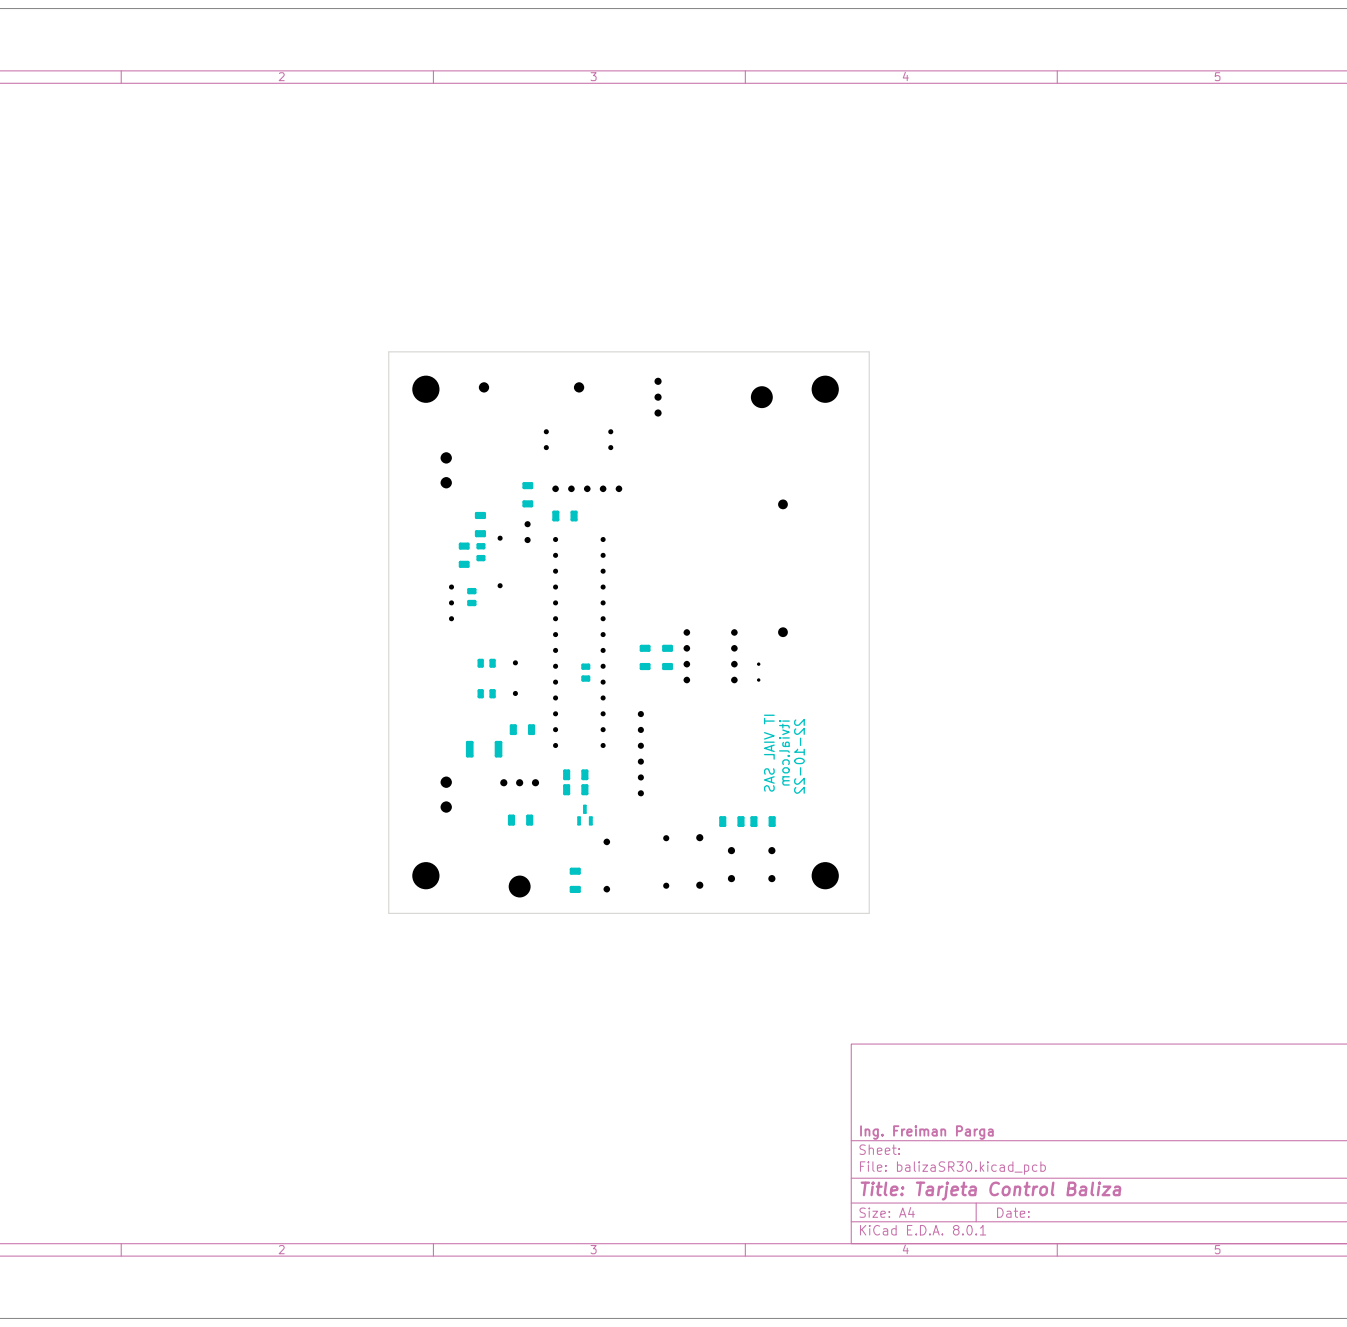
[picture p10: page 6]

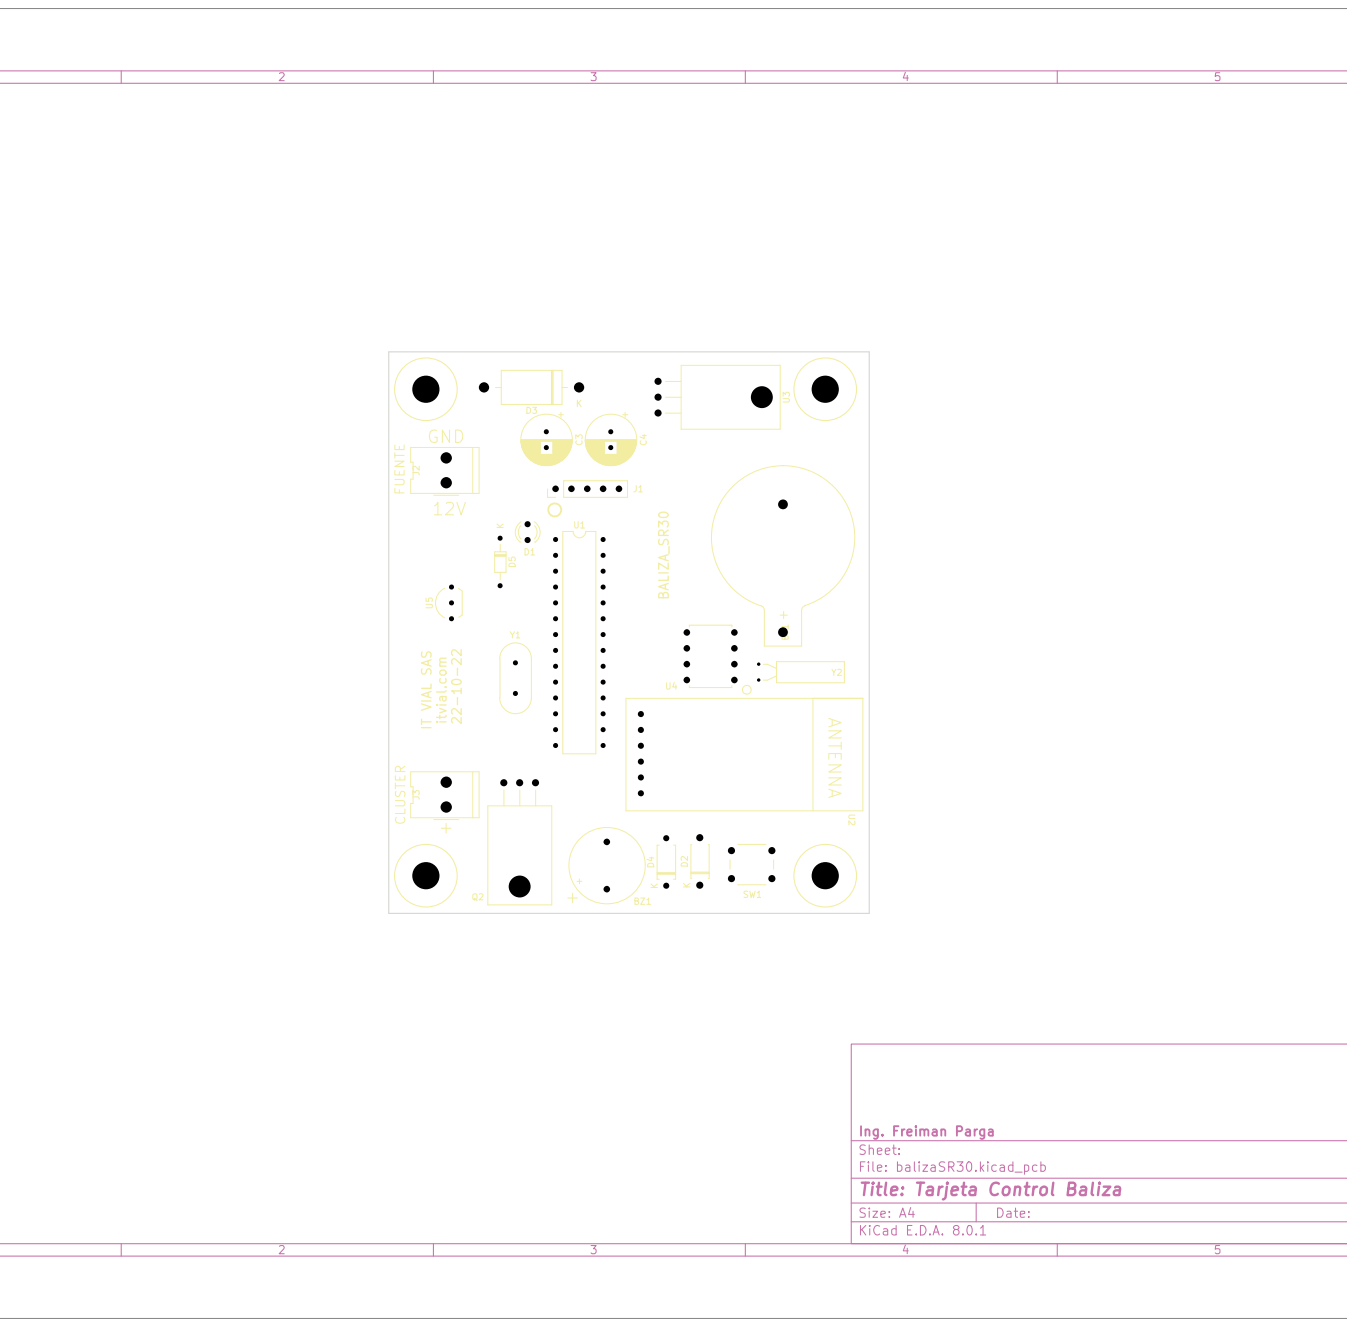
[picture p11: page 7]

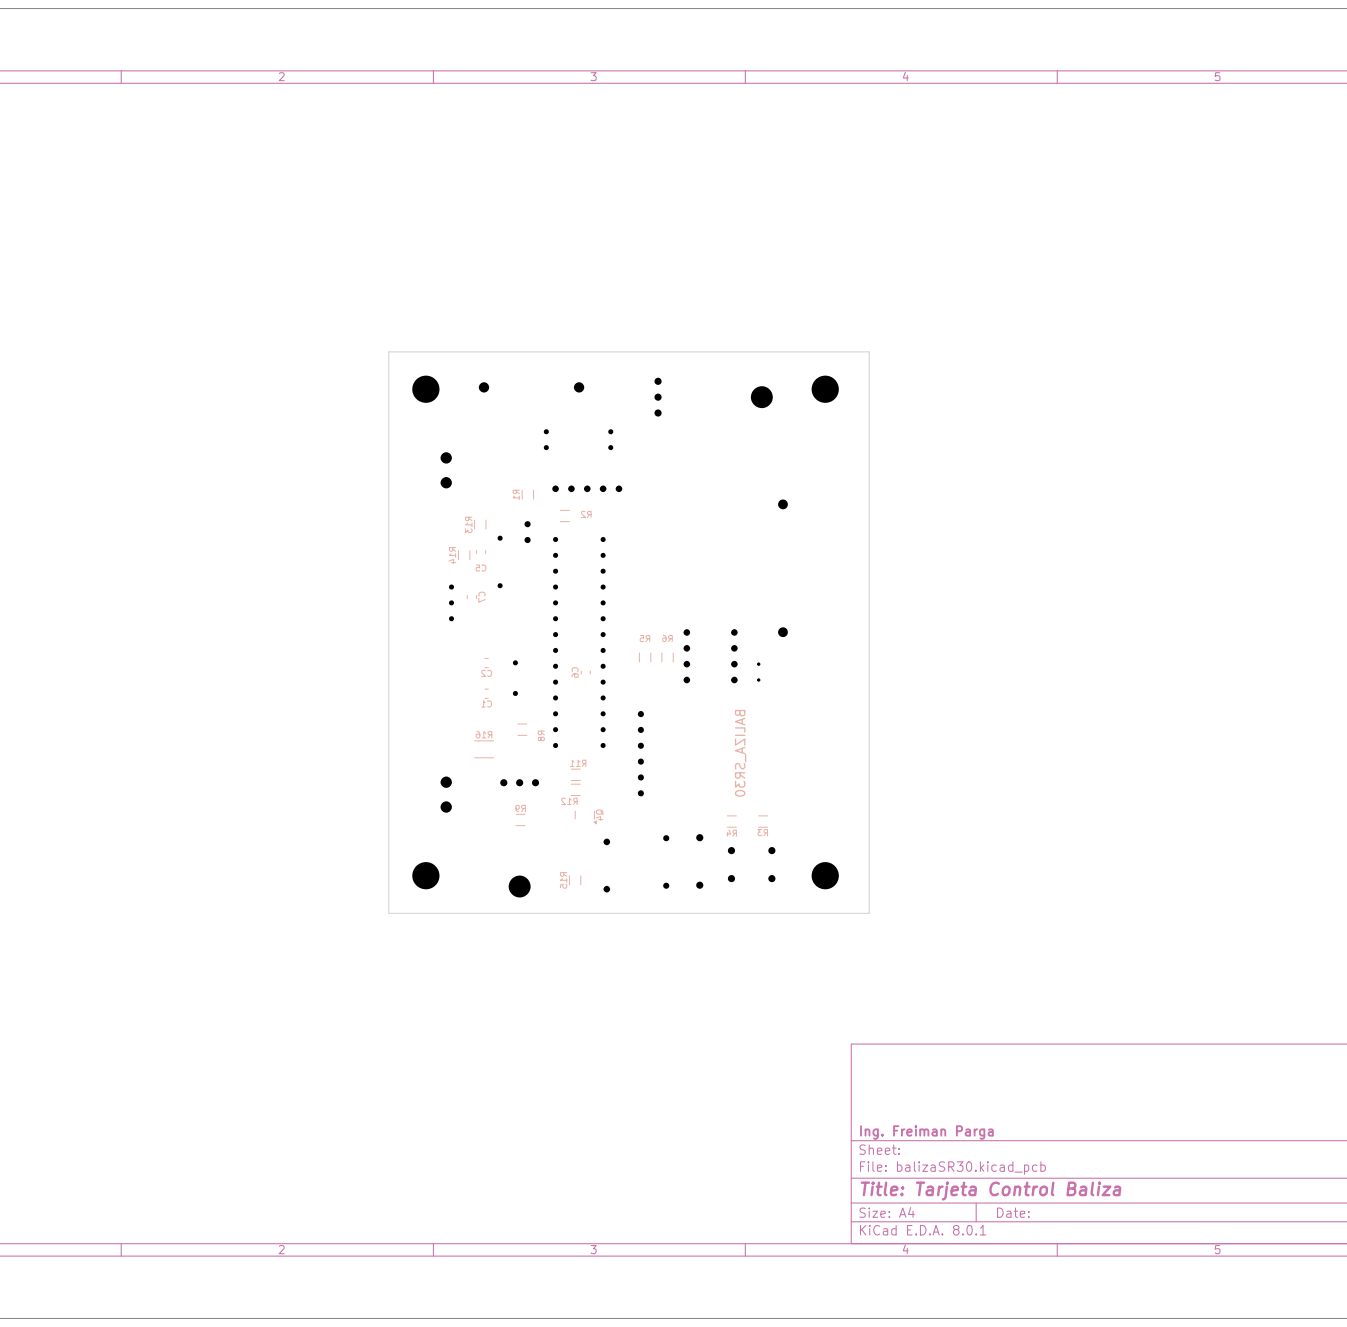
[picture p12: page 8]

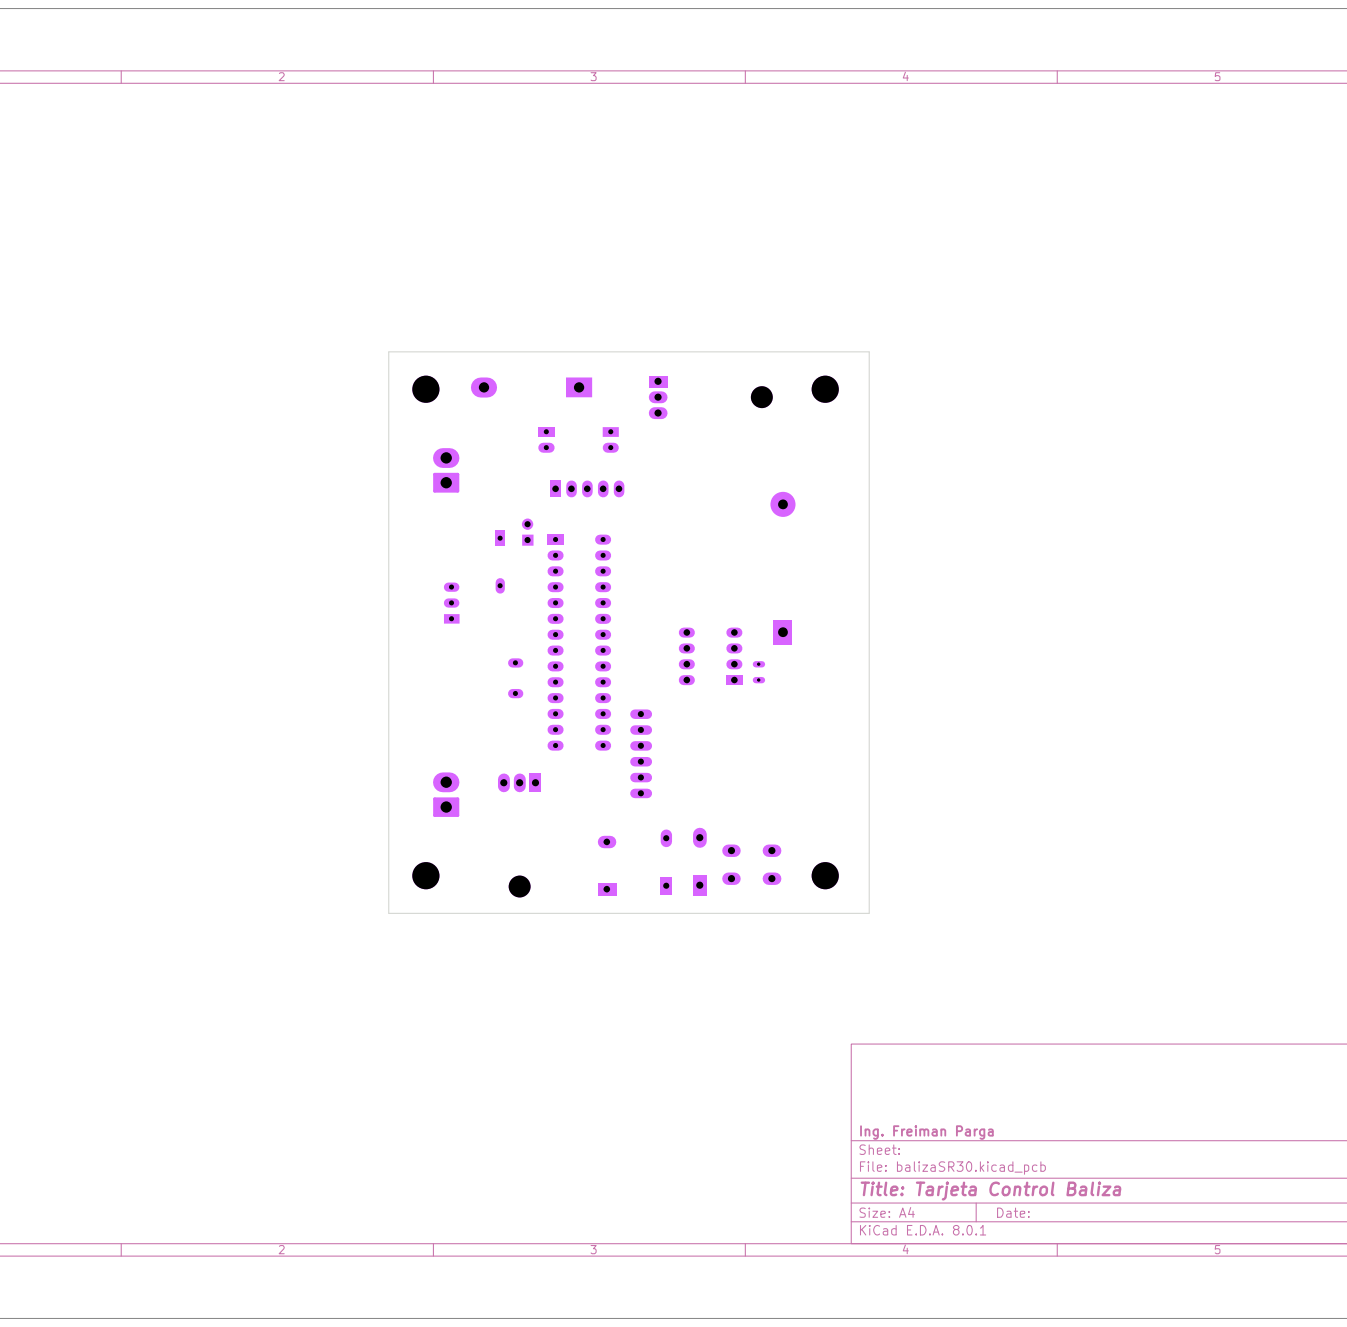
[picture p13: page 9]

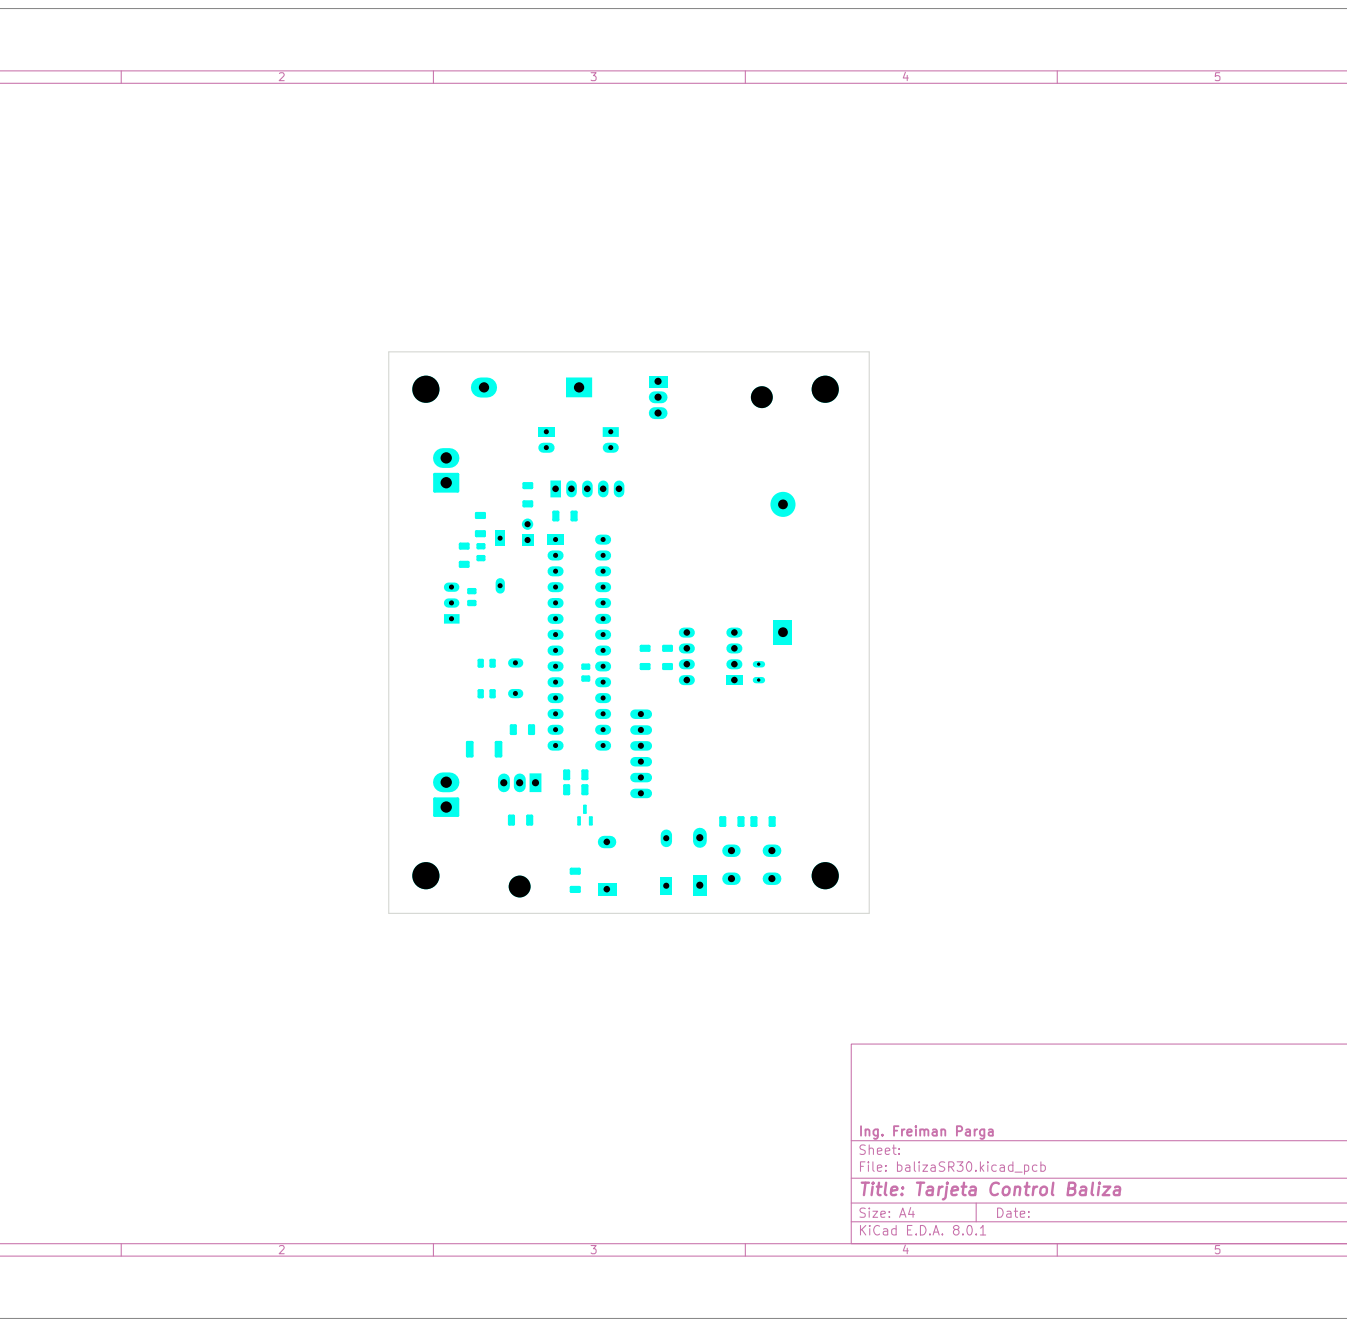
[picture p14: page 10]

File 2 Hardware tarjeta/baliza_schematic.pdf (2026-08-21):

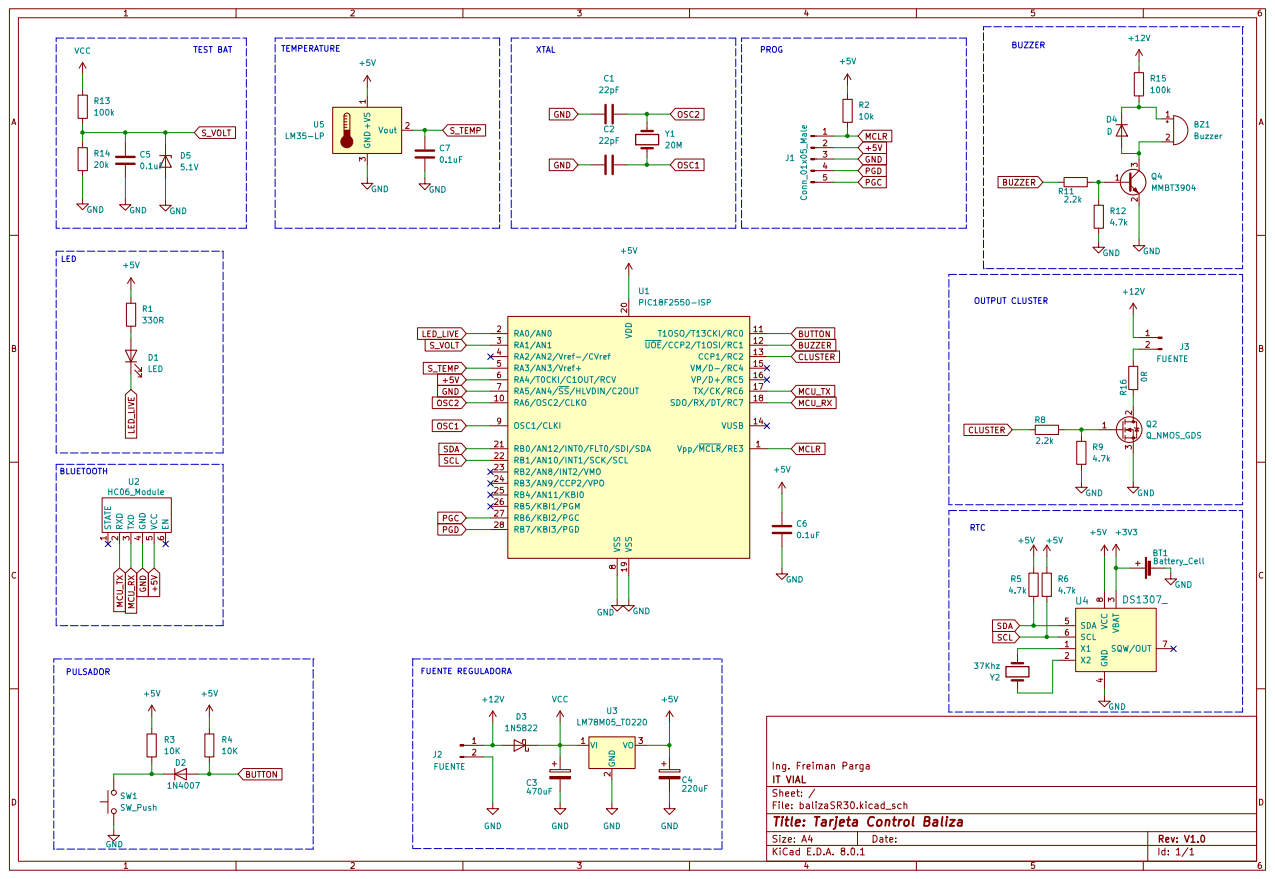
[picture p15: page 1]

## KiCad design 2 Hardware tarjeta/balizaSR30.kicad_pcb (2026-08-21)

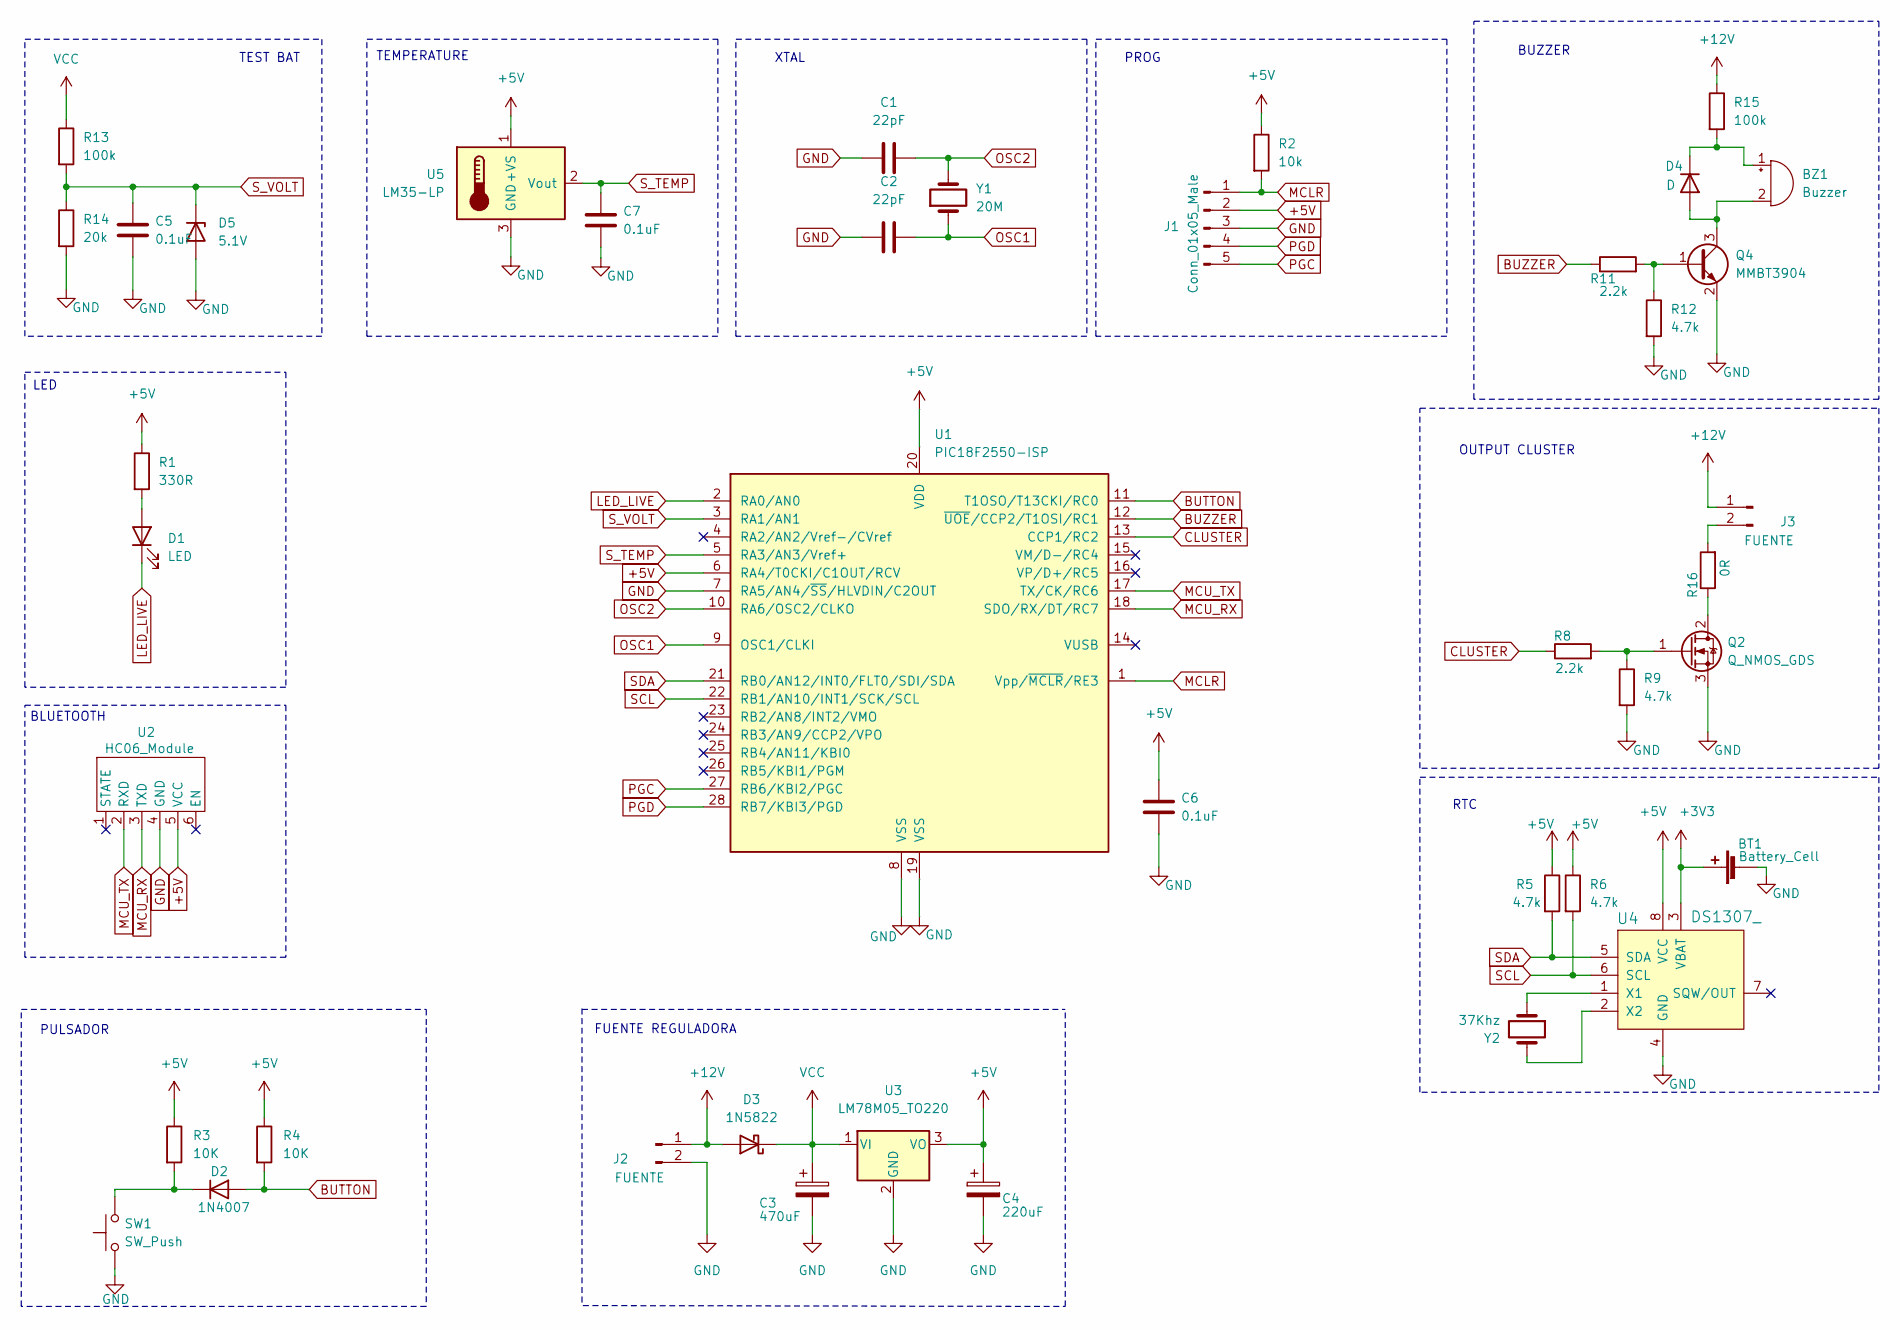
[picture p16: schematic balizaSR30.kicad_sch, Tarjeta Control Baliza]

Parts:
BT1: Battery_Cell; BatteryHolder_Keystone_103_1x20mm
BZ1: Buzzer; Buzzer_12x9.5RM7.6
C1, C2: 22pF; C_0805_2012Metric
C3: 470uF; CP_Radial_D8.0mm_P2.50mm
C4: 220uF; CP_Radial_D8.0mm_P2.50mm
C5, C6, C7: 0.1uF; C_0805_2012Metric
D1: LED; LED_D3.0mm
D2: 1N4007; D_DO-41_SOD81_P7.62mm_Horizontal
D3: 1N5822; D_DO-201AD_P15.24mm_Horizontal
D4: D; D_A-405_P7.62mm_Horizontal
D5: 5.1V; D_DO-34_SOD68_P7.62mm_Horizontal
J1: Conn_01x05_Male; PinHeader_1x05_P2.54mm_Vertical
J2, J3: FUENTE; Molex_KK-396_5273-02A_1x02_P3.96mm_Vertical
Q2: Q_NMOS_GDS; TO-220-3_Horizontal_TabDown
Q4: MMBT3904; SOT-23
R1: 330R; R_1206_3216Metric
R2: 10k; R_1206_3216Metric
R3, R4: 10K; R_1206_3216Metric
R5, R6, R9, R12: 4.7k; R_1206_3216Metric
R8, R11: 2.2k; R_1206_3216Metric
R13, R15: 100k; R_1206_3216Metric
R14: 20k; R_1206_3216Metric
R16: 0R; R_2010_5025Metric
SW1: SW_Push; SW_PUSH_6mm_H4.3mm
U1: PIC18F2550-ISP; DIP-28_W7.62mm
U2: HC06_Module; HC06
U3: LM78M05_TO220; TO-220-3_Horizontal_TabDown
U4: DS1307_; DIP-8_W7.62mm; MPN DS1307+; Digi-Key_PN DS1307+-ND
U5: LM35-LP; TO-92L_Inline_Wide
Y1: 20M; Crystal_HC18-U_Vertical
Y2: 37Khz; Crystal_AT310_D3.0mm_L10.0mm_Horizontal

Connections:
+3V3: BT1.1 (+), U4.3 (VBAT)
+5V: C4.1, C6.1, J1.2, R1.1, R2.1, R3.1, R4.1, R5.1, R6.1, U1.6 (RA4/T0CKI/C1OUT/RCV), U1.20 (VDD), U2.5 (VCC), U3.3 (VO), U4.8 (VCC), U5.1 (+VS)
+12V: D3.2 (A), J2.1, J3.1, R15.1
BUTTON: D2.2 (A), R4.2, U1.11 (T1OSO/T13CKI/RC0)
BUZZER: R11.1, U1.12 (~UOE/CCP2/T1OSI/RC1)
CLUSTER: R8.1, U1.13 (CCP1/RC2)
GND: BT1.2 (-), C1.1, C2.1, C3.2, C4.2, C5.2, C6.2, C7.2, D5.2 (A), J1.3, J2.2, Q2.3 (S), Q4.2 (E), R9.2, R12.2, R14.2, SW1.1, U1.7 (RA5/AN4/~SS/HLVDIN/C2OUT), U1.8 (VSS), U1.19 (VSS), U2.4 (GND), U3.2 (GND), U4.4 (GND), U5.3 (GND)
LED_LIVE: D1.1 (K), U1.2 (RA0/AN0)
MCLR: J1.1, R2.2, U1.1 (Vpp/~MCLR/RE3)
MCU_RX: U1.18 (SDO/RX/DT/RC7), U2.3 (TXD)
MCU_TX: U1.17 (TX/CK/RC6), U2.2 (RXD)
unnamed: BZ1.2 (+), D4.2 (A), Q4.3 (C)
unnamed: BZ1.1 (-), D4.1 (K), R15.2
unnamed: D1.2 (A), R1.2
unnamed: D2.1 (K), R3.2, SW1.2
unnamed: J3.2, R16.2
unnamed: Q2.2 (D), R16.1
unnamed: Q2.1 (G), R8.2, R9.1
unnamed: Q4.1 (B), R11.2, R12.1
unnamed: U4.1 (X1), Y2.1
unnamed: U4.2 (X2), Y2.2
OSC1: C2.2, U1.9 (OSC1/CLKI), Y1.1
OSC2: C1.2, U1.10 (RA6/OSC2/CLKO), Y1.2
PGC: J1.5, U1.27 (RB6/KBI2/PGC)
PGD: J1.4, U1.28 (RB7/KBI3/PGD)
SCL: R6.2, U1.22 (RB1/AN10/INT1/SCK/SCL), U4.6 (SCL)
SDA: R5.2, U1.21 (RB0/AN12/INT0/FLT0/SDI/SDA), U4.5 (SDA)
S_TEMP: C7.1, U1.5 (RA3/AN3/Vref+), U5.2 (Vout)
S_VOLT: C5.1, D5.1 (K), R13.2, R14.1, U1.3 (RA1/AN1)
VCC: C3.1, D3.1 (K), R13.1, U3.1 (VI)

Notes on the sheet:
LED
OUTPUT CLUSTER
FUENTE REGULADORA
PROG
BUZZER
BLUETOOTH
XTAL
RTC
TEMPERATURE
PULSADOR
TEST BAT

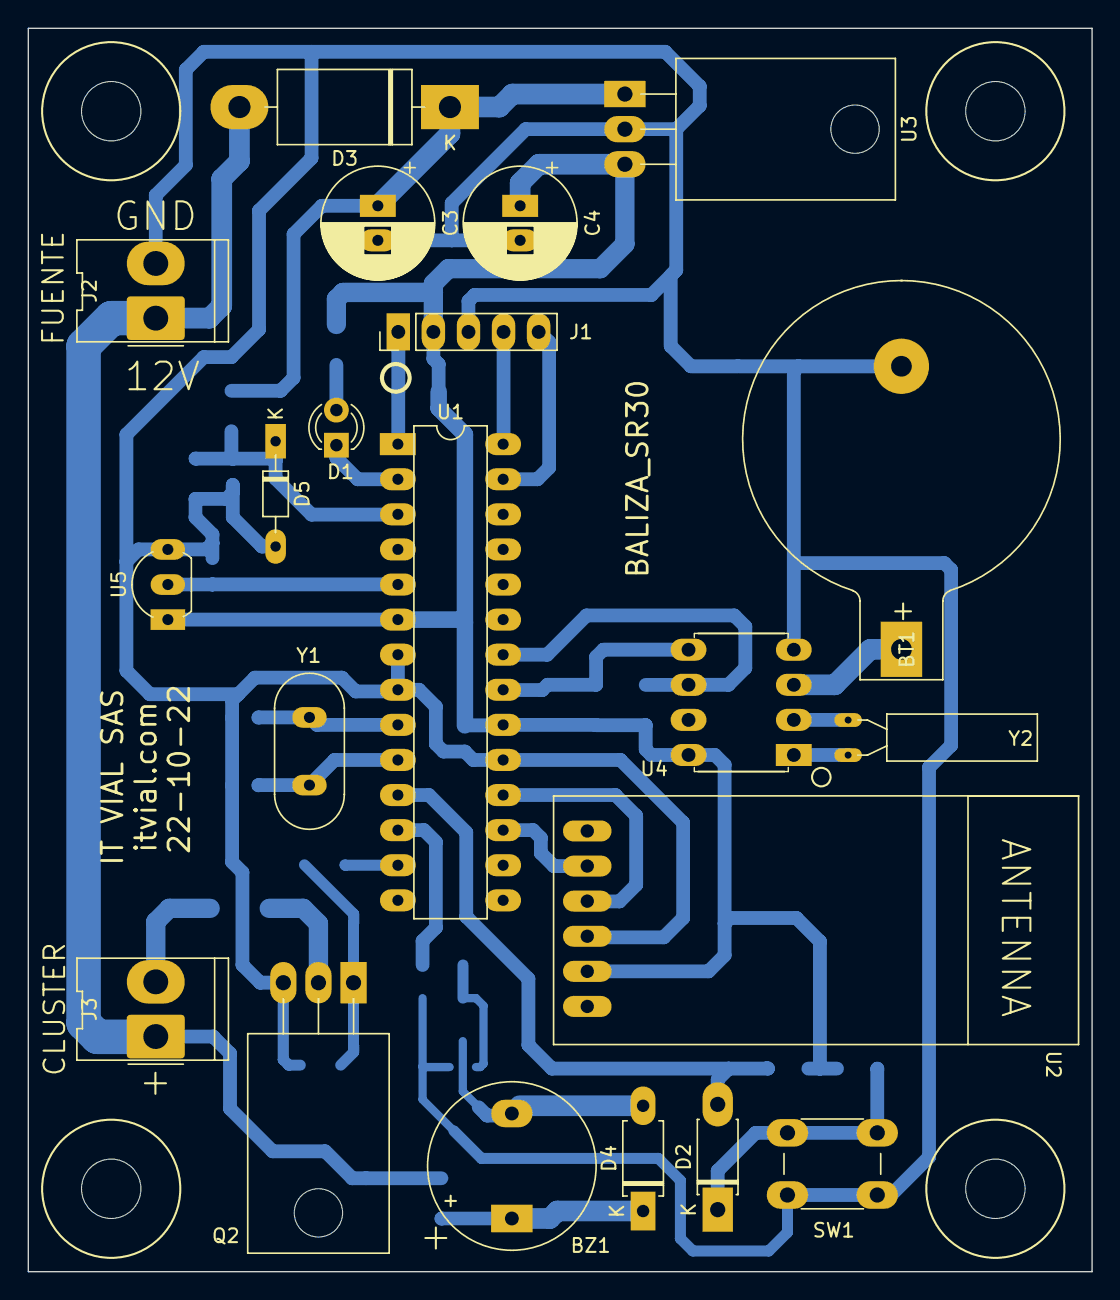
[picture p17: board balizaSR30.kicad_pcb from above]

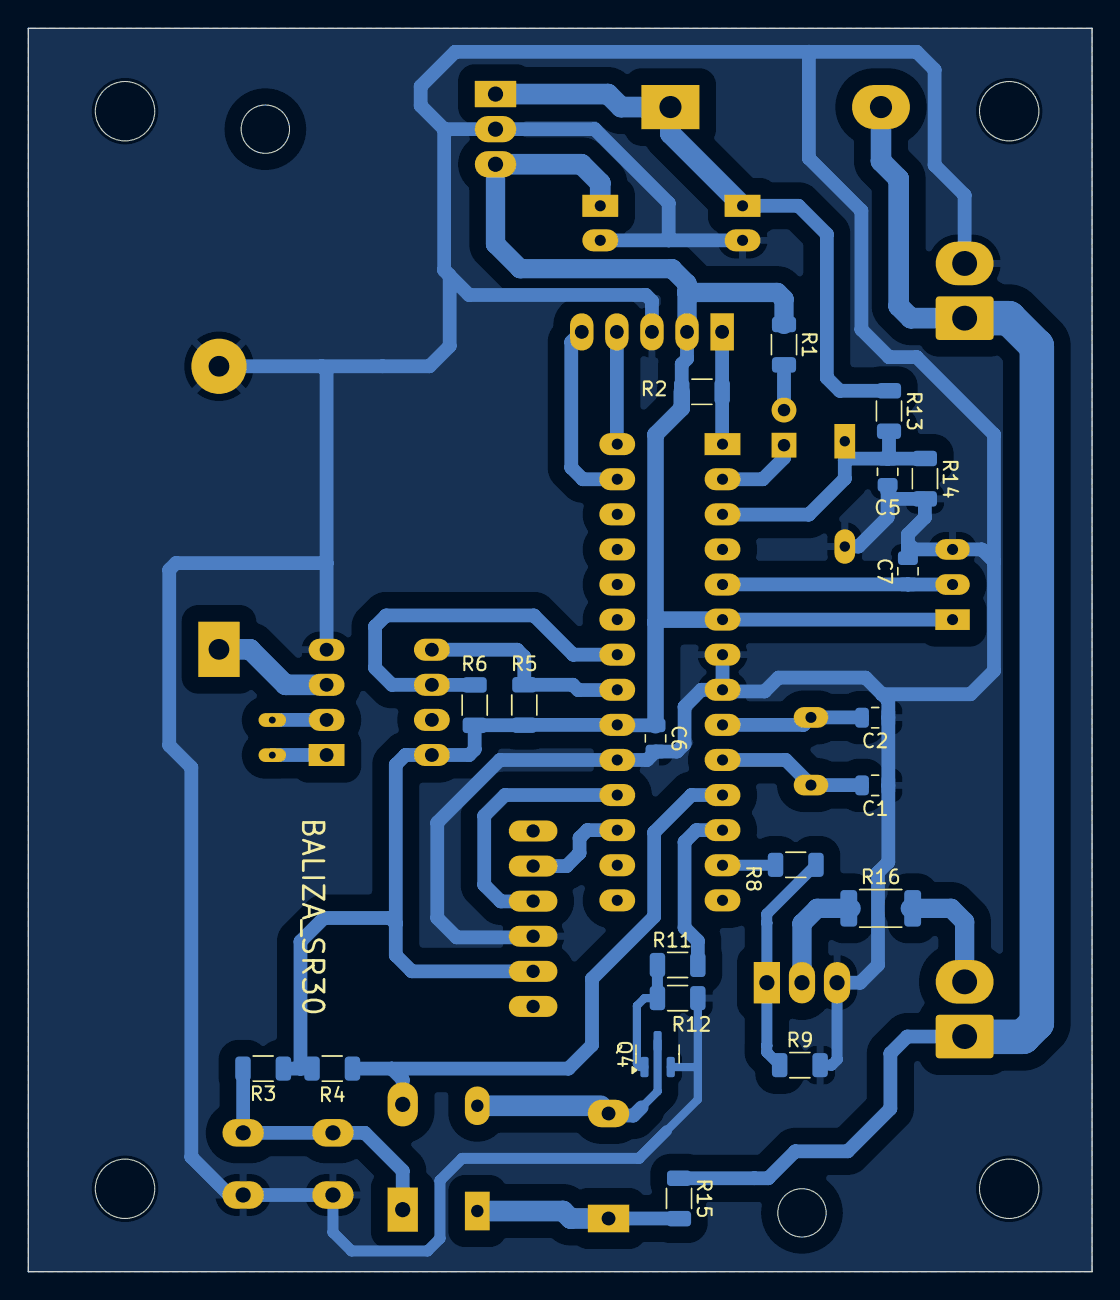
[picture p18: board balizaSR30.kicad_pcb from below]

Board: 2 copper layers, 77.0 x 90.0 mm, 41 parts (20 on the bottom side), 30 nets.

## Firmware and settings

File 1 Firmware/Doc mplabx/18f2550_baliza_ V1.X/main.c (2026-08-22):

 /**
 *  PROGRAMA BALIZA
 *  ING. FREIMAN PARGA
 *  13 DE OCTUBRE DEL 2022
 */

#include "main.h"
#include <xc.h>
#include <stdio.h>
#include "UART.h"

#include "LedLive.h"
#include "Serial.h"
#include "Aplicacion.h"
#include "I2C.h"
#include "Alarma.h"

#include "Buzzer.h"
#include "Cluster.h"
#include "Adc.h"

#include <stdint.h>

//*** ESTRUCTURAS EXTERNAS ***
extern strSerial serial1;
extern strAnaTrama anaT1;
extern strCluster cl;
//****************************

//*** VARIABLES EXTERNAS ***
extern unsigned long ulCntPeriodLedLive;
extern unsigned long ulCntPeriodAnaUart1;
extern unsigned long ulCntPeriodAplicacion;
extern unsigned long ulCntPeriodAlarm;
extern unsigned long ulCntPeriodBuzzer;
extern unsigned long ulCntPeriodCluster;
//**************************

//*** VARIABLES ***
unsigned long ulCntTick1ms; 
//*****************

/*
 * GESTION DE INTERRUPCION
 */
void __interrupt() INT_isr(void)
{
    char ch;
        
    //interrupcion por timer0
    if(INTCONbits.T0IF)
    {
        //TMR0 = 0xb3b4;
        TMR0 = 0xFFEC;
        
        INTCONbits.T0IF = 0;
        
        //si hay un minuto de tiks!!
        if(++ulCntTick1ms >= 60000)
        {
            ulCntTick1ms = 0;

            ulCntPeriodLedLive = 0;
            ulCntPeriodAplicacion = 0;
            ulCntPeriodAlarm = 0;
    //        ulCntPeriodButtons = 0;      
            ulCntPeriodBuzzer = 0;
    //        ulCntPeriodInputs = 0;
            ulCntPeriodAnaUart1 = 0;
            ulCntPeriodCluster = 0;
    //        ulCntPeriodBattery = 0;
    //        ulCntPeriodRelay = 0;
    //        ulCntPeriodAnaUart2 = 0;
        }
    
    }
    
    if(PIR1bits.RCIF)
    {
        ch = UART_read();
        //UART_write(ch);
        
        receiverUart1(&ch);
        serial1.flagRx = true;
        anaT1.uiCnt = 0;
    }
}


/*
 * GESTION DE INTERRUPCIONES DE BAJA PRIORIDAD
 */
void __interrupt(low_priority) INT_ISR_LOW (void)
{
    if(INTCON3bits.INT1IF)
    {
        INTCON3bits.INT1IF = 0;
    }
}





//*** MAIN ***




void main(void) 
{
    
    ADCON1 = 0X0F;
    INT_init();
    UART_init_baud(9600);
    ADC_init();
    
    pinConfLedPin();
    I2C_Master_Init(100000);
    pinConfBuzzer();
    pinConfCluster();
    
    
    startTaskLedLive();
    startTaskAnalizaUart1();
    startTaskAplicacion();
    startTaskAlarm();
    startTaskBuzzer();
    startTaskCluster();
    while(1)
    {
#ifndef _SIMULATION_
        ClrWdt();
#endif
        executeTaskLedLive();
        executeTaskAnalizaUart1();
        executeTaskAplicacion();        
        executeTaskAlarm();
        executeTaskBuzzer();
        executeTaskCluster();
    }
}



/*
 * CONFIGURACION DE LAS INTERRUCCIONES
 */
void INT_init(void)
{
        
    //se habilitan las interrupciones 
    RCONbits.IPEN = 1;          //habilitamos prioridad
    INTCONbits.GIEH = 1;
    INTCONbits.GIEL = 1;
    // INTCONbits.GIE = 1;   
    
    INTCONbits.TMR0IE = 1;       //flag interrupt tmr0
    INTCONbits.GIE = 1;         //enable interrupts global
    
    //recarga de timer
    //TMR0 = 0xb3b4;
    TMR0 = 0xFFEC;
    T0CON = 0x87;       //preescaler
}



/******************************************
* Inicialización del ADC
******************************************/

/* ADC_init() se movio a Adc.c para que el arnes pueda compilarlo. Ver Adc.c. */

/*****************************************
* Lectura de un canal Analogico
*****************************************/

uint16_t ADC_read(uint8_t channel)
{
    ADCON0bits.CHS = channel;                  
    ADCON0bits.GO = 1;                         
    while(ADCON0bits.GO_DONE);                 
    return ((uint16_t)((ADRESH<<8)+ADRESL));   
}

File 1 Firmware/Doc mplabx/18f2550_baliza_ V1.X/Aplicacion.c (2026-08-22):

/*
 * APLICACION BALIZA TEMPORIZADA
 * AUTOR: ING. FREIMAN PARGA
 * 14 DE OCTUBRE DEL 2022
 * VERSION 1.0
 */

/*
 * OBSERVACIONES:
 *              
 * PENDIENTES:
 *              
 */

#include "Aplicacion.h"
#include "main.h"
#include "DS1307.h"

#include "string.h"

#include "Serial.h"

#include "stdio.h"
#include "Buzzer.h"
#include "EEprom.h"
#include "Alarma.h"
#include "Cluster.h"


//*** ENUM ***
enum states_aplicacion stateAp;
//************

//*** ESTRUCTURAS EXTERNAS ***
//extern strButtons button;
extern strAnaTrama anaT1;
extern strRtc rtc;
extern strSerial serial1;
//extern strRelay rly;
extern strAlarm ala;
extern strCluster cl;
//****************************

//*** ESTRUCTURAS ***
strAplicacion ap;
strMemory memo;
//*******************
 

char hor,min,seg,dia,mes,ano,diaSe;   

unsigned long ulCntPeriodAplicacion = 0;

static struct pt ptTaskAplicacion;

static int taskAplicacion(struct pt *pt)
{
    
    PT_BEGIN(pt);
    while (1) 
    {
        ulCntPeriodAplicacion = getMillis() + PERIOD_APLICACION;
        PT_WAIT_UNTIL(pt, getMillis() >= ulCntPeriodAplicacion); 
       
        switch(stateAp)
        {
            //ESTADO QUE ESPERA ESTABILIZACION DEL SISTEMA
            case ST_ARRANQUE_AP:                
                if(++ap.uiCntAplicacion >= TIME_ARRANQUE)
                {  
                    

                    ap.flagArranque = true;
                    reiniciarTemporizador(&ap.uiCntAplicacion);
                    
                    
                    
                    twoBeep();
                    cambiarEstado(ST_READ_MEMO_AP);
                }                
                break;
                
            case ST_READ_MEMO_AP:
                if(inicioEstado(ST_READ_MEMO_AP))
                {
                    reiniciarTemporizador(&ap.uiCntAplicacion);
                }
                else
                {
                    if(++ap.uiCntAplicacion >= 200)
                    {
                        memo.ucInitMemory = EEpromRead(ADDRESS_INIT_EEPROM);
                        
                        if(memo.ucInitMemory != INIT_VALUE_EEPROM)
                        {
                            EEpromWrite(ADDRESS_INIT_EEPROM, INIT_VALUE_EEPROM);
                            twoBeep();    
                            
                            EEpromWrite(ADDRESS_EN_ALA1, 0);
                            EEpromWrite(ADDRESS_FLAGDAYALA1, 0);
                            EEpromWrite(ADDRESS_DAYWEEK1, 8);
                            EEpromWrite(ADDRESS_INIT_HOUR1, 0);
                            EEpromWrite(ADDRESS_INIT_MIN1, 0);
                            EEpromWrite(ADDRESS_END_HOUR1, 0);
                            EEpromWrite(ADDRESS_END_MIN1, 0);
                            
                            EEpromWrite(ADDRESS_EN_ALA2, 0);
                            EEpromWrite(ADDRESS_FLAGDAYALA2, 0);
                            EEpromWrite(ADDRESS_DAYWEEK2, 8);
                            EEpromWrite(ADDRESS_INIT_HOUR2, 0);
                            EEpromWrite(ADDRESS_INIT_MIN2, 0);
                            EEpromWrite(ADDRESS_END_HOUR2, 0);
                            EEpromWrite(ADDRESS_END_MIN2, 0);
                            
                            EEpromWrite(ADDRESS_EN_ALA3, 0);
                            EEpromWrite(ADDRESS_FLAGDAYALA3, 0);
                            EEpromWrite(ADDRESS_DAYWEEK3, 8);
                            EEpromWrite(ADDRESS_INIT_HOUR3, 0);
                            EEpromWrite(ADDRESS_INIT_MIN3, 0);
                            EEpromWrite(ADDRESS_END_HOUR3, 0);
                            EEpromWrite(ADDRESS_END_MIN3, 0);
                            
                            EEpromWrite(ADDRESS_EN_ALA4, 0);
                            EEpromWrite(ADDRESS_FLAGDAYALA4, 0);
                            EEpromWrite(ADDRESS_DAYWEEK4, 8);
                            EEpromWrite(ADDRESS_INIT_HOUR4, 0);
                            EEpromWrite(ADDRESS_INIT_MIN4, 0);
                            EEpromWrite(ADDRESS_END_HOUR4, 0);
                            EEpromWrite(ADDRESS_END_MIN4, 0);
                            
                            EEpromWrite(ADDRESS_EN_ALA5, 0);
                            EEpromWrite(ADDRESS_FLAGDAYALA5, 0);
                            EEpromWrite(ADDRESS_DAYWEEK5, 8);
                            EEpromWrite(ADDRESS_INIT_HOUR5, 0);
                            EEpromWrite(ADDRESS_INIT_MIN5, 0);
                            EEpromWrite(ADDRESS_END_HOUR5, 0);
                            EEpromWrite(ADDRESS_END_MIN5, 0);
                            EEpromWrite(0x30, 0xAA);
                            EEpromWrite(0x36, 0x00);
                            EEpromWrite(0x37, 0x00);
                            
                            cambiarEstado(ST_READ_MEMO_AP);
                        }
                        else
                        {                            
                            //aca se deben leer los valores que se encuentran en la memoria
                            readMemoriaValues();
                            ala.flagUpdate = true;      //actualizar los valores  
                            
                            // Incrementar contador de reinicios / cortes de energia (EEPROM 0x36-0x37)
                            uint16_t cnt_cortes = ((uint16_t)EEpromRead(0x36) << 8) | EEpromRead(0x37);
                            if(cnt_cortes == 0xFFFF) cnt_cortes = 0;
                            cnt_cortes++;
                            EEpromWrite(0x36, (uint8_t)(cnt_cortes >> 8));
                            EEpromWrite(0x37, (uint8_t)(cnt_cortes & 0xFF));
                            transmitUart1((char*)"\n\rBALIZA ALARMA V1.0\n\r\n\r");
                            
                            
                            ap.uiCntVolt = TIME_READ_VOLT;
                            ap.uiCntTemp = TIME_READ_TEMP;
                            cambiarEstado(ST_ESPERA_AP);
                        }
                        
                    }                    
                }
                break;
                
            case ST_PRUEBA_AP:
                
               
                break;
                
            
            case ST_ESPERA_AP:
                if(inicioEstado(ST_ESPERA_AP))
                {
                    reiniciarTemporizador(&ap.uiCntAplicacion);
                }
                else
                {
                    if(serial1.flagEventoRead)
                    {
                        serial1.flagEventoRead = false;
                        oneBeep();
                        readDevide();
                    }
                    else if(serial1.flagEventReloj)
                    {
                        serial1.flagEventReloj = false;                        
                        oneBeep();
                    }
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

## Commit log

2026-08-21 Estado inicial del proyecto Baliza: documentacion, simulador y skills
    Primer commit del repositorio. Recoge el equipo tal y como esta hoy y
    lo que hace falta para poder trabajarlo sin ir al poste.
    El equipo es la luz intermitente de una senal vial "30 CUANDO ACTIVADA"
    en zona escolar, sobre PIC18F2550. El horario en que debe titilar va
    impreso en una chapa atornillada a la senal, asi que cualquier desajuste
    entre lo programado y esa chapa hace que la senal mienta a los
    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
    [Lista de componentes Baliza.xls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]
2026-08-21 Bluetooth: pinout contradictorio, y compilacion verificada con XC8
    BLUETOOTH.md y MANUAL_FUNCIONAL_BLUETOOTH.md quedan terminados, y la
    investigacion cambio la prioridad del roadmap.
    Hallazgo que pasa a ser el primer paso de todo:
    El SIG0109A es casi con seguridad un JDY-31 / "SPP-C" (mismo BK3231S), y
    su pinout esta documentado de dos formas CONTRADICTORIAS: el manual da
    STATE-RXD-TXD-GND-VCC-EN y una fuente con foto de la placa real da
    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
2026-08-21 Cierra FIRMWARE.md, y la cadencia de la luz gana una tercera cifra
    FIRMWARE.md queda completo: 2001 lineas, con un catalogo de 45 defectos
    con fichero y linea. Los siete que mandan el trabajo estan ademas MEDIDOS
    por el simulador, y la seccion 9.3 los cruza con su escenario -- que es
    una fuente mas fiable que una explicacion escrita. Los 38 restantes
    quedan en la tabla resumen con su gravedad y su ubicacion.
    CADENCIA DE LA LUZ: ahora hay TRES cifras y ninguna coincide.
    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
2026-08-21 Anade el encargo para el agente que ejecutara las fases 1 y 2
    PROMPT_AGENTE_FASE1.md: el encargo autocontenido que se le pasa a un
    agente para que implemente los arreglos del firmware. Escrito para
    alguien que no ha visto el proyecto nunca.
    Lleva el criterio de aceptacion en cifras, que es lo que lo hace
    verificable: hoy el simulador da 33 comprobaciones, 24 ok y 9 FALLA; al
    terminar tiene que dar 31 ok y 2 FALLA, y los 2 que queden tienen que ser
    exactamente los dos del escenario C -- los de la cadencia, que sigue sin
    decidirse. Si queda en rojo cualquier otra cosa, no ha terminado.
    Deja fuera del alcance, explicitamente, lo que hoy no se puede cerrar:
    Cluster.c y la cadencia (tres cifras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
2026-08-21 fix(firmware): evaluar arranque en franja y franjas solapadas en Alarma.c (T1 y T2)
    - Evalua intervalo horario [H_init, H_end) en lugar de igualdad exacta de minuto
    - Evalua si alguna alarma sigue activa antes de apagar ap.flagAlarm
    - Simulador: 33 comprobaciones | 27 ok | 6 FALLA (D1 y D6 en verde)
2026-08-21 fix(firmware): blindar parser serie, corregir transmitUart1 y validar dias (T3, T4, T5)
    - Blindar extraerValue, extraerFrame y receiverUart1 contra NULL y desbordamiento de buffer (D5)
    - Rechazar dias no soportados (1..7) de forma segura sin colgar la maquina de estados (D2, D3)
    - Corregir indice en transmitUart1 para no enviar byte NUL extra (D4)
    - Simulador: 33 comprobaciones | 31 ok | 2 FALLA (solo escenario C pendiente)
2026-08-21 Manuales en carpeta propia y en .docx, y el arnes vuelve a medir
    MANUALES
    Los seis documentos tecnicos pasan a Manuales/, cada uno en .md y en
    .docx generado con pandoc. La raiz se queda con lo de gobierno del
    proyecto: README, ROADMAP, ESTADO, CLAUDE y el encargo del agente.
    Actualizados todos los enlaces cruzados, incluidos los de las skills.
    Manuales/generar_word.py regenera los Word desde el .md, que es la
    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
2026-08-21 fix(firmware): mapear buzzer en RC1 y mantener RC0 como entrada pulsador (T6)
    - Actualizar ON_BUZZER/OFF_BUZZER a LATC1 y pinConfBuzzer (TRISC1=0, TRISC0=1)
    - Actualizar plataforma de simulacion y agregar escenario T6 (4 comprobaciones)
    - Simulador: 37 comprobaciones | 35 ok | 2 FALLA (solo escenario C pendiente)
    [plataforma.c]
2026-08-21 docs: registrar decision funcional de cadencia (1 Hz, 500ms ON / 500ms OFF) y actualizar estado
    - Registrar decision oficial aprobada por el funcional: 1.0 Hz (500 ms ON / 500 ms OFF, 60 destellos/min)
    - Actualizar metricas del simulador: 37 comprobaciones | 35 ok | 2 FALLA (escenario C)
2026-08-21 docs: vincular transcripcion de reunion de especificacion tecnica a ROADMAP.md (1 Hz)
2026-08-21 fix(firmware): implementar cadencia 1 Hz, eliminar estados redundantes y corregir arnes
    - Cluster.c: programar cadencia de 1.0 Hz (500 ms ON / 500 ms OFF) uniforme y continua
    - Cluster.h: anadir guarda de inclusion #ifndef CLUSTER_H
    - Alarma.c: limpiar codigo muerto de dias no soportados y eliminar estados redundantes (escritor unico via isAlarmActive)
    - Alarma.h: simplificar enum states_alarm
    - arnes.c: eliminar declaracion duplicada de ala1 y corregir escape hex \xBF en hijo_trama_truncada
    - Simulador: 37 comprobaciones | 37 OK | 0 FALLA (100% PASS)
2026-08-21 Revision de las fases 1 y 2: verificado, y los documentos al dia
    REVISION
    Corrido el simulador DESDE LIMPIO (obj/ y arnes.exe borrados) para no
    repetir lo de la vez anterior, cuando las cifras salian de un ejecutable
    viejo:
    MIDIERON: 37 comprobaciones ok: 37 FALLA: 0 -> PASS
    Y compilado con XC8: salida 0, 21147 de 32768 bytes (64,5 %).
    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
2026-08-21 docs(roadmap): estructurar plan de trabajo para modernizacion de la app movil v2.0 (Fase 4)
2026-08-21 fix(app): corregir hora 02, comparaciones equals, anadir ScrollView y optimizar lectura Bluetooth (Fase 4.1)
    [MainActivity2.java]
2026-08-21 docs(roadmap): registrar validacion fisica en banco del enlace UART/Bluetooth y agregar especificacion de Modo Test para App v2.0
2026-08-21 fix(app): solicitar permisos runtime de Bluetooth para evitar cierre inesperado al presionar Dispositivo
    [MainActivity2.java]
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2026-08-21 fix(app): corregir codificacion de tramas a ISO-8859-1 y captura directa de stream Bluetooth
    [MainActivity2.java]
2026-08-21 fix(app): eliminar bytes nulos en tramas de sincronizacion horaria y asegurar comas de protocolo
    [MainActivity2.java]
2026-08-21 build(app): versionar formalmente como v2.1 con indicativo visible en pantalla y nombre de APK
2026-08-21 docs: actualizar README, ROADMAP, ESTADO, CLAUDE, Manuales y Skills con validación física de Bluetooth y App v2.1
2026-08-21 build(app): version v2.3 con lectura bloqueante directa en stream Bluetooth para eliminar retrasos
2026-08-21 build(app): version v2.4 con auto-lectura al seleccionar Bluetooth y purga de stream
2026-08-21 build(app): version v2.5 con autoreconexion transparente ante reinicio de alimentacion del PIC
2026-08-21 docs: registrar validacion exitosa de sincronizacion RTC en banco real con App v2.5
2026-08-21 docs: actualizar README y ESTADO con version v2.5 de la App y validacion fisica de RTC en banco
2026-08-21 feat(app): version v2.6 con Modo Test de Luces Inmediato (2 Min) y Apagado Manual
2026-08-21 docs: registrar App Baliza v2.6 con Modo Test de Luces (2 Min) en README, ESTADO y ROADMAP
2026-08-21 fix(ui): rediseño visible y responsivo de pantalla de login con bordes, etiquetas y version v2.7
2026-08-21 fix(ui): forzar alto contraste y texto negro en temas Light y Night de Android v2.8
2026-08-21 docs: registrar App Baliza v2.8 con soporte blindado de temas Claro/Oscuro en README, ESTADO y ROADMAP
2026-08-21 feat(branding): integrar logos oficiales IT Vial s.a.s., icono de app y nombre IT Vial v2.9
2026-08-21 feat(app): version v3.0 con boton de 1-toque para Programar Horario Escolar Oficial completo
2026-08-21 fix(branding): actualizar nombre oficial a Baliza ITVIAL v3.1
    [MainActivity2.java]
2026-08-21 fix(branding): establecer nombre exacto BALIZA IT VIAL 30 en v3.2
    [MainActivity2.java]
2026-08-21 docs: actualizar exhaustivamente README, ROADMAP, ESTADO y APP_MOVIL con la version v3.2 BALIZA IT VIAL 30
2026-08-21 fix(ui): icono IT Vial exclusivo en escritorio, titulo en ActionBar y botones de test verticales v3.3
    [MainActivity2.java]
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2026-08-21 docs: actualizar manuales con el resultado de prueba fisica OK y el cruce del .map
2026-08-22 docs: manual de usuario corporativo app movil IT VIAL 30 v3.3 con capturas HD, guia de baterias y actualizacion de roadmap v3.4+
2026-08-22 docs: corregir ilustracion de senal vial integrando cluster LED dentro de la lamina retroreflectiva segun placa real
2026-08-22 docs: alinear manual de usuario y markdown al flujo real de 10 pasos de la app, fijar estandares de estilo en CLAUDE.md y ROADMAP.md
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2026-08-22 fix(firmware): timeout en I2C_Wait, soft timeout 1s en UART, transmitUart1 por puntero, fix memset/strlen y nuevo test D7 en simulador (41/41 PASS)
    [Aplicacion.c, I2C.c]
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2026-08-22 feat(app): incorporar diagnostico automatico de pila RTC CR2032, bateria 12V y generacion de ordenes de mantenimiento preventivo
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2026-08-22 feat(app): implementar motor de autodiagnostico experto en la App para entregar dictamen y accion correctiva inmediata en campo sin esperar a soporte
    [MainActivity2.java]
2026-08-22 feat(app): incorporar checklist de mantenimiento preventivo y trazabilidad de garantia en la App y reportes exportados
    [MainActivity2.java]
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2026-08-22 fix(emulator): conectar botones LEER y CONFIG con la API real del backend en C, refrescar telemetria y semaforo de autodiagnostico en tiempo real
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2026-08-22 fix(ui): filtrar etiquetas internas de depuracion del simulador en la consola para una visualizacion limpia de telemetria
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2026-08-22 fix(test): sincronizar protocolo oficial de prueba de foco (Alarma 5 temporal 2 min) y mostrar tramas detalladas en terminal UART
2026-08-22 fix(js): asegurar elemento consoleBox en el DOM y hacer funcion log() 100% null-safe para eliminar error TypeError en navegador
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2026-08-22 fix(git): versionar el APK de campo v3.4 y el .map del binario entregado
    El README y el ROADMAP enlazaban los dos ficheros por ruta, pero ambos estaban
    en .gitignore: "7 sw apk/" entera (por el JDK y el Android SDK, casi 750 MB) y
    "*.map". Para cualquiera que clonara el repositorio el entregable no existia, y
    el commit 462a7f9 anuncio "integrar binario instalador" sin llegar a incluirlo.
    Las excepciones son nominales, no por patron: el JDK, el SDK y los .zip de
    "7 sw apk/" siguen ignorados. Verificado con git check-ignore.
    Claude-Session: https://claude.ai/code/session_01KFsbnVXHniY2GEBem2YtWE
2026-08-22 docs: auditoria del 22-ago-2026 sobre README, ROADMAP, CLAUDE.md y skills
    Todo lo que aqui se afirma esta medido, no declarado.
    Corregido lo que estaba desactualizado:
    - El arnes son 58 comprobaciones, no 33 (CLAUDE.md). Corrio hoy: 58/58 PASS.
    - El buzzer YA ESTA ARREGLADO: Buzzer.h:24 ataca LATC1 y pinConfBuzzer() pone
    TRISC1=0, que es lo que pide la placa. CLAUDE.md y la skill verificar seguian
    anunciandolo como roto en RC0 -- justo el "rojo esperado ya arreglado que
    sigue anunciado" contra el que avisa la propia skill.
    - Las referencias a "ROADMAP 0.1" y "ROADMAP 2.2" apuntaban a puntos que ya no
    existian tras la reescritura del ROADMAP.
    Encontrado un defecto vivo que las 58 co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
2026-08-22 fix(release): rescatar los binarios de la v3.3 y restaurar el paquete sellado
    La v3.3 es la linea base: la pareja que funciono contra una senal real, segun
    confirmo el responsable. Son dos ficheros, y ninguno estaba en el repositorio.
    firmware 1 Firmware/Doc mplabx/build_xc8/main.hex 59.577 B c14b4350d960
    app 1 Firmware/Baliza_v3.3.apk 3.859.625 B 9c37d599deb9
    Identificados por tres vias independientes: el tamano en KiB (58) que reporto el
    responsable, el tamano en kB decimal (59,5) que declara el LEEME del release, y
    los 12 primeros caracteres del sha256 que ese mismo LEEME publica.
    Lo que estaba roto:
    - Release_v3.3/ se sello a las 10:08 y su Binarios/BALIZA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
2026-08-22 fix(git): marcar .hex/.map/.apk como binary para que git no altere los entregables
    La maquina tiene core.autocrlf=true y no habia .gitattributes. Un .hex es texto,
    asi que git guardaba los tres .hex con los saltos de linea convertidos: el blob
    almacenado NO era el fichero entregado.
    v3.3 main.hex disco 59.577 B c14b4350d960 -> git 58.250 B 7cfa86cf3edf
    candidata ..CORREGIDO disco 49.068 B 048856fc78e8 -> git 47.974 B b065e0803245
    production.hex disco 61.008 B a36646ea2a0b -> git 59.648 B d977bef13269
    En Windows el checkout deshace la conversion y no se nota. Quien clone en Linux o
    macOS, o con autocrlf=false, se lleva un binario cuyo sha256 no coincide con
    ningun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
2026-08-22 test(simulador): hacer medible el canal de temperatura y descubrir que no se mide
    Regla 0: ningun arreglo empieza sin el escenario que lo mide en rojo. El del ADC
    no se podia escribir, y ese era el problema de fondo.
    ADC_init() vivia en main.c, el UNICO .c del firmware que el arnes no compila (lo
    sustituye sim/plataforma.c). Consecuencia: el PCFG que decide que pines quedan
    analogicos era invisible para el simulador. Se extrae a Adc.c.
    El binario no cambia: recompilado con XC8 v2.36 da 048856fc78e8, byte a byte
    identico al de antes del refactor. Se gana la medida a coste cero.
    Lo primero que midio el bloque I nuevo NO es lo que este repositorio llevaba
    todo el dia afirmando. La baliza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
    [Adc.c, main.c, plataforma.c]
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2026-08-22 test(e2e): hablar directo con el firmware por tuberia, sin HTTP ni front
    Lo que se pedia: las tramas de la app contra el simulador del PIC, sin capas.
    Ahora el .py abre `arnes.exe --interactivo` -- el firmware REAL compilado para
    PC -- y le mete las tramas por stdin. Sin servidor, sin puerto, sin navegador.
    Quitar el HTTP arregla de paso un rojo que era del instrumento: el servidor
    encadenaba tramas sin dejar procesar la anterior y disparaba el solapamiento
    (arnes, bloque K), haciendo parecer roto el ajuste de reloj, que esta bien.
    RESULTADO con las tramas literales de MainActivity2.java:
    1. Reloj .......... PASA. "¿R1130,C210826-4?" -> 11:30 y 21/8/26.
    2. 1-Toque ........ PASA. Las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
2026-08-22 fix(firmware): despachar las tramas por el caracter pegado al delimitador
    Arregla el OTA, que estaba roto de dos maneras.
    Serial.c elegia que comando era con strstr() sobre el buffer ENTERO, buscando
    "L", "R", "N" y "A" por ese orden. Pero el nombre del comando "N" viaja DENTRO
    de la trama, asi que sus propias letras competian con los identificadores:
    ¿NCOLEGIO SAN JOSE? lleva L -> se despachaba como lectura, nombre perdido
    ¿NCARRERA 30 CON 45? lleva R sin L -> entraba por la rama del reloj y
    CORROMPIA LA HORA, de la que depende la franja escolar
    El ejemplo que se usaba en las demos, "Col. San Jose - Km 4+200", funcionaba
    por casualidad: no lleva ni L ni R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
2026-08-22 docs(normativa): fundamento juridico de los festivos y medir el receso escolar
    Ampliacion aportada por el responsable el 22-ago-2026. Lo importante no es que
    confirme la decision de no llevar calendario de festivos: es que explica POR QUE
    es correcta, que vale mucho mas que un "no aplica".
    La restriccion rige solo en dias habiles lectivos. Si un lunes es festivo y la
    placa dice "LUNES A VIERNES", la restriccion NO TIENE VALIDEZ JURIDICA ese dia.
    La exclusion es automatica por la propia leyenda de la placa.
    De ahi sale el argumento que faltaba: EL INSTRUMENTO LEGAL ES LA SENAL -- SR-30
    mas placa --, no la baliza. Una baliza titilando un festivo no puede hacer
    exigible algo que la plac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
2026-08-22 test(simulador): dejar de exigir la temperatura y guardar el invariante del ADC
    Correccion de criterio del responsable, y tiene razon: la temperatura NO es un
    defecto, es una funcion que nadie ha pedido.
    Comprobado antes de reclasificarla: la app NO muestra temperatura en ninguna
    pantalla -- ni en el layout, ni en strings, ni en el Java. Y el estado
    ST_READ_TEMP_AP es codigo muerto al que nadie transiciona. O sea que ningun
    usuario ve un numero equivocado: simplemente la funcion no existe.
    El bloque I del arnes estaba EXIGIENDO esa funcionalidad (que AN3 estuviera
    habilitado, que la temperatura se leyera) y producia dos rojos que nadie iba a
    arreglar nunca. Un banco que pide funcionalidad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
2026-08-22 docs: el equipo no sabe decir que firmware lleva, y poner las cifras al dia
    Salio al comprobar si el .hex "era de la 3.4". El APK si lo es -- versionName
    3.4 verificado dentro del manifiesto, sin rastro de 3.3. El .hex NO, y no puede
    serlo: el firmware no tiene identidad de version.
    Anuncia "BALIZA ALARMA V1.0" al arrancar (Aplicacion.c:156) y esa cadena es
    IDENTICA en el binario de la v3.3 (c14b4350) y en el candidato (889c0188), que
    se comportan distinto -- el candidato lleva el arreglo del despachador de tramas.
    El volcado de ¿L? tampoco la incluye.
    Consecuencia: delante de una senal montada nadie puede saber que firmware corre.
    Ni el tecnico con la app, ni soporte por telefono, ni una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
2026-08-22 feat(firmware): que el equipo diga que firmware lleva, y manual al dia
    Regla 0: primero el escenario que lo mide en rojo. Bloque N nuevo en el arnes,
    rojo antes del cambio y verde despues.
    EL PROBLEMA. El firmware anunciaba "BALIZA ALARMA V1.0" al arrancar y esa cadena
    era IDENTICA en el binario de la v3.3 y en el candidato, que se comportan
    distinto -- el candidato lleva el arreglo del despachador de tramas. El volcado
    de ¿L? tampoco llevaba version. Delante de una senal montada nadie podia saber
    que firmware corre: ni el tecnico, ni soporte, ni una auditoria.
    EL ARREGLO. FW_VERSION en Aplicacion.h, y readDevide() abre el volcado con
    "FW 3.4". Coste: 22 bytes de Flash (53,2% -> 53,3%).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
    [Aplicacion.c, Aplicacion.h]
2026-08-22 docs(propuesta): validar las funciones de la app y proponer la inspeccion por modalidad
    Validacion primero, leyendo el codigo de la app -- no el emulador ni la
    documentacion. Lo que funciona de verdad: telemetria de bateria (AN1, factor 6
    correcto), contador de cortes, diagnostico de pila RTC, nombre OTA, horario de
    la placa, receso, prueba de foco y exportacion del acta.
    Y una correccion a lo que yo mismo dije antes: el certificado SI esta en la app.
    Usa el menu de compartir de Android (ACTION_SEND), no WhatsApp directo, que
    ademas es lo correcto. Mi grep buscaba "whatsapp" y por eso no lo vio.
    TRES COSAS QUE NO ESTAN, medidas:
    1. El checklist es DECORATIVO. Las cuatro casillas existen e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
2026-08-22 docs(propuesta): estado fisico de la senal repartido por modalidad, y quien firma
    Dos aportaciones del responsable, las dos correctas y las dos con consecuencias.
    1. EL ESTADO FISICO DE LA SENAL. Faltaba, y es lo primero que mira una
    interventoria. Pero no cabe en una sola casilla: la propuesta en circulacion
    lo agrupa como "lamina reflectiva + herrajes + lente + gabinete", y eso obliga
    otra vez a marcar desde el suelo cosas que estan arriba.
    Repartido por modalidad. Desde el suelo -- que es donde se comprueba casi
    todo el, porque una senal existe para leerse desde la via:
    lamina reflectiva sin grafiti ni golpes, placa del horario legible,
    senal SIN OBSTRUCCION (ra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
2026-08-22 fix(app): enlazar los controles muertos y detectarlos automaticamente
    Reportado en campo: "compartir certificado no hace nada". Cierto, y al buscarlo
    aparecieron mas del mismo patron.
    CUATRO CONTROLES ESTABAN MUERTOS. Existian en la pantalla, a veces incluso
    declarados como campo en el Java, y nadie les hacia findViewById:
    - Las 4 casillas del checklist -> ya corregidas antes
    - COMPARTIR CERTIFICADO -> exportAuditReport() escrito y NUNCA invocado
    - Nombre OTA + GUARDAR -> edtNombreBaliza nunca asignado, asi que
    guardarNombreBaliza() salia siempre por su
    propio "if (== null) return". El acta sa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
    [MainActivity2.java]
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2026-08-22 fix(ui): solucionar desbordamiento de texto en horas (06:00), botones de receso, test de foco y botones superiores
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2026-08-22 fix(manual): recuperar las imagenes del Word y quitar los cuadros vacios de las figuras
    Dos arreglos sobre los cambios de esta tarde.
    1. EL WORD DEL MANUAL SE QUEDO SIN IMAGENES. El .docx commiteado en a85fc32
    tenia 0 imagenes y 20 KB, cuando el .md referencia 22 figuras: pandoc no
    resolvia las rutas relativas de img/ porque se le invocaba desde otro
    directorio de trabajo.
    El arreglo estaba a medias sin commitear en generar_word.py -- anadir
    --resource-path y ejecutar pandoc con cwd en Manuales/. Probado: vuelve a
    salir con 22 imagenes y 566 KB.
    Es la segunda vez hoy que regenerar el Word destruye las figuras. La primera
    fue porque el .md no las referenciaba; esta,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
2026-08-22 docs: renumerar el manual y registrar las dos lecciones de hoy
    MANUAL. Los apartados iban 4, 4bis, 4ter, 5... porque se fueron anadiendo sin
    tocar los siguientes, y el indice apuntaba a anclas que ya no existian -- citaba
    un "Exportacion del Certificado" borrado y un "Checklist de Mantenimiento
    Preventivo" sustituido. Renumerado a 12 apartados correlativos e indice
    reconstruido desde los titulos reales, no a mano. Word regenerado: 22 figuras.
    CLAUDE.md. Apartado nuevo sobre el fallo que mas veces se ha colado aqui: un
    control que se ve pero no hace nada. Cuatro casos en un dia -- las casillas del
    checklist, COMPARTIR CERTIFICADO, el nombre OTA y el usuario del login -- y
    ninguno daba error: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
2026-08-22 docs(estado): reescribir ESTADO.md con las cifras del 22-ago-2026
    Su propia cabecera dice que se reescribe cada sesion y que las cifras viven ahi,
    y seguia fechado el 21 de agosto describiendo un estado que ya no existe -- daba
    por instalado un .hex distinto y no mencionaba ninguno de los arreglos de hoy.
    Lo que recoge ahora, y en este orden porque es el que importa:
    - LAS DOS PAREJAS de binarios y que NO SE MEZCLAN. La v3.3 que funciono en
    campo y la candidata de hoy, con tamano y hash de cada fichero.
    - Las cifras medidas: arnes 78/78, contrato app-firmware PASS, interfaz PASS
    con 51 controles enlazados, Flash 53,3%, XC8 v2.36.
    - Los seis arreglos del dia.
    - Lo que falta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
